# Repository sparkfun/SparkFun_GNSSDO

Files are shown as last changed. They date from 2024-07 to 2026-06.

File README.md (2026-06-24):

SparkPNT SXT / SXT-D
========================================

SparkPNT SXT (https://www.sparkpnt.com/products/sxt-gnssdo)

[*SparkPNT SXT (GNSSDO)*](https://www.sparkpnt.com/products/sxt-gnssdo)

Designed and manufactured in Boulder, Colorado, USA, the SparkPNT SXT GNSS Disciplined Oscillator (GNSSDO) and SXT-D GNSS Disciplined Oscillator Plus (GNSSDO+) are the perfect solution for your high-precision timing needs. Based around the multi-constellation, multi-frequency, L5-ready mosaic-T from Septentrio, these are our most accurate GNSS timing products to date. They feature a disciplined 10MHz oscillator: Digitally-Controlled Temperature-Controlled Crystal Oscillator (DCTCXO) on the SXT; Digitally-Controlled Double-Oven Crystal Oscillator (OCXO) on the SXT-D. The mosaic-T also has built-in on-module support for the Fugro AtomiChron L-band timing service.

Under the hood, the SXT and SXT-D are based on the mosaic-T GNSS module from Septentrio, plus the Espressif ESP32-WROVER processor (16MB flash, 8MB PSRAM). The mosaic-T has USB-C connectivity (with Ethernet-over-USB), multiple UARTs and supports full Ethernet connectivity. You can connect the mosaic-T directly to your Ethernet network - our product supports Power-over-Ethernet too. The ESP32 rides shotgun: disciplining the digitally-controlled oscillator and controlling the OLED display. Remote configuration is possible, the ESP32 console can be accessed via TCP. The SXT and SXT-D have multiple power options including USB-C, PoE and 9V-36V DC, making it easy to connect them to a battery-backed supply.

RTK Not Supported
--------------
The mosaic-T is a superb GNSS module designed for highly accurate timing applications. **But it does not support RTK. It can not be used as a RTK Rover or Base. RTCM output is not supported.**

Documentation
--------------

- **[Product Manual](http://docs.sparkfun.com/SparkFun_GNSSDO/)** - Product manual for the SXT(-D) GNSSDO(+) hosted by GitHub pages.<br>
   

*Need to download or print our hookup guide?*

- [Print *(Print to PDF)* from Single-Page View](http://docs.sparkfun.com/SparkFun_GNSSDO/print_view)

Firmware Update
-------------------

The **[/Firmware/Binaries](https://github.com/sparkfun/SparkFun_GNSSDO/tree/main/Firmware/Binaries)** folder contains the firmware binaries.

You can update or reload the firmware using the [SparkFun RTK Firmware Uploader](https://github.com/sparkfun/SparkFun_RTK_Firmware_Uploader).

Repository Contents
-------------------

- **[/docs](/docs/)** - Online documentation files
    - [assets](/docs/assets/) - Assets files
        - [board_files](/docs/assets/board_files/) - Files for the product design
            - [SXT Schematic](/docs/assets/board_files/schematic.pdf) (.pdf)
            - [SXT-D Schematic](/docs/assets/board_files/SparkPNT_GNSSDO_Plus_schematic) (.pdf)
            - [Dimensions](/docs/assets/board_files/dimensions.png) (.png)
            - [SXT KiCad files](/docs/assets/board_files/kicad_files.zip) (.zip)
            - [SXT-D KiCad files](/docs/assets/board_files/kicad_files_GNSSDO_Plus.zip) (.zip)
        - [img/hookup_guide/](/docs/assets/img/hookup_guide/) - Images for hookup guide documentation
- **[/Hardware](/Hardware/)** - KiCad design files
- **[/Hardware/Production](/Hardware/Production/)** - PCB panel production files
- **[/Front_Sticker](/Front_Sticker/)** - DXF and PDF files for the front sticker
- **[/Rear_Sticker](/Rear_Sticker/)** - DXF and PDF files for the rear sticker
- **[/Firmware](/Firmware/)** - Arduino source code and binaries for the firmware which runs on the ESP32-WROVER
- **[/Test_Sketches](/Test_Sketches/)** - Additional code used to validate and test the SXT
- **[/Documents](/Documents/)** - Component datasheets etc.

Product Variants
----------------

- [SXT](https://www.sparkpnt.com/products/sxt-gnssdo)- SXT (GNSSDO) v1.0, Initial Release
- [SXT-D](https://www.sparkpnt.com/products/sxt-d-gnssdo)- SXT-D (GNSSDO+) v1.0, Initial Release

Version History
---------------

- [v10](https://github.com/sparkfun/SparkFun_GNSSDO/releases/tag/v10) - Initial Release

License Information
-------------------

This product is ***open source***!

Please review the [LICENSE.md](./LICENSE.md) file for license information.

If you have any questions or concerns about licensing, please contact technical support on our [SparkPNT forums](https://community.sparkpnt.com).

Distributed as-is; no warranty is given.

- Your friends at SparkPNT.

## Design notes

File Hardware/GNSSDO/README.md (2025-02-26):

SparkPNT GNSSDO Design Files
=====================================

The files here are the KiCad schematic and PCB design files from SparkFun Electronics.

KiCad can be downloaded [here](https://www.kicad.org/).

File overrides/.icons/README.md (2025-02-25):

.icons directory
====================
This folder should contain branding logos for the product documentation

## General Images
- `sfe.svg` - SparkFun flame logo
- `kicad-primary.svg` - Full KiCad logo

## Directory
- `logo` - Other available logos

## SVG Optimizer
- [Remove meta data from svg](https://jakearchibald.github.io/svgomg/)

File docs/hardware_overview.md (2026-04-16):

---
icon: material/cog
---

!!! warning "Read Before Handling PCB!"
	!!! danger "ESD Sensitivity"
		The mosaic-T module is sensitive to [ESD](https://en.wikipedia.org/wiki/Electrostatic_discharge "Electrostatic Discharge"). Use a proper grounding system to make sure that the working surface and the components are at the same electric potential.

	??? info "ESD Precaution"
		As recommended by the manufacturer, we highly encourage users to take the necessary precautions to avoid damaging their module.

		- The GNSSDO(+) features ESD protection on the USB-C connectors, ethernet jack, I/O terminals and antenna connections.

		<div class="grid cards" markdown>

		<div markdown>

		<article class="video-500px" style="text-align: center; margin: auto;" markdown>
		<iframe src="https://www.youtube.com/embed/hrL5J6Q5gX8?si=jOPBat8rzMnL7Uz4&amp;start=26;&amp;end=35;" title="Septentrio: Getting Started Video (playback starts at ESD warning)" frameborder="0" allow="accelerometer; autoplay; clipboard-write; encrypted-media; gyroscope; picture-in-picture" allowfullscreen></iframe>
		</article>

		</div>

		-   <a href="https://www.sparkfun.com/products/25572">
			<figure markdown>
			Product Thumbnail
			</figure>

			---

			**iFixit Anti-Static Wrist Strap**<br>
			TOL-25572</a>

		</div>

!!! code "ESP32 Firmware"
	We have intentionally kept the ESP32 firmware as simple as possible - it only disciplines the TCXO oscillator and controls the OLED display. The SparkFun RTK Firmware or SparkFun RTK Everywhere firmware will not run on this product. The intention is that you can easily develop your own firmware for the GNSSDO(+) if the SparkFun firmware does not meet your needs.

	The **[/Firmware/Binaries](https://github.com/sparkfun/SparkFun_GNSSDO/tree/main/Firmware/Binaries)** folder contains the firmware binaries.

	You can update or reload the firmware using the [SparkFun RTK Firmware Uploader](https://github.com/sparkfun/SparkFun_RTK_Firmware_Uploader).

	You can of course modify the hardware too, should you want to. The design is completely open-source.

# Hardware Overview
In this section, we walk you through the hardware design, interfaces, I/O connections, power options and more.

## Schematic
Users can download the full schematic for the [GNSSDO](./assets/board_files/schematic.pdf) and [GNSSDO+](./assets/board_files/SparkPNT_GNSSDO_Plus_schematic.pdf) in `*.pdf` format.

## Dimensions

=== ":material-package-variant-closed: Metal Enclosure"
	Details about the aluminum enclosure can be found on the [Metal Enclosure - Custom Aluminum Extrusion (6in. x 4in. PCB)](https://www.sparkfun.com/metal-enclosure-custom-aluminum-extrusion-6in-x-4in-pcb.html) product page.

	<figure markdown>
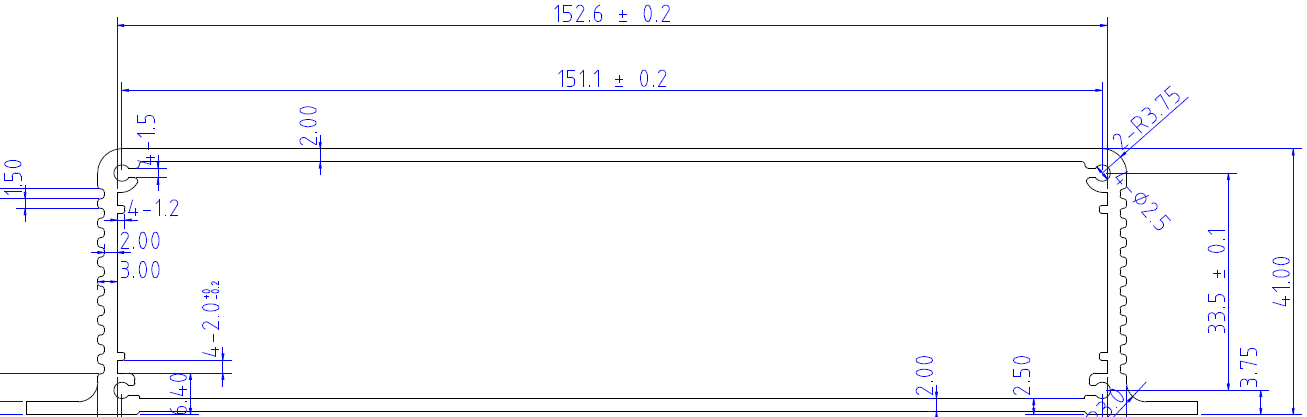
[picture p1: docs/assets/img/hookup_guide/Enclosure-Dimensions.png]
Enclosure Dimensions
	
	<figcaption markdown>
	[Dimensions (PDF)](./assets/board_files/dimensions-enclosure.pdf) of the GNSSDO(+) aluminum enclosure and the front/rear panels, in millimeters.
	</figcaption>
	</figure>

=== ":fontawesome-solid-microchip: Printed Circuit Board"
	The circuit board dimensions are illustrated in the drawing below; the listed measurements are in inches.

	<figure markdown>
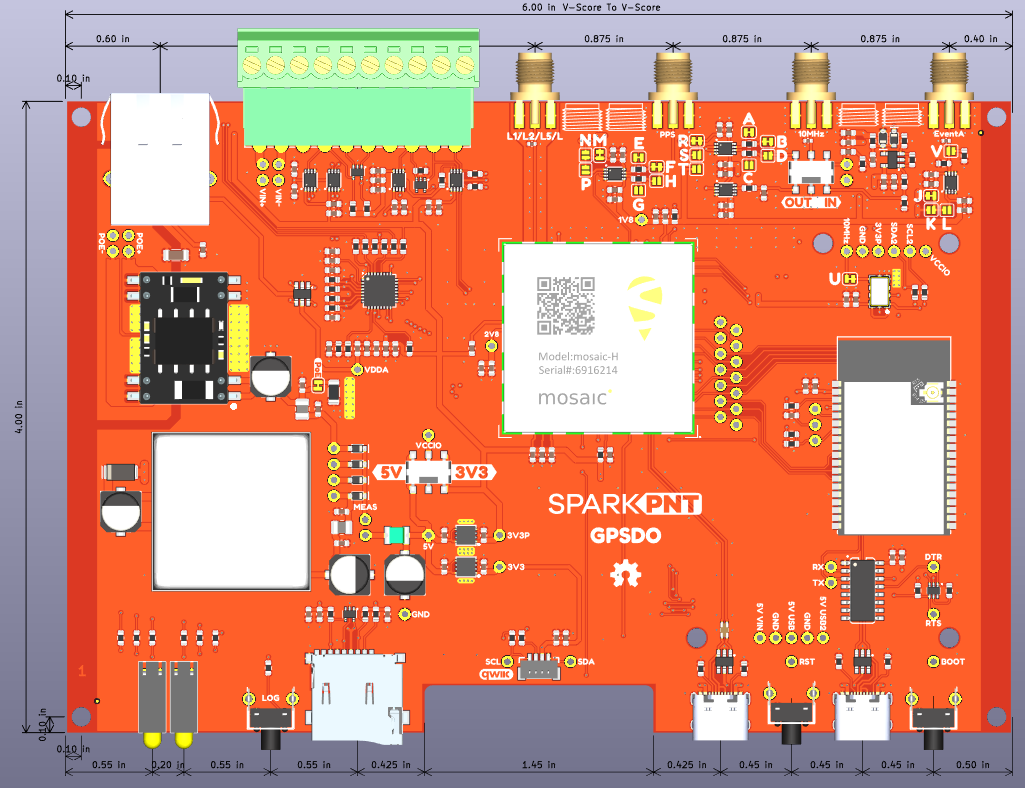
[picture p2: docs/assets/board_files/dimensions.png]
Board Dimensions
	
	<figcaption markdown>
	[Dimensions (PNG)](./assets/board_files/dimensions.png) of the GNSSDO(+) PCB, in inches.
	</figcaption>
	</figure>

	??? tip "Need Dimensions?"
		For the board dimensions, users can download the [KiCad files](./assets/board_files/kicad_files.zip) for this board. These files can be opened in KiCad and measurements can be made with the measuring tool.

		!!! info ":octicons-download-16:{ .heart } KiCad - Free Download!"
			KiCad is free, open-source [CAD]("computer-aided design") program for electronics. Click on the button below to download their software. *(\*Users can find out more information about KiCad from their [website](https://www.kicad.org/).)*

			<article style="text-align: center;" markdown>
			[Download :kicad-primary:{ .enlarge-logo }](https://www.kicad.org/download/ "Go to downloads page"){ .md-button .md-button--primary width="250px" }
			</article>

		??? info ":straight_ruler: Measuring Tool"
			This video demonstrates how to utilize the dimensions tool in KiCad, to include additional measurements:

			<article class="video-500px" style="text-align: center; margin: auto;" markdown>
			<iframe src="https://www.youtube.com/embed/-eXuD8pkCYw" title="KiCad Dimension Tool" frameborder="0" allow="accelerometer; autoplay; clipboard-write; encrypted-media; gyroscope; picture-in-picture" allowfullscreen></iframe>

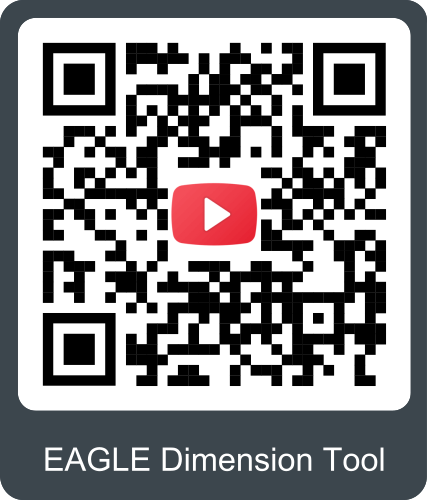
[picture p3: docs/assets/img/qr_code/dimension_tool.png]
QR code to play video
			
			</article>

=== ":material-video-input-antenna: Antenna"
	The dimensions and technical specifications of the GNSS antenna can be found on the [GNSS Multi-Band L1/L2/L5 Surveying Antenna - TNC (SPK6618H)](https://www.sparkfun.com/gnss-multi-band-l1-l2-l5-surveying-antenna-tnc-spk6618h.html) product page.

	<figure markdown>
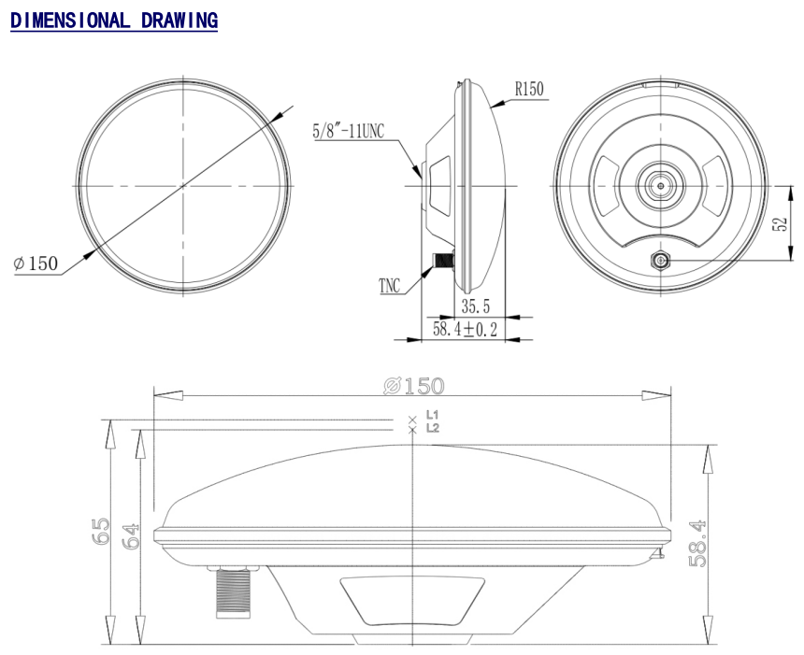
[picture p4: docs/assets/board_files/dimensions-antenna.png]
Antenna Dimensions
	
	<figcaption markdown>
	Dimensions of the included GNSS antenna, in mm.<br>
	Source: [SPK6618H Datasheet (PDF)](https://cdn.sparkfun.com/assets/f/f/5/1/7/SparkFun_SPK6618H_Datasheet.pdf)
	</figcaption>
	</figure>

## Power Options
The mosaic-T and the ESP32 both required 3.3V power. To simplify the power circuitry, the four power sources are combined into a common 5V rail which then feeds individual 3.3V regulators for the mosaic-T and the ESP32.

<figure markdown>
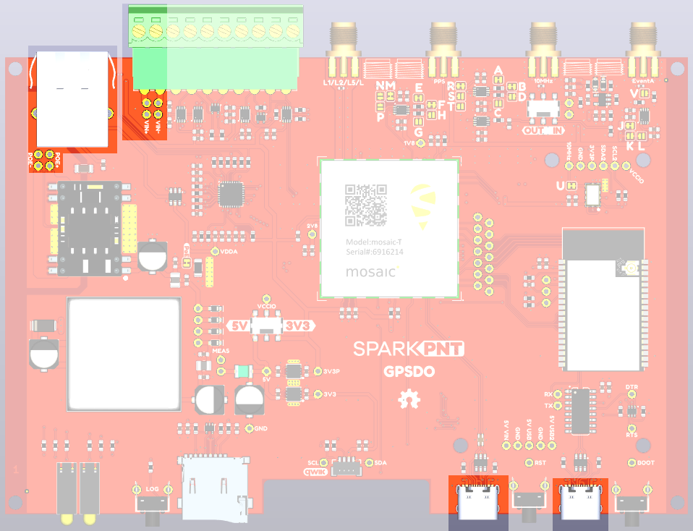
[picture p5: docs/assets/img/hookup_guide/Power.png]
Power connections

<figcaption markdown>Power connections on the GNSSDO(+) PCB.</figcaption>
</figure>

The GNSSDO can be powered individually or in combination, with any of the following:

- **`USB Ports`** - **5V**; delivered via the `MOSAIC CONFIG` and/or `ESP32 CONFIG` USB-C connectors.
- **`Power-over-Ethernet`** - **Range: 36 to 57V**; delivered via the `MOSAIC ETHERNET` RJ45 MagJack connector.
- **`External DC Power`** - **Range: 9 to 36V**; delivered via the `VIN+` and `VIN-` screw cage terminals.

Powering the GNSSDO+ takes a little more thought and care. The double-oven oscillator in the GNSSDO+ draws more current than a standard USB (2.0) port can provide. You need to ensure that you use the provided 65W Power Delvery Wall Adapter if you are going to power the GNSSDO+ from USB. Also, the GNSSDO+ includes a Power Path priority circuit. From highest to lowest, the Power Path priorities are:

- **`Power-over-Ethernet`** - **Range: 36 to 57V**; delivered via the `MOSAIC ETHERNET` RJ45 MagJack connector.
- **`External DC Power`** - **Range: 9 to 36V**; delivered via the `VIN+` and `VIN-` screw cage terminals.
- **`CONFIG ESP32 USB Port`** - **5V from a Power Delivery Wall Adapter**; delivered via the `CONFIG ESP32` USB-C connector.
- **`CONFIG MOSAIC USB Port`** - **5V from a Power Delivery Wall Adapter**; delivered via the `CONFIG MOSAIC` USB-C connector.

If you have the **`CONFIG ESP32 USB Port`** connected to a standard USB (2.0) port, it will not be able to provide enough current. And due to the Power Path priority, it will not preferentially draw power from **`CONFIG MOSAIC USB Port`**. Your options are:

- Provide power via **`Power-over-Ethernet`** or **`External DC Power`** since these have higher priority
- Install a [power switch](https://www.sparkfun.com/usb-c-extension-cable-with-power-switch-1m.html) in the **`CONFIG ESP32 USB Port`** cable to disconnect its power, forcing the GNSSDO+ to draw Power Delivery power from the **`CONFIG MOSAIC USB Port`**.

If you have **`CONFIG MOSAIC USB Port`** connected to a standard USB (2.0) port, ensure the Power Delivery Wall Adapter is connected to **`CONFIG ESP32 USB Port`**. The Power Path priority will ensure power is drawn from the **`CONFIG ESP32 USB Port`**.

Consult page 9 of the [GNSSDO+ schematic](./assets/board_files/SparkPNT_GNSSDO_Plus_schematic.pdf) for more details

??? tip "Measure Current Draw"
	If you want to measure the board's current draw, you can open the `MEAS` jumper and measure the current via a pair of breakout pads *(see the **[Jumpers](#jumpers-gnssdo)** section)*.

??? info "Protection Components"
	Diodes are used to combine and protect the power sources from each other. Also, a 2A resettable fuse (green) provides additional protection.

!!! info
	For more details, users can reference the [GNSSDO schematic](./assets/board_files/schematic.pdf), [GNSSDO+ schematic](./assets/board_files/SparkPNT_GNSSDO_Plus_schematic.pdf) and the datasheets of the individual components on the board.

=== ":material-usb-port: USB-C Connectors"
	The mosaic-T and ESP32 both have USB-C connections. These USB ports can be used to power the GNSSDO during the initial configuration when the mosaic-T or ESP32 are connected to a computer. For GNSSDO+, ensure you are using the provided Power Path Wall Adapter as described above.

	<div class="grid" markdown>

	<div markdown>

	<figure markdown>
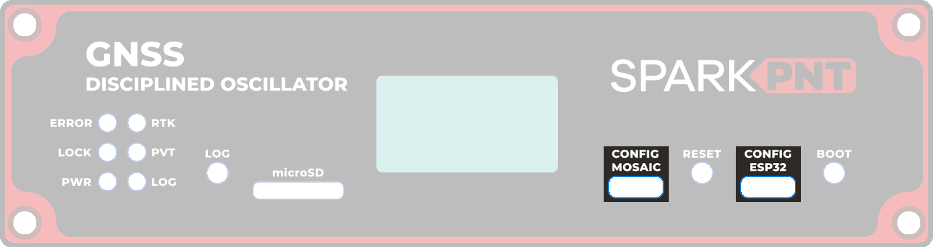
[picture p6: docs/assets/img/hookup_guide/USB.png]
USB-C Connectors
	
	<figcaption markdown>USB-C connectors on the GNSSDO(+).</figcaption>
	</figure>

	</div>

	<div markdown>

	<figure markdown>
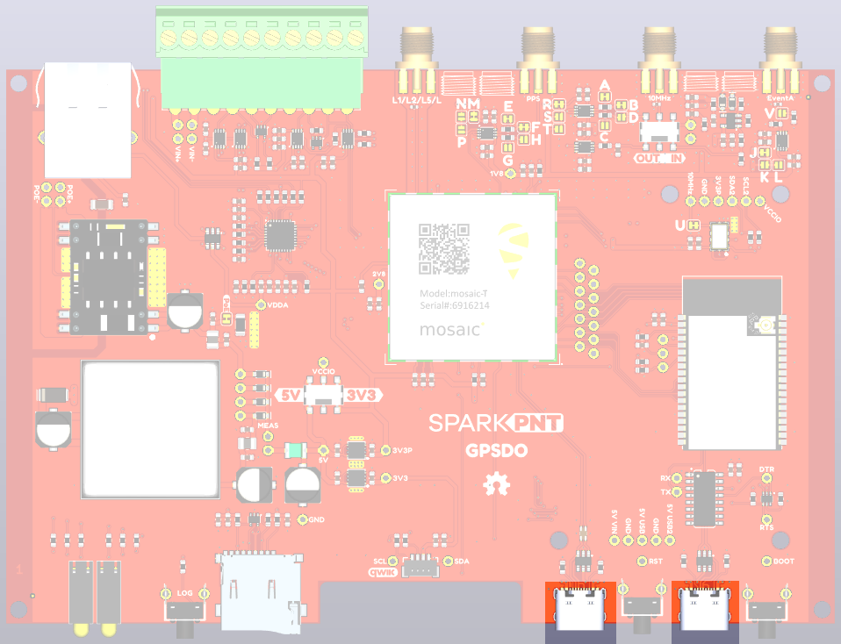
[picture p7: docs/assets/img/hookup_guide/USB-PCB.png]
USB-C Power Connections
	
	<figcaption markdown>The USB-C device connections on the GNSSDO(+) PCB.</figcaption>
	</figure>

	</div>

	</div>

	!!! info "CH340 Driver"
		The CH340 allows the ESP32-WROVER to communicate with a computer/host device through the USB-C connection. This allows the ESP32 to show up as a device on the serial (or COM) port of the computer. Users will need to install the latest drivers for the computer to recognize the CH340 *(see **[USB Driver](./software_overview.md#ch340-usb-driver)** section)*.

=== ":material-ethernet: Power-over-Ethernet (PoE)"
	The mosaic-T Ethernet port supports Power-over-Ethernet ([PoE](https://en.wikipedia.org/wiki/Power_over_Ethernet "Power Over Ethernet")), allowing the GNSSDO(+) to be powered by the network. This is very useful when the GNSSDO(+) is mounted remotely - perhaps in a weatherproof box up on the roof. Data and power can be delivered through a single cable, avoiding the need for a separate power connection.

	<div class="grid" markdown>

	<div markdown>

	<figure markdown>
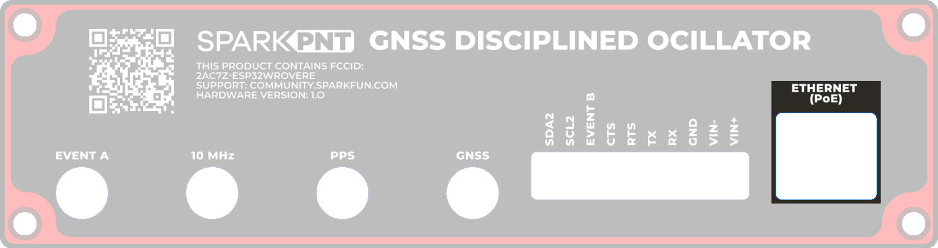
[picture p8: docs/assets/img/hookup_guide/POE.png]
Power over Ethernet Jack
	
	<figcaption markdown>The Power-over-Ethernet (PoE) jack on the GNSSDO(+).</figcaption>
	</figure>

	</div>

	<div markdown>

	<figure markdown>
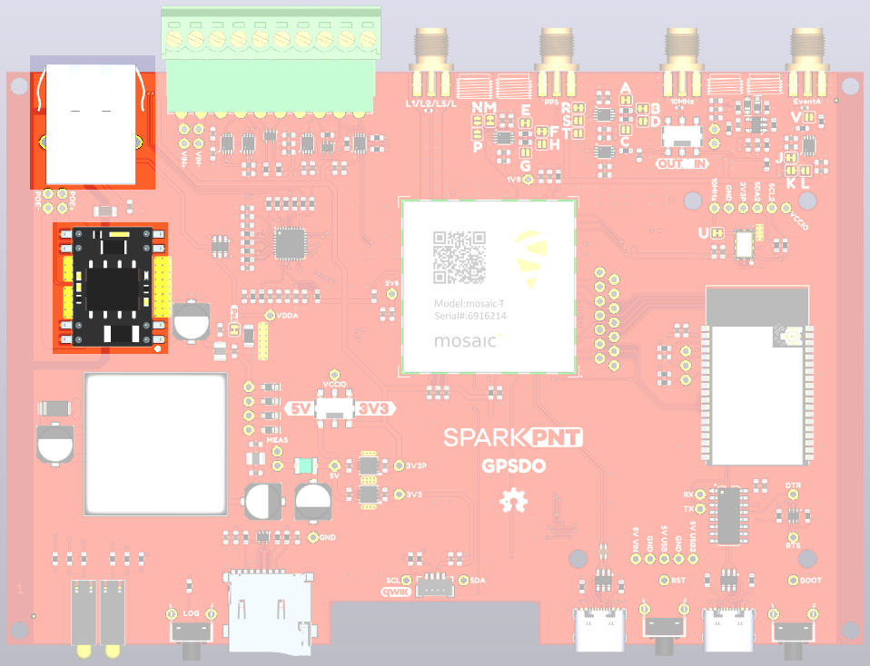
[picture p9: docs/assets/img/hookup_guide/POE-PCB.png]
Power over Ethernet Circuit
	
	<figcaption markdown>The PoE power input circuit on the GNSSDO PCB.</figcaption>
	</figure>

	</div>

	</div>

=== ":material-car-battery: External DC Power (VIN)"
	The GNSSDO(+) includes a fully-isolated DC-DC converter, for applications where you may want to power the unit from a vehicle. The DC-DC converter accepts DC voltages between **9V and 36V**, regulating this down to 5V. The converter is fully isolated to 1.5kV and operates with ~90% efficiency.

	<div class="grid" markdown>

	<div markdown>

	<figure markdown>
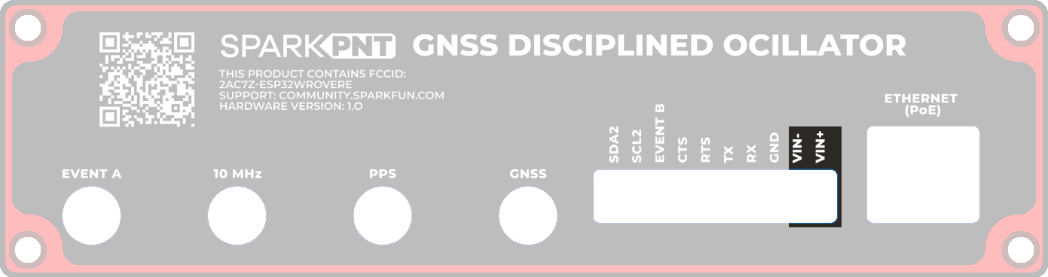
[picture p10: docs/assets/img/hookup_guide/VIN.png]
External Power Screw Terminal
	
	<figcaption markdown>The `VIN+` and `VIN-` screw terminal pins for the external DC power input.</figcaption>
	</figure>

	</div>

	<div markdown>

	<figure markdown>
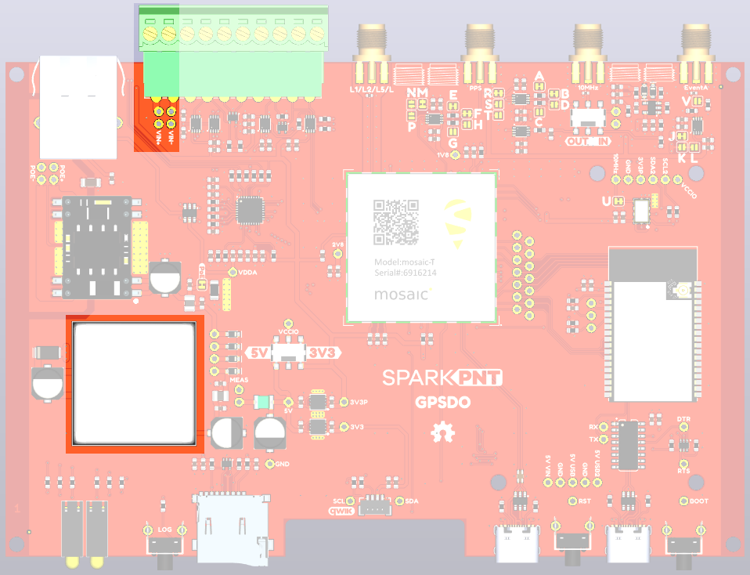
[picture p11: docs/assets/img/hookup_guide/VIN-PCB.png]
External DC Power Input
	
	<figcaption markdown>The DC-DC power converter and external power inputs on the GNSSDO(+) PCB.</figcaption>
	</figure>

	</div>

	</div>

	??? tip "Vehicle Power"
		For **12V** or **24V** vehicle power:

		- Connect 12V or 24V to the `VIN+` screw cage terminal
		- Connect 0V (chassis) to the `VIN-` screw cage terminal

		!!! warning "Power Source"
			Additionally, make sure that the power source from the vehicle is not directly tied to the vehicle's battery, `Always On`, or accessory circuits. Otherwise, users will risk draining the battery while the engine is off.

			We recommend locating the *ignition on* or *switched power* circuit, which is only powered when the key is in the `On` position *and the engine is running*.

			!!! note
				The `On` position, is where a key normally rests after the engine is started. However, users can still move the key from the `Off` position and into the `On` position without starting the engine. In this case, the alternator is not running and keeping the battery charged.

				Modern *eco-efficient* vehicles may automatically shut down the engine if the vehicle is idling too long. Therefore, cutting off the vehicle's alternator that keeps the battery charged. Luckily, most vehicles with this *automatic start/stop* technology will monitor the battery's voltage and restart the engine when required. With this in mind, users may want to initially monitor their battery voltage, in case their vehicle isn't *"so smart"* :sweat_smile:.

	??? warning "Ground Loop"
		If desired, users can link `VIN-` to the adjacent `GND` screw cage terminal. However, this will bypass the voltage isolation and could introduce an unwanted ground loop, particularly if the GNSS antenna ground (shield, 0V) is also connected to the chassis.

## :septentrio: mosaic-T
The heart of our product is of course the mosaic-T GNSS module from Septentrio. It is a _very_ sophisticated chip with multiple interfaces: UARTS, USB and Ethernet. On GNSSDO, the `GPIO1` and `GPIO2` pins are available as 0.1" test points should you need access to them. On GNSSDO+, GP1 and GP2 are available on the 10-way screw cage connector.

<figure markdown>
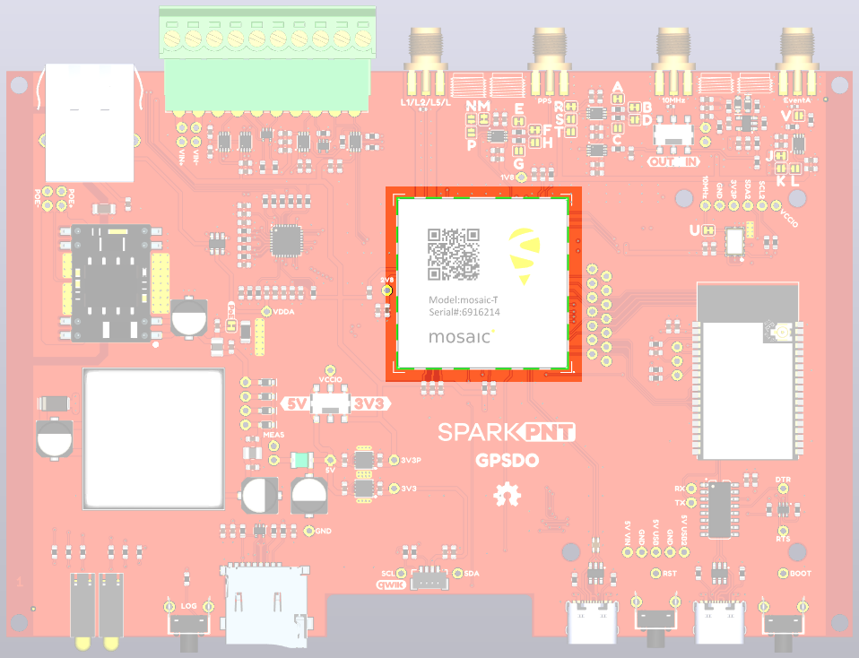
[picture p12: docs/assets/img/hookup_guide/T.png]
mosaic-T

<figcaption markdown>The Septentrio mosaic-T GNSS module.</figcaption>
</figure>

## :espressif: ESP32-WROVER
The ESP32 processor is there to control (discipline) the 10 MHz TCXO oscillator and the OLED display. We have deliberately kept the ESP32 firmware as simple as possible. The intention is that you can write your own firmware using the Espressif IDF or Arduino IDE if you need to.

<figure markdown>
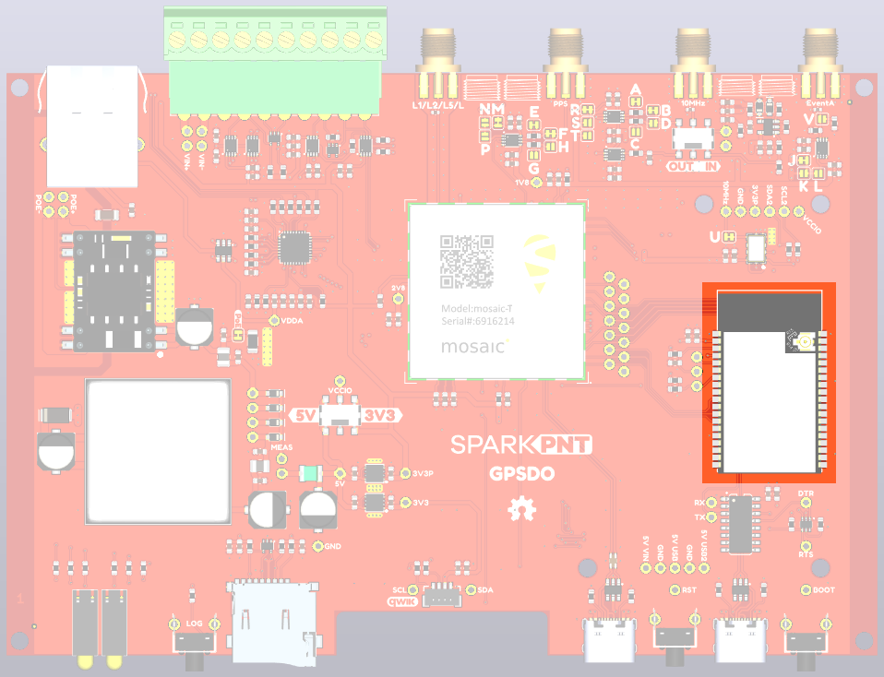
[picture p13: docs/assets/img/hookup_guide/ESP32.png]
Espressif ESP32 on GNSSDO

<figcaption markdown>The Espressif ESP32-WROVER processor on GNSSDO.</figcaption>
</figure>

<figure markdown>
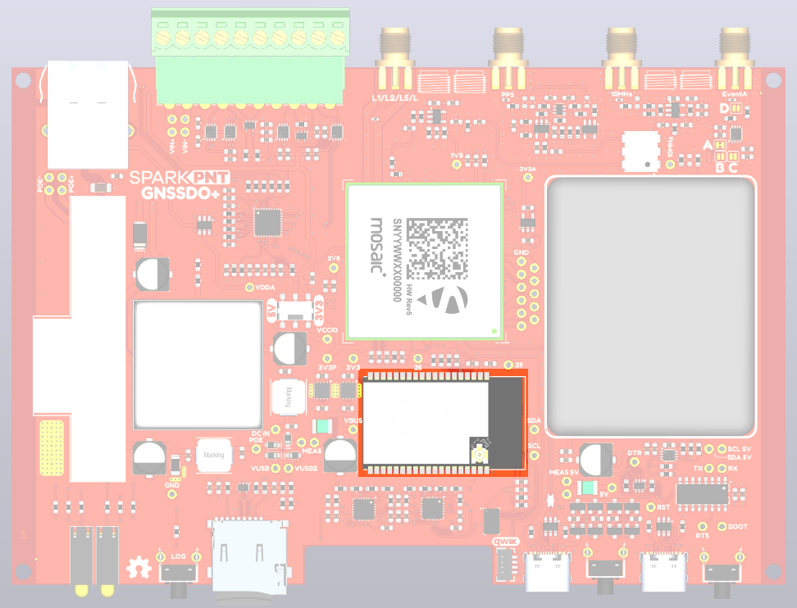
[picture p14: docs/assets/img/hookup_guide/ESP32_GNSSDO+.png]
Espressif ESP32 on GNSSDO+

<figcaption markdown>The Espressif ESP32-WROVER processor on GNSSDO+.</figcaption>
</figure>

Think of the ESP32 as a co-processor, or riding shotgun... The mosaic-T `COM1`, `COM3` and `COM4` UARTs are linked to the ESP32, allowing the two to communicate directly without needing an Ethernet link. In our firmware, the PVTGeodetic and ReceiverTime messages are output on COM1. The ESP32 displays some of their content on the I^2^C OLED display, and then uses the content to discipline the TCXO oscillator. See [Oscillator](./oscillator.md) for more details.

??? code "ESP32 Firmware"
	We have intentionally kept the ESP32 firmware as simple as possible. The intention is that users can easily develop their, own firmware for the GNSSDO(+) using the Espressif ESP IDF or the Arduino IDE if the SparkFun firmware does not meet their needs.

	The **[/Firmware/Binaries](https://github.com/sparkfun/SparkFun_GNSSDO/tree/main/Firmware/Binaries)** folder contains the firmware binaries.

	You can update or reload the firmware using the [SparkFun RTK Firmware Uploader](https://github.com/sparkfun/SparkFun_RTK_Firmware_Uploader).

	The ESP32-WROVER-IE antenna is not connected. If you write your own firmware and want to use BT/WiFi connectivity, you will need to attach your own antenna to the u.FL connector on the ESP32 module.

## Ethernet PHY Interface
The mosaic-T has a KSZ8041NLI Ethernet PHY interface, connected using a Reduced Media-Independent Interface (RMII).

<div class="grid" markdown>

<div markdown>

<figure markdown>
Ethernet Connector
<figcaption markdown>Ethernet (PoE) conection.</figcaption>
</figure>

</div>

<div markdown>

<figure markdown>
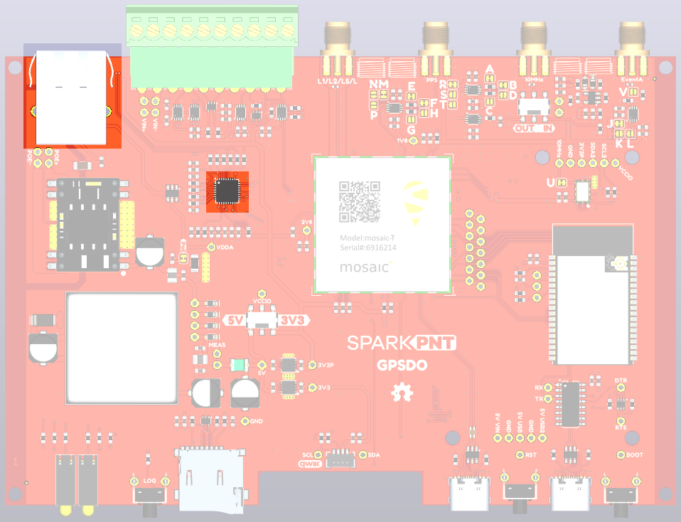
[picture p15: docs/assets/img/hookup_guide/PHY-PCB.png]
Ethernet PHY

<figcaption markdown>The Ethernet PHY on the GNSSDO(+) PCB.</figcaption>
</figure>

</div>

</div>

??? info "No IP address?"
	Check the Ethernet interface is enabled. It may be disabled. Connect via the CONFIG MOSAIC USB-C port and open 192.168.3.1 on a web browser. Check the **Communication \ Ethernet** sub-page.

	<figure markdown>
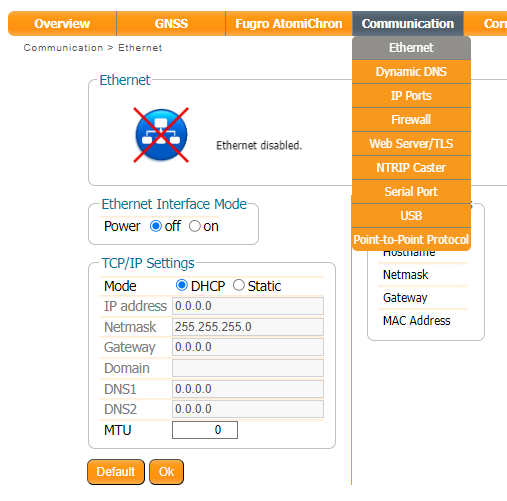
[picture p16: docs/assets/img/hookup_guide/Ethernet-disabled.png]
	
	<figcaption markdown>
	[mosaic-T web page (PNG)](./assets/img/hookup_guide/Ethernet-disabled.png) with Ethernet disabled.
	</figcaption>
	</figure>

	<figure markdown>
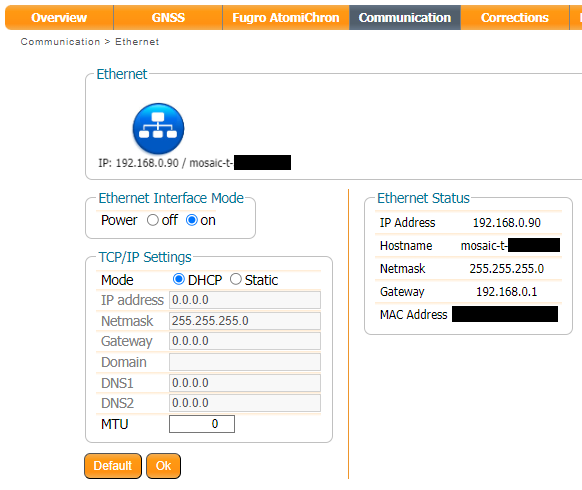
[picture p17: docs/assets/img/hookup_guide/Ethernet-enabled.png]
	
	<figcaption markdown>
	[mosaic-T web page (PNG)](./assets/img/hookup_guide/Ethernet-enabled.png) with Ethernet enabled.
	</figcaption>
	</figure>

	By default, the mosaic-T Ethernet port is configured for Dynamic Host Configuration Protocol (DHCP). It expects the router / Ethernet switch to provide it with an IP address. If the IP address is all zeros (0.0.0.0), check that your router has DHCP enabled. Most do.

	If you need a static IP address, you can configure this through the mosaic-T's **Communication \ Ethernet** sub-page.

	Subnet 3 is reserved for the mosaic-T's USB-C connection (Ethernet-over-USB). If your router / switch is allocating addresses using subnet 3 (192.168.3.***), please change its settings so it uses a different subnet.

## USB-C Connectors
The mosaic-T and ESP32 both have USB-C connections. The MOSAIC USB port is high-speed and connected to the T through a balancing transformer. The ESP32 USB port is connected through a CH340 USB-UART IC.

<div class="grid" markdown>

<div markdown>

<figure markdown>
USB-C Connectors
<figcaption markdown>USB-C connections: mosaic-T (left) and ESP32 (right).</figcaption>
</figure>

</div>

<div markdown>

<figure markdown>
USB-C Power Connections
<figcaption markdown>The USB-C data connections on the GNSSDO(+) PCB.</figcaption>
</figure>

</div>

</div>

!!! info
	The GNSSDO can draw power from either or both USB ports, in addition to Power-over-Ethernet and the DC-DC external input described above. Powering GNSSDO+ via USB takes a little more though and care. Please see the notes [above](#power-options).

!!! info "CH340 Driver"
	The CH340 allows the ESP32-WROVER to communicate with a computer/host device through the USB-C connection. This allows the ESP32 to show up as a device on the serial (or COM) port of the computer. Users will need to install the latest drivers for the computer to recognize the CH340 *(see **[USB Driver](./software_overview.md#ch340-usb-driver)** section)*.

## &micro;SD Socket
The &micro;SD socket is connected directly to the mosaic-T via a one-bit SDIO interface for fast data logging. The mosaic-T supports &micro;SD cards with a **FAT32** file system *(i.e. only cards **up to 32GB** in size)*.

<div class="grid" markdown>

<div markdown>

<figure markdown>
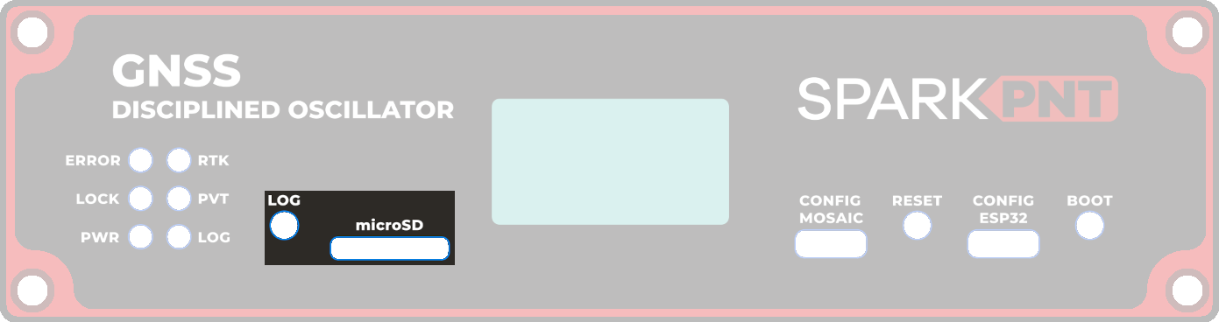
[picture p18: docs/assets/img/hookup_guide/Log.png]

<figcaption markdown>&micro;SD slot and ++"LOG"++ button.</figcaption>
</figure>

</div>

<div markdown>

<figure markdown>
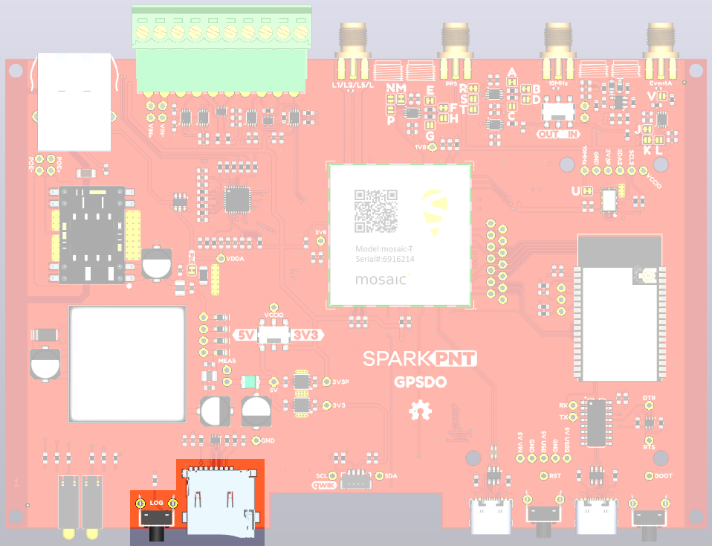
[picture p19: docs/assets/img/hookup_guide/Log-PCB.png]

<figcaption markdown>&micro;SD socket and ++"Log"++ button on the GNSSDO(+) PCB.</figcaption>
</figure>

</div>

</div>

??? info "Operation Instructions"

	!!! success "Initial Configuration"
		Before logging can take place, it is necessary to define a "logging stream" using the **Logging** page or **RxTools**. Streams can contain NMEA or SBF (Septentrio Binary Format) data; SBF can contain RTCM and/or RINEX.

		<figure markdown>
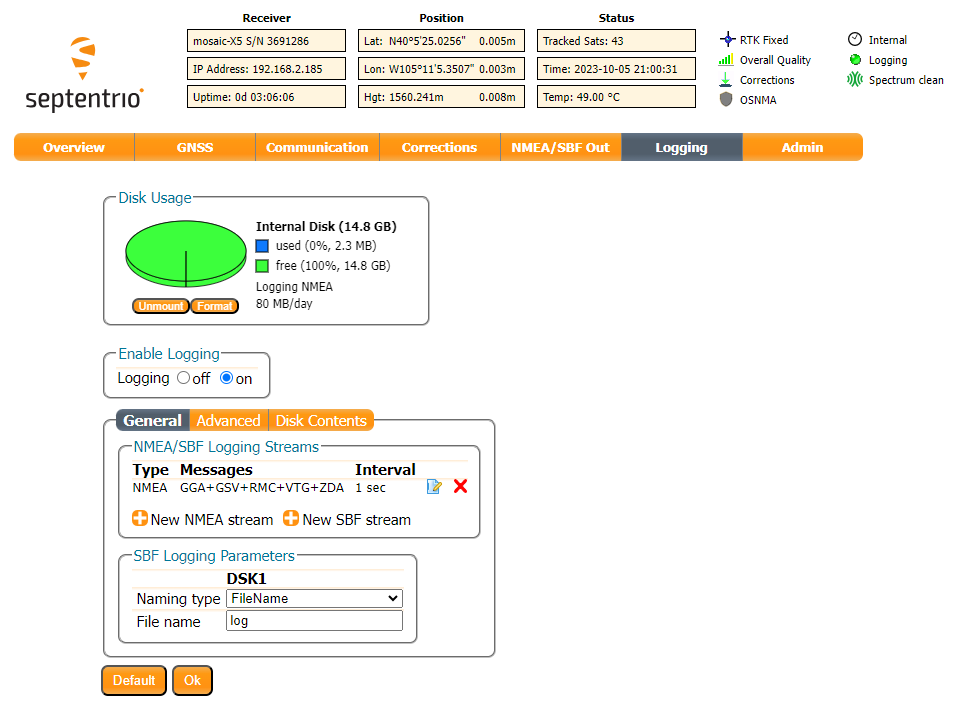
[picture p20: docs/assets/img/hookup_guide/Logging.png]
Logging stream configuration
		
		<figcaption markdown>&micro;SD logging stream configuration.</figcaption>
		</figure>

		!!! tip "Instructional Video"
			:material-youtube: [How to log data to the SD card of the Septentrio mosaic receiver module](https://youtu.be/Y9tvOebnoxk)

	Once the stream is defined, users can control the data logging operation through the ++"LOG"++ button.

	- A short press of the ++"LOG"++ button *(< 5s)* toggles data logging to the SD card on and off.
		- The red `LOG` LED will flash while logging is taking place.
	- A long press, holding the ++"LOG"++ button for more than 5 seconds *(> 5s)* and then releasing it, will force the board to:
		- Unmount the SD card if it was mounted
		- Mount the SD card if it was unmounted

## SMA Connectors
The GNSSDO has robust SMA connectors for the mosaic-T GNSS antenna, Pulse-Per-Second output, 10 MHz clock signal and the Event A input.

<figure markdown>
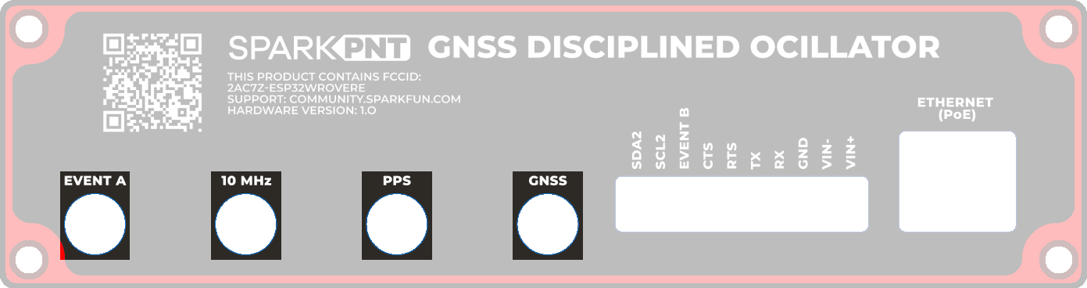
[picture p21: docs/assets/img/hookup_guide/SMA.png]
SMA Connections

<figcaption markdown>The SMA connections on the SparkPNT GNSSDO.</figcaption>
</figure>

!!! tip "Connector Polarity"
	All these SMA connectors have a standard polarity. When selecting antennas and/or cables for the GNSSDO, double-check the polarity for the connections and cables.

=== "`EVENTA`"

	<div class="grid" markdown>

	<div markdown>

	<figure markdown>
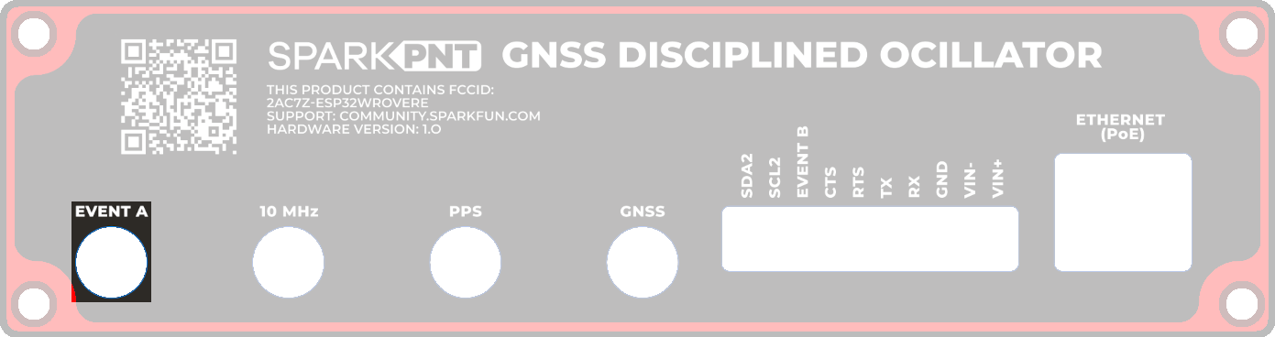
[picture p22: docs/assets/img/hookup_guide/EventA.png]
EventA Connections
	
	<figcaption markdown>The SMA connector for the EventA input.</figcaption>
	</figure>

	The Event A SMA connector is standard polarity. The voltage is adjustable via the VCCIO switch: 3.3V or 5V. 2.8V and 1.8V are also available via the jumper links *(see the **[Jumpers](#jumpers-gnssdo)** section)*. The output can also be configured for 50 Ohm via the jumper links *(see the **[Jumpers](#jumpers-gnssdo)** section)*.

	</div>

	<div markdown>

	<figure markdown>
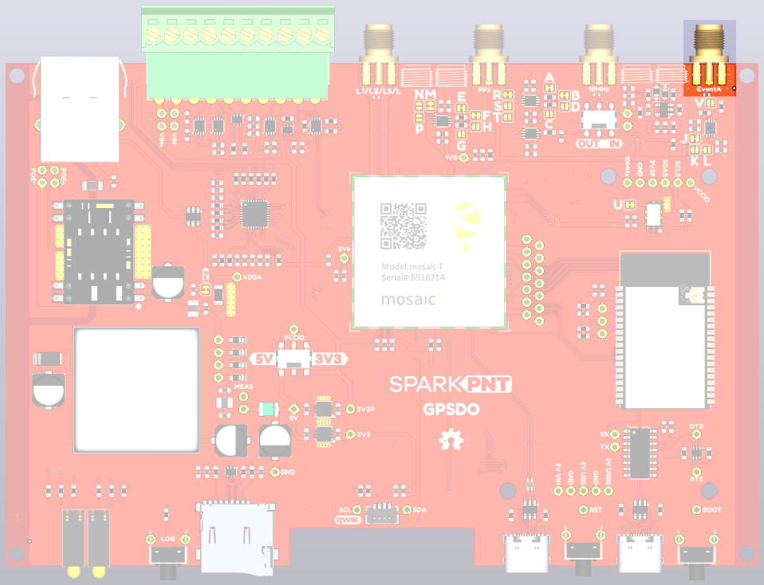
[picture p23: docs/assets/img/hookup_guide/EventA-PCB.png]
EventA Connections
	
	<figcaption markdown>The connection for the EventA input.</figcaption>
	</figure>

	</div>

	</div>

=== "`10MHz`"

	<div class="grid" markdown>

	<div markdown>

	<figure markdown>
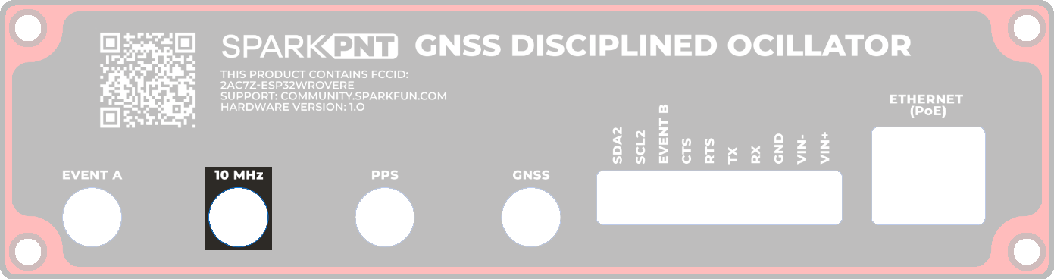
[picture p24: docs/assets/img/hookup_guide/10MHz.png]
	
	<figcaption markdown>The SMA connector for the 10 MHz output / input.</figcaption>
	</figure>

	The 10 MHz SMA connector is standard polarity.
	
	On GNSSDO, the voltage is adjustable via the VCCIO switch: 3.3V or 5V. 2.8V and 1.8V are also available via the jumper links *(see the **[Jumpers](#jumpers-gnssdo)** section)*. The output can also be configured for 50 Ohm via the jumper links *(see the **[Jumpers](#jumpers-gnssdo)** section)*. Output / Input is selected via the small slide switch *(see the **[Switches](#switches)** section)* adjacent to the connector. When configured for input: the input impedance is 50Ω; the detection level is -14dBm; the max supported input level is +12dBm.

	On GNSSDO+, the 10MHz signal is output-only and 3.3V only.

	</div>

	<div markdown>

	<figure markdown>
	SMA 10MHz Connections
	<figcaption markdown>The connection for the 10 MHz clock signal.</figcaption>
	</figure>

	</div>

	</div>

	!!! warning
		Although the mosaic-T module can either use its internal TCXO or accept an external signal as a frequency reference, the module will constantly reboot if the `REF_I` pin isn't provided a 10MHz sinusoidal signal and left floating. Therefore, users should only set the [`10MHz` switch](#switches) to the `IN` position, only if a 10MHz clock signal can be provided; otherwise, the switch should remain in the `OUT` position.

=== "`PPS`"

	<div class="grid" markdown>

	<div markdown>

	<figure markdown>
	SMA PPS Connections
	<figcaption markdown>The SMA connector for the Pulse-Per-Second output.</figcaption>
	</figure>

	The Pulse-Per-Second SMA connector is standard polarity.
	
	On GNSSDO, the voltage is selectable via the VCCIO switch: 3.3V or 5V. 2.8V and 1.8V are also available via the jumper links *(see the **[Jumpers](#jumpers-gnssdo)** section)*. The output is DC-coupled. The output can be configured for 50 Ohm output via the jumper links *(see the **[Jumpers](#jumpers-gnssdo)** section)*.

	On GNSSDO+, PPS is 3.3V only. The PPS output is aligned to the 10MHz clock to ensure its accuracy.

	</div>

	<div markdown>

	<figure markdown>
	SMA PPS Connections
	<figcaption markdown>The connection for the Pulse-Per-Second output.</figcaption>
	</figure>

	</div>

	</div>

=== "`GNSS`"

	<div class="grid" markdown>

	<div markdown>

	<figure markdown>
	SMA RF Connections
	<figcaption markdown>The SMA connector for the GNSS antenna.</figcaption>
	</figure>

	The mosaic-T GNSS SMA connector is standard polarity and provides 3.3V power for an active antenna.

	</div>

	<div markdown>

	<figure markdown>
	SMA RF Connections
	<figcaption markdown>The connection for the GNSS antenna to the mosaic-T.</figcaption>
	</figure>

	</div>

	</div>

## Input/Output Terminals
The GNSSDO is equipped with a [10-way 3.5mm screw cage terminal connector](https://www.sparkfun.com/10-way-terminal-socket.html).

<div class="grid" markdown>

<div markdown>

<figure markdown>
IO Connections
<figcaption markdown>I/O Screw Terminal Connections.</figcaption>
</figure>

</div>

<div markdown>

<figure markdown>
IO Connections
<figcaption markdown>I/O Screw Terminal Connections on the GNSSDO PCB.</figcaption>
</figure>

</div>

</div>

These terminals are described in the tabs below. For more information on the I/O terminals, you can refer to the [GNSSDO schematic](./assets/board_files/schematic.pdf) and the [GNSSDO+ schematic](./assets/board_files/SparkPNT_GNSSDO_Plus_schematic.pdf).

=== "External Power"

	The `VIN+` and `VIN-` terminals allow the GNSSDO to be powered by an external DC power source - typically a 12V / 24V vehicle battery.

	<article style="text-align: center;" markdown>

	| **Terminal** | **Function**                                |
	| :----------: | :------------------------------------------ |
	| **VIN+**     | External voltage: **Min: 9V**; **Max: 36V** |
	| **VIN-**     | Ground / Chassis / 0V                       |

	</article>

	!!! info
		The DC-DC converter in the GNSSDO provides 1.5kV isolation between `VIN+`/`VIN-` and **5V**/**GND**. There is no direct electrical connection between `VIN-` and `GND`.

	!!! warning "Ground Loop"
		If desired, users can link `VIN-` to the adjacent `GND` screw cage terminal. However, this will bypass the voltage isolation and could introduce an unwanted ground loop, particularly if the GNSS antenna ground (shield, 0V) is also connected to the chassis.

=== "GND"
	Ground / 0V or logic-low reference.

	!!! info
		The DC-DC converter in the GNSSDO provides 1.5kV isolation between `VIN+`/`VIN-` and **5V**/**GND**. There is no direct electrical connection between `GND` and `VIN-`.

	!!! warning "Ground Loop"
		If desired, users can link `GND` to the adjacent `VIN-` screw cage terminal. However, this will bypass the voltage isolation and could introduce an unwanted ground loop, particularly if the GNSS antenna ground (shield, 0V) is also connected to the chassis.

=== "mosaic-T `COM2`"
	The mosaic-T UART COM2 connections are connected as follows:

	<article style="text-align: center;" markdown>

	| **Terminal** | **Function**                           | **Notes**                                                     |
	| :----------: | :------------------------------------- | :------------------------------------------------------------ |
	| **RX**       | COM2 UART Receive - **Input**          |                                                               |
	| **TX**       | COM2 UART Transmit - **Output**        |                                                               |
	| **RTS**      | COM2 UART Request To Send - **Output** | The module drives this pin low when ready to receive data     |
	| **CTS**      | COM2 UART Clear To Send - **Input**    | Must be driven low when ready to receive data from the module |

	</article>

	!!! tip
		The COM2 I/O voltage is set by the VCCIO voltage selection switch.

	!!! tip
		The **RX** and **CTS** inputs have weak (100K) pull-ups to VCCIO.

	!!! tip
		The **CTS** terminal can be configured as a **VCCIO** power output by soldering the jumper closed on the PCB.

=== "CTS"
	The CTS terminal can be configured as a **VCCIO** power output by soldering the jumper closed on the PCB.

	<figure markdown>
	VCCIO jumper
	<figcaption markdown>VCCIO jumper.</figcaption>
	</figure>

	!!! tip
		Soldering the jumper closed will place the mosaic-T COM2 CTS into the high (not ready) state. Flow control (hardware handshaking) is not possible when the jumper is closed. Flow control is disabled by default. If needed, flow control can be (re)disabled through the web interface or by sending (e.g) **scs, COM2, baud115200, bits8, No, bit1, none**

	The VCCIO voltage can be set to 3.3V or 5V via the small internal slide switch highlighted below:

	<figure markdown>
	VCCIO selection switch
	<figcaption markdown>VCCIO voltage selection switch.</figcaption>
	</figure>

	The `CTS` terminal can then be used as a power output or logic-high references. Likewise, the `GND` terminal can be used for power return or as logic-low references.

	<article style="text-align: center;" markdown>

	| **Terminal** | **Function**                                    |
	| :----------: | :---------------------------------------------- |
	| **CTS**      | 3.3V or 5V power output or logic-high reference |
	| **GND**      | Ground / 0V or logic-low reference              |

	</article>

	!!! info
		The default position of the `VCCIO` switch is **3.3V**.

	!!! tip
		The `CTS` and `GND` pins could be used to power (e.g.) a LoRa module. When VCCIO is 3.3V, we recommend limiting the current draw from `VCCIO` to **200mA** maximum. The upstream 3.3V regulator is rated at 600mA but it also provides power for the mosaic-T and Ethernet PHY. When VCCIO is set to 5V, the current draw can be higher - the suggested maximum is **500mA**.

=== "EVENT B"
	The mosaic-T **EVENTB** input can be used to mark or timestamp external events:

	<article style="text-align: center;" markdown>

	| **Terminal** | **Function**    |
	| :----------: | :-------------- |
	| **EVENTB**   | Event B : Input |

	</article>

	!!! tip
		The EVENT B voltage level is set by the VCCIO voltage selection switch.

	!!! tip
		The EVENT B input is pulled low internally. Pull up to VCCIO to trigger an event.

	!!! tip
		An easy way to observe the events is with **RxTools** \ **RxControl** \ **Expert Console** (under **Tools**) \ **ExEvent** tab:

		<figure markdown>
		External Events
		<figcaption markdown>Capturing external events from EVENTA and EVENTB.</figcaption>
		</figure>

=== "SCL2 & SDA2"
	!!! tip
		SCL2 & SDA2 are only available on GNSSDO.

	The SCL2 and SDA2 screw terminals provide access to the TCXO I^2^C bus, allowing the user to connect an external configurable TCXO if desired. The I^2^C voltage level is set by the VCCIO switch: 3.3V or 5V. The provided firmware supports the SiTime SiT5358, SiT5811 and the Rakon STP3593LF; the user will need to modify the firmware to support additional osciillators.

	<article style="text-align: center;" markdown>

	| **Terminal** | **Function**              |
	| :----------: | :------------------------ |
	| **SCL2**     | I2C Clock : Bidirectional |
	| **SDA2**     | I2C Data : Bidirectional  |

	</article>

	!!! tip
		The I^2^C voltage is set by the VCCIO voltage selection switch.

=== "GP1 & GP2"
	!!! tip
		GP1 & GP2 are only available on GNSSDO+.

	The GP1 and GP2 screw terminals provide access to the mosaic-T GP output signals, allowing the user to use them to configure external devices or for (e.g.) data / state logging. The output voltage level is set by the VCCIO switch: 3.3V or 5V.

	<article style="text-align: center;" markdown>

	| **Terminal** | **Function**              |
	| :----------: | :------------------------ |
	| **GP1**     | GP1 : Output-only |
	| **GP2**     | GP2 : Output-only  |

	</article>

	!!! tip
		The output voltage is set by the VCCIO voltage selection switch.

## Switches
There are two miniature slide switches on the GNSSDO PCB:

<figure markdown>
Switches
<figcaption markdown>GNSSDO Switches</figcaption>
</figure>

But only one on the GNSSDO+ PCB:

<figure markdown>
Switches
<figcaption markdown>GNSSDO+ Switches</figcaption>
</figure>

!!! warning
	The mosaic-T module can either use its internal TCXO or accept an external signal as a frequency reference. However, the module will constantly reboot if the `REF_I` pin isn't provided a 10MHz sinusoidal signal and left floating. Therefore, users should only set the GNSSDO `10MHz` switch to the `IN` position, only if a 10MHz clock signal can be provided; otherwise, the switch should remain in the `OUT` position.

	Additionally, switching between an external and internal frequency reference must occur when the mosaic-T is powered off, or the module must be reset after switching states.

=== "`VCCIO`"
	This switch sets the voltage of the Input Output Terminals (COM2 UART, Event B, SCL2 & SDA2 (GNSSDO), GP1 & GP2 (GNSSDO+))

	- The I/O voltage can be set to 3.3V (default) or 5V.

=== "`10MHz`"
	!!! tip
		This switch is only available on GNSSDO. The GNSSDO+ 10MHz SMA is output-only.

	This switch changes the function of the 10MHz SMA connector

	- When set to `OUT` (default):
		- The SMA connector will output a 10MHz "CMOS" disciplined clock signal
		- The signal voltage is set by the VCCIO voltage selection switch
	- When set to `IN`:
		- The user **must apply a clock signal from an external 10MHz oscillator**; otherwise, the mosaic-T module will constantly reset
		- The input impedance is 50Ω
		- The detection level is -14dBm
		- The max supported input level is +12dBm

## Status LEDs
There are six status LEDs on the GNSSDO(+):

<div class="grid" markdown>

<div markdown>

- `PWR` - Power *(Red)*
	- Illuminates when power is applied
- `LOG` - &micro;SD Logging *(Red)*
	- Solid Red - &micro;SD card is mounted
	- Blinking Red - Data is being logged
	- Off - &micro;SD is dismounted or not present
- `LOCK` - Oscillator Lock *(Green)*
	- The TCXO is locked to the correct frequency - as reported by **PVTGeodetic RxClkBias**
	- Connected to ESP32 GPIO pin 33
- `PVT` - Position Velocity Time *(Green)*
	- Solid Green - The mosaic-T has valid Position, Velocity and Time
	- Off - Satellite signal not present or acquired
- `ERROR` - GNSS Error *(Yellow)*
	- The GNSS Error status - as reported by **PVTGeodetic Error**
	- Connected to ESP32 GPIO pin 32
- `RTK` - Real-Time Kinematic *(Yellow)*
	- This LED has little or no functionality on the GNSSDO(+) as the mosaic-T uses PPP, not RTK
	- Internally, it is connected to the mosaic-T GPLED2 pin
	- It can be configured for (e.g.) TRACKLED if desired

</div>

<div markdown>

<figure markdown>
LEDs
<figcaption markdown>
The status indicator LEDs on the GNSSDO(+).
</figcaption>
</figure>

<figure markdown>
LEDs
<figcaption markdown>
The status indicator LEDs on the GNSSDO(+) PCB.
</figcaption>
</figure>

</div>

</div>

## OLED Display
The GNSSDO(+) has a 128x64 pixel OLED display, controlled by the ESP32 via I^2^C. After some initial diagnostic messages, the display will show position, time and other data from the mosaic-T **PVTGeodetic**, **ReceiverTime** and **IPStatus** SBF blocks.

<figure markdown>
LEDs
<figcaption markdown>
The OLED display on the GNSSDO(+).
</figcaption>
</figure>

<figure markdown>
OLED display
<figcaption markdown>
[OLED display (PNG)](./assets/img/hookup_guide/Display-Fugro.png) for the GNSSDO(+).
</figcaption>
</figure>

- Date & Time : YYYY/MM/DD HH:MM:SS from ReceiverTime
- **IP**        : nnn.nnn.nnn.nnn from IPStatus IPAddress
	- When [TCP console access](./software_overview.md#tcp-server-ips1) is enabled, the TCP port number is also displayed.
- **Lat**       : Latitude from PVTGeodetic (Degrees)
- **Long**      : Longitude from PVTGeodetic (Degrees)
- **Sys**       : TimeSystem from PVTGeodetic
	- GPS, Galileo, GLONASS, BeiDou, QZSS, Fugro
- **Error**     : Error from PVTGeodetic
	- None, Measurements, Ephemerides, DOP, Residuals, Convergence, Outliers, Export, Differential, Base, Ambiguities
- **Fine**      : FINETIME from ReceiverTime
	- False, True
- **PPS**      : Indicates if the Pulse-Per-Second signal is being generated
	- Off, On
	- PPS is only generated once the RxClkBias has achieved the required accuracy
- **Bias**      : RxClkBias from PVTGeodetic (ms/us/ns)

The display is updated on arrival of the **ReceiverTime** message. You may see a small lag between the display and the actual time system time, but it will be minimal.

## Buttons
There are three buttons on the GNSSDO(+): ++"RESET"++, ++"BOOT"++, and ++"LOG"++.

<div class="grid" markdown>

<div markdown>

<figure markdown>
Buttons
<figcaption markdown>Buttons on the GNSSDO(+).</figcaption>
</figure>

</div>

<div markdown>

<figure markdown>
Buttons
<figcaption markdown>Buttons on the GNSSDO(+) PCB.</figcaption>
</figure>

</div>

</div>

=== ":septentrio: mosaic-T: Data Logging"
	Once a [logging stream](#sd-socket) is defined, users can control the data logging operation through the ++"LOG"++ button.

	- A short press of the ++"LOG"++ button *(< 5s)* toggles data logging to the SD card on and off.
		- The red `LOG` LED will flash while logging is taking place.
	- Holding the ++"LOG"++ button for more than 5 seconds *(> 5s)* and then releasing it, will force the board to:
		- Unmount the SD card if it was mounted
		- Mount the SD card if it was unmounted
	- The SD card must be mounted to allow data logging by the mosaic-T
	- When the SD card is unmounted, it is accessible as a mass storage device via the CONFIG MOSAIC USB-C interface
		- Files can be read and written over USB while the SD card is unmounted
	- You can enter commands using the `Admin \ Expert Console` to:
		- Change what happens when the disk is full
		- Change how the files are named
		- Change the mounting / unmounting of the disk
	- Consult section 3.2.20 of the [Firmware Reference Guide](https://www.septentrio.com/en/products/gnss-receivers/gnss-receiver-modules/mosaic-t#resources) for more details

	!!! tip "Instructional Video"
		:material-youtube: [How to log data to the SD card of the Septentrio mosaic receiver module](https://youtu.be/Y9tvOebnoxk)

=== ":espressif: ESP32: Reset"
	The ++"RESET"++ button allows users to reset the firmware running on the ESP32-WROVER module without disconnecting the power.

=== ":espressif: ESP32: Boot Control"
	The ++"BOOT"++ button can be used to force the ESP32 into the serial bootloader. Holding down the ++"BOOT"++ button, while connecting the GNSSDO(+) to a computer through its USB-C connector or resetting the board will cause it to enter the <a href="https://docs.espressif.com/projects/esptool/en/latest/esp32/advanced-topics/boot-mode-selection.html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">Firmware Download mode</a>. The ESP32 will remain in this mode until it power cycles (happens automatically after uploading new firmware) or the ++"RESET"++ button is pressed.

	1. Hold the ++"BOOT"++ button down.
	2. Reset the MCU.
		- While unpowered, connect the board to a computer through the USB-C connection.
		- While powered, press the ++"RESET"++ button.
	3. Release the ++"BOOT"++ button.
	4. After programming is completed, reboot the MCU.
		- Press the ++"RESET"++ button.
		- Power cycle the board.

## Jumpers (GNSSDO)

??? note "Never modified a jumper before?"
	Check out our <a href="https://learn.sparkfun.com/tutorials/664">Jumper Pads and PCB Traces tutorial</a> for a quick introduction!

	<div class="grid cards col-4" markdown align="center">

	-   <a href="https://learn.sparkfun.com/tutorials/664">
		<figure markdown>
		Tutorial thumbnail
		</figure>

		---

		**How to Work with Jumper Pads and PCB Traces**</a>

	</div>

There are several jumpers on the GNSSDO PCB which can be used to (e.g.) disable the LEDs or allow measurement of the board's current draw.

<div class="grid" markdown>

<div markdown>

<figure markdown>
Jumpers
<figcaption markdown>
The jumpers on the top of the GNSSDO PCB.
</figcaption>
</figure>

</div>

<div markdown>

<figure markdown>
Jumpers
<figcaption markdown>
The jumpers on the bottom of the GNSSDO PCB.
</figcaption>
</figure>

</div>

</div>

=== "Top"
	- **POE** - This jumper can be used to disconnect the Power-over-Ethernet (PoE) module 50&ohm; load.
		- The PoE module has a minimum load of 200mA. We included the 50&ohm; load to ensure this is met. If you can ensure this by other means, open this jumper to disconnect the load.
	- **Voltage Configuration: A-V**
		- The jumper links A-V can be used to configure the voltage levels and impedance of the SMA connections. Please refer to the [schematic](./assets/board_files/schematic.pdf) for additional information.
		- To configure the 10MHz output for 50 Ohms: open jumper **A** and close jumper **D**.
			- Jumper **A** is closed by default. Open it to select 50 Ohms for the 10MHz output.
			- Jumper **B** is closed by default. It could be used to isolate the gate driving the 10MHz output. Advanced use only.
			- Jumper **C** is open by default. It could be used to select the alternate gate for the 10MHz CMOS output. Advanced use only.
			- Jumper **D** is open by default. Close it to select 50 Ohms for the 10MHz output.
		- To configure the PPS output for 50 Ohms: open jumper **E** and close jumper **H**.
			- Jumper **E** is closed by default. Open it to select 50 Ohms for the PPS output.
			- Jumper **F** is closed by default. It could be used to isolate the gate driving the PPS output. Advanced use only.
			- Jumper **G** is open by default. It could be used to select the alternate gate for the PPS CMOS output. Advanced use only.
			- Jumper **H** is open by default. Close it to select 50 Ohms for the PPS output.
		- Jumpers J,K,L configure the voltage of the Event A input.
			- Jumper **J** is closed by default. It selects VCCIO as the Event A input voltage.
			- Jumper **K** is open by default. Open jumper J and close jumper K to configure Event A for 2.8V.
			- Jumper **L** is open by default. Open jumper J and close jumper L to configure Event A for 1.8V.
		- Jumpers M,N,P configure the voltage of the PPS output.
			- Jumper **M** is closed by default. It selects VCCIO as the PPS output voltage.
			- Jumper **N** is open by default. Open jumper M and close jumper N to configure PPS for 2.8V.
			- Jumper **P** is open by default. Open jumper M and close jumper P to configure PPS for 1.8V.
		- Jumpers R,S,T configure the voltage of the 10MHz output.
			- Jumper **R** is closed by default. It selects VCCIO as the 10MHz output voltage.
			- Jumper **S** is open by default. Open jumper R and close jumper S to configure 10MHz for 2.8V output.
			- Jumper **T** is open by default. Open jumper R and close jumper T to configure 10MHz for 1.8V output.
		- Jumper **U** can be used to isolate the on-board 10MHz TCXO.
			- Open jumper U when connecting an alternate TCXO via the breakout pads on the PCB. Advanced use only.
		- To configure the Event A input for 50 Ohms: close jumper **V**.
			- Jumper **V** is open by default. Close it to select 50 Ohms for the Event A input.

=== "Bottom"
	- LED Jumpers
		- **LINK** - open this jumper to disable the Ethernet Link LED.
		- **SPEED** - open this jumper to disable the Ethernet Speed LED.
		- **RTK** - open this jumper to disable the mosaic-T Real-Time Kinetic LED.
		- **PVT** - open this jumper to disable the mosaic-T Position Velocity Time LED.
		- **LOG** - open this jumper to disable the mosaic-T Log LED.
		- **ERROR** - open this jumper to disable the GNSS error LED.
		- **LOCK** - open this jumper to disable the TCXO lock LED.
		- **PWR** - open this jumper to disable the Power LED.
	- Button Jumpers
		- **BOOT** - open this jumper to disconnect the ESP32 BOOT pushbutton.
		- **RESET** - open this jumper to disconnect the ESP32 RESET pushbutton.
	- **SHLD** (x2) - open these jumpers to isolate the USB-C connector shield from GND.
	- **I^2^C** (x2) - open these dual jumpers to disconnect the pull-ups for the I^2^C buses.
		- Note: there are separate jumpers for the two I^2^C buses: OLED (Qwiic); and the SiTime TCXO.
	- **VIN+** and **VIN-**
		- Open these jumpers if you wish to isolate (disconnect) the external DC power terminals. The breakout pads can then be used to feed in power from an alternate source.
	- **POE+** and **POE-**
		- Open these jumpers if you wish to isolate (disconnect) the Power-over-Ethernet pins on the MOSAIC Ethernet magjack. The breakout pads can then be used to feed in power from an alternate source.
	- **VCCIO**
		- The **VCCIO** jumper can be soldered closed to connect the **CTS** screw terminal to VCCIO. **CTS** can then be used as a power output. The voltage is set by the VCCIO slide switch.
	- **MEAS**
		- Open the **MEAS** jumper if you wish to measure the total current drawn by the GNSSDO(+), or (e.g.) wish to add an ON/OFF switch. The breakout pads can then be used to attach a multimeter or a mechanical power switch.
		- **MEAS** is *upstream* of the two 3.3V regulators and *downstream* of the four power source combination and protection diodes.

## Jumpers (GNSSDO+)

??? note "Never modified a jumper before?"
	Check out our <a href="https://learn.sparkfun.com/tutorials/664">Jumper Pads and PCB Traces tutorial</a> for a quick introduction!

	<div class="grid cards col-4" markdown align="center">

	-   <a href="https://learn.sparkfun.com/tutorials/664">
		<figure markdown>
		Tutorial thumbnail
		</figure>

		---

		**How to Work with Jumper Pads and PCB Traces**</a>

	</div>

There are several jumpers on the GNSSDO+ PCB which can be used to (e.g.) disable the LEDs or allow measurement of the board's current draw.

<div class="grid" markdown>

<div markdown>

<figure markdown>
Jumpers
<figcaption markdown>
The jumpers on the top of the GNSSDO+ PCB.
</figcaption>
</figure>

</div>

<div markdown>

<figure markdown>
Jumpers
<figcaption markdown>
The jumpers on the bottom of the GNSSDO+ PCB.
</figcaption>
</figure>

</div>

</div>

=== "Top"
	- **Voltage Configuration: A-D**
		- The jumper links can be used to configure the voltage levels and impedance of the SMA connections. Please refer to the [schematic](./assets/board_files/SparkPNT_GNSSDO_Plus_schematic.pdf) for additional information.
		- Jumpers A,B,C configure the voltage of the Event A input.
			- Jumper **A** is closed by default. It selects VCCIO as the Event A input voltage.
			- Jumper **B** is open by default. Open jumper A and close jumper B to configure Event A for 2.8V.
			- Jumper **C** is open by default. Open jumper A and close jumper C to configure Event A for 1.8V.
		- To configure the Event A input for 50 Ohms: close jumper **D**.
			- Jumper **D** is open by default. Close it to select 50 Ohms for the Event A input.

=== "Bottom"
	- LED Jumpers
		- **LINK** - open this jumper to disable the Ethernet Link LED.
		- **SPEED** - open this jumper to disable the Ethernet Speed LED.
		- **RTK** - open this jumper to disable the mosaic-T Real-Time Kinetic LED.
		- **PVT** - open this jumper to disable the mosaic-T Position Velocity Time LED.
		- **LOG** - open this jumper to disable the mosaic-T Log LED.
		- **ERROR** - open this jumper to disable the GNSS error LED.
		- **LOCK** - open this jumper to disable the TCXO lock LED.
		- **PWR** - open this jumper to disable the Power LED.
	- Button Jumpers
		- **BOOT** - open this jumper to disconnect the ESP32 BOOT pushbutton.
		- **RESET** - open this jumper to disconnect the ESP32 RESET pushbutton.
	- **SHLD** (x2) - open these jumpers to isolate the USB-C connector shield from GND.
	- **I^2^C** (x2) - open these dual jumpers to disconnect the pull-ups for the I^2^C buses.
		- Note: there are separate jumpers for the two I^2^C buses: OLED (Qwiic); and the oscillator. On GNSSDO+, there are more jumpers for the 5V level-shifted oscillator I^2^C signals.
	- **VIN+** and **VIN-**
		- Open these jumpers if you wish to isolate (disconnect) the external DC power terminals. The breakout pads can then be used to feed in power from an alternate source.
	- **POE+** and **POE-**
		- Open these jumpers if you wish to isolate (disconnect) the Power-over-Ethernet pins on the MOSAIC Ethernet magjack. The breakout pads can then be used to feed in power from an alternate source.
	- **VCCIO**
		- The **VCCIO** jumper can be soldered closed to connect the **CTS** screw terminal to VCCIO. **CTS** can then be used as a power output. The voltage is set by the VCCIO slide switch.
	- **MEAS**
		- Open the **MEAS** jumper if you wish to measure the total current drawn by the GNSSDO(+), or (e.g.) wish to add an ON/OFF switch. The breakout pads can then be used to attach a multimeter or a mechanical power switch.
		- **MEAS** is *upstream* of the two 3.3V regulators and *downstream* of the four power source combination and protection diodes.
		- On GNSSDO+: there is a separate, additional **MEAS** jumper for the OCXO Power Path circuit. Open this to switch / measure the current drawn by the OCXO. **Note:** this could be 1.5A on startup from cold.

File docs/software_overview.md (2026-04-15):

---
icon: fontawesome/solid/computer
---

!!! code "ESP32 Firmware"
	We have intentionally kept the ESP32 firmware as simple as possible - its only tasks are to: discipline the TCXO oscillator; control the OLED display. The intention is that you can easily develop your own firmware for the GNSSDO(+) if the SparkFun firmware does not meet your needs.

	The **[/Firmware/Binaries](https://github.com/sparkfun/SparkFun_GNSSDO/tree/main/Firmware/Binaries)** folder contains the firmware binaries.
	
	You can update or reload the firmware using the [SparkFun RTK Firmware Uploader](https://github.com/sparkfun/SparkFun_RTK_Firmware_Uploader).

	You can of course modify the hardware too, should you want to. The design is completely open-source.

!!! note
	The mosaic-T module has numerous capabilities and a multitude of ways to configure and interface with them. Without regurgitating all the information that is documented in Septentrio's user manuals and videos, we have tried to highlight a good majority of the module's aspects.

	With that said, please feel free to [file an issue](../github/file_issue/#discrepancies-in-the-documentation) if you feel we have missed something that may benefit other users. *(Don't forget to provide us with a link to the documentation and what section the information is located.)*

## :septentrio: mosaic-T

### RxTools Software Suite

!!! tip
	Even if you aren't necessarily interested in it, we highly recommend that users install the [RXTools software suite](https://www.septentrio.com/en/products/gps-gnss-receiver-software/rxtools) before plugging in their board. For Windows PCs, it also includes the USB driver for the module that enables the Ethernet-over-USB support and virtual `COM` ports.

Users should install the [RXTools software suite](https://www.septentrio.com/en/products/gps-gnss-receiver-software/rxtools) on their computer to interact with the mosaic-T module through the USB interface. The software package includes the USB-IP driver[^1] necessary to recognize the board as an ethernet device on Windows PCs (1).
{ .annotate }

1. On Linux, the standard Linux CDC-ACM driver is suitable.

[^1]: On Linux, the standard Linux CDC-ACM driver is suitable.

<article style="text-align: center;" markdown>
[:octicons-download-16:{ .heart } Download the RxTools Software from Septentrio](https://www.septentrio.com/en/products/gps-gnss-receiver-software/rxtools){ .md-button .md-button--primary target="blank" }
</article>

??? info "System Requirements[^2]"

	=== "Operating Systems"

		- Windows 7
		- Windows 8
		- Windows 10
		- Fedora 23 *(or later)* using Qt technology.
			- The standalone tools (except `bin2asc`) will run on older distributions.

	=== "Hardware Requirements"
		The minimal hardware requirements *(1Hz update[^3])*:

		- CPU: 1 GHz processor
		- RAM: 1 GB RAM
		- Screen Resolution: 1024×768 or higher resolution

	[^2]: The system requirements and installation instructions are from the RxTools *v22.1.0* user manual. This information may change in later iterations of the software suite. Please refer to the user manual *(of the version you are utilizing)* for the most accurate information.
	[^3]: Higher data rates will require higher CPU speed and more memory capacity.

??? info "Installation Instructions[^2]"

	=== "Windows"
		Users can install RxTools software suite by running the installation executable[^4](1), located in the `RxTools\windows` directory of the downloaded `*.zip` file[^5]. During the installation process, users will be notified if a previous version of RxTools is already installed then the previous version will be uninstalled. Next, users will need to provide an installation directory for the RxTools software suite. Users will then select which of the following applications[^6] are installed:
		{ .annotate }

		1. For RxTools v22.1.0, the installation filename is `RxTools_22_1_0_Installer.exe` for Windows PCs.

		<!-- Create Break from Annotation (list won't render without comment)-->

		<div class="grid" markdown>

		<div markdown>

		- RxControl
		- SBF Converter
		- SBF Analyzer
		- RxLogger

		</div>

		<div markdown>

		- RxUpgrade
		- RxDownload
		- RxPlanner

		</div>

		<div markdown>

		- Data Link
		- RxAssistant
		- RxLauncher

		</div>

		</div>

	=== "Linux[^1]"
		!!! warning
			It is recommended that users **<span style="color:red">NOT</span>** install RxControl as `root`, for security reasons and to avoid installation overwrites of other system settings. To make RxTools available to more than one user, provide a shared installation directory.

		Users can install RxTools software suite by running the installation binary[^4](1), located in the `RxTools/linux-i386/` directory of the downloaded `*.zip` file[^5]. During the installation, users will be prompted for an installation directory. If there are any previous installations of RxControl, please use a different directory to avoid conflicts.
		{ .annotate }

		1. For RxTools v22.1.0, the installation filename is `RxTools_22_1_0_Installer.bin` for Linux.

		??? info "Permission Settings"
			Once installed, users may need to reconfigure their permission settings:

			<div class="annotate" markdown>

			- RxTools will need rights to access the `/dev/ttyS*` serial ports.

				- To access the serial ports, users must be part of the `uucp` and `lock` groups (1). This can be configured by editing the `/etc/group`[^7] file and adding the username to the lines defining the `uucp` group and the `lock` group.

					For example, when adding the user `jsmith` to the `uucp` group, users would modify the `/etc/group` file as shown below:

					```bash
					{--uucp:x:14:uucp--} # (2)!
					{++uucp:x:14:uucp,jsmith++} # (3)!
					```

				- On Linux machine administered centrally on a local network, ask your system administrator to be included in the `uucp` and `lock` groups.
			- RxTools also needs read/write (`rw`) access(4) to the `/dev/ttyS*` serial ports.

				- Users can change the permissions with the `chmod`[^8] command:

					```bash
					chmod 660 /dev/ttyS<add port> # (5)!>
					```

			</div>

			1. On most Linux operating systems, the `/dev/ttyS*` devices are owned by `root` and belong to the `uucp` group with read/write (`rw`) access. Additionally, the devices are normally locked by writing a file in the `/var/lock/` directory, with the same permissions.
			2. Remove
			3. Replace with this line
			4. By default, users will normally have read/write (`rw`) access to the `/dev/ttyS*` serial ports.
			5. where users must specify the port number<br>*e.g. `/dev/ttyS0` might be port `COM1`*

			!!! note
				In order for these changes to take effect, users must update their environment by logging out and back in.

				Be aware that the X-session has to be restarted as well. On most systems, this can be done by pressing the key combination ++ctrl++ + ++alt++ + ++backspace++

		??? info "64-bit OS"
			In order to run the RxTools on a 64-bit Linux operating system, users might have to install the 32-bit version of the `C` standard library.

			- For Fedora installations, this is the `glibc.i686` package.
			- The equivalent for Debian(/Ubuntu) installations is the `ia32-libs` package.

	[^4]: Users will need administrative privileges to install the RxTools software.
	[^5]: Users may need to extract the RxTools installation files from the downloaded, compressed file.
	[^6]: Please see the release notes for the issues and limitations of the RxTools applications.
	[^7]: Requires c privileges.
	[^8]: Changing these permissions also requires `root` privileges.

### Septentrio USB Driver
=== "Windows"
	If users haven't already installed the [RxTools software suite](https://www.septentrio.com/en/products/gps-gnss-receiver-software/rxtools) on their Windows PC, they will need to install the USB driver[^1] necessary to recognize and interact with the mosaic-T module through the USB interface.

	A Windows USB driver for the mosaic-T can be installed through two methods:

	<div class="annotate" markdown>

	- RxTools Software Suite (1)
	- mosaic-T GNSS Receiver Module (2)

	</div>

	1. The driver is installed during the installation process.
	2. The installation file for the Windows USB driver will be available from the mass-storage device when the board is initially connected to the computer.

	Once installed, the driver emulates two virtual serial ports, which can be accessed as standard `COM` ports to the receiver.

	??? tip "Terminal Emulators"
		Most [terminal emulation programs](https://learn.sparkfun.com/tutorials/112) will not make a distinction between virtual or native COM ports. However, for virtual serial ports, the port settings *(i.e. baud rate, etc.)* are not relevant and the default configuration is used in the terminal emulation program. However, the physical/native `COM` ports will have the following default setting:

		- Baudrate: 115200bps
		- Data Bits: 8
		- Parity: No
		- Stop Bits: 1
		- Flow Control: None

	??? tip "Having Trouble?"
		For users who are having trouble installing the USB driver, we have an archived version *(v3.0.2[^9])* of the installation file. Users can download [**version 3.0.2**](https://docs.sparkfun.com/SparkFun_GNSS_mosaic-T/assets/component_documentation/driver/USB_driver_3_0_2_Installer.exe) of the driver, by clicking on the button below.

		[^9]:
			For the latest USB driver from Septentrio, please install their driver through the [RxTools software suite](../rxtools).<br>
			*This driver version was archived at the time that the [mosaic-T hookup guide](https://docs.sparkfun.com/SparkFun_GNSS_mosaic-T/) was written. Please do not request for the file to be updated.*

		<article style="text-align: center;" markdown>
		[:octicons-download-16:{ .heart } Download USB Driver *(v3.0.2)*](https://docs.sparkfun.com/SparkFun_GNSS_mosaic-T/assets/component_documentation/driver/USB_driver_3_0_2_Installer.exe){ .md-button .md-button--primary target="blank" }
		</article>

=== "Linux"
	On Linux, the standard Linux CDC-ACM driver is suitable for the mosaic-T module.

### Web Interface
With the USB driver installed, the mosaic-T module supports Ethernet-over-USB. The default IP address allocated for the Ethernet-over-USB interface is `192.168.3.1`. This IP can be entered in any browser to open a connection to the receiver's Web Interface as shown below.

<div class="grid" markdown>

<div markdown>

<figure markdown>
navigation tabs in the web interface
<figcaption markdown>All the drop-down navigation tabs in the web interface.</figcaption>
</figure>

</div>

<div markdown>

<article class="video-500px" style="text-align: center; margin: auto;" markdown>
<iframe src="https://www.youtube.com/embed/hrL5J6Q5gX8" title="Septentrio: Getting started with the Septentrio mosaic receiver module" frameborder="0" allow="accelerometer; autoplay; clipboard-write; encrypted-media; gyroscope; picture-in-picture" allowfullscreen></iframe>
</article>

</div>

</div>

!!! info
	The default IP address cannot be changed; this feature is only to be used when a single receiver is connected to your computer.

??? failure "Invalid IP Address *(WiFi Only)*"
	[One of the documentation pages on Septentrio's website](https://customersupport.septentrio.com/s/article/What-is-the-default-IP-address-to-connect-via-WiFi), specifies a default IP address of `192.168.20.1` for the web interface. However, that address is for a WiFi enabled product and cannot be used with this product.

## :espressif: ESP32

### CH340 USB Driver
Users will need to install a USB driver for the CH340 serial-to-USB chip, in order to communicate with the ESP32 module.	The latest USB drivers for the CH340 are available from the manufacturer, on the [WCH website](https://www.wch-ic.com/products/CH340.html?):

<article style="text-align: center;" markdown>
[:octicons-download-16:{ .heart } Download the latest CH340 USB driver from WCH](https://www.wch-ic.com/products/CH340.html?){ .md-button .md-button--primary target="blank" }
</article>

??? abstract "Need Directions?"
	For users having trouble installing the CH340 USB driver, check out our video and hookup guide:

	<div class="grid" markdown align="center">

	<div markdown>

	<div class="video-500px">
	<iframe src="https://www.youtube.com/embed/MM9Fj6bwHLk" title="Tutorial: Installing CH340 Drivers" frameborder="0" allow="accelerometer; autoplay; clipboard-write; encrypted-media; gyroscope; picture-in-picture" allowfullscreen></iframe>
	</div>

	</div>

	<div class="grid cards" markdown>

	-   <a href="https://learn.sparkfun.com/tutorials/908">
		<figure markdown>
		Tutorial Thumbnail
		</figure>

		---

		**How to Install CH340 Drivers**</a>

	</div>

	</div>

### Terminal Emulator
In order to configure the firmware settings on the ESP32, users will need to install a [serial terminal emulator](https://learn.sparkfun.com/tutorials/terminal-basics) on their computer.

=== "Windows"
	For Windows computers, we highly recommend [TeraTerm](https://teratermproject.github.io/index-en.html).

=== "Linux"
	Some Linux operating systems will already have the `screen` terminal emulator preinstalled.

!!! abstract "Need Directions?"
	Check out our hookup guide to install your favorite terminal emulator:

	<div class="grid cards" markdown align="center">

	-   <a href="https://learn.sparkfun.com/tutorials/112">
		<figure markdown>
		Tutorial Thumbnail
		</figure>

		---

		**Serial Terminal Basics**</a>

	</div>

## :fontawesome-solid-screwdriver-wrench: Software Settings

When connected to the ESP32 CH340 COM port at 115200 baud, pressing any key in the terminal emulator will open the firmware Main Menu:

<figure markdown>
ESP32 firmware main menu
<figcaption markdown>The ESP32 firmware main menu.</figcaption>
</figure>

### Configure Operation

Select option **c** ("c" followed by "Enter") to configure the firmware:

<figure markdown>
ESP32 firmware configuration menu
<figcaption markdown>The ESP32 firmware configuration menu.</figcaption>
</figure>

- **1)  Minimum TCXO Warm Up (s)**
	- This defines the minimum oscillator warmp-up in state STATE_TCXO_WARMUP
	- Default: 120s
	- **GNSSDO+ only**
- **2)  Required TCXO Temperature Stability (ADU)**
	- This defines the required temperature stability to exit STATE_TCXO_WARMUP
	- Default: 0.01 ADU
	- **GNSSDO+ only**
- **10) PI P term for initial frequency steering**
	- This defines the PI control loop Proportional term used during initial frequency locking
	- The default value depends on the oscillator (GNSSDO vs. GNSSDO+)
- **11) PI I term for initial frequency steering**
	- This defines the PI control loop Integral term used during initial frequency locking
	- The default value depends on the oscillator (GNSSDO vs. GNSSDO+)
- **12) Required bias stability for frequency lock**
	- The firmware will stay in state STATE_GNSS_FINETIME until the _change_ in **Bias** reaches this
	- Default: 1.0e-10
- **13) PI P term for fast ramping**
	- This defines the PI control loop Proportional term used during fast ramping (state STATE_GNSS_FREQUENCY_LOCK) to remove the large initial bias
	- The default value depends on the oscillator (GNSSDO vs. GNSSDO+)
- **14) PI I term for fast ramping**
	- This defines the PI control loop Integral term used during fast ramping (state STATE_GNSS_FREQUENCY_LOCK) to remove the large initial bias
	- The default value depends on the oscillator (GNSSDO vs. GNSSDO+)
- **15) TCXO steering ramp rate limit (s/s)**
	- This setting limits the maximum rate (change) in the setpoint during fast ramping
	- The default value depends on the oscillator (GNSSDO vs. GNSSDO+) but is typically 250ns/s
- **16) TCXO steering ramp step size (s)**
	- This setting sets the rate of change of the setpoint during fast ramping
	- The default value depends on the oscillator (GNSSDO vs. GNSSDO+) but is typically 0.5ns
- **17) TCXO steering ramp asymmetry**
	- If needed, this setting can be used to adjust the step size used during the 'down' ramp compared to the 'up'
	- The default value is 1.0 = no asymmetry
	- A value of 0.5 makes the 'down' ramp steps half the size of the 'up' ramp
	- If 16) is set to 1.0ns, and 17) is set to 0.5, the 'down' ramp steps will be 0.5ns. The 'down' ramp will take twice as long as the 'up'
	- If 16) is set to 1.0ns, and 17) is set to 2.0, the 'down' ramp steps will be 2.0ns. The 'down' ramp will take half the time of the 'up'
- **18) TCXO steering ramp minimum repeats**
	- This sets the minimum number of times state STATE_GNSS_FREQUENCY_LOCK is repeated
	- The default value depends on the oscillator (GNSSDO vs. GNSSDO+)
- **19) Required bias for phase lock (s)**
	- The firmware will stay in state STATE_GNSS_FREQUENCY_LOCK if the **Bias** exceeds this after fast ramping
	- Default: 100ns
- **20) PI P term for final TCXO disciplining**
	- This defines the Proportional term for the TCXO frequency PI control loop
	- The default value depends on the oscillator (GNSSDO vs. GNSSDO+)
- **21) PI I term for final TCXO disciplining**
	- This defines the Integral term for the TCXO frequency PI control loop
	- The default value depends on the oscillator (GNSSDO vs. GNSSDO+)
- **30) Prefer non-composite GPS bias - if available**
	- With a subscription to Fugro AtomiChron, this option allows the individual GPS clock bias to be preferred over the composite Fugro bias.
	- You can enable a preference for either GPS or Galileo. Enabling GPS will disable Galileo.
- **31) Prefer non-composite Galileo bias - if available**
	- With a subscription to Fugro AtomiChron, this option allows the individual Galileo clock bias to be preferred over the composite Fugro bias.
	- You can enable a preference for either GPS or Galileo. Enabling Galileo will disable GPS.
- **40) Pulse-Per-Second Interval**
	- This defines the interval of the PPS signal. The intervals are defined by the mosiac-T firmware. Use "40" and "Enter" to scroll through the intervals:
		- "off"
		- "msec10"
		- "msec20"
		- "msec50"
		- "msec100"
		- "msec200"
		- "msec250"
		- "msec500"
		- "sec1"
		- "sec2"
		- "sec4"
		- "sec5"
		- "sec10"
		- "sec30"
		- "sec60"
- **41) Pulse-Per-Second Polarity**
	- This defines the PPS signal polarity: Low2High or High2Low
- **42) Pulse-Per-Second Delay (ns)**
	- This allows the timing of the PPS signal to be advanced or retarded. The units are nanoseconds
	- On GNSSDO+:
		- Advanced users may want to adjust this to ensure a slight mis-alignment between PPS and the 10MHz clock
		- This would ensure their rising edges are slightly separated and that the 74LVC1G175 flip-flop (U15) produces a clean output
		- Consult page 7 of the [GNSSDO+ schematic](./assets/board_files/SparkPNT_GNSSDO_Plus_schematic.pdf) for more details
- **43) Pulse-Per-Second Time Scale**
	- This defines which time scale is used to generate the PPS signal.
		- "GPS"
		- "Galileo"
		- "BeiDou"
		- "GLONASS"
		- "UTC"
		- "RxClock"
- **44) Pulse-Per-Second Max Sync Age (s)**
	- This defines how long PPS pulses will be produced when the GNSS signal is lost or jammed: 0 to 3600 seconds
- **45) Pulse-Per-Second Pulse Width (ms)**
	- This defines the width of the PPS signal. The units are milliseconds: 0.000001 to 1000.000000
- **50) TCP Server (IPS1)**
	- See [TCP Server (IPS1)](#tcp-server-ips1) below for more details
- **51) TCP Server Port**
	- The port for the TCP connection. Default is 28785
- **60) Save TCXO control word to TCXO memory**
	- This option allows the current TCXO control word to be saved manually to TCXO internal memory
	- **GNSSDO+ only**
	- This may be useful when setting up a new GNSSDO+. E.g. the control word could be saved manually when state STATE_GNSS_FINETIME is _almost_ complete
	- The control word will be saved automatically when the firmware has been in state STATE_GNSS_PHASE_LOCK for one hour

To reset all settings to their default values, select "r", "Enter", "y", "Enter"

The settings are saved to non-volatile memory (NVM, LittleFS) on exiting the menu. Ensure you fully exit the menu ("x", "Enter", "x", "Enter") to save any modified settings.

The TCXO frequency control word is saved to NVM once per hour, to allow a quicker startup at the next power-on.

### TCP Server (IPS1)

When **TCP Server (IPS1)** is enabled, the ESP32 serial console is diverted from the CH340 USB (CONFIG ESP32) interface to the mosaic-T COM3 UART interface and daisy chained to the IPS1 TCP server. The configuration menu and debug messages can then be accessed over TCP / Telnet on the chosen port. The CH340 USB (CONFIG ESP32) interface is then no longer active.

TCP / Telnet is supported over both Ethernet and the Ethernet-over-USB connection. Only one TCP2Way connection is supported.

If you are using Tera Term:

- Select **TCP/IP** and **Telnet**
- Enter the mosaic-T's IP address in **Host**
	- If you are connected via the CONFIG MOSAIC Ethernet-over-USB interface, the IP address is 192.168.3.1
- Enter the TCP Server Port number in **TCP port#**
	- The default port is 28785

<figure markdown>
Tera Term configuration for TCP
<figcaption markdown>Tera Term configuration for TCP.</figcaption>
</figure>

### Debug Software

Select option **d** ("d" followed by "Enter") to configure the software debug options:

<figure markdown>
ESP32 firmware debug menu
<figcaption markdown>The ESP32 firmware debug menu.</figcaption>
</figure>

The debug options are what we use at SparkFun to check that the firmware is running correctly. You should not need change any of the options, except perhaps option 8 **Print conditions**. This option controls the periodic CSV messages seen in the console when the menu is closed. The format can be changed to human-readable text, or the messages can be disabled if desired.

### Print Conditions (periodic messages)

The format of the **Print conditions** CSV data is:

**YYYY/MM/DD,HH:MM:SS,Epoch,Lat,Lon,Alt,TimeSys,Error,Fine,PPS,Bias,Drift,Source,TCXO,PkSteer,IkSteer,PkRamp,IkRamp,Pk,Ik,Press,Temp,Hum,TCXO_Temp,Mode,Temp_Smooth,Bias_Smooth,Rate,Rate_Held,Setpoint,Turn,Error,Repeat**

- **YYYY/MM/DD** is the date from the ReceiverTime SBF message
- **HH:MM:SS** is the time from the ReceiverTime SBF message
- **Epoch** is the date and time in Unix epoch format: seconds.milliseconds from midnight UTC January 1st 1970. This is useful when plotting the data against time.
- **Lat** is the Latitude in degrees from the PVTGeodetic SBF message (7 decimal places)
- **Lon** is the Longitude in degrees from the PVTGeodetic SBF message (7 decimal places)
- **Alt** is the Altitude in metres from the PVTGeodetic SBF message (0.1mm resolution)
- **TimeSys** is the named TimeSystem from the PVTGeodetic SBF message
- **Error** is the Error byte from the PVTGeodetic SBF message. 0 indicates no error
- **Fine** is the FINETIME bit from the SyncLevel byte from the ReceiverTime SBF message
- **PPS** indicates if the Pulse-Per-Second output is enabled
	- PPS is enabled when the RxClkBias reaches the required accuracy, set by **RX Clock Bias Lock Limit**
- **Bias** is the receiver clock bias in seconds
- **Drift** is the receiver clock drift in PPM
- **Source** is the source of the receiver clock bias reported in **Bias**
	- By default, this is **PVT** indicating the source is the composite RxClkBias from the PVTGeodetic SBF message
	- If AtomiChron is enabled and if **Prefer non-composite GPS bias** or **Prefer non-composite Galileo bias** has been selected, this will change to **GPS** or **Galileo** indicating that the individual non-composite bias from the FugroTimeOffset SBF message is available and is being used
- **TCXO** is the frequency control word written to the temperature-controlled oscillator
- **PkSteer** is the PI control loop Proportional term used during initial frequency locking - set in the configuration menu
- **IkSteer** is the PI control loop Integral term used during initial frequency locking - set in the configuration menu
- **PkRamp** is the PI control loop Proportional term during fast ramping to remove the large initial bias - set in the configuration menu
- **IkRamp** is the PI control loop Integral term during fast ramping to remove the large initial bias - set in the configuration menu
- **Pk** is the PI control loop Proportional term for the main Phase-Locked Loop - set in the configuration menu
- **Ik** is the PI control loop Integral term for the main Phase-Locked Loop - set in the configuration menu
- **Press** is the atmospheric pressure in hPa (mbar) : **GNSSDO Plus (GNSSDO+) only**
- **Temp** is the internal temperature in degrees C : **GNSSDO Plus (GNSSDO+) only**
- **Hum** is the relative humidity in %RH : **GNSSDO Plus (GNSSDO+) only**
- **TCXO_Temp** is the temperature-controlled oscillator internal temperature in ADU : **GNSSDO Plus (GNSSDO+) only**
- **Mode** is the firmware mode / state. Possible values are:
	- NOT_CONFIGURED
    - CONFIGURED
    - ERROR_BEFORE_FINETIME
    - WARMUP
    - ERROR_DURING_WARMUP
    - FINETIME
    - ERROR_AFTER_FINETIME
    - FREQUENCY_LOCK
    - ERROR_AFTER_FREQUENCY_LOCK
    - PHASE_LOCK
    - ERROR_AFTER_PHASE_LOCK
- **Temp_Smooth** is the exponentially smoothed **TCXO_Temp** : state STATE_TCXO_WARMUP only : **GNSSDO Plus (GNSSDO+) only**
- **Bias_Smooth** is the exponentially smoothed _change_ in **Bias** : state STATE_GNSS_FINETIME only
- **Rate** is the ramp rate (s/s) during state STATE_GNSS_FREQUENCY_LOCK
- **Rate_Held** is the capped ramp rate (s/s) during state STATE_GNSS_FREQUENCY_LOCK
- **Setpoint** is the Bias target value which during ramping in state STATE_GNSS_FREQUENCY_LOCK
- **Turn** is the turn-around point in state STATE_GNSS_FREQUENCY_LOCK, from the 'up' ramp to the 'down' ramp
- **Error** is the error term (difference between the **Setpoint** and the **Bias**) in state STATE_GNSS_FREQUENCY_LOCK
- **Repeat** is the count of the number of times state STATE_GNSS_FREQUENCY_LOCK has been repeated

!!! note
	The GNSSDO Plus (GNSSDO+) contains a MS8607 pressure, temperature and humidity sensor. The readings are reported in the periodic messages as **Press**, **Temp** and **Hum**.
	
	The temperature reading will be higher than expected due to the sensor's proximity to the OCXO. The OCXO runs at elevated temperature; heat will be coupled to the sensor by convection, radiation and conduction (through the PCB).

## :fontawesome-solid-screwdriver-wrench: Firmware Upgrade

The **[/Firmware/Binaries](https://github.com/sparkfun/SparkFun_GNSSDO/tree/main/Firmware/Binaries)** folder contains the firmware binaries. v3.0 is the latest stable release - as at 4-13-26.

You can update or reload the firmware using the [SparkFun RTK Firmware Uploader](https://github.com/sparkfun/SparkFun_RTK_Firmware_Uploader).

See [below](#fontawesome-solid-screwdriver-wrench-uploading-firmware---using-esptool) for details on how to upload with esptool from the command line.

## :fontawesome-solid-screwdriver-wrench: Compiling Firmware - using Docker

To compile the GNSSDO Firmware, you need to use the correct version of the ESP32 Arduino core and of each required Arduino library. It is tedious and error-prone. Especially on Windows. We've lost count of the number of times code compilation fails on our local machines, because we had the wrong ESP32 core installed... It is much easier to sandbox the firmware compilation using an environment like [Docker](https://www.docker.com/).

Docker is open-source. It is our new favourite thing!

Here is a step-by-step guide for how to install Docker and compile the firmware from scratch:

### Clone, fork or download the GNSSDO repo

To build the GNSSDO Firmware, you obviously need a copy of the source code.

Click on the icon below to download a copy of the main (released) branch:

Download ZIP (https://github.com/sparkfun/SparkFun_GNSSDO/archive/refs/heads/main.zip "Download ZIP (main branch)")

For the real Wild West experience, you can also download a copy of the `release_candidate` code branch. This is where the team is actively changing and testing the code, before it becomes a full release. The code there will _usually_ compile and will _usually_ work, but we don't guarantee it! We may be part way through implementing some breaking changes at the time of your download...

Download ZIP - release candidate (https://github.com/sparkfun/SparkFun_GNSSDO/archive/refs/heads/release_candidate.zip "Download ZIP (release_candidate branch)")

### Install Docker Desktop

* **(Optional)** Head to [Docker](https://www.docker.com/) and create an account. A free "Personal" account will cover occasional compilations of the firmware
* Download and install [Docker Desktop](https://docs.docker.com/get-started/get-docker/) - there are versions for Mac, Windows and Linux. You may need to restart to complete the installation.
* Run the Desktop
    * You don't _need_ to have an account and you don't _need_ to be signed in
    * You only need to be signed in if you want to store or share your Container on Docker Hub
    * If you don't sign in, Docker Desktop will run in Personal mode - which will cover local compilations of the firmware
* On Windows, you may see an error saying "**WSL needs updating** Your version of Windows Subsystem for Linux (WSL) is too old". If you do:
    * Open a command prompt
	* Type `wsl --update` to update WSL. At the time of writing, this installs Windows Subsystem for Linux 2.6.1
	* Restart the Docker Desktop
* If you are using Docker for the first time, the "What is a container?" and "How do I run a container?" demos are useful - _but not essential_
    * On Windows, you may want to give Docker Desktop permission to access to your Network, so it can access (e.g.) HTML ports
	* You can Stop the container and Delete it when you are done
* You may want to prevent Docker from running when your machine starts up
    * Uncheck "Start Docker Desktop when you sign in to your computer" in the Desktop settings

### Using Docker to create the firmware binary

* **Make sure you have Docker Desktop running.** You don't need to be signed in, but it needs to be running.
* Open a Command Prompt and `cd` into the SparkFun_GNSSDO folder
* Check you are in the right place. Type `dir` and hit enter. You should see the following files and folders:

```
    .gitattributes
    .github
    .gitignore
	CONTRIBUTING.md
    docs
    Firmware
```

* `cd Firmware` and then `dir` again. You should see:

```
    app3M_fat9M_16MB.csv
	Binaries
    compile_with_docker.bat
    Dockerfile
    GNSSDO_Firmware
	Utils
```

* The file that does most of the work is the `Dockerfile`

* Run `compile_with_docker.bat` to compile the firmware. It does everything for you

* Type `dir` again. Hey presto! You have your newly compiled firmware binary!

You can then use (e.g.) the [SparkFun RTK Firmware Uploader](https://github.com/sparkfun/SparkFun_RTK_Firmware_Uploader) to upload the binary onto the ESP32.

You may find the `.elf` file useful if you are trying to debug the code with [me-no-dev's Exception Decoder](https://github.com/me-no-dev/EspExceptionDecoder).

## :fontawesome-solid-screwdriver-wrench: Uploading Firmware - using esptool

The [SparkFun RTK Firmware Uploader](https://github.com/sparkfun/SparkFun_RTK_Firmware_Uploader) contains a copy of Espressif's esptool. It is esptool that actually performs the code upload.

If you want to upload new firmware manually from the command line, here are the commands:

```
esptool.py --chip esp32 --port /dev/ttyUSB0 --baud 460800 --before default_reset --after no_reset write_flash -z --flash_mode dio --flash_freq 80m --flash_size detect 0x1000 RTK_Surveyor.ino.bootloader.bin 0x8000 RTK_Surveyor_Partitions_16MB.bin 0xe000 boot_app0.bin 0x10000 GNSSDO_Firmware.ino.bin
```

followed by:

```
esptool.py --chip esp32 --port /dev/ttyUSB0 --before default_reset run
```

On Windows, you can replace `esptool.py` with `esptool.exe`. You can find a copy of `esptool.exe` in the [Utils](https://github.com/sparkfun/SparkFun_GNSSDO/tree/release_candidate/Firmware/Utils) folder.

On Windows, replace `/dev/ttyUSB0` with the name of your CH340 COM port: `COM1` or similar.

You can find copies of `RTK_Surveyor.ino.bootloader.bin`, `RTK_Surveyor_Partitions_16MB.bin` and `boot_app0.bin` in the [Firmware Uploader resource folder](https://github.com/sparkfun/SparkFun_RTK_Firmware_Uploader/tree/main/RTK_Firmware_Uploader/resource).

Enjoy!

* Your friends at SparkFun

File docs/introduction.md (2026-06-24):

---
icon: material/book-open-page-variant
---

!!! failure "Deprecated Documentation"
	As of Apr 24, 2026 this guide has been retired. Users can find our latest documentation at: [docs.sparkpnt.com/SXT](https://docs.sparkpnt.com/SXT)

# Introduction

<div class="grid cards" markdown>

-   <a href="https://www.sparkpnt.com/products/sxt-gnssdo">
	**GNSSDO**<br>
	**SKU:** SXT

	---

	<figure markdown>
	Product Thumbnail
	</figure></a>

	<article style="text-align: center;" markdown>
	[Purchase from SparkPNT :fontawesome-solid-cart-plus:{ .heart } QR code to product page](https://www.sparkpnt.com/products/sxt-gnssdo){ .md-button .md-button--primary }
	</article>

-   <a href="https://www.sparkpnt.com/products/sxt-d-gnssdo">
	**GNSSDO+**<br>
	**SKU:** SXT-D

	---

	<figure markdown>
	Product Thumbnail
	</figure></a>

	<article style="text-align: center;" markdown>
	[Purchase from SparkPNT :fontawesome-solid-cart-plus:{ .heart } QR code to product page](https://www.sparkpnt.com/products/sxt-d-gnssdo){ .md-button .md-button--primary }
	</article>

</div>

Designed and manufactured in Boulder, Colorado, USA, the SparkPNT GNSSDO / GNSSDO+ are the perfect solution for your high-precision timing needs. Based around the multi-constellation, multi-frequency, L5-ready mosaic-T from Septentrio, these are our most accurate GNSS timing product to date. The GNSSDO features a SiTime SiT5358 disciplined 10MHz Digitally-Controlled Temperature-Controlled Crystal Oscillator (DCTCXO) providing excellent clock accuracy and stability. The GNSSDO+ gets an upgrade from the Rakon STP3593LF disciplined 10MHz Digitally-Controlled Double-Oven Crystal Oscillator (OCXO) providing superb clock accuracy, stability and holdover. The mosaic-T also has built-in on-module support for the Fugro AtomiChron L-band timing service.

<article class="video-500px" style="text-align: center; margin: auto;" markdown>
<iframe src="https://www.youtube.com/embed/WI0NbXBxeUo" title="Product Showcase Video" frameborder="0" allow="accelerometer; autoplay; clipboard-write; encrypted-media; gyroscope; picture-in-picture" allowfullscreen></iframe>
</article>

Under the hood, the GNSSDO and GNSSDO+ are based on the mosaic-T GNSS module from Septentrio, plus the Espressif ESP32-WROVER processor (16MB flash, 8MB PSRAM). The mosaic-T has USB-C connectivity (with Ethernet-over-USB), multiple UARTs and supports full Ethernet connectivity. You can connect the mosaic-T directly to your Ethernet network - our product supports Power-over-Ethernet too. The ESP32 rides shotgun, disciplining the oscillator and controlling the OLED display. The GNSSDO and GNSSDO+ have multiple power options including USB-C, PoE and 9V-36V DC, making it easy to connect them to a battery-backed supply. Robust SMA connections and screw cage terminals provide access to the Pulse-Per-Second and 10MHz clock signals.

??? info "Features"
	- Septentrio mosaic-T multi-constellation, multi-frequency GNSS timing receiver
		- Accurate and resilient with dedicated timing features
		- Highly secure against jamming and spoofing with AIM+ unique interference mitigation technology combined with Fugro AtomiChron services
		- Update rate of 10 Hz
		- 448 hardware channels for simultaneous tracking of all visible supported satellite signals:
			- GPS: L1C/A, L1PY, L2C, L2P, L5
			- GLONASS: L1CA, L2CA, L2P, L3 CDMA
			- Beidou: B1I, B1C, B2a, B2b, B2I, B3
			- Galileo: E1, E5a, E5b, E5 AltBoc, E6
			- QZSS: L1C/A, L1 C/B, L2C, L5
			- NavIC: L5
			- SBAS: Egnos, WAAS, GAGAN, MSAS, SDCM (L1, L5)
			- On-module L-band
		- Time pulse precision: 5ns
		- Time pulse precision with AtomiChron (L-Band or IP): < 1ns
		- Event accuracy: < 20ns
		- Operating temperature: -40 to 85 °C
		- USB-C interface (UART and Ethernet-over-USB)
		- **RTK is not supported**
	- ESP32-WROVER processor (16MB flash, 8MB PSRAM)
		- USB-C interface (UART via CH340)
	- GNSSDO: SiT5358 disciplined 10MHz oscillator
		- ±50ppb stability
		- ±1ppb/°C frequency slope
		- ±58ppb typical 20-year aging
		- Digital frequency pulling via I²C
		- [Allan Deviation](./assets/img/hookup_guide/Allan_Deviation.jpg) approaches 1E-14 at 10000 seconds with AtomiChron enabled
		- Operating temperature: -40 to 85 °C (Industrial)
	- GNSSDO+: STP3593LF disciplined 10MHz oscillator
		- Better than 50ppb frequency calibration at 25°C
		- ±0.2ppb per day frequency stability (aging)
		- ±0.03ppb frequency stability with temperature (-32°C to +70°C)
		- Digital frequency pulling via I²C
		- [Allan Deviation](./assets/img/hookup_guide/GNSSDO+_Allan_Deviation.png) below 1E-14 at 10000 seconds with AtomiChron<sup>®</sup> enabled
		- Operating temperature: -32 to 70 °C
	- microSD socket
		- Connected directly to the mosaic-T for fast data logging
	- OLED display
		- 128x64 pixels
	- Status LEDs

??? info "Connectivity Options"
	- SMA Connections:
		- GNSS Antenna (L1/L2/L5/L-Band) - provides 3.3V for an active antenna
		- GNSSDO:
			- 10MHz Output - disciplined, configurable for 5V / 3.3V / 2.8V / 1.8V and 50 Ohm
			- 10MHz Input - switchable, input impedance 50Ω, detection level -14dBm, max supported level +12dBm
			- Pulse-Per-Second Square Wave - configurable for 5V / 3.3V / 2.8V / 1.8V and 50 Ohm
		- GNSSDO+:
			- 10MHz Output - disciplined, 3.3V
			- Pulse-Per-Second Square Wave - 3.3V, aligned to the 10MHz clock signal
		- EventA Input - configurable for 5V / 3.3V / 2.8V / 1.8V and 50 Ohm
	-	3.5mm Screw Cage Connections:
		- 9V-36V DC input (isolated)
		- GND
		- mosaic-T COM2 (TX/RX/CTS/RTS) - 3.3V / 5V switchable
		- CTS can be configured as a 3.3V / 5V power output via a solder jumper
		- EventB input - 3.3V / 5V switchable
		- GNSSDO:
			- I^2^C (SCL2 / SDA2) for an external TCXO / OCXO - 3.3V / 5V switchable
		- GNSSDO+:
			- mosaic-T GP1 and GP2 outputs - 3.3V / 5V switchable
	-	Ethernet:
		- KSZ8041NLI Ethernet PHY interface
		- 10Base-T / 100Base-TX with auto-negotiate and Auto MDI/MDI-X
	-	Power Options:
		- USB-C
			- GNSSDO+ requires a Power Delivery Wall Adapter
		- Power-over-Ethernet (PoE)
		- 9V-36V DC input (fully isolated)

!!! warning "RTK Not Supported"
	The mosaic-T is a superb GNSS module designed for highly accurate timing applications. **However, RTK is not supported.**

??? question "Product Comparison"
	Below is a simple comparison table between our breakout board and Septentrio's development and evaluation kits:

	<div class="annotate" markdown align="center">
	<table markdown>
	<tr markdown>
	<td></td>
	<th markdown style="text-align:center">
		mosaic-T Development Kit<br>
		<hr>
		<figure markdown>
		Product Thumbnail
		</figure>
	</th>
	<th markdown style="text-align:center">
		mosaic-go Evaluation Kit<br>
		<hr>
		<figure markdown>
		Product Thumbnail
		</figure>
	</th>
	<th markdown style="text-align:center">
		mosaic-X5 GNSS Breakout<br>
		<hr>
		<figure markdown>
		Product Thumbnail
		</figure>
	</th>
	<th markdown style="text-align:center">
		RTK mosaic-X5<br>
		<hr>
		<figure markdown>
		Product Thumbnail
		</figure>
	</th>
	<th markdown style="text-align:center">
		GNSSDO<br>
		<hr>
		<figure markdown>
		Product Thumbnail
		</figure>
	</th>
	<th markdown style="text-align:center">
		GNSSDO+<br>
		<hr>
		<figure markdown>
		Product Thumbnail
		</figure>
	</th>
	</tr>
	<tr>
		<td>RTK Rover</td>
		<td style="text-align:center">Yes</td>
		<td style="text-align:center">Yes</td>
		<td style="text-align:center">Yes</td>
		<td style="text-align:center">Yes</td>
		<td style="text-align:center">**No**</td>
		<td style="text-align:center">**No**</td>
	</tr>
	<tr>
		<td>RTK Base</td>
		<td style="text-align:center">Yes</td>
		<td style="text-align:center">Yes</td>
		<td style="text-align:center">Yes</td>
		<td style="text-align:center">Yes</td>
		<td style="text-align:center">**No**</td>
		<td style="text-align:center">**No**</td>
	</tr>
	<tr>
		<td style="vertical-align:middle;">GNSS Antenna</td>
		<td style="text-align:center; vertical-align:middle;">Dual</td>
		<td style="text-align:center">
			Single (mosaic-X5)<br>
			Dual (mosaic-H)
		</td>
		<td style="text-align:center; vertical-align:middle;">Single</td>
		<td style="text-align:center; vertical-align:middle;">Single</td>
		<td style="text-align:center; vertical-align:middle;">Single</td>
		<td style="text-align:center; vertical-align:middle;">Single</td>
	</tr>
	<tr>
		<td>USB Connector</td>
		<td style="text-align:center">micro-B</td>
		<td style="text-align:center">micro-B</td>
		<td style="text-align:center">Type-C</td>
		<td style="text-align:center">Type-C</td>
		<td style="text-align:center">Type-C</td>
		<td style="text-align:center">Type-C</td>
	</tr>
	<tr>
		<td style="vertical-align:middle;">Ethernet</td>
		<td style="text-align:center; vertical-align:middle;">
			Yes<br>
			<i>10/100 Base-T</i>
		</td>
		<td style="text-align:center; vertical-align:middle;">No</td>
		<td style="text-align:center; vertical-align:middle;">No</td>
		<td style="text-align:center">
			Yes<br>
			<i>10/100 Base-T</i>
		</td>
		<td style="text-align:center">
			Yes<br>
			<i>10/100 Base-T</i>
		</td>
		<td style="text-align:center">
			Yes<br>
			<i>10/100 Base-T</i>
		</td>
	</tr>
	<tr>
		<td style="vertical-align:middle;">WiFi</td>
		<td style="text-align:center; vertical-align:middle;">No</td>
		<td style="text-align:center; vertical-align:middle;">No</td>
		<td style="text-align:center; vertical-align:middle;">No</td>
		<td style="text-align:center">
			Yes - Network Bridge<br>
			<i>10 Base-T</i>
		</td>
		<td style="text-align:center; vertical-align:middle;">No</td>
		<td style="text-align:center; vertical-align:middle;">No</td>
	</tr>
	<tr>
		<td style="vertical-align:middle;">COM Ports</td>
		<td style="text-align:center">4</td>
		<td style="text-align:center">2</td>
		<td style="text-align:center">4</td>
		<td style="text-align:center">
			1 - mosaic-X5<br>
			1 - ESP32
		</td>
		<td style="text-align:center">
			1 - mosaic-T<br>
			1 - ESP32
		</td>
		<td style="text-align:center">
			1 - mosaic-T<br>
			1 - ESP32
		</td>
	</tr>
	<tr>
		<td>&micro;SD Card Slot</td>
		<td style="text-align:center">Yes</td>
		<td style="text-align:center">Yes</td>
		<td style="text-align:center">Yes</td>
		<td style="text-align:center">Yes</td>
		<td style="text-align:center">Yes</td>
		<td style="text-align:center">Yes</td>
	</tr>
	<tr>
		<td style="vertical-align:middle;">Reset/Log Buttons</td>
		<td style="text-align:center; vertical-align:middle;">Yes</td>
		<td style="text-align:center; vertical-align:middle;">No*</td>
		<td style="text-align:center; vertical-align:middle;">Yes</td>
		<td style="text-align:center; vertical-align:middle;">Yes</td>
		<td style="text-align:center; vertical-align:middle;">Yes</td>
		<td style="text-align:center">Yes</td>
	</tr>
	<tr>
		<td style="vertical-align:middle;">Logic-Level</td>
		<td style="text-align:center">
			1.8V<br>
			3.3V
		</td>
		<td style="text-align:center; vertical-align:middle;">3.3V</td>
		<td style="text-align:center; vertical-align:middle;">3.3V</td>
		<td style="text-align:center">
			3.3V<br>
			5V
		</td>
		<td style="text-align:center">
			3.3V<br>
			5V
		</td>
		<td style="text-align:center">
			3.3V<br>
			5V
		</td>
	</tr>
	<tr>
		<td>PPS Signal</td>
		<td style="text-align:center">Header Pin</td>
		<td style="text-align:center">6-Pin JST Connector</td>
		<td style="text-align:center">SMA Connector</td>
		<td style="text-align:center">Screw Terminal</td>
		<td style="text-align:center">SMA Connector</td>
		<td style="text-align:center">SMA Connector</td>
	</tr>
	<tr>
		<td style="vertical-align:middle;">10MHz Signal</td>
		<td style="text-align:center">
			SMA Connector<br>
			<i>In Only</i>
		</td>
		<td style="text-align:center; vertical-align:middle;">No</td>
		<td style="text-align:center; vertical-align:middle;">No</td>
		<td style="text-align:center; vertical-align:middle;">No</td>
		<td style="text-align:center">
			SMA Connector<br>
			<i>In/Out</i>
		</td>
		<td style="text-align:center">
			SMA Connector<br>
			<i>Out only</i>
		</td>
	</tr>
	<tr>
		<td>Enclosure Material</td>
		<td style="text-align:center; vertical-align:middle;">N/A</td>
		<td style="text-align:center; vertical-align:middle;">Metal</td>
		<td style="text-align:center; vertical-align:middle;">N/A</td>
		<td style="text-align:center; vertical-align:middle;">Aluminum</td>
		<td style="text-align:center; vertical-align:middle;">Aluminum</td>
		<td style="text-align:center; vertical-align:middle;">Aluminum</td>
	</tr>
	<tr>
		<td style="vertical-align:middle;">Dimensions</td>
		<td style="text-align:center; vertical-align:middle;">N/A</td>
		<td style="text-align:center; vertical-align:middle;">71 x 59 x 12mm ± 1mm</td>
		<td style="text-align:center; vertical-align:middle;">70.9 x 50.8 x 8mm</td>
		<td style="text-align:center">
			180.6 x 101.8 x 41mm<br>
			<i>Enclosure Only</i>
		</td>
		<td style="text-align:center">
			180.6 x 101.8 x 41mm<br>
			<i>Enclosure Only</i>
		</td>
		<td style="text-align:center">
			180.6 x 101.8 x 41mm<br>
			<i>Enclosure Only</i>
		</td>
	</tr>
	<tr>
		<td style="vertical-align:middle;">Weight</td>
		<td style="text-align:center; vertical-align:middle;">N/A</td>
		<td style="text-align:center; vertical-align:middle;">58g  ± 1g</td>
		<td style="text-align:center; vertical-align:middle;">22.6g</td>
		<td style="text-align:center">
			415.15g<br>
			<i>Enclosure Only</i>
		</td>
		<td style="text-align:center">
			415.15g<br>
			<i>Enclosure Only</i>
		</td>
		<td style="text-align:center">
			415.15g<br>
			<i>Enclosure Only</i>
		</td>
	</tr>
	
	</table>
	
	</div>

	!!! note "mosaic-go Evaluation Kit"
		The reset pin is exposed on 4-pin JST connector and the log pin is connected to the latch pin of the SD card slot.

## :fontawesome-solid-list-check: Required Materials
The GNSSDO / GNSSDO+ comes with everything you need to get up and running.

**Kit Contents**

---

<div class="grid" markdown>

<div markdown>

<figure markdown>

Kit contents (https://cdn.sparkfun.com/assets/parts/2/7/2/0/7/26289-GNSS-Disciplined-Oscillator-Kit-Feature.jpg "Click to enlarge")
<figcaption markdown>
Everything that is included in the GNSSDO kit.
</figcaption>
</figure>

</div>

<div markdown>

<div class="annotate" markdown>

- [Quick Start Guide](./assets/quick_start_guide-v10.pdf)
- Cased GNSS Receiver
	- [Aluminum Enclosure](https://www.sparkfun.com/metal-enclosure-custom-aluminum-extrusion-6in-x-4in-pcb.html) (1)
	- [10-Way Terminal Blocks](https://www.sparkfun.com/10-way-terminal-socket.html)
	- [Qwiic 1.3" OLED Display](https://www.sparkfun.com/sparkfun-qwiic-oled-1-3in-128x64.html)
- [L1/L2/L5 GNSS Surveying Antenna](https://www.sparkfun.com/gnss-multi-band-l1-l2-l5-surveying-antenna-tnc-spk6618h.html)
- [Reinforced RG58 TNC-SMA Cable (10m)](https://www.sparkfun.com/reinforced-interface-cable-sma-male-to-tnc-male-10m.html)
- [32GB microSD Card (Class 10)](https://www.sparkfun.com/microsd-card-32gb-class-10.html)
- [USB A and C Power Delivery (PD) Wall Adapter - 65W](https://www.sparkfun.com/usb-a-and-c-power-delivery-pd-wall-adapter-65w.html)
- [USB-C to USB-C Cable (Flexible Silicone, 3m)](https://www.sparkfun.com/usb-c-to-usb-c-silicone-power-charging-cable-3m.html)
- [Ethernet Cable (CAT-6, 1m)](https://www.sparkfun.com/cat-6-cable-3ft.html)
- [SMA to BNC Cable (RG316, 1m)](https://www.sparkfun.com/sma-to-bnc-male-cable-rg316-1m.html)
- [Silicone Bumpers - 5x11mm (4 Pack)](https://www.sparkfun.com/silicone-bumpers-5x11mm-4-pack.html)

</div>
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

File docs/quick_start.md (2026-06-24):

---
icon: material/run-fast
hide: toc
---

!!! failure "Deprecated Documentation"
	As of Apr 24, 2026 this guide has been retired. Users can find our latest documentation at: [docs.sparkpnt.com/SXT](https://docs.sparkpnt.com/SXT)

# Quick Start Guide

!!! abstract "Directions"

	This *quick start* guide is intended to help users get started with the SparkPNT GNSSDO / GNSSDO+, without having to review the technical details of this product. It includes the minimum instructions to initially set up the GNSSDO(+), depending on the primary interface that users would like to utilize:

	<div class="grid" markdown>

	<div markdown>

	[**Ethernet**](./quick_start.md/#ethernet)

	: Instructions to connect the GNSSDO(+) to a local network with an ethernet cable. This will provide the mosaic-T module with network connectivity for its internal web server; where, users can access its web pages with any computer or mobile device to configure the mosaic-T GNSS module.

	[**mosaic-T USB-C**](./quick_start.md/#mosaic-t-usb-c)

	: For users that just want to interface and configure the mosaic-T GNSS module, inside the GNSSDO(+), directly through a computer.

	[**ESP32 USB-C**](./quick_start.md/#esp32-usb-c)

	: For users that want to interface with the firmware running on the GNSSDO(+), using a terminal emulator on a computer.

	</div>

	<div markdown>

	<figure markdown>
	Clicking on tabs Gif
	<figcaption markdown>
	Click on the tab of your preferred interface (below), to get started with the GNSSDO(+).
	</figcaption>
	</figure>

	</div>

	</div>

	??? info ":material-printer: Quick Start Pamphlet"
		For users who have lost the pamphlet in their kit, please check out the links below to download the `*.pdf` file:

		<figure markdown>
		Scan QR Code to Download PDF File
		<figcaption markdown>
		[:octicons-download-16:{ .heart } Download the Quick Start Guide :fontawesome-solid-file-pdf:](./assets/quick_start_guide-v10.pdf "Click to Download"){ .md-button .md-button--primary }
		</figcaption>
		</figure>

		<article style="text-align: center;" markdown>
		*Click on the button (above) or scan the QR code with a mobile device, to download the `*.pdf` file of the quick start pamphlet.*
		</article>

=== "<H2>:material-ethernet: Ethernet</H2>"

	The simplest way to get your GNSSDO(+) up and running is to connect it to your Ethernet network or an Ethernet port on your broadband router:

	<figure markdown>
	Ethernet Connections
	<figcaption markdown>
	[Ethernet Connections (PNG)](./assets/img/hookup_guide/quickstart_setup-ethernet.jpg) for the GNSSDO(+).
	</figcaption>
	</figure>
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

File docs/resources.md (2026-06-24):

---
icon: material/book-open-page-variant
---

!!! failure "Deprecated Documentation"
	As of Apr 24, 2026 this guide has been retired. Users can find our latest documentation at: [docs.sparkpnt.com/SXT](https://docs.sparkpnt.com/SXT)

## Product Resources

- :sfe: [Product Page](https://https://www.sparkpnt.com/products/sxt-gnssdo)
- [Quick Start Guide](./assets/quick_start_guide-v10.pdf)
- :material-folder-cog: Design Files:
	- :fontawesome-solid-file-pdf: [GNSSDO Schematic](./assets/board_files/schematic.pdf)
	- :fontawesome-solid-file-pdf: [GNSSDO+ Schematic](./assets/board_files/SparkPNT_GNSSDO_Plus_schematic.pdf)
	- :fontawesome-solid-file-image: [Board Dimensions](./assets/board_files/dimensions.png)
	- :fontawesome-solid-file-pdf: [Enclosure Dimensions](./assets/board_files/dimensions-enclosure.pdf)
	- :fontawesome-solid-file-code: [ESP32 Firmware](https://github.com/sparkfun/SparkFun_GNSSDO/tree/main/Firmware/GNSSDO_Firmware)
- Datasheets:
	- :fontawesome-solid-file-pdf: [mosaic-T Datasheet](./assets/component_documentation/mosaic_hardware_manual_v1.11.0.pdf)
	- :fontawesome-solid-file-pdf: [SiT5358 Datasheet](./assets/component_documentation/SiT5358-datasheet.pdf)
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

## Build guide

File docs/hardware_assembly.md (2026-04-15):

---
icon: material/tools
---

!!! warning
	When assembling the GNSSDO(+), users should attach any power connections last. While there shouldn't be any issues with hot-swapping peripherals, it is common practice to power electronics as the last step of the assembly process *(and the power should be disconnected before removing components)*.

??? info "What is in the Box?"
	The SparkPNT GNSSDO(+) comes packaged as a complete kit, with all the accessories you'd need to set it up.

	<figure markdown>
	Kit contents (https://cdn.sparkfun.com/assets/parts/2/7/2/0/7/26289-GNSS-Disciplined-Oscillator-Kit-Feature.jpg "Click to enlarge")
	<figcaption markdown>
	Everything that is included in the SparkPNT GNSSDO(+) kit.
	</figcaption>
	</figure>

	Inside the kit, users will find the SparkPNT GNSSDO(+), [GNSS antenna](https://www.sparkfun.com/gnss-multi-band-l1-l2-l5-surveying-antenna-tnc-spk6618h.html), [USB-C cable](https://www.sparkfun.com/usb-c-to-usb-c-silicone-power-charging-cable-3m.html), [CAT-6 Ethernet cable](https://www.sparkfun.com/cat-6-cable-3ft.html), and another box containing additional accessories. Inside the accessory box, users will find the [SMA to TNC cable](https://www.sparkfun.com/reinforced-interface-cable-sma-male-to-tnc-male-10m.html), [SMA to BNC cable](https://www.sparkfun.com/sma-to-bnc-male-cable-rg316-1m.html), [USB PD wall adapter](https://www.sparkfun.com/usb-a-and-c-power-delivery-pd-wall-adapter-65w.html), a pack of [silicone bumpers](https://www.sparkfun.com/silicone-bumpers-5x11mm-4-pack.html), and a [32GB SD card](https://www.sparkfun.com/microsd-card-32gb-class-10.html).

## USB-C Ports
The USB ports are utilized to configure the mosaic-T module and ESP32 firmware settings. Additionally, the USB ports can also be used as a power source for the GNSSDO(+).

<div class="grid" markdown>

<div markdown>

<figure markdown>
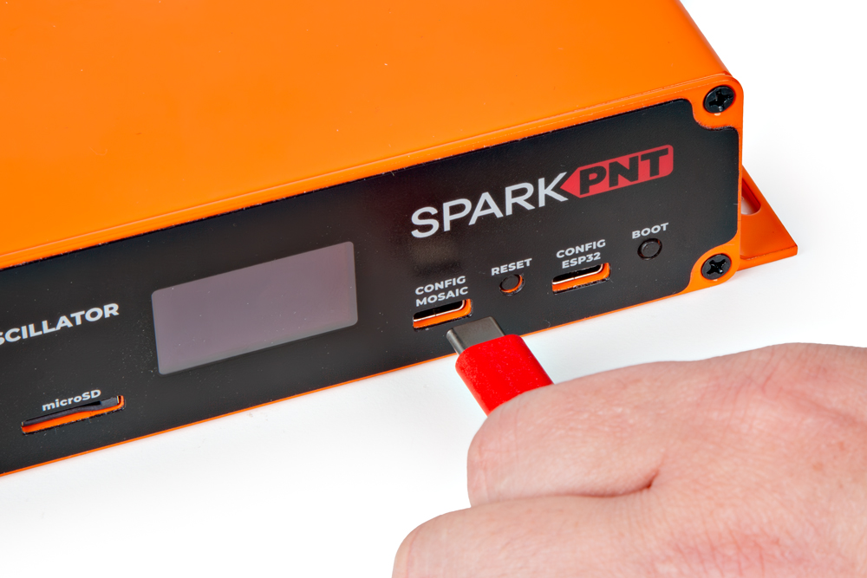
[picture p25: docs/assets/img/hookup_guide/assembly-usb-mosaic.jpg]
mosaic-T USB connection

<figcaption markdown>The GNSSDO(+) with USB-C cable being attached.</figcaption>
</figure>

The USB port to the mosaic-T can be used to configure the module through an IP port, for serial communication to stream the GNSS data, and access the SD card as a mass storage device. To connect to the mosaic-T, users only need to plug a USB-C cable into the `CONFIG MOSAIC` USB port and their computer.

</div>

<div markdown>

<figure markdown>
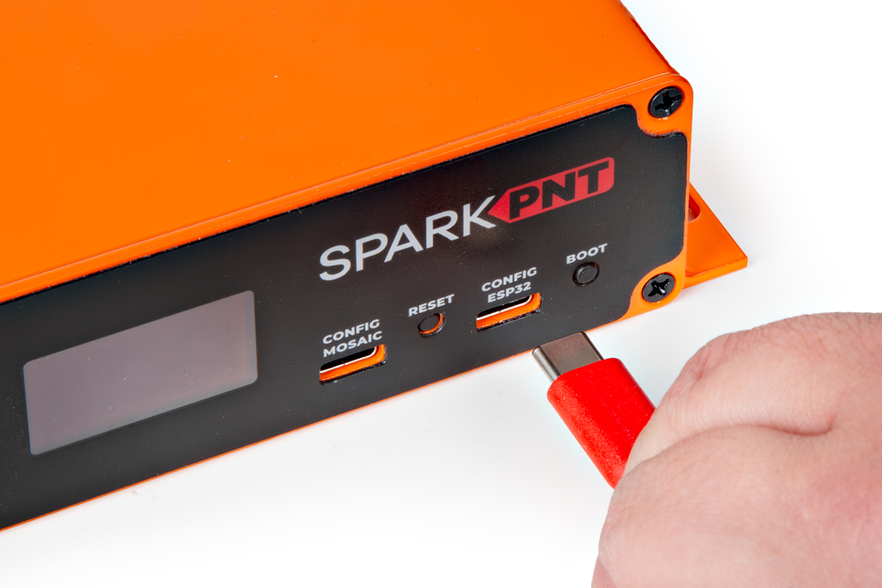
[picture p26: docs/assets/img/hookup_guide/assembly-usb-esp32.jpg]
ESP32 USB connection

<figcaption markdown>The GNSSDO(+) with USB-C cable being attached.</figcaption>
</figure>

With the default firmware, the USB port for the ESP32 is used for serial communication to tune the parameters for the TCXO oscillator and the Pulse-Per-Second output. To configure the settings, users only need to plug a USB-C cable into the `CONFIG ESP32` USB port and their computer, and then open a terminal emulator at 115200 baud.

</div>

</div>

!!! tip "Software Requirements"
	Depending on their computer's operating system, users may need to install USB drivers to interface with the mosaic-T and/or the ESP32. Users may also need to install a terminal emulator for serial communication with the mosaic-T and the ESP32.

## GNSS Antenna
In order to receive [GNSS](https://en.wikipedia.org/wiki/Satellite_navigation "Global Navigation Satellite System") signals, users will need a compatible antenna. With the parts included in this kit, connect the L1/L2/L5 (tri-band) GNSS antenna to the GNSSDO(+) using the TNC-to-SMA cable.

<div class="grid" markdown>

<div markdown>

<figure markdown>
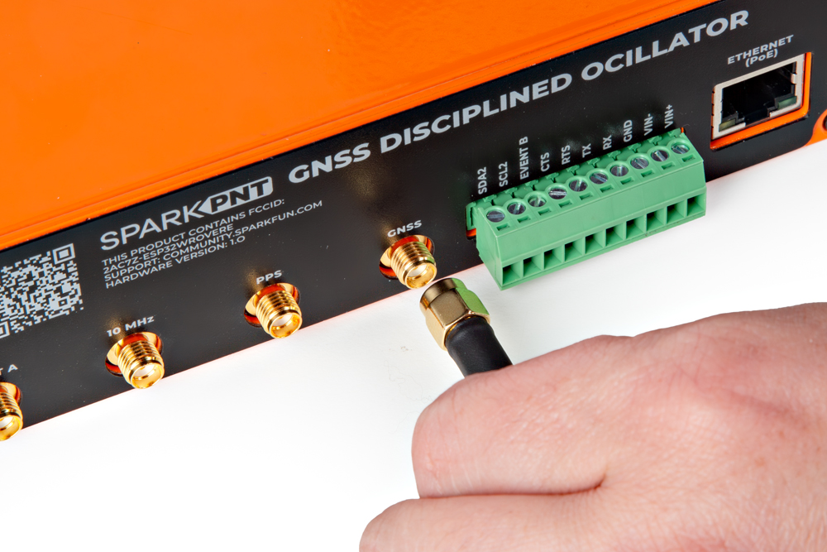
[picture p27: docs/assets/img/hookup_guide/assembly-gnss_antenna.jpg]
GNSS antenna connected to the GNSSDO(+)

<figcaption markdown>Attaching a TNC-SMA cable to the `GNSS` SMA connector on the GNSSDO(+).</figcaption>
</figure>

</div>

<div markdown>

<figure markdown>
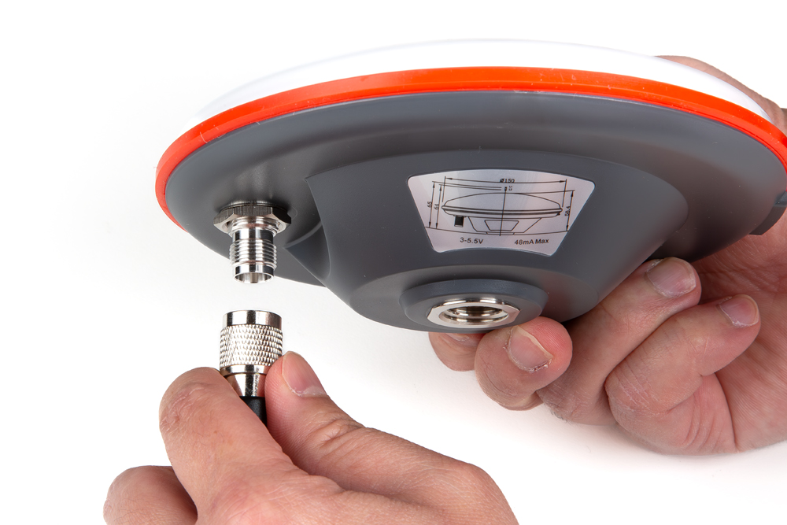
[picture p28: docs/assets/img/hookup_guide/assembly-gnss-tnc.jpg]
GNSS antenna connected to the cable

<figcaption markdown>Attaching a tri-band GNSS antenna to the TNC-SMA cable.</figcaption>
</figure>

</div>

</div>

??? tip "Mounting Location"
	Users should mount their GNSS antenna outside, where it will have a clear, unobstructed view of the sky. Avoid areas with nearby buildings, EMF structures (i.e. radio towers or power lines), and vegetation (i.e. trees). These objects can increase errors due to signal muti-path, interference, and elevated noise plane.

	<figure markdown>
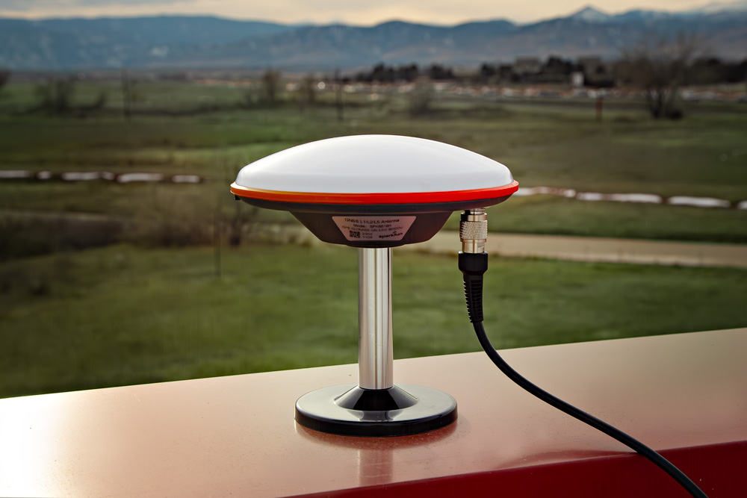
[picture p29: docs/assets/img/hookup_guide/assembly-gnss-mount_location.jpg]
GNSS antenna connected to the GNSSDO(+)
	
	<figcaption markdown>The tri-band GPS antenna, mounted outside with an unobstructed view of the sky.</figcaption>
	</figure>

??? tip "Connector Polarity"
	When selecting antennas and/or cables for the GNSSDO(+), double-check the polarity of the connection.

## Ethernet Jack
There is a single ethernet jack on the GNSSDO(+), which can be used to provide network access to the mosaic-T module. It supports [power over ethernet (PoE)](https://en.wikipedia.org/wiki/Power_over_Ethernet "PoE") to power the device. To provide network access, users should connect the GNSSDO(+) from the `ETHERNET (PoE)` jack to their local network with the (CAT-6) ethernet cable provided in the kit.

- To power the device, a PoE network switch or PoE injector should be installed in between the network connection to the GNSSDO(+).

<figure markdown>
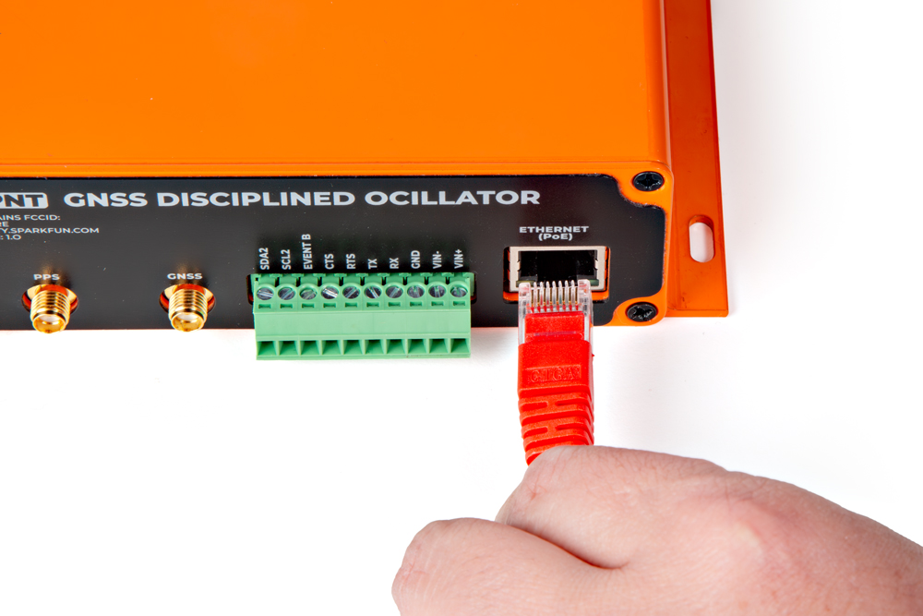
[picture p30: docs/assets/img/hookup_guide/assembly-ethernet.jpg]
mosaic-T PoE connection

<figcaption markdown>The GNSSDO(+) with ethernet cable being attached to the `ETHERNET (PoE)` jack.</figcaption>
</figure>

??? tip "Configuration: mosaic-T Settings"
	Users can configure the mosaic-T module through the network connection.

	??? info "No IP address?"
		Check the Ethernet interface is enabled. It may be disabled. Connect via the CONFIG MOSAIC USB-C port and open 192.168.3.1 on a web browser. Check the **Communication \ Ethernet** sub-page.

		<figure markdown>
		mosaic-T web page
		<figcaption markdown>
		[mosaic-T web page (PNG)](./assets/img/hookup_guide/Ethernet-disabled.png) with Ethernet disabled.
		</figcaption>
		</figure>

		<figure markdown>
		mosaic-T web page
		<figcaption markdown>
		[mosaic-T web page (PNG)](./assets/img/hookup_guide/Ethernet-enabled.png) with Ethernet enabled.
		</figcaption>
		</figure>

		By default, the mosaic-T Ethernet port is configured for Dynamic Host Configuration Protocol (DHCP). It expects the router / Ethernet switch to provide it with an IP address. If the IP address is all zeros (0.0.0.0), check that your router has DHCP enabled. Most do.

		If you need a static IP address, you can configure this through the mosaic-T's **Communication \ Ethernet** sub-page.

		Subnet 3 is reserved for the mosaic-T's USB-C connection (Ethernet-over-USB). If your router / switch is allocating addresses using subnet 3 (192.168.3.***), please change its settings so it uses a different subnet.

## 10MHz Signal
For timing applications, we have broken out the TCXO 10MHz signal to an SMA connector. In our kit, users will find an [SMA to BNC adapter cable](https://www.sparkfun.com/sma-to-bnc-male-cable-rg316-1m.html) that they can use to hookup this signal to their equipment. If necessary, users can add an [SMA extension cable](https://www.sparkfun.com/interface-cable-sma-male-to-sma-female-cable-1m-rg174.html) to reach their equipment.

<figure markdown>
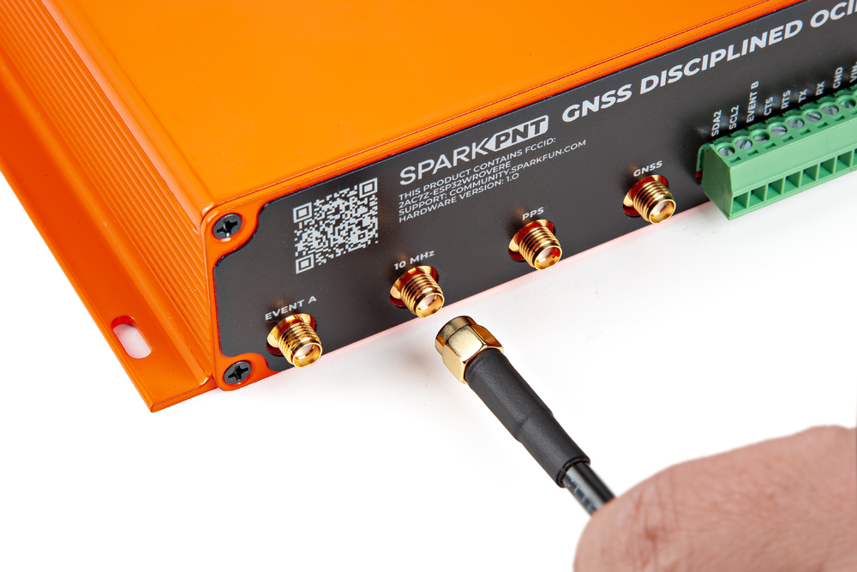
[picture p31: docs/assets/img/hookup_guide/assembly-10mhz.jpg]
Connecting cable to 10MHz signal of the GNSSDO(+)

<figcaption markdown>Attaching a cable to the `10MHz` SMA connector on the GNSSDO(+).</figcaption>
</figure>

## SD Card Slot
A &micro;SD card slot is available for users to log and store data, locally on the board. Users will need to insert a compatible SD card and configure the mosaic-T module for data logging.

<figure markdown>
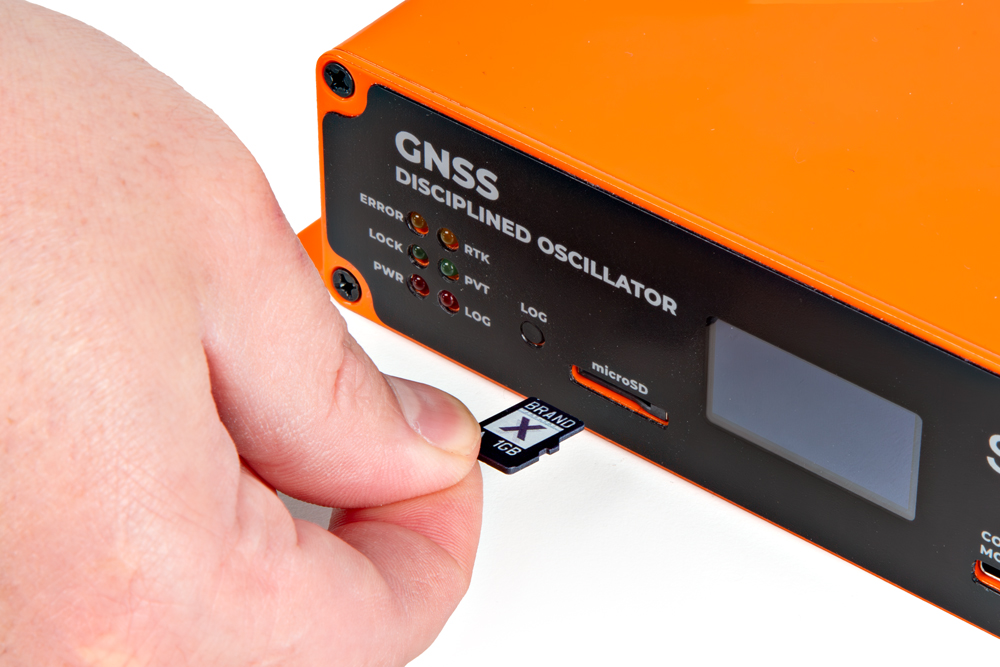
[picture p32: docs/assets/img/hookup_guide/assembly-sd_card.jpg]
GNSSDO(+) SD card slot

<figcaption markdown>Inserting an SD card into the GNSSDO(+).</figcaption>
</figure>

!!! info "SD Card Compatibility"
	The mosaic-T supports &micro;SD cards with a **FAT32** file system *(i.e. only cards **up to 32GB** in size)*.

??? warning "Initial Configuration"
	Before logging can take place, it is necessary to define a "logging stream" using the **Logging** page or **RxTools**. Streams can contain NMEA or SBF (Septentrio Binary Format) data; SBF can contain RTCM and/or RINEX.

	<figure markdown>
	Logging stream configuration
	<figcaption markdown>microSD logging stream configuration.</figcaption>
	</figure>

	!!! tip "Instructional Video"
		:material-youtube: [How to log data to the SD card of the Septentrio mosaic receiver module](https://youtu.be/Y9tvOebnoxk)

??? tip "Button Operation"
	There are multiple ways to configure and enable data logging to an SD card. However, the simplest method is with the ++"LOG"++ button. Once the stream is defined,

	- Pressing the ++"LOG"++ button *(< 5s)* toggles data logging to the SD card on and off.
	- Holding the ++"LOG"++ button for more than 5 seconds *(> 5s)* and then releasing it, will force the board to:
		- Unmount the SD card if it was mounted
		- Mount the SD card if it was unmounted

	For more information, please reference the [SD Card Slot](../hardware_overview/#sd-card-slot) section.

## IO Terminals
Users can easily attach accessories to the GNSSDO(+) by wiring them into the terminal blocks on the back of the enclosure.

<figure markdown>
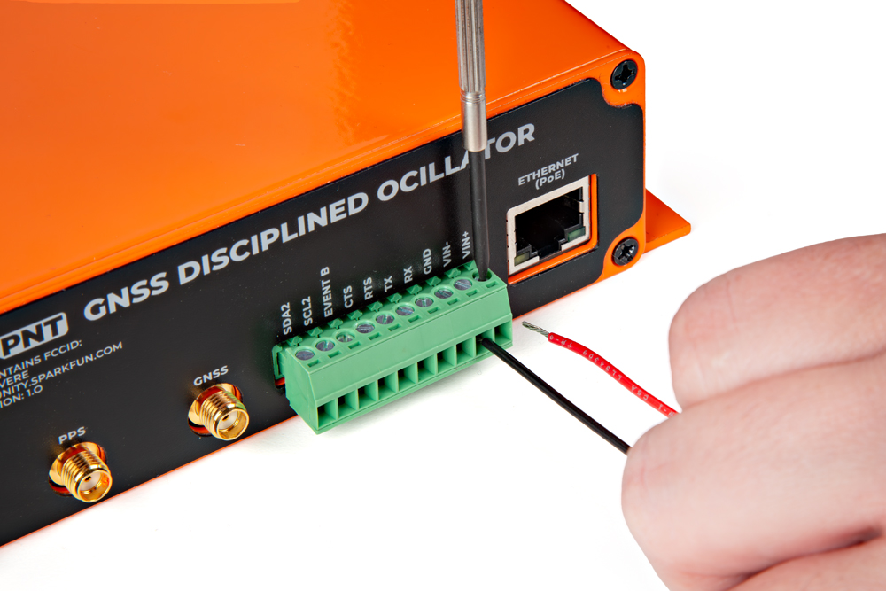
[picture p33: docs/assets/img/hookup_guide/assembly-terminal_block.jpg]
Terminal Block

<figcaption markdown>Connecting a wire to the terminal block.</figcaption>
</figure>

??? tip "Multiple Connections"
	For multiple connections or wiring harnesses, users can disconnect the terminal block from its socket on the GNSSDO(+).

	<figure markdown>
	Disassembled Terminal Block (https://cdn.sparkfun.com/assets/parts/2/2/5/2/5/22461-_PRT_10-Way_Terminal___Socket-_01.jpg "Click to enlarge")
	<figcaption markdown>Components of the terminal block.</figcaption>
	</figure>

	Users can wiggle or use a soft/rigid object to carefully pry the terminal block off from its connector. In the picture below, a plastic name tag (~1.5mm thick) is used to carefully pry the terminal block up. We have also found the edge of a [PCB ruler](https://www.sparkfun.com/products/15295) works great too.

	<figure markdown>
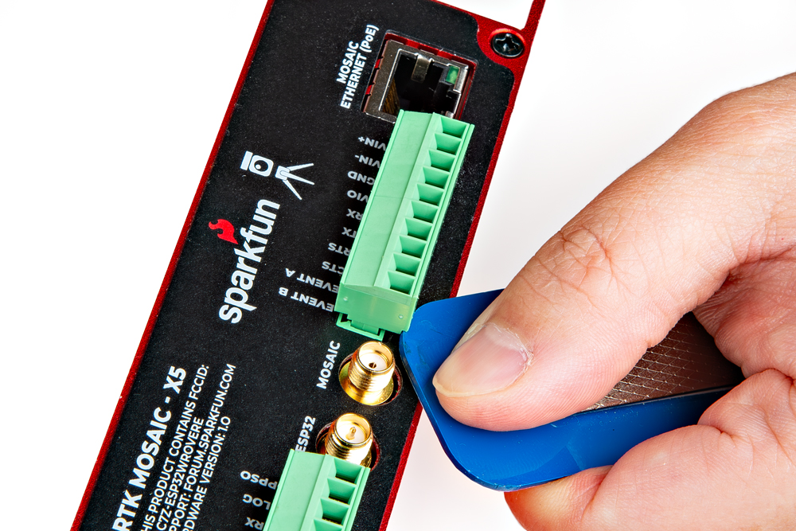
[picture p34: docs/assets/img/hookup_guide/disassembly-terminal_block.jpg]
Prying the Terminal Block
	
	<figcaption markdown>Using a soft/rigid object to carefully pry the terminal block free from its socket.</figcaption>
	</figure>

	Once wired up, users can simply push the terminal block back into its socket.

	<div class="grid" markdown>

	<div markdown>

	<figure markdown>
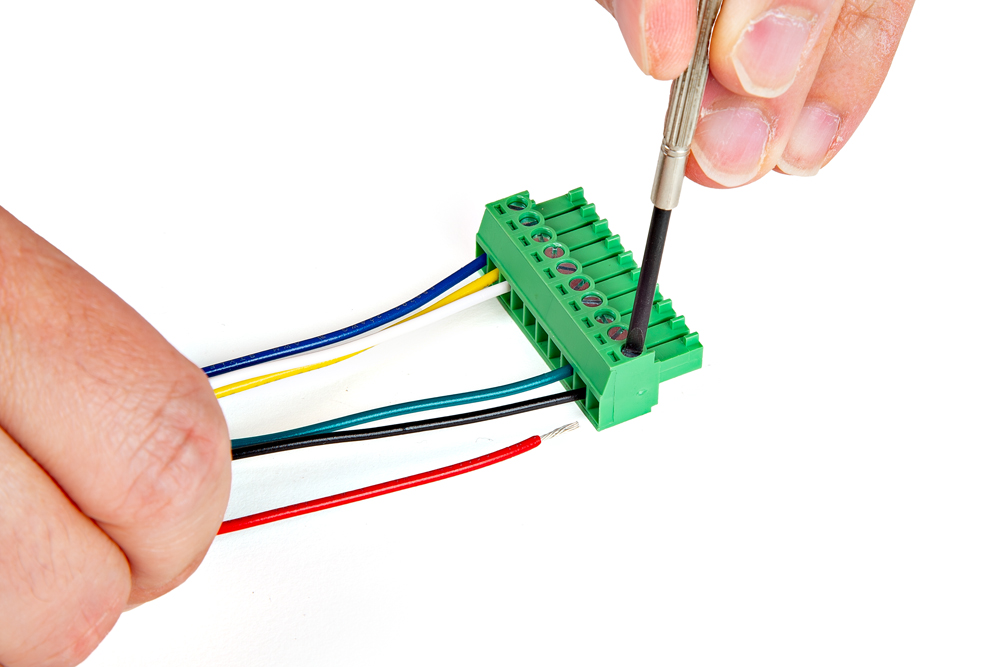
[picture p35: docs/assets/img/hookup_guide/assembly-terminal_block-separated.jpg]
Terminal Block
	
	<figcaption markdown>Connecting a wire to the terminal block.</figcaption>
	</figure>

	</div>

	<div markdown>

	<figure markdown>
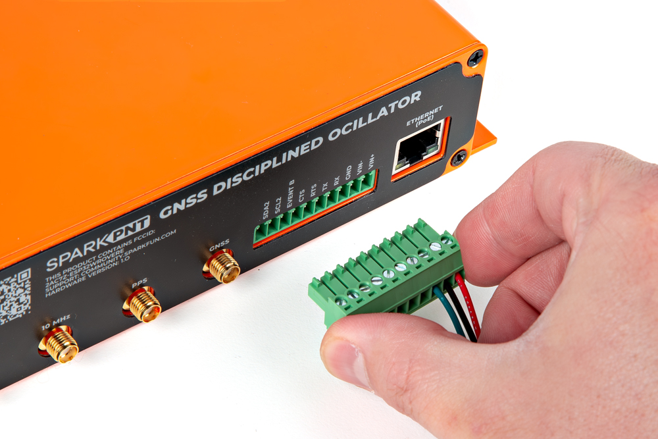
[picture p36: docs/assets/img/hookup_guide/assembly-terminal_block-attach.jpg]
Terminal Block
	
	<figcaption markdown>Attaching the terminal block to its socket on the GNSSDO(+).</figcaption>
	</figure>

	</div>

	</div>

	!!! warning
		To avoid shorts or damaging the GNSSDO(+), verify the wiring with the labels on the back of the enclosure.

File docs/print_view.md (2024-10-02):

---
hide:
  - navigation
  - toc
icon: material/printer
---

--8<-- "./docs/introduction.md:5"

# Quick Start Guide
--8<-- "./docs/quick_start.md:6"

# Hardware Overview
--8<-- "./docs/hardware_overview.md:5"

# Hardware Assembly
--8<-- "./docs/hardware_assembly.md:5"

# Software Overview
--8<-- "./docs/software_overview.md:5"

# TCXO Oscillator
--8<-- "./docs/oscillator.md:5"

# Enable the L5 Band
--8<-- "./docs/L5.md:5"

# Resources
--8<-- "./docs/resources.md:5"

# Troubleshooting Tips
--8<-- "./docs/troubleshooting_tips.md:5"

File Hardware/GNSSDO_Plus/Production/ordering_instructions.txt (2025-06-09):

Ordering Instructions:
Panel dimensions: 165.60 x 125.46 mm.
Controlled Impedance: JLC7628
Material: TG135
Solder Mask: Red
Silkscreen: White
Layers: 4
Finish: ENIG
Thickness: 1.6mm
Copper Weight: 1oz
Minimum track width: 0.18mm (7.00mil)
Minimum via drill: 0.30mm (11.81mil)
No Clean Process

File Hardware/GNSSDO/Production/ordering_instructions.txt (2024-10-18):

Ordering Instructions:
Panel dimensions: 165.60 x 125.46 mm.
Controlled Impedance: JLC7628
Material: TG155
Solder Mask: Red
Silkscreen: White (Default)
Layers: 4
Finish: ENIG
Thickness: 1.6mm
Copper Weight: 1oz
Minimum track width: 0.18mm (7.00mil)
Minimum via drill: 0.30mm (11.81mil)
No Clean Process

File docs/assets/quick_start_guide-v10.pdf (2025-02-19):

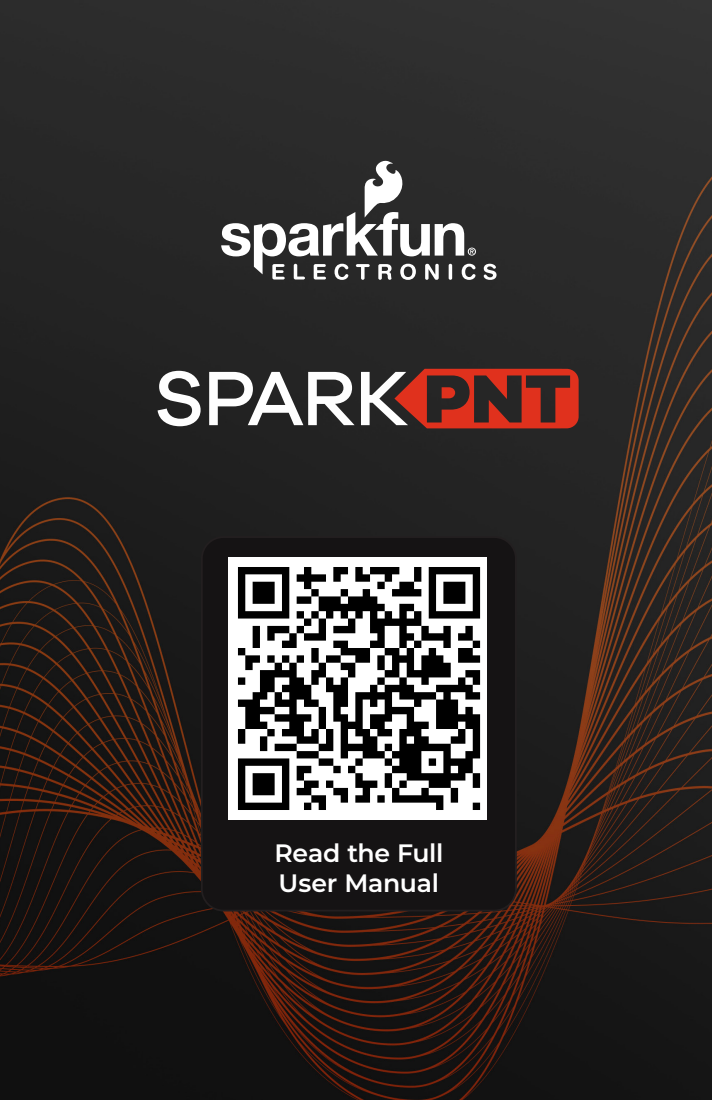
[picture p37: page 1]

Read the Full
User Manual

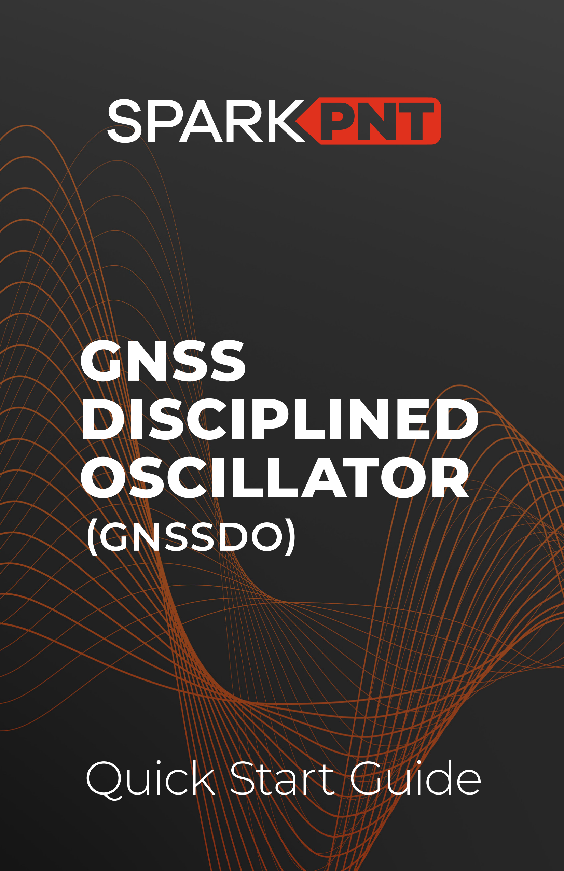
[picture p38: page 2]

# GNSS DISCIPLINED OSCILLATOR

# Quick Start Guide

# (GNSSDO)

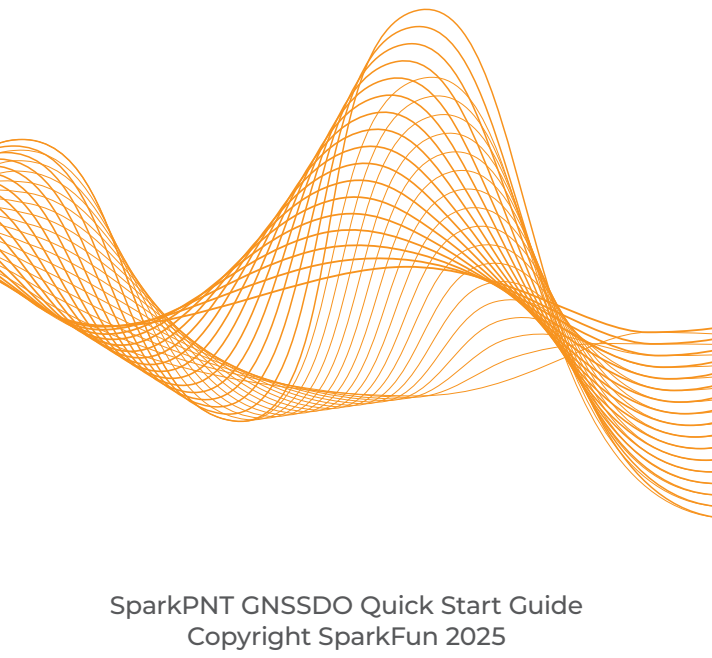
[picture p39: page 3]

SparkPNT GNSSDO Quick Start Guide
Copyright SparkFun 2025

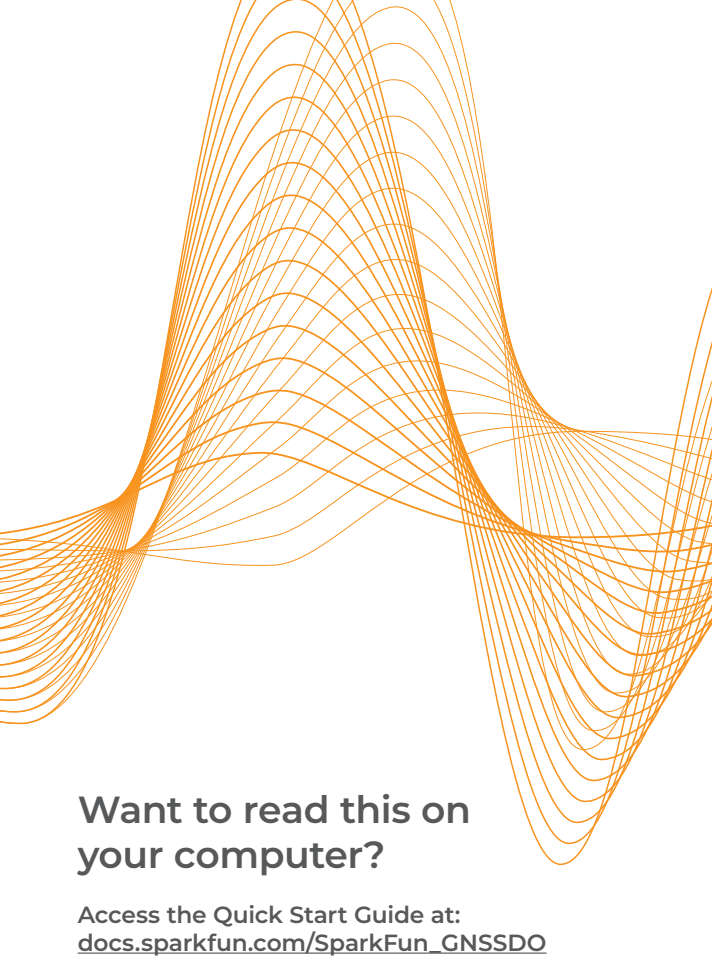
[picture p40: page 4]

Want to read this on
your computer?

Access the Quick Start Guide at:
docs.sparkfun.com/SparkFun_GNSSDO

## Connecting Using Ethernet |

## Connecting Using USB-C |

## Configuring the Firmware |

## Help & Troubleshooting |

1
3
5
9

Ethernet Cable
CAT-6, 1m 1m
(CAB-08915)

SparkPNT GNSSDO
(GPS-26289)

USB-C Power
Charging Cable 3m
(CAB-24060)

L1/L2/L5 GNSS
Surveying Antenna
(GPS-21801)

TNC-SMA Cable 10m
(CAB-21740)

Power Deliver Wall
Adapter, 65W
(TOL-24059)

SMA-BNC Cable,
RG316, 1m
(CAB-27480)

32GB microSD Card
Class 10
(COM-19041)

## WHERE SHOULD I BEGIN?

## WHAT’S INCLUDED?

Ethernet network
or Router

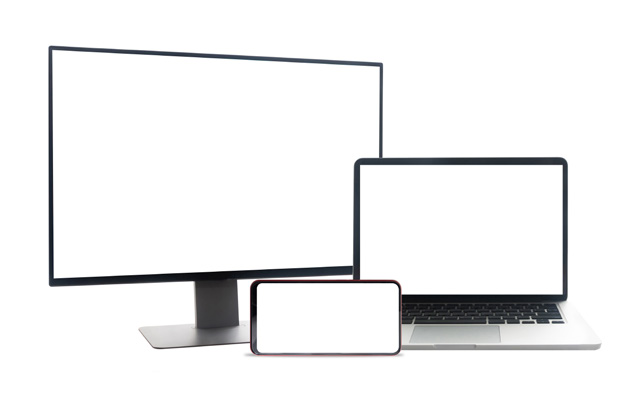
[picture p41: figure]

Computer, Phone
or Tablet

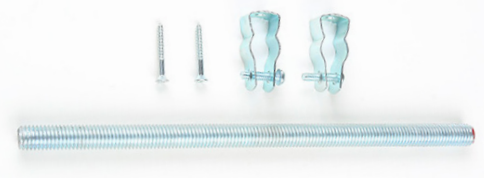
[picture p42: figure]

Antenna
Mounting Hardware
(KIT-22197)

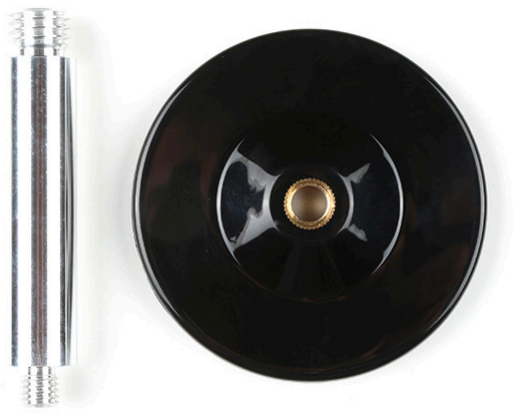
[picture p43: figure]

Antenna
Magnetic Mount
(PRT-21257)

## YOU WILL NEED

## YOU MAY ALSO NEED

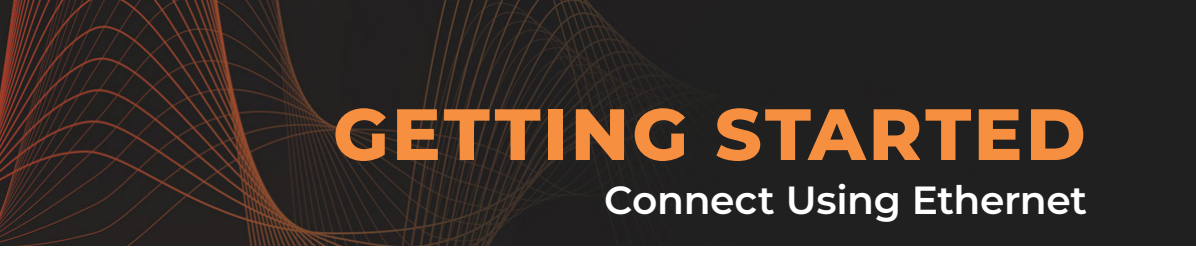
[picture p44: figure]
GETTING STARTED; Connect Using Ethernet
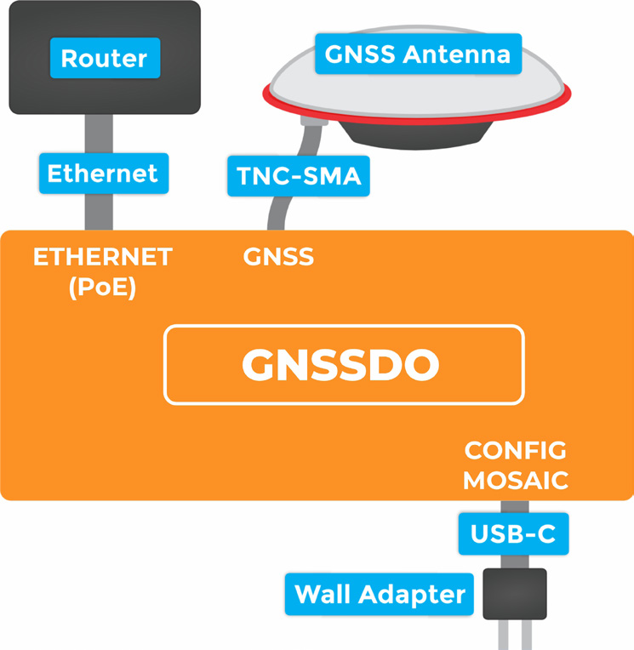
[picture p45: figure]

### 1 Want to read this on your computer?

The simplest way to get your GNSSDO up and running is to connect it to your
Ethernet network
or an Ethernet port
on your broadband
router:

### 1. Connect the GNSS

antenna. Inside
your GNSSDO kit,
you will find the L1/
L2/L5 GNSS “UFO”
antenna. It has a
TNC connection. Use
the supplied TNC-SMA cable to connect
the antenna to the GNSSDO
GNSS SMA connection. Make sure the antenna is securely mounted to a structure so that it cannot be moved and has a clear view of the sky

### 2. Connect the GNSSDO to your Ethernet network or

router. Use the supplied CAT-6 Ethernet cable to connect the ETHERNET (PoE) port to your network or an Ethernet port on your router. If your router provides Power-over-Ethernet (PoE), you’re all set! You should see the red power (PWR) LED light up and text start to appear on the OLED display. If your router does not provide PoE, move on to
step 3.

### 3. Provide power. You can power the GNSSDO using

the supplied USB power supply (5V power delivery wall charger). Plug the power supply into the wall. Use the supplied USB-C cable to connect the power supply to

## CONNECT USING ETHERNET

# GETTING STARTED

### Connect Using Ethernet

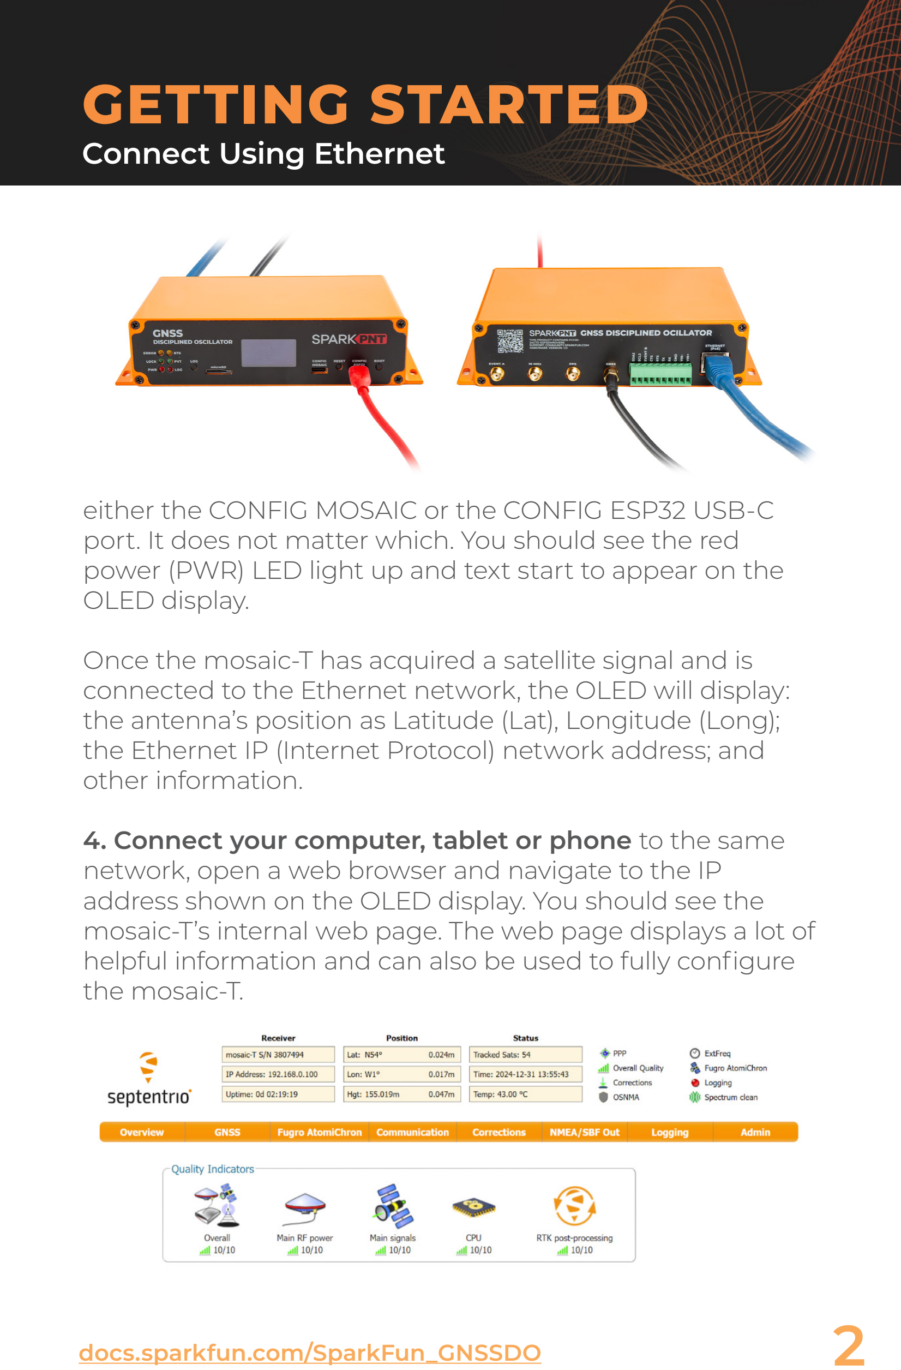
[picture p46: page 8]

docs.sparkfun.com/SparkFun_GNSSDO | 2

either the CONFIG MOSAIC or the CONFIG ESP32 USB-C port. It does not matter which. You should see the red power (PWR) LED light up and text start to appear on the OLED display.

Once the mosaic-T has acquired a satellite signal and is connected to the Ethernet network, the OLED will display: the antenna’s position as Latitude (Lat), Longitude (Long); the Ethernet IP (Internet Protocol) network address; and other information.

### 4. Connect your computer, tablet or phone to the same

network, open a web browser and navigate to the IP address shown on the OLED display. You should see the mosaic-T’s internal web page. The web page displays a lot of helpful information and can also be used to fully configure the mosaic-T.

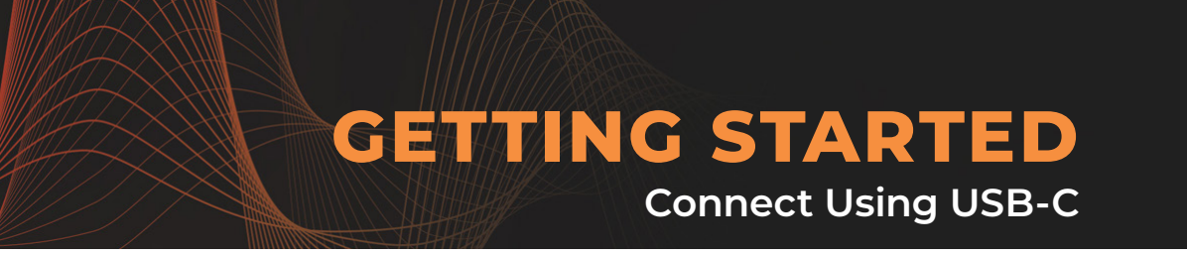
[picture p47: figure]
GETTING STARTED; Connect Using USB-C
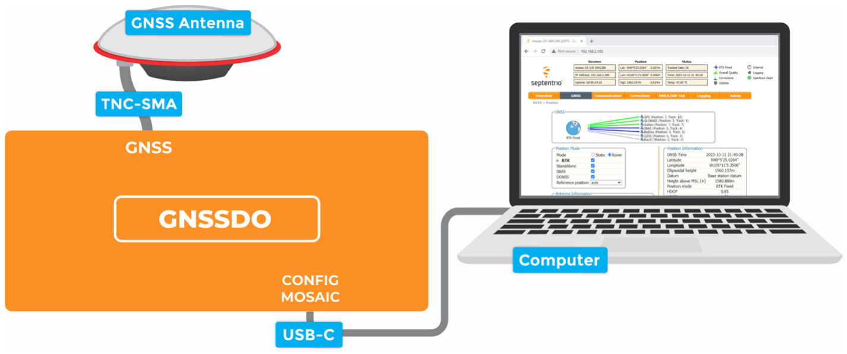
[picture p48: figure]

### 3 Want to read this on your computer?

The mosaic-T has a built-in high-speed USB port which supports Ethernet-over-USB. To take advantage of this interface, you first need to install the Septentrio drivers.

1. Connect the GNSS antenna. Inside your GNSSDO kit, you will find the L1/L2/L5 GNSS “UFO” antenna. It has a TNC connection. Use the supplied TNC-SMA cable to connect the antenna to the GNSSDO GNSS SMA connection. Make sure the antenna is securely mounted to a structure so that it cannot be moved and has a clear view of the sky.

### 2. Download and install Septentrio RxTools. RxTools

includes the driver for the USB-C port plus several tools which you can use to control and configure the mosaic-T, forward data, log data, analyze the log files, convert the log files to other formats, and configure the module for use with other GIS software.

## CONNECT USING USB-C

# GETTING STARTED

### Connect Using USB-C

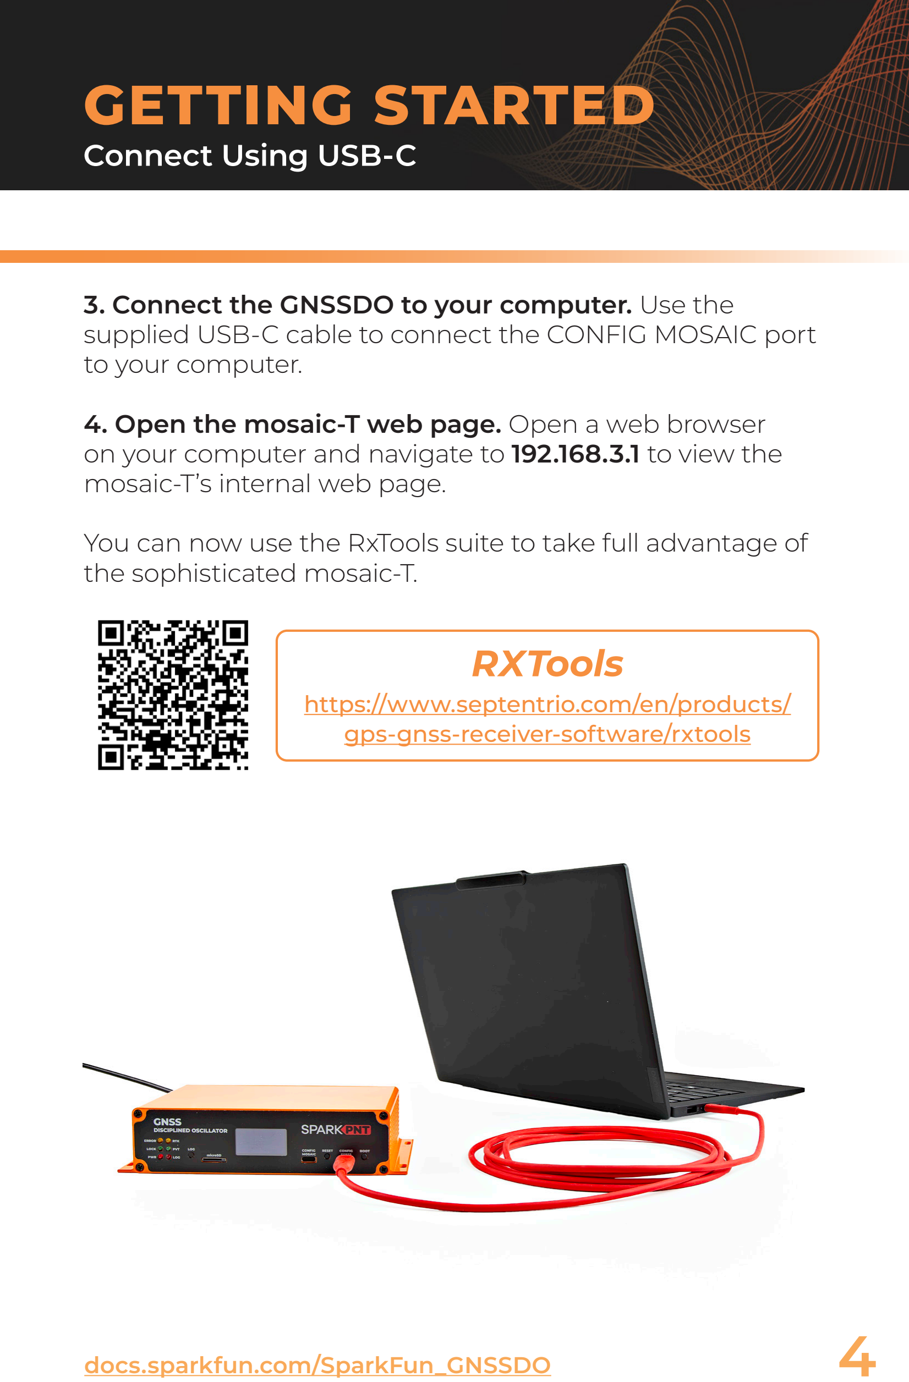
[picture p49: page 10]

docs.sparkfun.com/SparkFun_GNSSDO | 4

### 3. Connect the GNSSDO to your computer. Use the

supplied USB-C cable to connect the CONFIG MOSAIC port to your computer.

### 4. Open the mosaic-T web page. Open a web browser

on your computer and navigate to 192.168.3.1 to view the mosaic-T’s internal web page.

You can now use the RxTools suite to take full advantage of the sophisticated mosaic-T.

https://www.septentrio.com/en/products/gps-gnss-receiver-software/rxtools

## RXTools

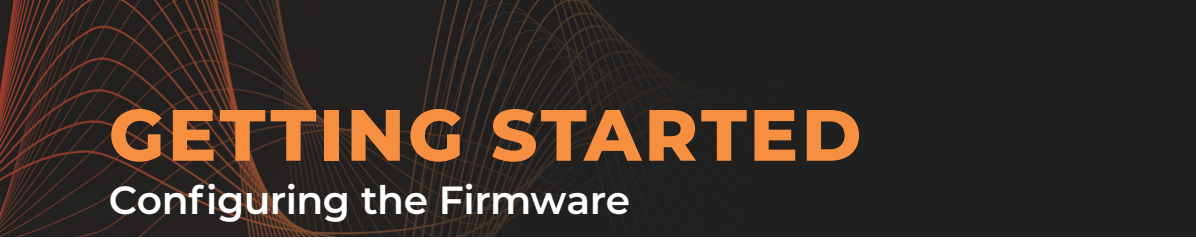
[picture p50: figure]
GETTING STARTED; Configuring the Firmware
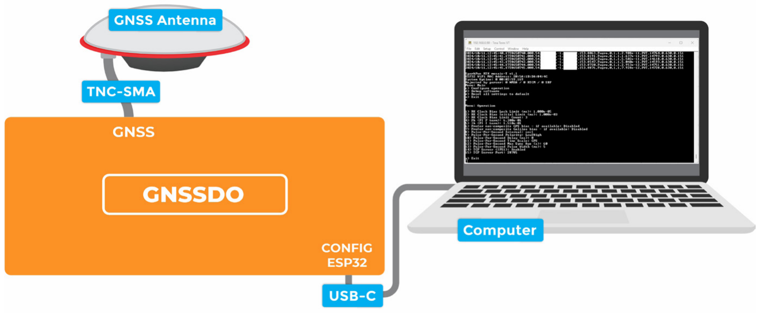
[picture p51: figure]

### 5 Want to read this on your computer?

The GNSSDO contains an ESP32-WROVER processor which is able to discipline the frequency of the internal SiT5358 temperature-controlled crystal oscillator. By linking the CONFIG ESP32 USB-C port to your computer, you can view and modify the settings of the ESP32 firmware using a terminal emulator.

1. Connect the GNSS antenna. Inside your GNSSDO kit, you will find the L1/L2/L5 GNSS “UFO” antenna. It has a TNC connection. Use the supplied TNC-SMA cable to connect the antenna to the GNSSDO GNSS SMA connection. Make sure the antenna is securely mounted to a structure so that it cannot be moved and has a clear view of the sky.

### 2. Connect to the CONFIG ESP32 USB port. To modify the

ESP32 firmware settings, you need to connect a computer to the CONFIG ESP32 USB-C port and use a Serial Terminal to change the settings. You may need to install a driver first, so that the CH340 serial interface chip is recognized.

## CONFIGURING THE FIRMWARE

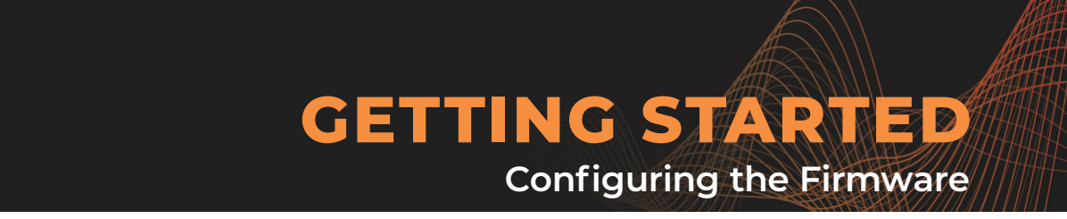
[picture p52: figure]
GETTING STARTED; Configuring the Firmware

docs.sparkfun.com/SparkFun_GNSSDO | 6

Please follow the QR codes below for more details:

https://learn.sparkfun.com/tutorials/how-to-install-ch340-drivers

## CH340 Drivers

https://learn.sparkfun.com/tutorials/terminal-basics/tera-term-windows

## Tera Term

https://learn.sparkfun.com/tutorials/terminal-basics

## Serial Terminal Basics

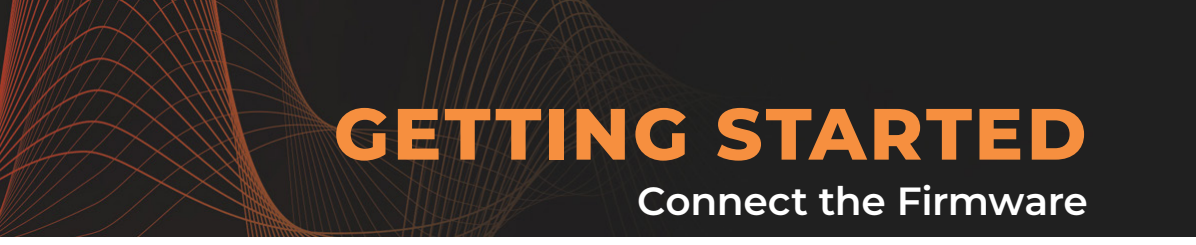
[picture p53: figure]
GETTING STARTED; Connect the Firmware
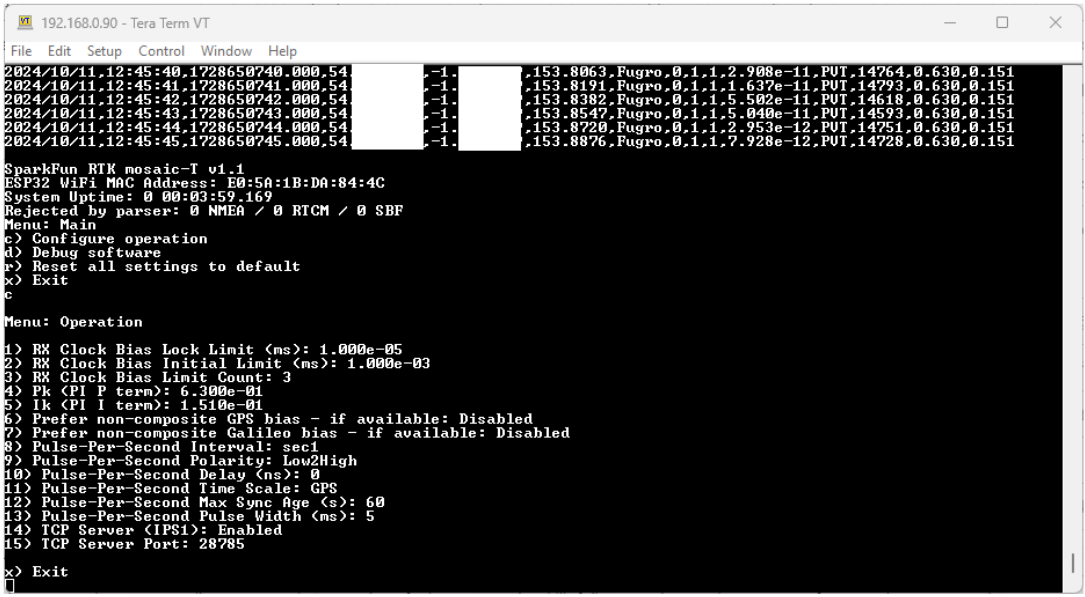
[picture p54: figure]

### 7 Want to read this on your computer?

The firmware settings are stored in flash (non-volatile) memory when you exit the menus. After changing them, exit the menus completely, then you can disconnect the computer and power the GNSS using the supplied wall charger.

### 3. Open a Serial Terminal. If you are using Windows, we still

recommend Tera Term serial terminal but there are plenty of alternatives. Please see our Serial Terminal Basics tutorial for more details. Open the connection to the CH340 using 115200 baud.

### 4. Use the Menus to modify the Settings. When you

have the Serial Terminal open, you should see diagnostic messages from the firmware scrolling up the screen. Hit any key on your computer keyboard to open the menu.

# GETTING STARTED

### Configuring the Firmware

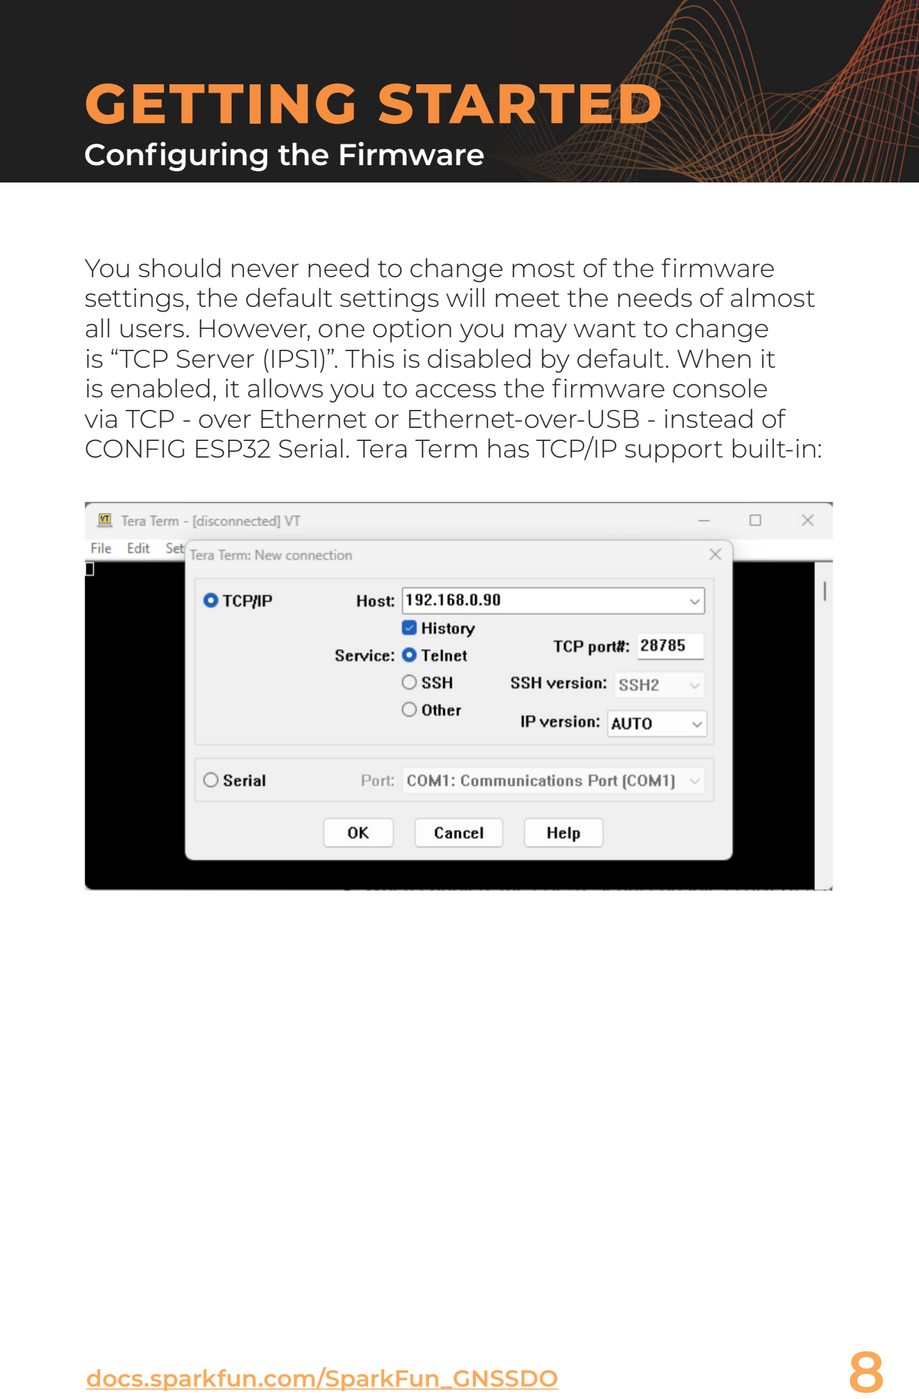
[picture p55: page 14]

docs.sparkfun.com/SparkFun_GNSSDO | 8

You should never need to change most of the firmware settings, the default settings will meet the needs of almost all users. However, one option you may want to change is “TCP Server (IPS1)”. This is disabled by default. When it is enabled, it allows you to access the firmware console via TCP - over Ethernet or Ethernet-over-USB - instead of CONFIG ESP32 Serial. Tera Term has TCP/IP support built-in:

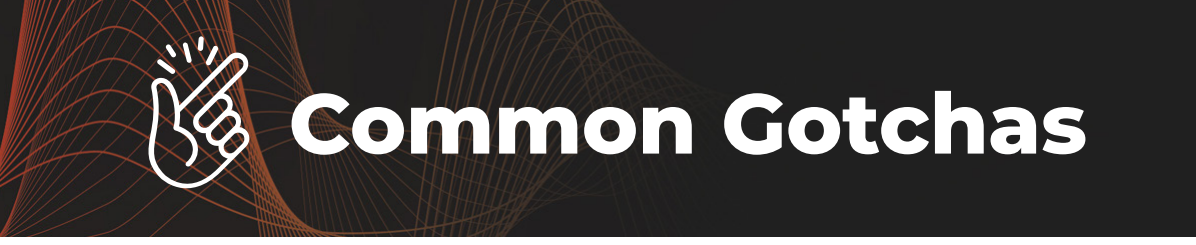
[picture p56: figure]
Common Gotchas

9

- High-precision GNSS only works with multiple-frequency antennas. This means that GPS antenna you got in the early 2000s with your TomTom is not going to work. Please use the SparkFun L1/L2/L5 antenna provided in the GNSSDO kit.
- High-precision GNSS works best with a clear view of the sky; it does not work indoors or near a window. GNSS performance is generally not affected by clouds or storms. Trees and buildings can degrade performance but usually only in very thick canopies or very near tall building walls. GNSS reception is very possible in dense urban centers with skyscrapers but high-precision RTK may be impossible.
- The location reported by the GNSS device is the location of the antenna element itself. Latitude and Longitude are fairly easy to obtain but if you’re capturing Altitude be sure to do additional reading on ARPs (Antenna Reference Points) and how to account for the antenna height above ground in your data collection software.

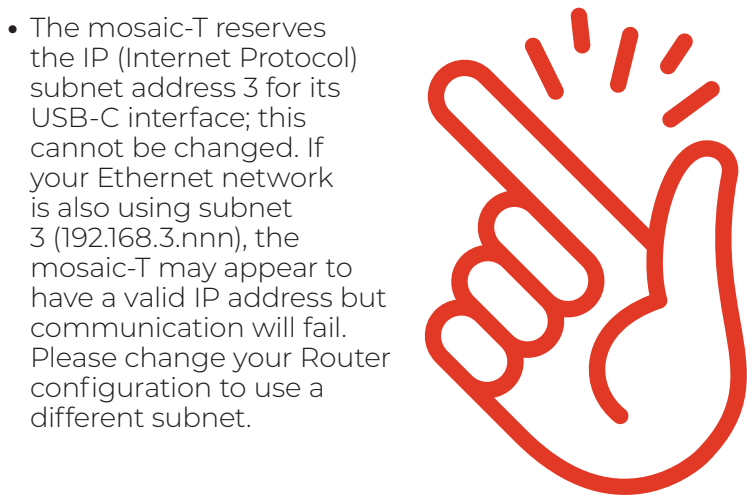
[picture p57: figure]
• The mosaic-T reserves the IP (Internet Protocol) subnet address 3 for its USB-C interface; this cannot be changed. If your Ethernet network is also using subnet 3 (192.168.3.nnn), the mosaic-T may appear to have a valid IP address but communication will fail. Please change your Router configuration to use a different subnet.

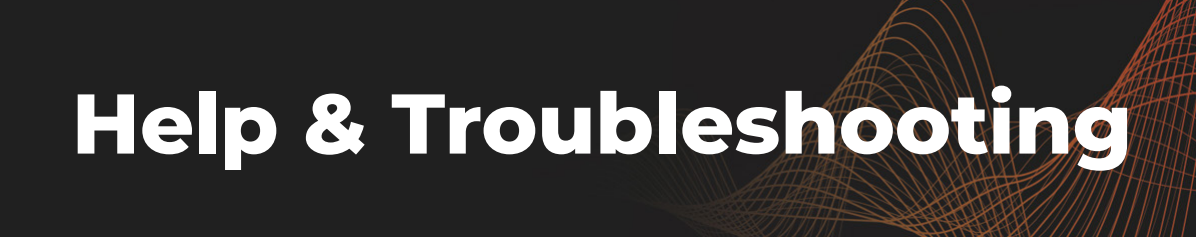
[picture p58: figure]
Help & Troubleshooting

10

If you need technical assistance or more information on a product that is not working as you expected, we recommend heading on over to the SparkFun Technical Assistance page for some initial troubleshooting.

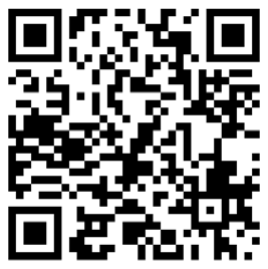
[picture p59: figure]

If you can’t find what you need there, the SparkFun GPS Forum is a great place to ask questions.

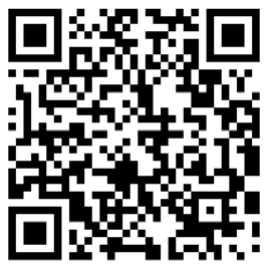
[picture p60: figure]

If this is your first visit to our forum, you’ll need to create a Forum Account to post questions.

https://www.sparkfun.com/technical_assistance

## Technical Assistance

https://community.sparkfun.com/c/globalpositioning-system-gps/96

## SparkFun GPS Forum

https://forum.sparkfun.com/ucp.php?mode=register

## Forum Account

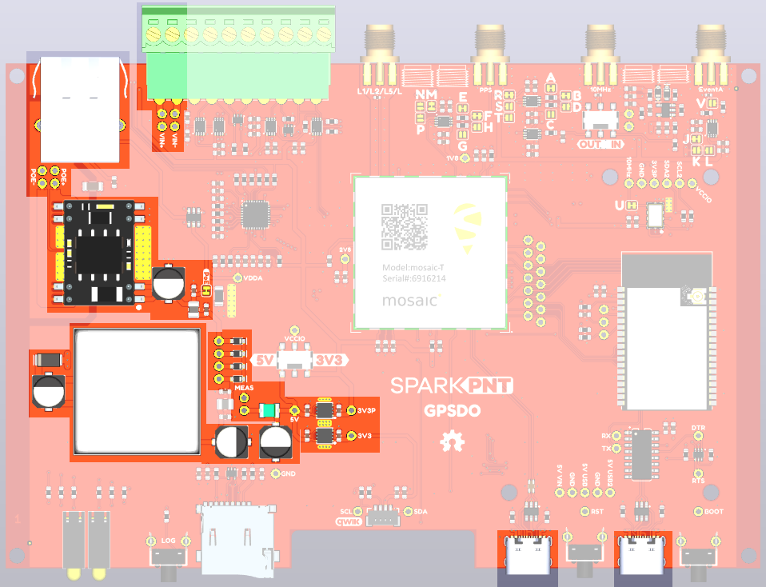
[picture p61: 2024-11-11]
docs/assets/img/hookup_guide/Power4.png

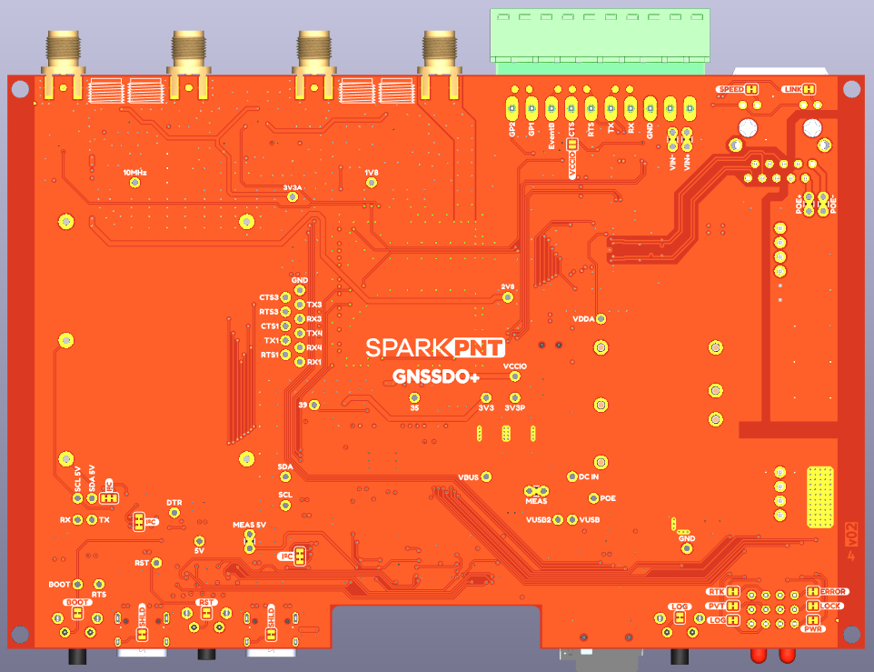
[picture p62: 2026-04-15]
docs/assets/img/hookup_guide/PCB_Bottom_GNSSDO+.png

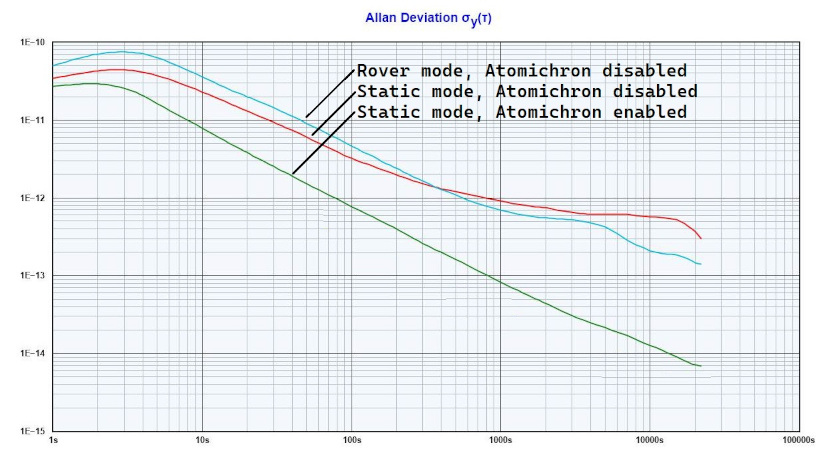
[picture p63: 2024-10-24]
docs/assets/img/hookup_guide/Allan_Deviation_small.jpg

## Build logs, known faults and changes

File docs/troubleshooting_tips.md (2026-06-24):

---
icon: sparkpnt
---

!!! failure "Deprecated Documentation"
	As of Apr 24, 2026 this guide has been retired. Users can find our latest documentation at: [docs.sparkpnt.com/SXT](https://docs.sparkpnt.com/SXT)

# Troubleshootin Tips

!!! warning "Need Help?"
	If you need technical assistance or more information on a product that is not working as you expected, we recommend heading on over to the [SparkPNT Forums](https://community.sparkpnt.com).

	!!! info "Account Registration Required"
		If this is your first visit to our forum, you'll need to create a [Forum Account](https://community.sparkpnt.com/signup) to post questions.

## What is in the Box?

<div class="grid cards desc" markdown>

<div markdown>

<figure markdown>
Kit contents (https://cdn.sparkfun.com/assets/parts/2/7/2/0/7/26289-GNSS-Disciplined-Oscillator-Kit-Feature.jpg "Click to enlarge")
<figcaption markdown>
Everything that is included in the GNSSDO kit.
</figcaption>
</figure>

</div>

<div markdown>
The GNSSDO and GNSSDO+ come packaged as a complete kit, with all the accessories you'd need to set them up. Inside the box, users will find the [GNSS antenna](https://www.sparkfun.com/gnss-multi-band-l1-l2-l5-surveying-antenna-tnc-spk6618h.html), GNSSDO(+) in its aluminum enclosure, [CAT-6 Ethernet cable](https://www.sparkfun.com/cat-6-cable-3ft.html), [USB-C cable](https://www.sparkfun.com/usb-c-to-usb-c-silicone-power-charging-cable-3m.html), and another box containing additional accessories. Inside the accessory box, users will find the [SMA to TNC cable](https://www.sparkfun.com/reinforced-interface-cable-sma-male-to-tnc-male-10m.html), [SMA to BNC cable](https://www.sparkfun.com/sma-to-bnc-male-cable-rg316-1m.html), [USB PD wall adapter](https://www.sparkfun.com/usb-a-and-c-power-delivery-pd-wall-adapter-65w.html), [WiFi antenna](https://www.sparkfun.com/products/145), [silicone bumpers](https://www.sparkfun.com/silicone-bumpers-5x11mm-4-pack.html), and [32GB SD card](https://www.sparkfun.com/microsd-card-32gb-class-10.html).

If you are missing any of these items, please reach out to us in our forum.

<article style="text-align: center;" markdown>
[SparkPNT Forum](https://community.sparkpnt.com/){ .md-button .md-button--primary }
</article>

</div>

</div>

## OLED Dead Pixels
Got a few dead pixels on your OLED display? Please reach out to us in our forum.

<article style="text-align: center;" markdown>
[SparkPNT Forum](https://community.sparkpnt.com/){ .md-button .md-button--primary }
</article>

## Data Logging
For data logging issues, here are some simple troubleshooting tips:

- Make sure that your SD card is formatted to a `FAT32` file system.
	- The `FAT32` file system also limits the maximum capacity of the card to less than **32GB** *(i.e. a 256GB SD card will not work)*.
- Make sure that the mosaic-T module has a configured data stream output.
- Use the mosaic-T web page to verify that the SD card is mounted as a storage drive.

## L5 Band
By default, the L5 band is enabled on the mosaic-T. To disable or re-enable reception of the L5 band on the mosaic-T, we have provided instructions on the [Enable the L5 Band](./L5.md) page.

## Reprogramming the ESP32
In case users accidentally reprogram or corrupt the flash memory on the ESP32, the **[/Firmware/Binaries](https://github.com/sparkfun/SparkFun_GNSSDO/tree/main/Firmware/Binaries)** folder contains the firmware binaries.

You can update or reload the firmware using the [SparkFun RTK Firmware Uploader](https://github.com/sparkfun/SparkFun_RTK_Firmware_Uploader).

The full firmware source code is available in our [GitHub repository](https://github.com/sparkfun/SparkFun_GNSSDO/tree/main/Firmware/GNSSDO_Firmware)

## Enclosure Disassembly
Due to the ESD sensitivity of the mosaic-T module, we don't recommend disassembling the GNSSDO. However, if users must access the PCB to troubleshoot an issue, make a modification, or repair a component, we highly recommend that they take the necessary ESD precautions to avoid damaging the mosaic-T module.

!!! warning "Read Before Disassembly!"
	!!! danger "ESD Sensitivity"
		The mosaic-T module is sensitive to [ESD](https://en.wikipedia.org/wiki/Electrostatic_discharge "Electrostatic Discharge"). Use a proper grounding system to make sure that the working surface and the components are at the same electric potential.

	??? info "ESD Precaution"
		As recommended by the manufacturer, we highly encourage users to take the necessary precautions to avoid damaging their module.

		- The GNSSDO features ESD protection on the USB-C connectors, ethernet jack, I/O terminals and SMA antenna connections.

		<div class="grid cards" markdown>

		<div markdown>

		<article class="video-500px" style="text-align: center; margin: auto;" markdown>
		<iframe src="https://www.youtube.com/embed/hrL5J6Q5gX8?si=jOPBat8rzMnL7Uz4&amp;start=26;&amp;end=35;" title="Septentrio: Getting Started Video (playback starts at ESD warning)" frameborder="0" allow="accelerometer; autoplay; clipboard-write; encrypted-media; gyroscope; picture-in-picture" allowfullscreen></iframe>
		</article>

		</div>

		-   <a href="https://www.sparkfun.com/products/25572">
			<figure markdown>
			Product Thumbnail
			</figure>		

			---

			**iFixit Anti-Static Wrist Strap**<br>
			TOL-25572</a>

		</div>

Before disassembling the enclosure, users should disconnect the power and all cables from the GNSSDO. This will prevent users from creating any shorts and will facilitate the teardown process further on.

The GNSSDO PCB is held in place by the front and rear panels of the enclosure. While users can remove the panels first, we recommend that users disconnect the screw terminal blocks first. Users may find it more difficult to separate the terminal block from the connector later in the disassembly process.

???+ tip "Remove the Screw Terminal Block First"
	Users may find it easiest to remove the screw terminal blocks first; as opposed to later in the teardown process.

	<figure markdown>
	Prying the Terminal Block
	<figcaption markdown>Using a soft/rigid object to carefully pry the terminal block off.</figcaption>
	</figure>

	Users can wiggle or use a soft/rigid object to carefully pry the terminal block off. In the picture above, a plastic name tag (~1.5mm thick) is used to carefully pry the terminal block up. We have also found the edge of a [PCB ruler](https://www.sparkfun.com/products/15295) works great too.

Once the terminal blocks have been removed, users can remove the front and rear panels of the enclosure. They are held in place with four, M3, Phillips head screws on the corners of each panel.

!!! tip "Remove Front Panel First"
	We recommend removing the front panel first to prevent the Qwiic cable from being yanked off the OLED display or main PCB. Once the front panel is free, carefully lift the panel and disconnect the Qwiic cable from the top connector on the OLED display.

At this point, if users have previously disconnected all the cables and the terminal blocks from the back, the GNSSDO PCB should slide out of the enclosure. Users can then, remove the rear panel from the enclosure to complete the teardown process.

## GNSSDO Clock Frequency Reference
The mosaic-T module can either use its internal TCXO or accept an external signal as a frequency reference. However, the module will constantly reboot if the `REF_I` pin isn't provided a 10MHz sinusoidal signal and left floating. Therefore, GNSSDO users should only set the `10MHz` switch to the `IN` position, only if a 10MHz clock signal can be provided; otherwise, the switch should remain in the `OUT` position.

!!! note
	Switching between an external and internal frequency reference must occur when the mosaic-T is powered off, or the module must be reset after switching.

<!-- QR Code for Hookup Guide (Displayed when printed) -->
<article style="text-align: center;" markdown>
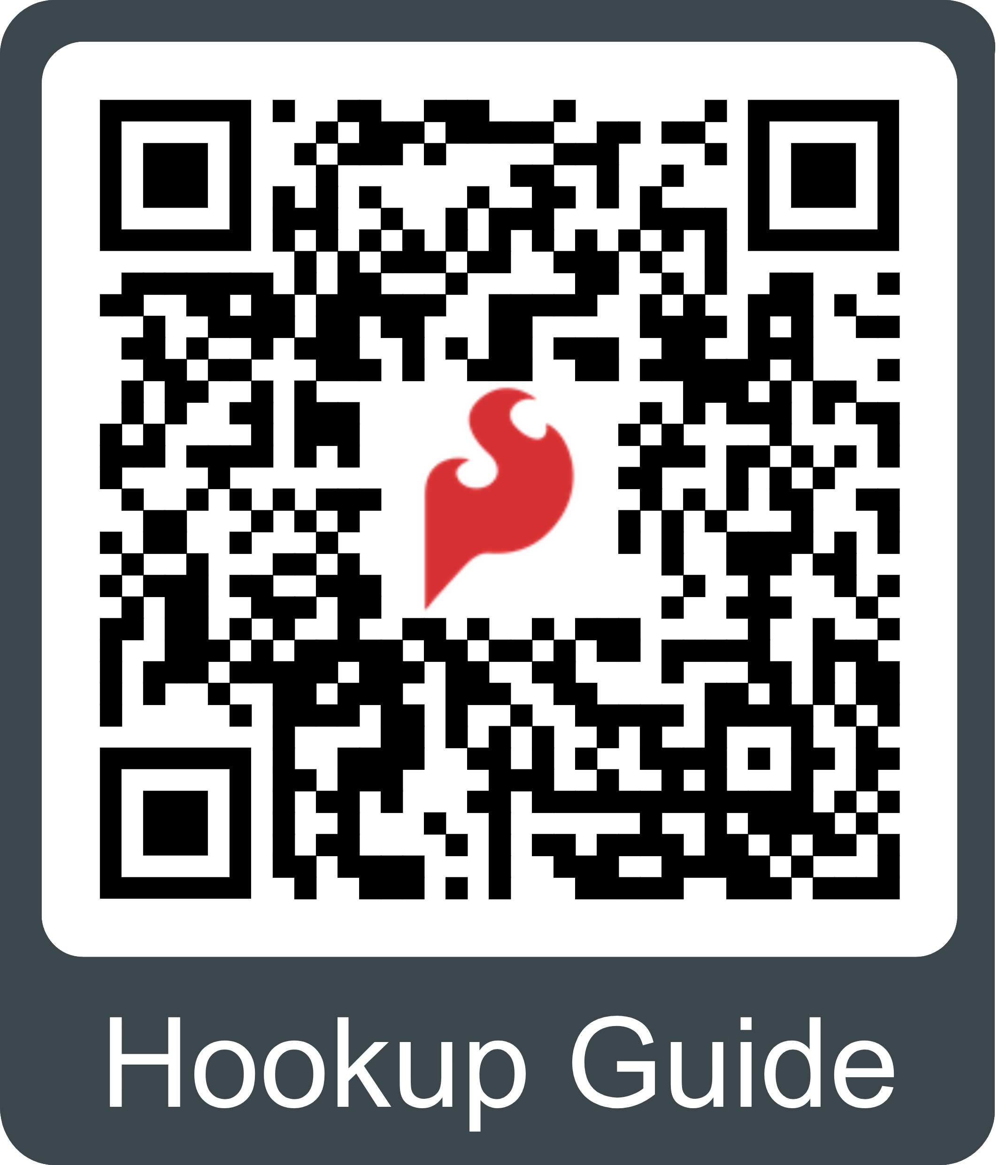
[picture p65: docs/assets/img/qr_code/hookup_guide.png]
QR code to the hookup guide

</article>

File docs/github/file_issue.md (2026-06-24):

# Did we make a mistake?

Spot something wrong? Please let us know. 

<!-- Technical Assistance Box -->
!!! warning "Need Help?"
	If you need technical assistance or more information on a product that is not working as you expected, we recommend heading on over to the [SparkFun Technical Assistance](https://www.sparkfun.com/technical_assistanc) page for some initial troubleshooting. This **Submit Issues** page is not where users should seek assistance.

	<article style="text-align: center;" markdown>
	[SparkFun Technical Assistance Page](https://www.sparkfun.com/technical_assistance){ .md-button .md-button--primary }
	</article>

	If you can't find what you need there, the [SparkPNT Forums](https://community.sparkpnt.com) is a great place to search the product forums and ask questions.

	!!! info "Account Registration Required"
		For your first visit to our forum, you'll need to create a [Forum Account](https://community.sparkpnt.com) to post questions.

## Discrepancies in the Documentation

All of our documentation can be modified by you! Please help us make it better.

- The documentation files for these pages are contained in the [`docs` folder](https://github.com/sparkfun/SparkFun_GNSSDO/tree/main/docs) of the [SparkFun GNSSDO repository](https://github.com/sparkfun/SparkFun_GNSSDO).

### 🔍 Spot something wrong?

If a section of the documentation is incorrect, please [open an issue](https://github.com/sparkfun/SparkFun_GNSSDO/issues) and let us know.

### Do you have a suggested correction?

1. With a GitHub account, [fork this repository](https://github.com/sparkfun/SparkFun_GNSSDO/fork).
2. Add your correction(s) or improvement(s) to the markdown file(s)
3. File a pull request with your changes, and enjoy making the ~~words~~ ~~worlds~~ world a better place.
	- Once received, the documentation specialist will automatically be notified.
	- We will review your suggested improvement(s) to make sure they are correct and fit within our documentation standards.

## Problems in the Hardware Design

All of our designs are open-source! Please help us make it better.

- Our board design files are contained in the [`Hardware` folder](https://github.com/sparkfun/SparkFun_GNSSDO/tree/main/Hardware) of the [SparkFun GNSSDO repository](https://github.com/sparkfun/SparkFun_GNSSDO).

### Does something not make sense? 🤔

If part of the design is confusing, please [open an issue](https://github.com/sparkfun/SparkFun_GNSSDO/issues) and let us know.

### Did we forget to include an important function of the board? 🤦

If part of the board's functionality is missing, please [open an issue](https://github.com/sparkfun/SparkFun_GNSSDO/issues) and file a feature request.

!!! tip "Design Considerations"
	Please keep in mind that we may intentionally exclude certain functions of the board to meet our product design requirements.

	- *For example, our Qwiic Micro boards are intended to fit on a small board layout and only use I^2^C communication; therefore, we may not have the SPI and interrupt pins available for users.*

### Do you wish to contribute directly to improving the board design?

1. With a GitHub account, [fork this repository](https://github.com/sparkfun/SparkFun_GNSSDO/fork).
2. Add your design augmentation(s)
3. File a pull request with your changes, and enjoy making the ~~words~~ ~~worlds~~ world a better place.
	1. Once received, the engineer in charge of the original design will automatically be notified.
	2. We will review your suggested improvement(s) to verify that they are within our board design standards and meet our product design requirements.
	3. If approved, we will flag these changes for our next board revision. Congrats! 🍻

		!!! info
			Even if your suggestion is accepted, these changes may not be immediately available for purchase. We may have to cycle through our current product inventory first.

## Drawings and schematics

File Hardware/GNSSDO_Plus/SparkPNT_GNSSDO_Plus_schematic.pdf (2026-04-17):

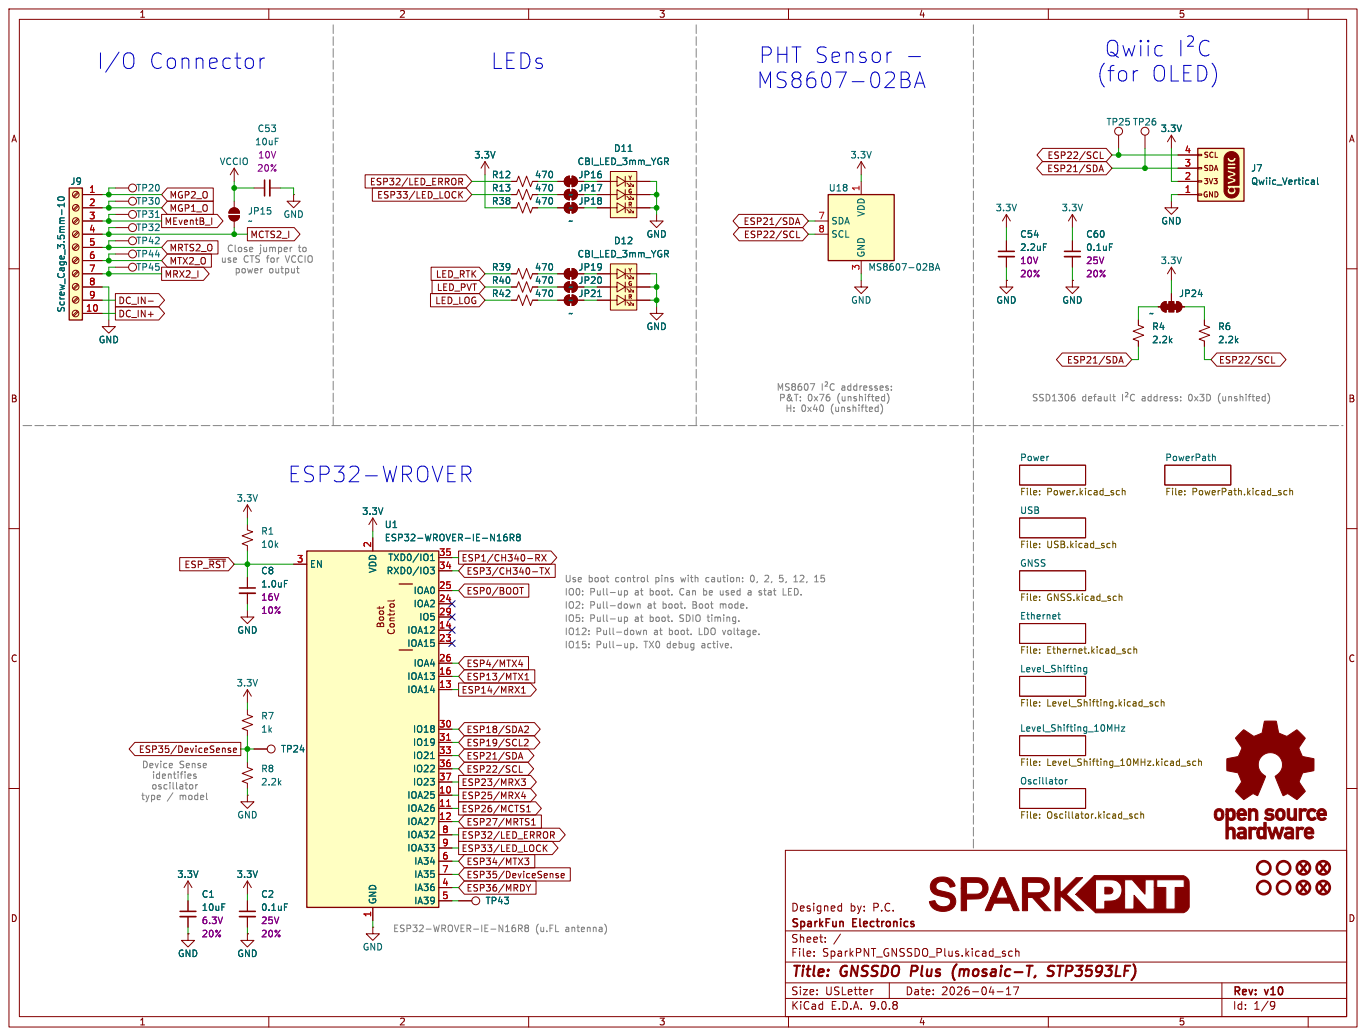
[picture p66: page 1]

Close jumper to
use CTS for VCCIO
power output

MS8607 þÿI²Caddresses: P&T: 0x76 (unshifted) H: 0x40 (unshifted)

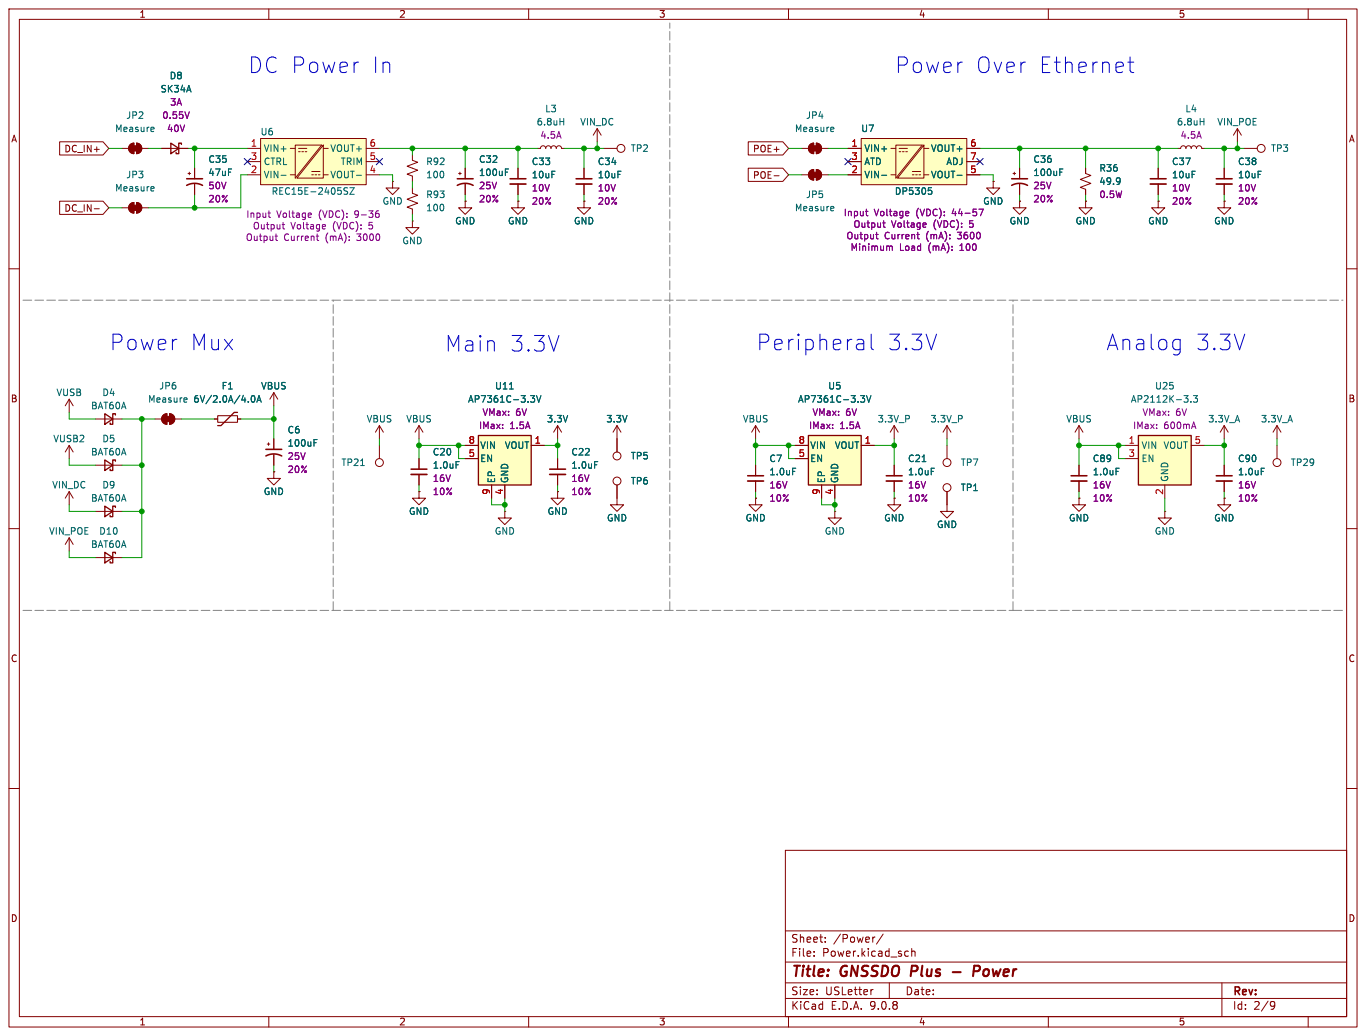
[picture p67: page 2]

Input Voltage (VDC): 44-57 Output Voltage (VDC): 5 Output Current (mA): 3600 Minimum Load (mA): 100

Id: 2/9 Title: GNSSDO Plus - Power File: Power.kicad_sch Sheet: /Power/

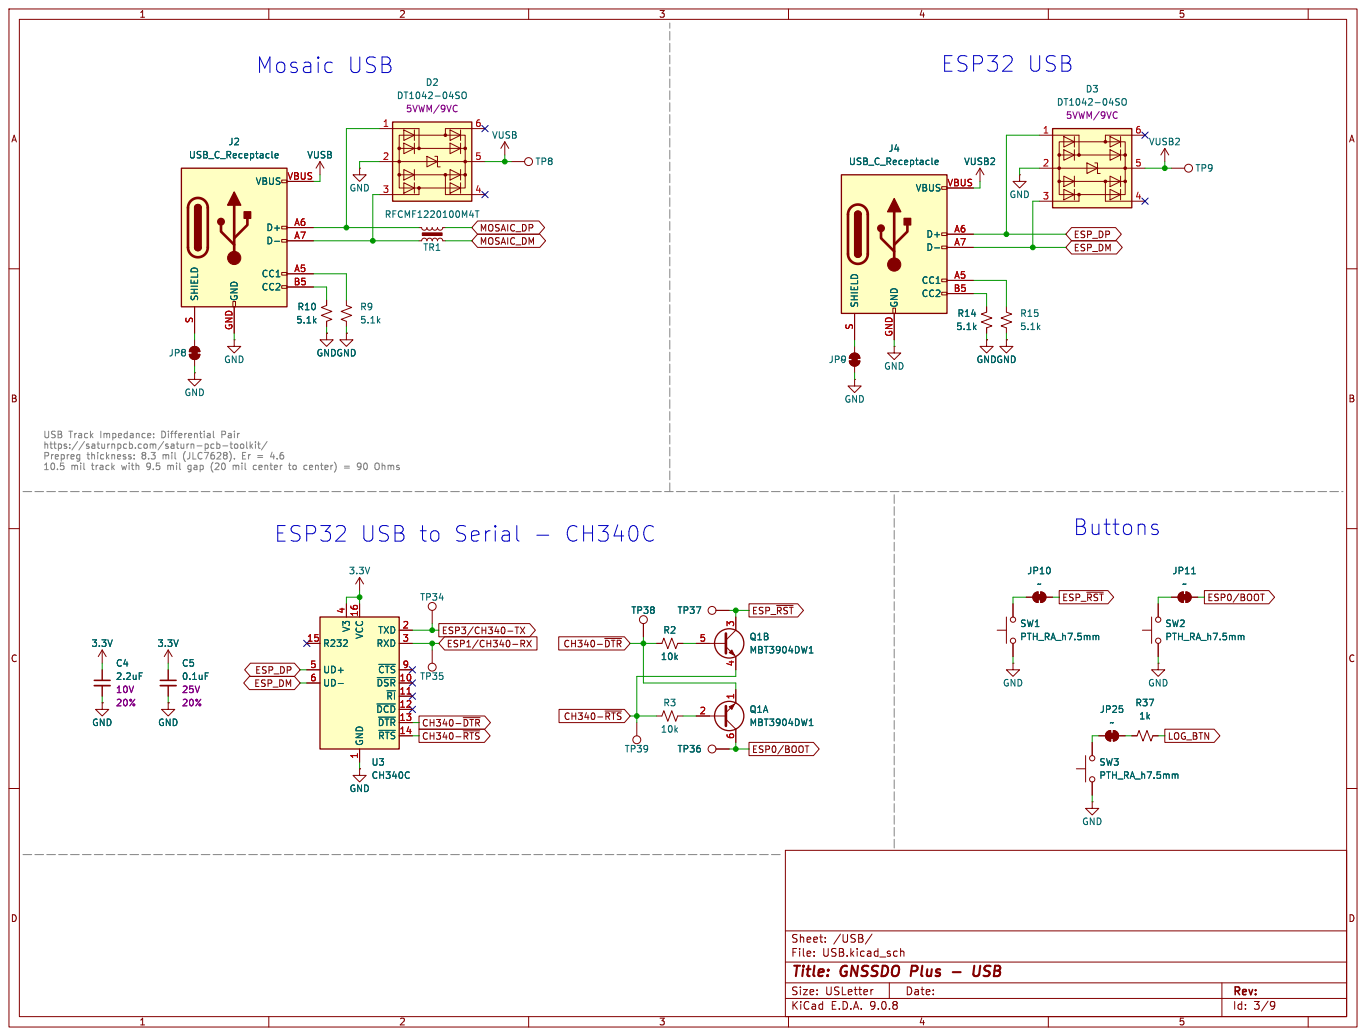
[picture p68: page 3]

10.5 mil track with 9.5 mil gap (20 mil center to center) = 90 Ohms ESP32 USB to Serial - CH340C

1 TXD 2 RXD 3 ~{CTS}9 ~{DSR} 10 ~{RI} 11 ~{DCD} 12 ~{DTR} 13 ~{RTS} 14 TP38

1 TXD 2 RXD 3 ~{CTS}9 ~{DSR} 10 ~{RI} 11 ~{DCD} 12 ~{DTR} 13 ~{RTS} 14 U3 CH340C

File: USB.kicad_sch Sheet: /USB/
Id: 3/9 Title: GNSSDO Plus - USB

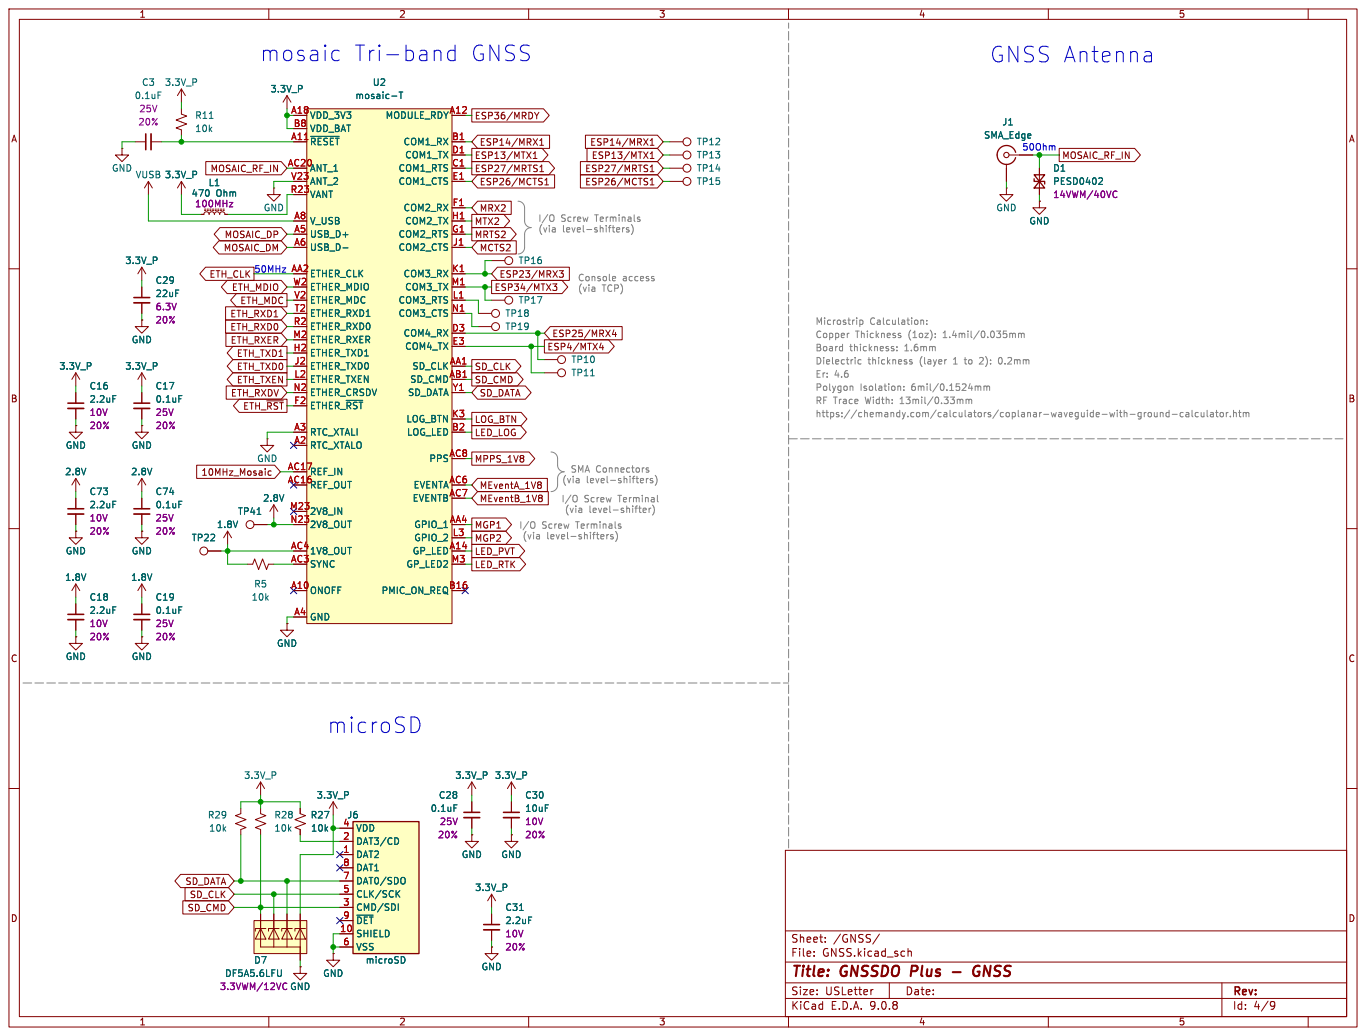
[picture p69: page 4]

RF Trace Width: 13mil/0.33mm
https://chemandy.com/calculators/coplanar-waveguide-with-ground-calculator.htm

SMA Connectors
(via level-shifters)
I/O Screw Terminal (via level-shifter)

File: GNSS.kicad_sch Sheet: /GNSS/
Id: 4/9 Title: GNSSDO Plus - GNSS

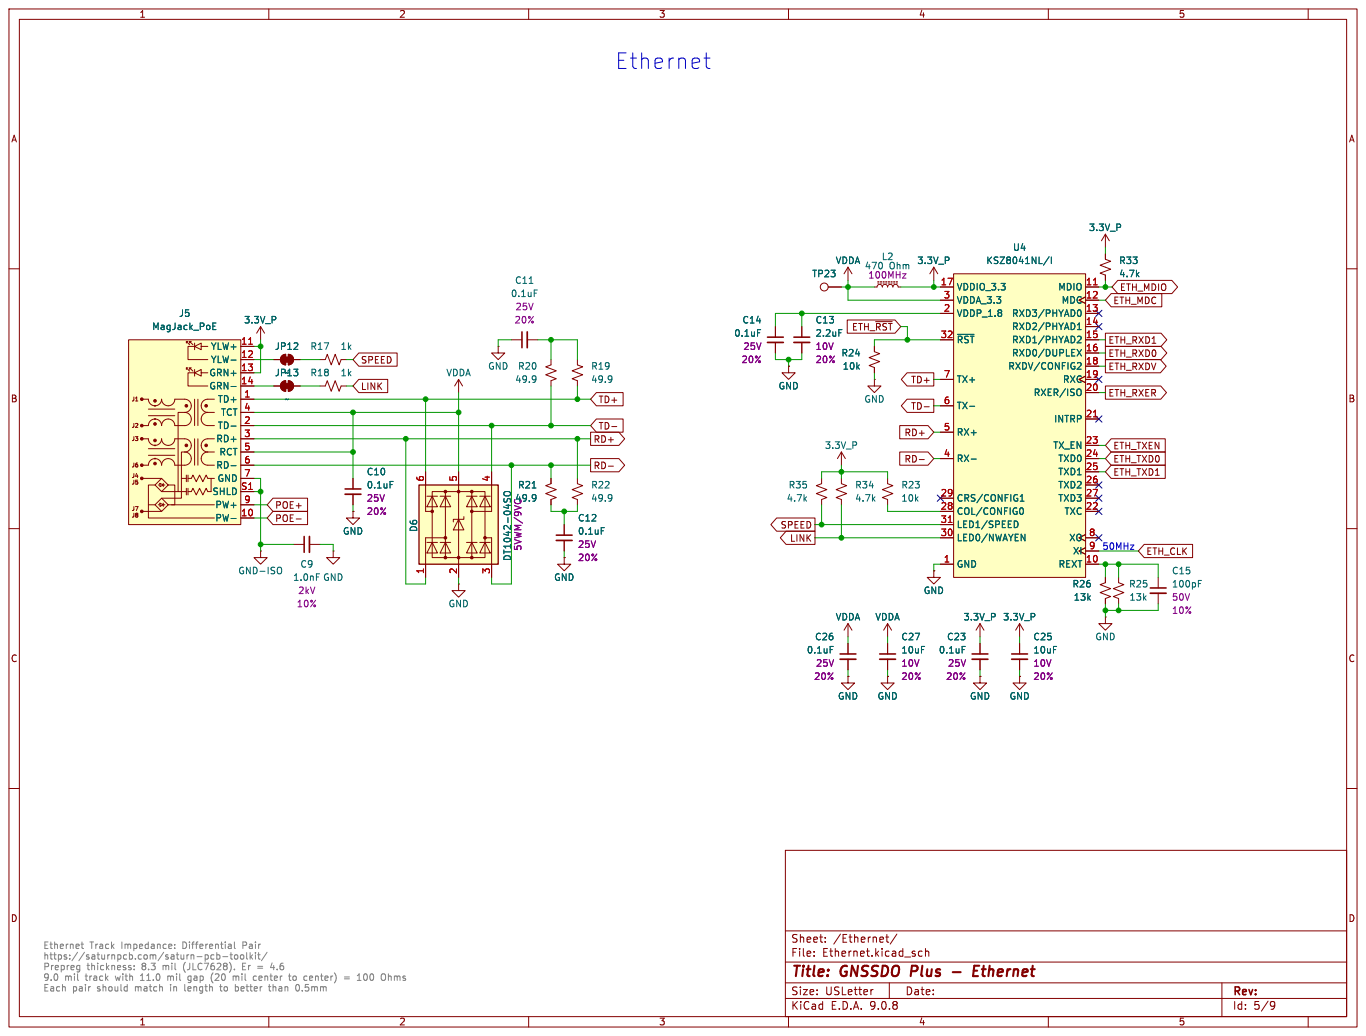
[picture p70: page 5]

J5 MagJack_PoE
YLW- 12 GRN+ 13 GRN- 14 TD+ 1 TCT 4 TD- 2 RD+ 3 RCT 5 RD- 6 GND 7 SHLD S1 PW+ 9 PW- 10 YLW+ 11

Id: 5/9 Title: GNSSDO Plus - Ethernet File: Ethernet.kicad_sch Sheet: /Ethernet/ VDDA R35

9.0 mil track with 11.0 mil gap (20 mil center to center) = 100 Ohms Each pair should match in length to better than 0.5mm

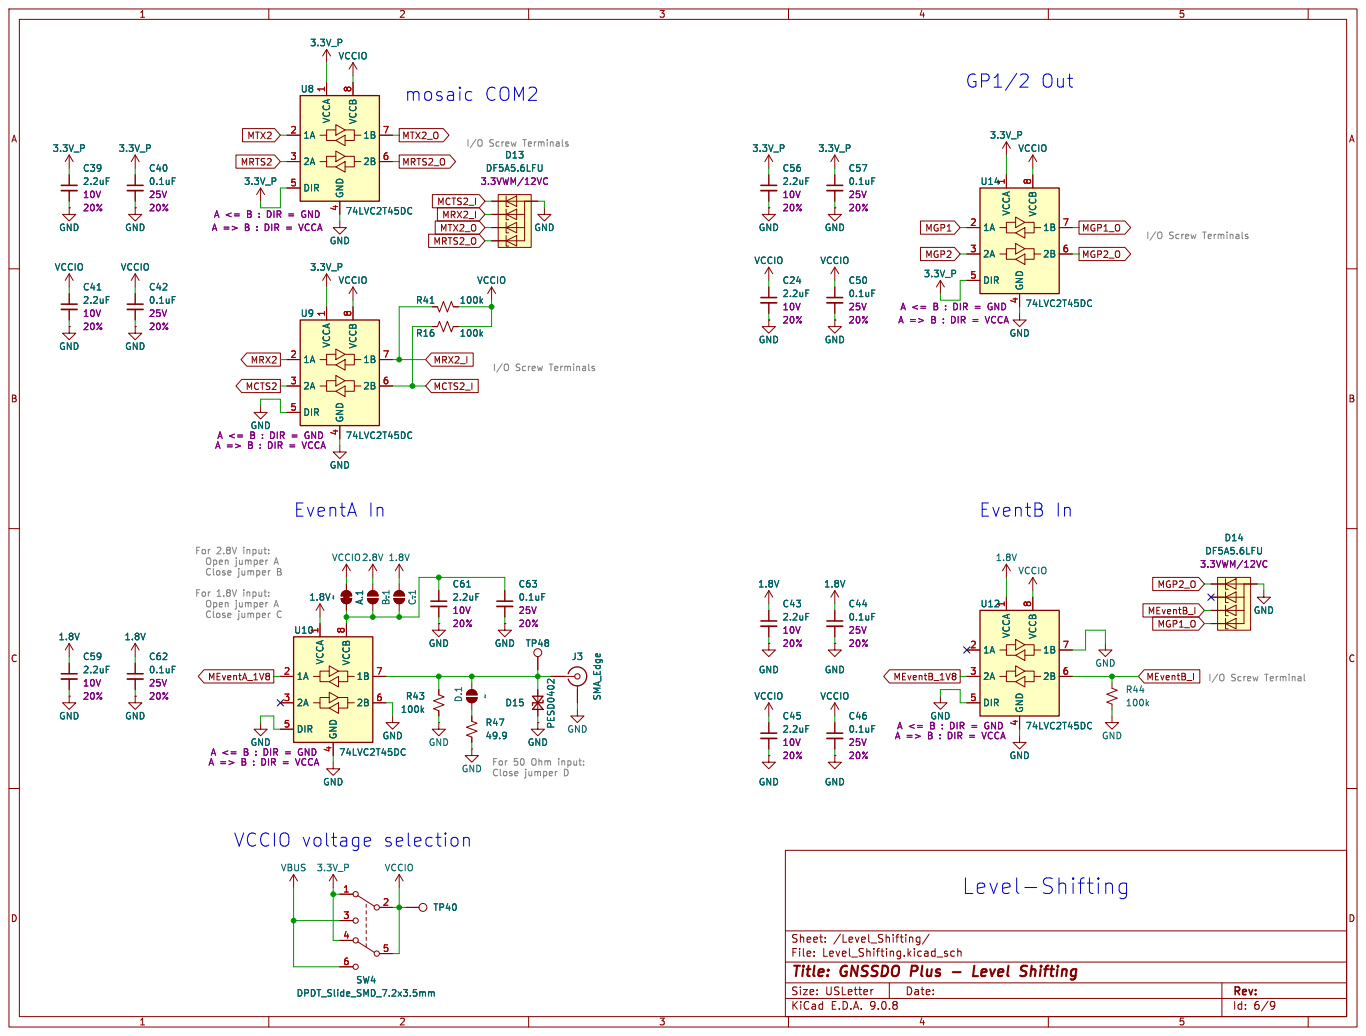
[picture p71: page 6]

I/O Screw Terminals EventA In

I/O Screw Terminals EventB In

For 2.8V input:
Open jumper A Close jumper B

For 1.8V input:
Open jumper A Close jumper C

For 50 Ohm input: Close jumper D

Id: 6/9 Title: GNSSDO Plus - Level Shifting

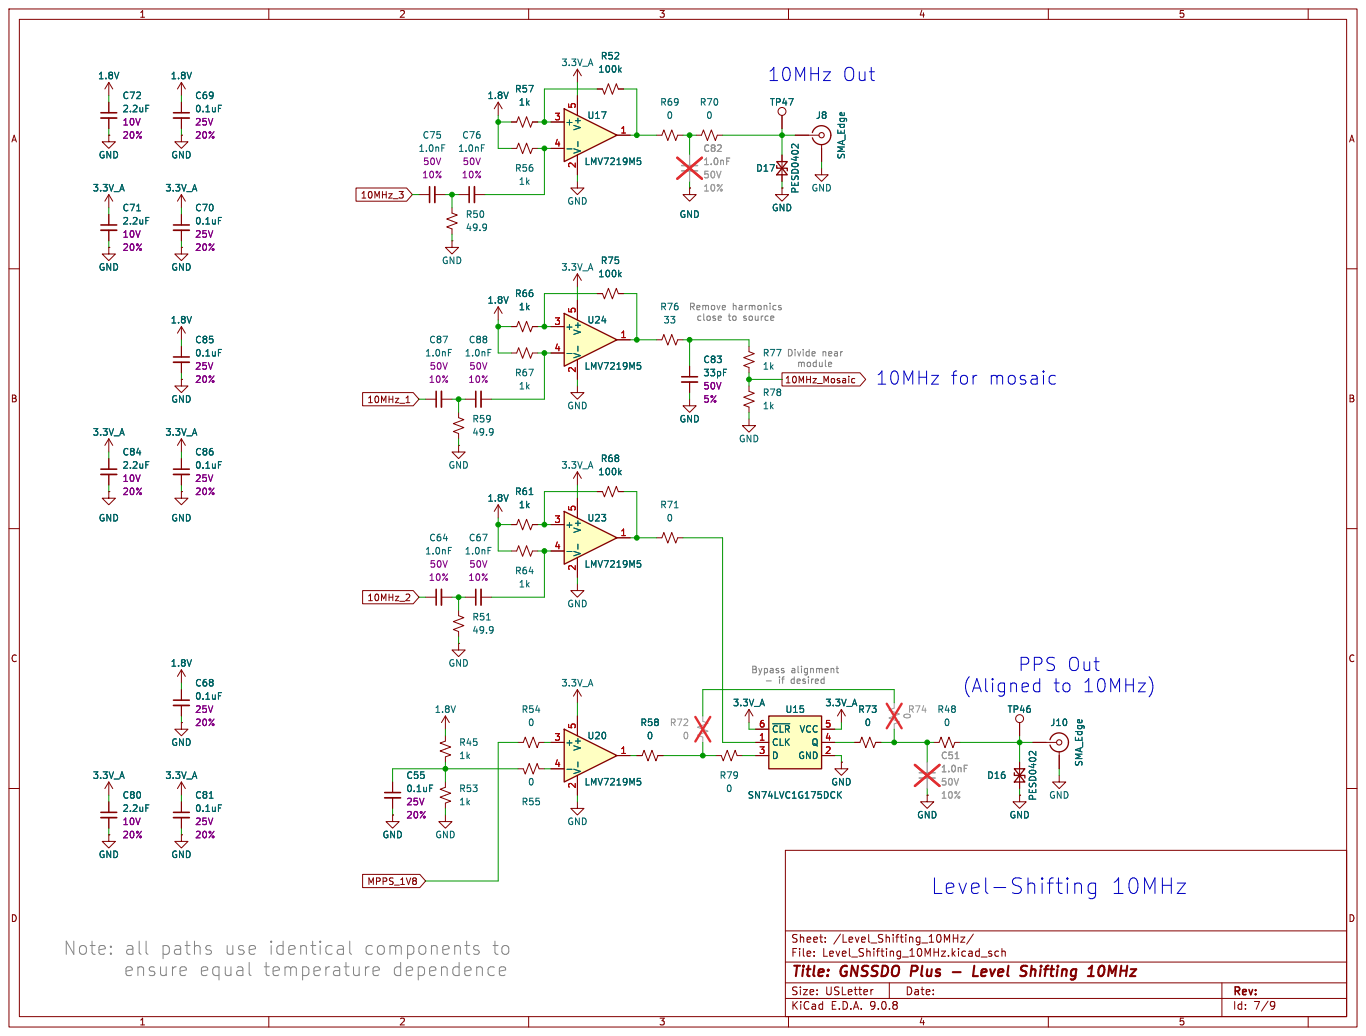
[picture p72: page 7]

(Aligned to 10MHz) Remove harmonics
1k GND

File: Level_Shifting_10MHz.kicad_sch Sheet: /Level_Shifting_10MHz/
Id: 7/9 Title: GNSSDO Plus - Level Shifting 10MHz

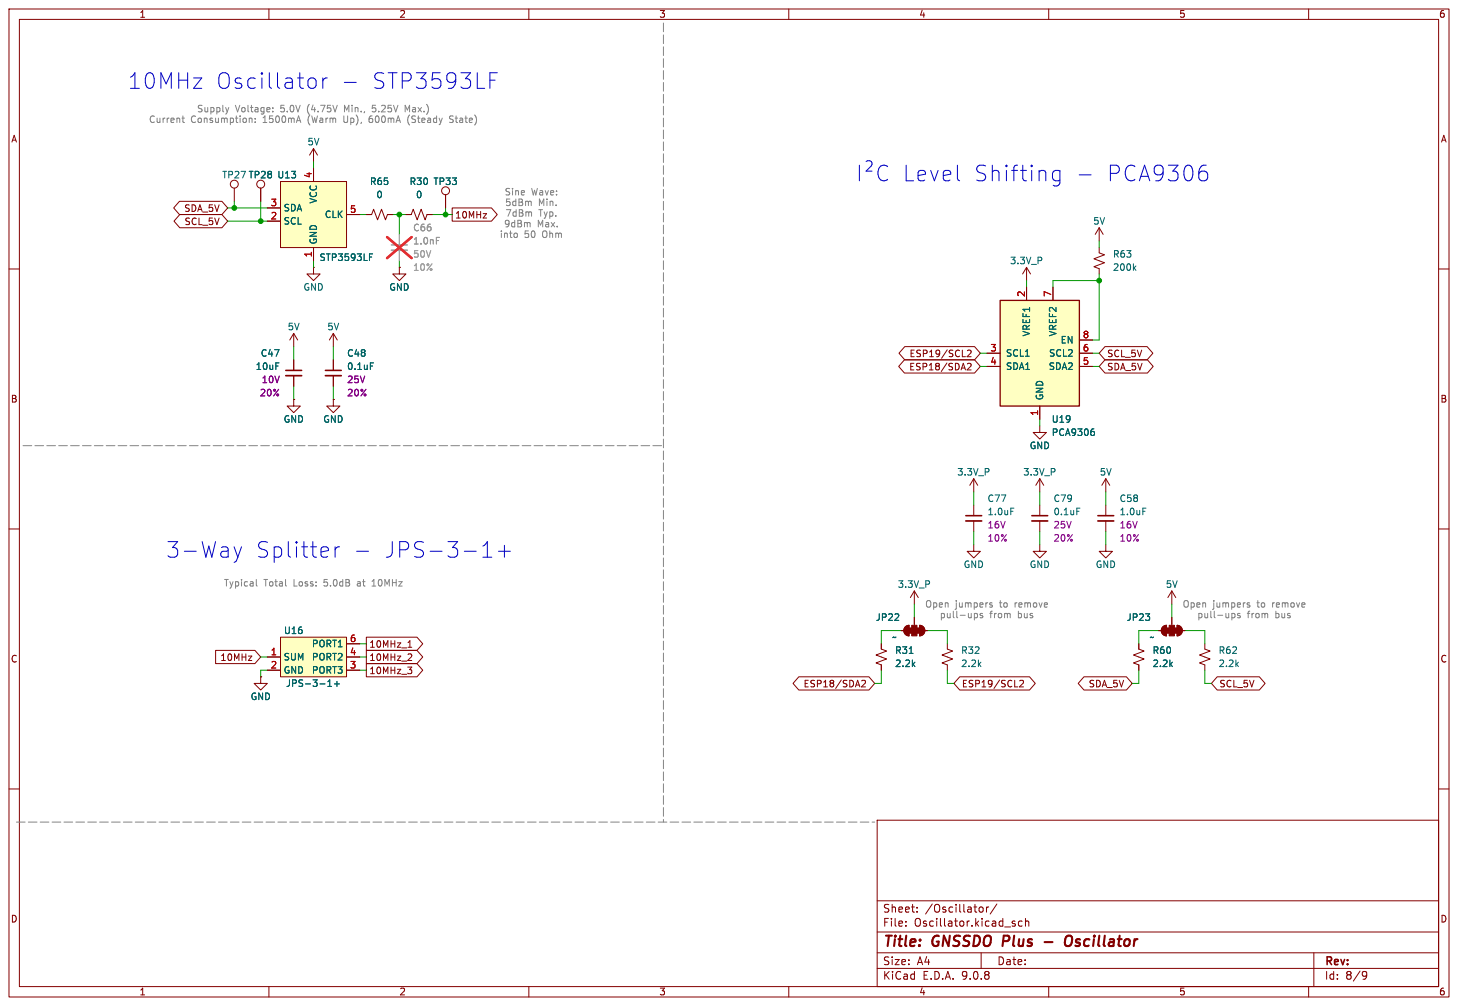
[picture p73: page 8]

Sine Wave: 5dBm Min. 7dBm Typ. 9dBm Max.

Open jumpers to remove

Id: 8/9 Title: GNSSDO Plus - Oscillator File: Oscillator.kicad_sch Sheet: /Oscillator/

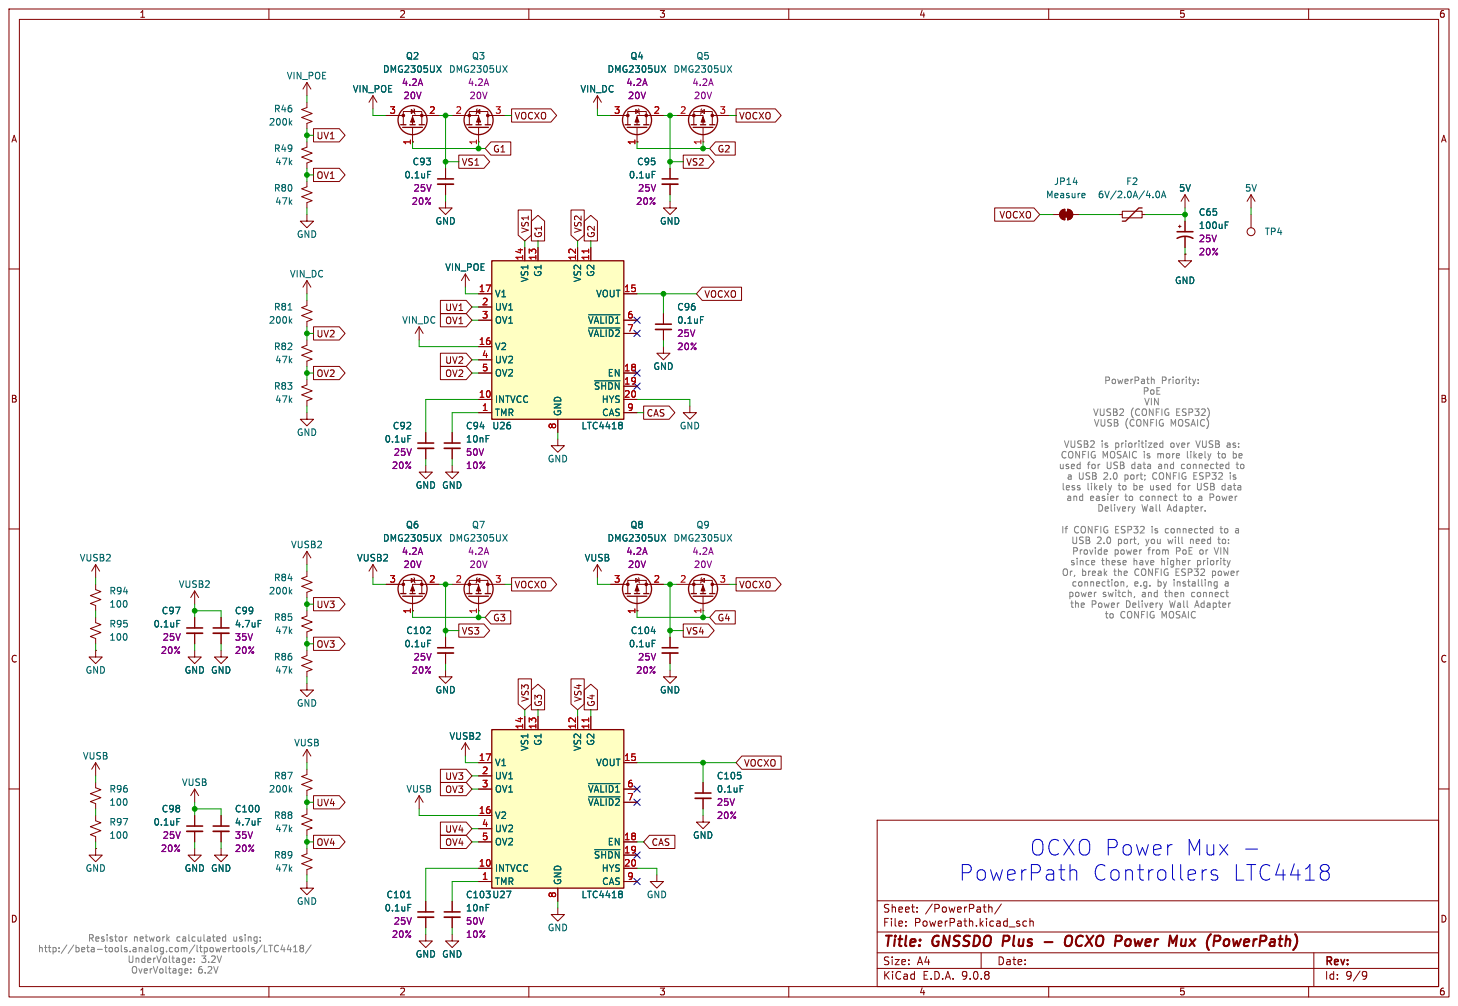
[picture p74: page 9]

8 VS2 12 G2 11 VOUT 15 ~{VALID1}6 ~{VALID2}7 EN 18 ~{SHDN}19 HYS 20 CAS 9 Q2 DMG2305UX

8 VS2 12 G2 11 VOUT 15 ~{VALID1}6 ~{VALID2}7 EN 18 ~{SHDN}19 HYS 20 CAS 9 U26 LTC4418 GND

power switch (https://www.sparkfun.com/usb-c-extension-cable-with-power-switch-1m.html) PowerPath Priority: PoE

a USB 2.0 port; CONFIG ESP32 is
less likely to be used for USB data

and easier to connect to a Power Delivery Wall Adapter. C100

the Power Delivery Wall Adapter

8 VS2 12 G2 11 VOUT 15 ~{VALID1}6 ~{VALID2}7 EN 18 ~{SHDN}19 HYS 20 CAS 9C104

8 VS2 12 G2 11 VOUT 15 ~{VALID1}6 ~{VALID2}7 EN 18 ~{SHDN}19 HYS 20 CAS 9 U27 LTC4418

http://beta-tools.analog.com/ltpowertools/LTC4418/

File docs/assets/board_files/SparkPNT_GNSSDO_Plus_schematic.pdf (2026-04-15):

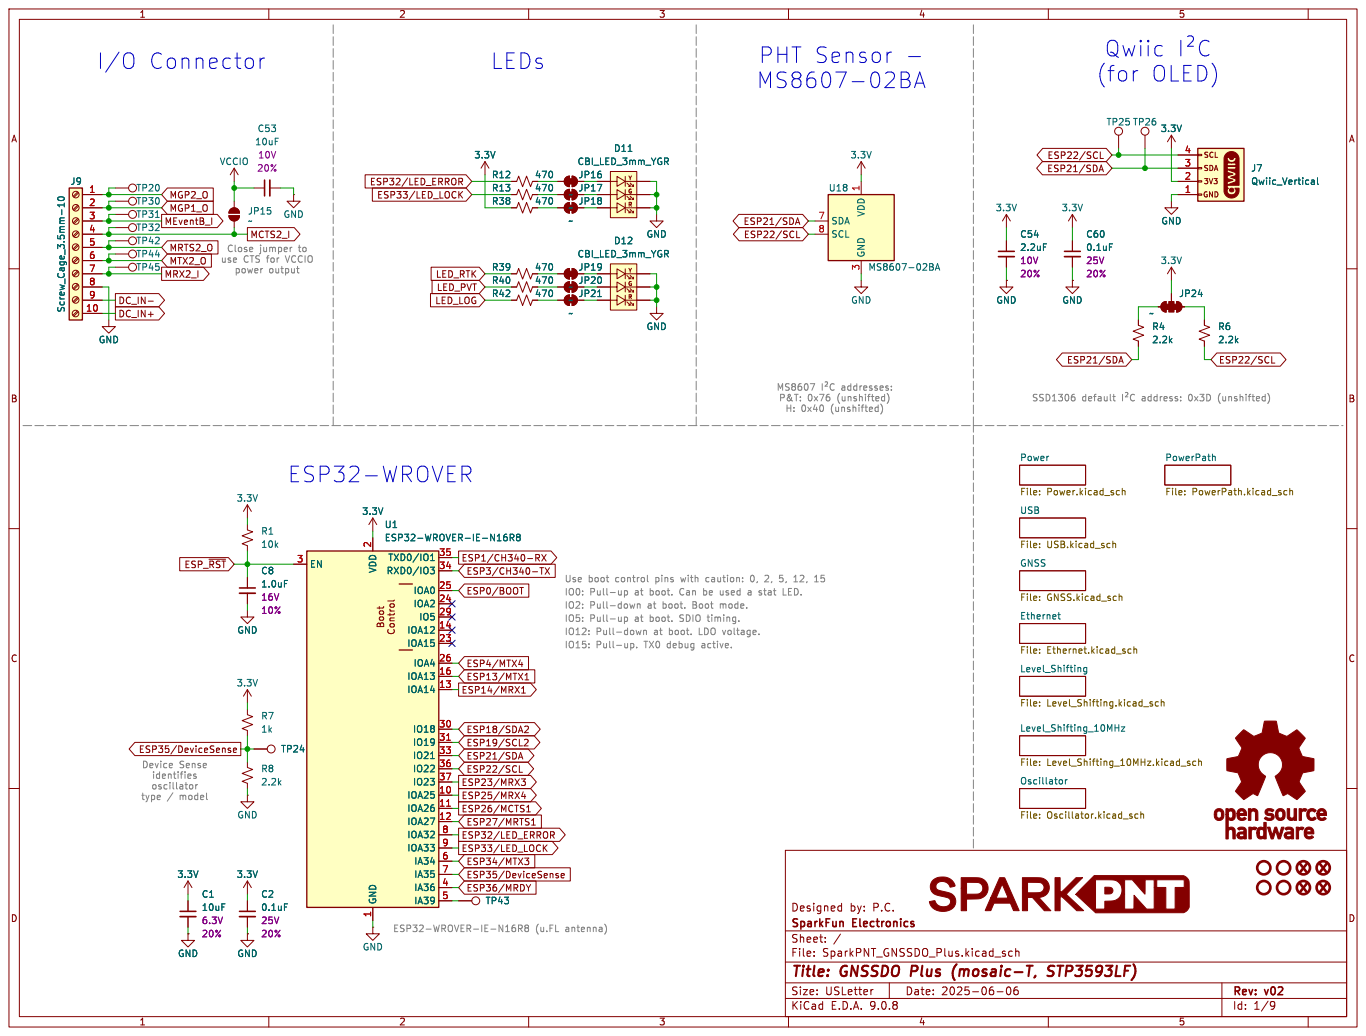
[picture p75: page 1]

use CTS for VCCIO

MS8607 þÿI²Caddresses: P&T: 0x76 (unshifted) H: 0x40 (unshifted) GND

File: GNSS.kicad_sch Oscillator File: Oscillator.kicad_sch


VIN_DC
Input Voltage (VDC): 44-57 Output Voltage (VDC): 5 Output Current (mA): 3600 Minimum Load (mA): 100 C22

Id: 2/9 Title: GNSSDO Plus - Power File: Power.kicad_sch Sheet: /Power/ GND

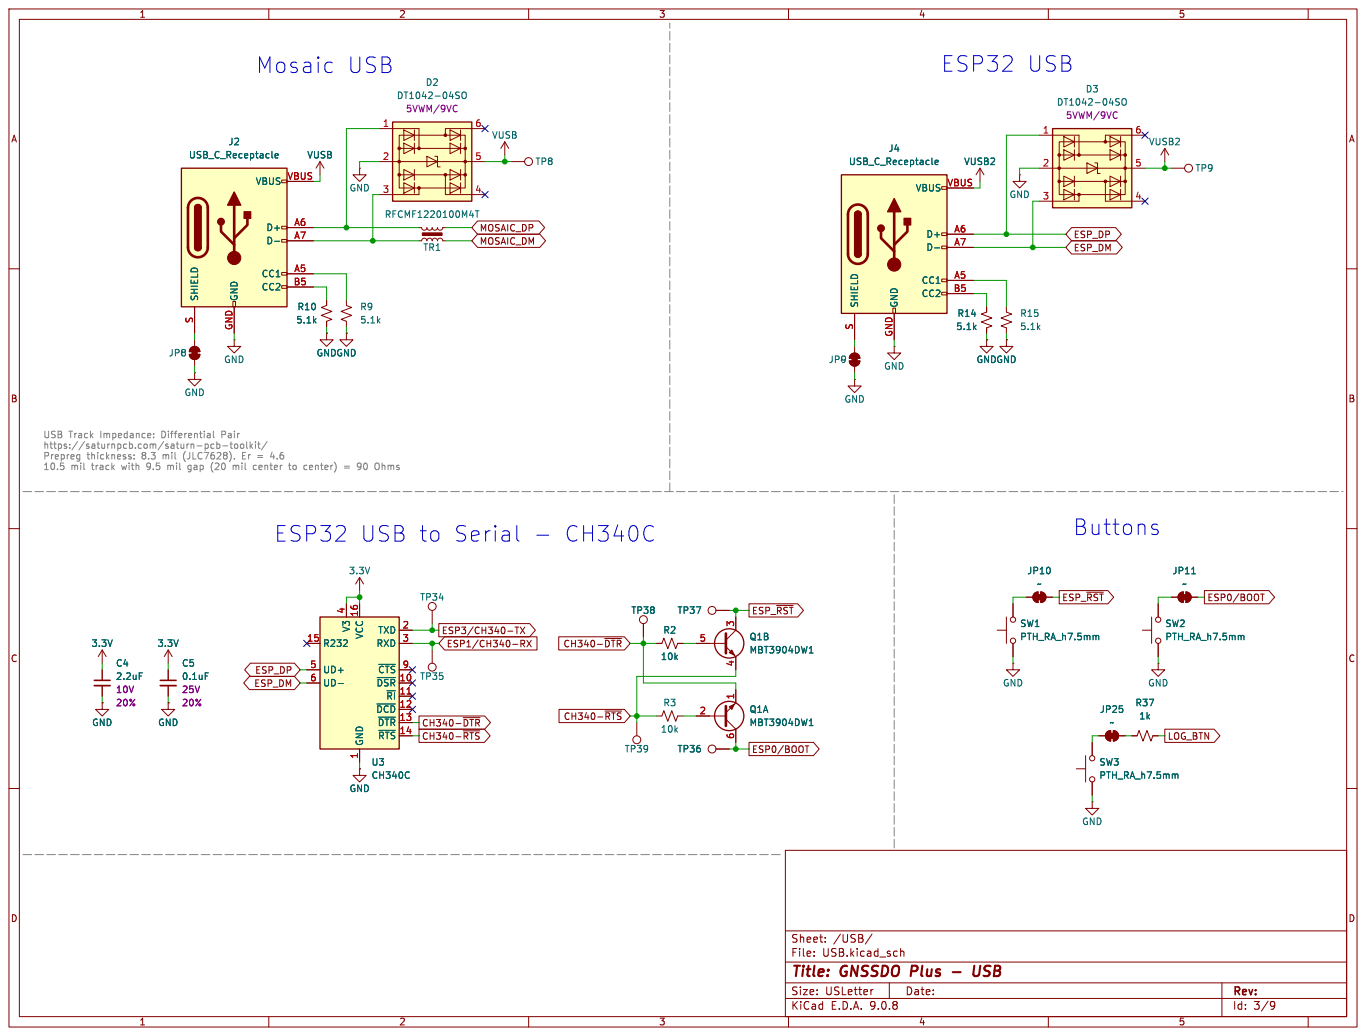
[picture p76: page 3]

ESP_~{RST} ESP0/BOOT ESP32 USB to Serial - CH340C

1 TXD 2 RXD 3 ~{CTS}9 ~{DSR} 10 ~{RI} 11 ~{DCD} 12 ~{DTR} 13 ~{RTS} 14 GND

1 TXD 2 RXD 3 ~{CTS}9 ~{DSR} 10 ~{RI} 11 ~{DCD} 12 ~{DTR} 13 ~{RTS} 14 U3 CH340C

File: USB.kicad_sch Sheet: /USB/
Id: 3/9 Title: GNSSDO Plus - USB

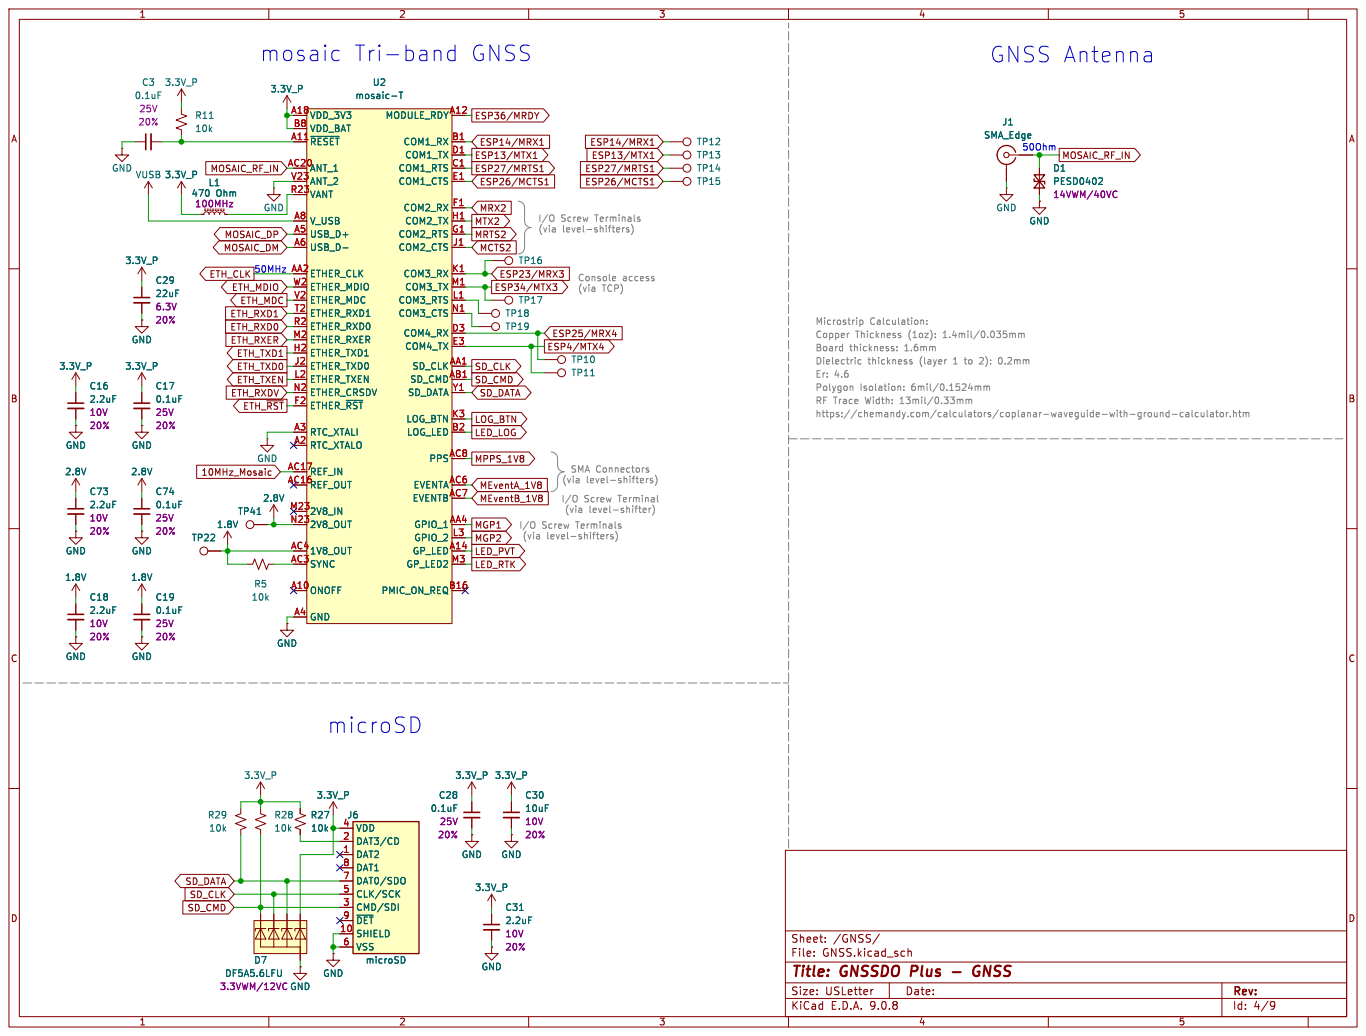
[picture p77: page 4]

I/O Screw Terminals
(via level-shifters) Console access

RF Trace Width: 13mil/0.33mm
https://chemandy.com/calculators/coplanar-waveguide-with-ground-calculator.htm

Id: 4/9 Title: GNSSDO Plus - GNSS


YLW- 12 GRN+ 13 GRN- 14 TD+ 1 TCT 4 TD- 2 RD+ 3 RCT 5 RD- 6 GND 7 SHLD S1 PW+ 9 PW- 10 YLW+ 11


I/O Screw Terminals EventB In

A => B : DIR = VCCA GND GND

I/O Screw Terminal For 2.8V input:
Open jumper A Close jumper B

For 1.8V input:
Open jumper A Close jumper C

For 50 Ohm input: Close jumper D VCCIO voltage selection
A => B : DIR = VCCA

File: Level_Shifting.kicad_sch Sheet: /Level_Shifting/
Id: 6/9 Title: GNSSDO Plus - Level Shifting


Id: 7/9 Title: GNSSDO Plus - Level Shifting 10MHz


Open jumpers to remove


8 VS2 12 G2 11 VOUT 15 ~{VALID1}6 ~{VALID2}7 EN 18 ~{SHDN}19 HYS 20 CAS 9 U26 LTC4418 VIN_POE GND GND GND

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

a USB 2.0 port; CONFIG ESP32 is
less likely to be used for USB data
and easier to connect to a Power Delivery Wall Adapter.

the Power Delivery Wall Adapter

8 VS2 12 G2 11 VOUT 15 ~{VALID1}6 ~{VALID2}7 EN 18 ~{SHDN}19 HYS 20 CAS 9 C103 U27 LTC4418

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

Id: 9/9 Title: GNSSDO Plus - OCXO Power Mux (PowerPath) File: PowerPath.kicad_sch Sheet: /PowerPath/

http://beta-tools.analog.com/ltpowertools/LTC4418/








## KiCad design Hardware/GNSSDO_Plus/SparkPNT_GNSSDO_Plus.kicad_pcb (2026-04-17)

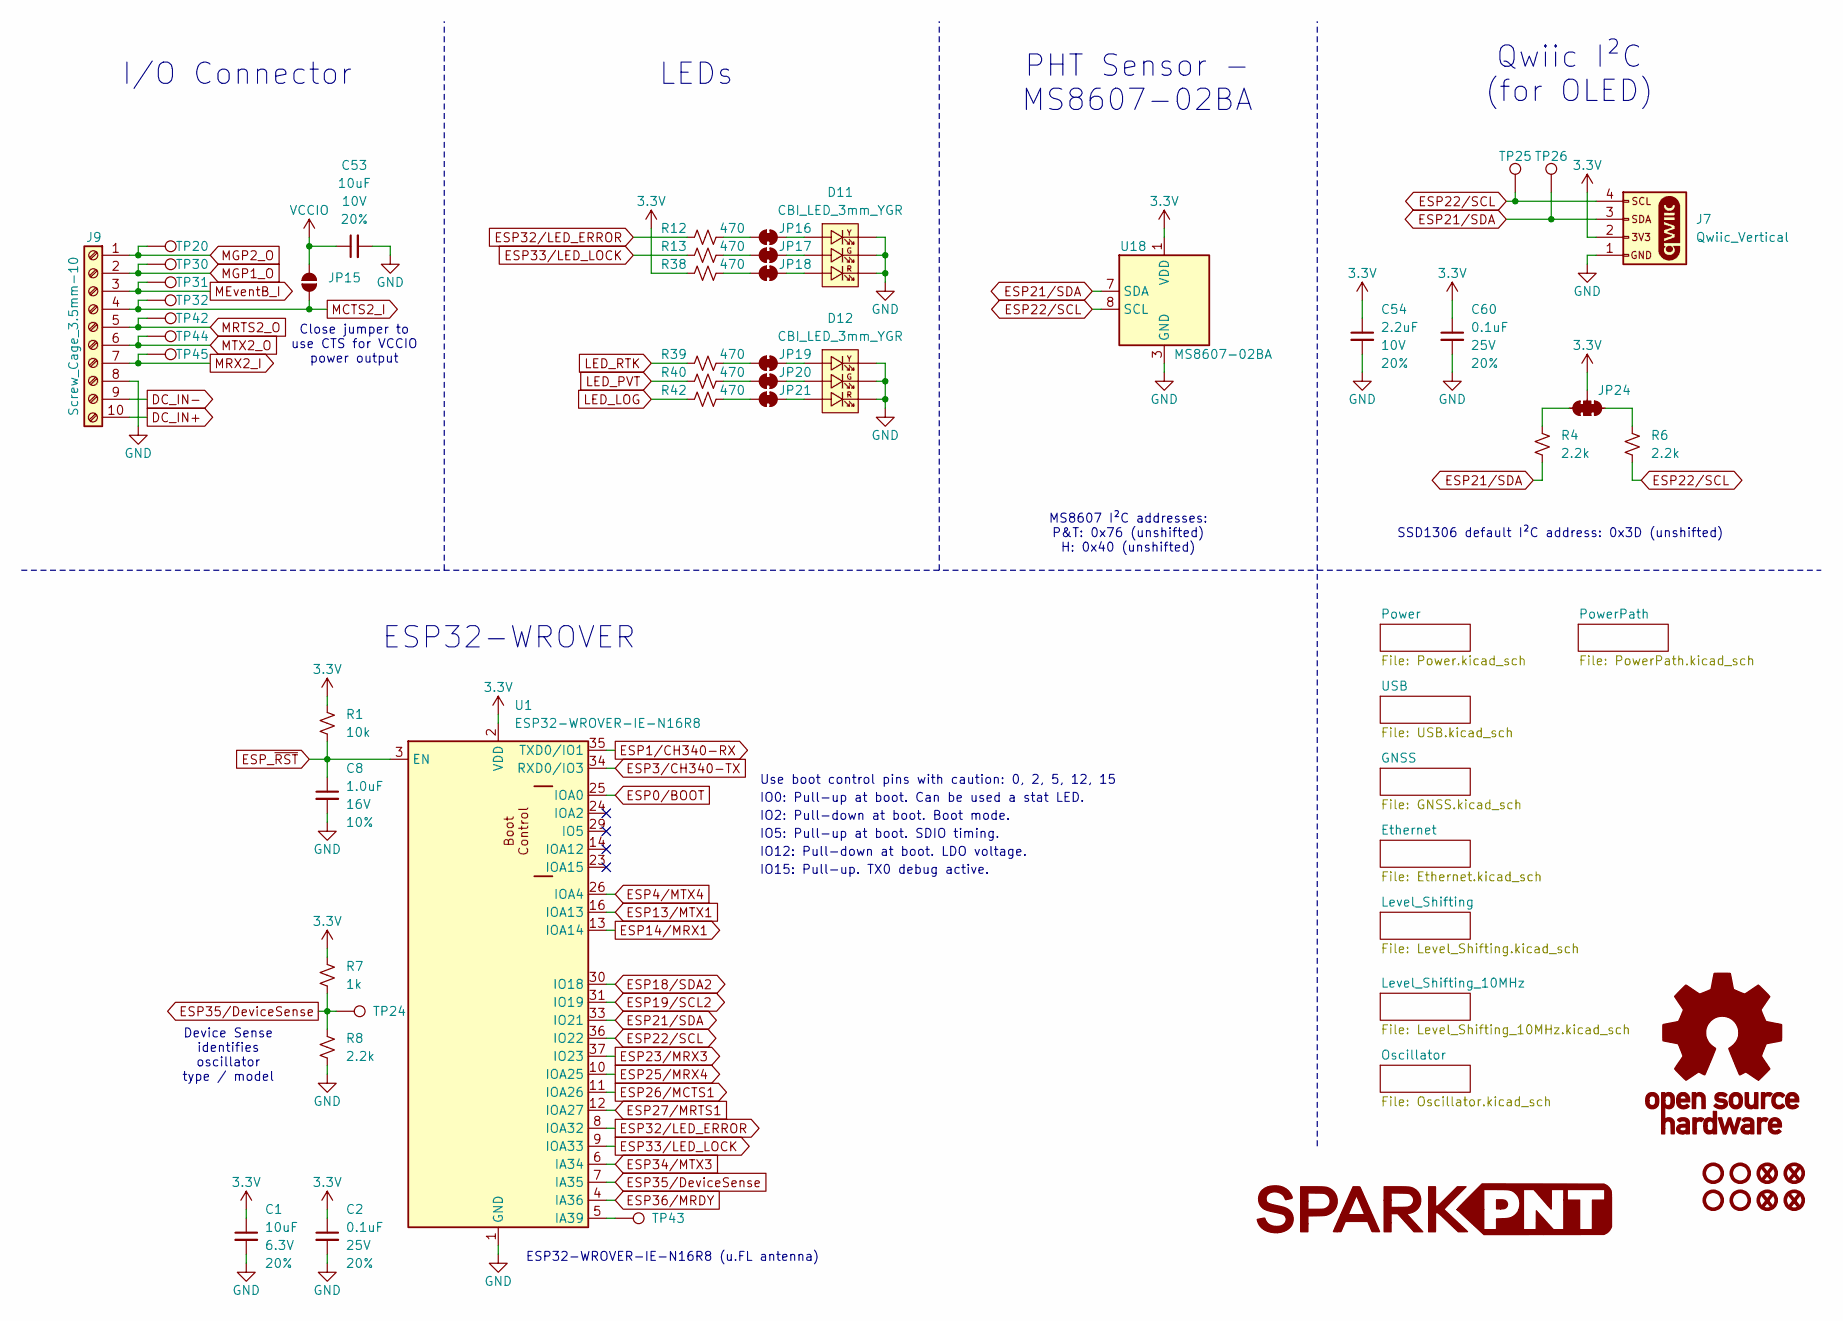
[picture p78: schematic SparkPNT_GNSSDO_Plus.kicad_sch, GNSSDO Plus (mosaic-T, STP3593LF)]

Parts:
C1: 10uF; C_0603_1608Metric; Voltage 6.3V; Tolerance 20%
C2, C60: 0.1uF; C_0603_1608Metric; Voltage 25V; Tolerance 20%
C8: 1.0uF; C_0603_1608Metric; Voltage 16V; Tolerance 10%
C53: 10uF; C_0603_1608Metric; Voltage 10V; Tolerance 20%
C54: 2.2uF; C_0603_1608Metric; Voltage 10V; Tolerance 20%
D11, D12: CBI_LED_3mm_YGR; CBI_LED_Triple_3mm_PTH
FID1, FID2, FID3, FID4: Fiducial_0.5mm; Fiducial_0.5mm_Mask1mm
G1: OSHW_Logo; Creative_Commons_License
G2: LOGO
J7: Qwiic_Vertical; JST_1x04_P1.0mm_Vertical_SMD
J9: Screw_Cage_3.5mm-10; ScrewCage_1x10_P3.5mm_Horizontal
JP15: Jumper_2_NO
JP16, JP17, JP18, JP19, JP20, JP21: Jumper_2_NC_Trace
JP24: Jumper_3_NC-2_Trace
R1: 10k; R_0603_1608Metric
R4, R6, R8: 2.2k; R_0603_1608Metric
R7: 1k; R_0603_1608Metric
R12, R13, R38, R39, R40, R42: 470; R_0603_1608Metric
ST1, ST2, ST3, ST4: Standoff
TP20, TP30, TP31, TP32, TP42, TP44, TP45: 1.25mm; TestPoint-1.25mm
TP24, TP25, TP26, TP43: PTH; 1x01_P2.54mm
U1: ESP32-WROVER-IE-N16R8; ESP32-WROVER-E-IE
U18: MS8607-02BA; LGA-8_3x5mm_P1.25mm

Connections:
3.3V: C1.1, C2.1, C54.1, C60.1, J7.2, JP24.2 (B), R1.2, R7.2, R38.1, U1.2 (VDD), U18.1 (VDD); also elsewhere on the board
DC_IN+: J9.10 (Pin_1); also elsewhere on the board
DC_IN-: J9.9 (Pin_1); also elsewhere on the board
ESP0/BOOT: U1.25 (IOA0); also elsewhere on the board
ESP1/CH340-RX: U1.35 (TXD0/IO1); also elsewhere on the board
ESP3/CH340-TX: U1.34 (RXD0/IO3); also elsewhere on the board
ESP4/MTX4: U1.26 (IOA4); also elsewhere on the board
ESP13/MTX1: U1.16 (IOA13); also elsewhere on the board
ESP14/MRX1: U1.13 (IOA14); also elsewhere on the board
ESP18/SDA2: U1.30 (IO18); also elsewhere on the board
ESP19/SCL2: U1.31 (IO19); also elsewhere on the board
ESP21/SDA: J7.3, R4.2, TP26.1, U1.33 (IO21), U18.7 (SDA)
ESP22/SCL: J7.4, R6.2, TP25.1, U1.36 (IO22), U18.8 (SCL)
ESP23/MRX3: U1.37 (IO23); also elsewhere on the board
ESP25/MRX4: U1.10 (IOA25); also elsewhere on the board
ESP26/MCTS1: U1.11 (IOA26); also elsewhere on the board
ESP27/MRTS1: U1.12 (IOA27); also elsewhere on the board
ESP32/LED_ERROR: R12.1, U1.8 (IOA32)
ESP33/LED_LOCK: R13.1, U1.9 (IOA33)
ESP34/MTX3: U1.6 (IA34); also elsewhere on the board
ESP35/DeviceSense: R7.1, R8.1, TP24.1, U1.7 (IA35)
ESP36/MRDY: U1.4 (IA36); also elsewhere on the board
ESP_~RST: C8.1, R1.1, U1.3 (EN); also elsewhere on the board
GND: C1.2, C2.2, C8.2, C53.2, C54.2, C60.2, D11.CATHODE_1, D11.CATHODE_2, D11.CATHODE_3, D12.CATHODE_1, D12.CATHODE_2, D12.CATHODE_3, J7.1, J9.8 (Pin_1), R8.2, U1.1 (GND), U1.15 (GND), U1.38 (GND), U1.39.1 (GND), U1.39.2 (GND), U1.39.3 (GND), U1.39.4 (GND), U1.39.5 (GND), U1.39.6 (GND), U1.39.7 (GND), U1.39.8 (GND), U1.39.9 (GND), U18.3 (GND); also elsewhere on the board
LED_LOG: R42.1; also elsewhere on the board
LED_PVT: R40.1; also elsewhere on the board
LED_RTK: R39.1; also elsewhere on the board
MCTS2_I: J9.4, JP15.1 (A), TP32.1; also elsewhere on the board
MEventB_I: J9.3, TP31.1; also elsewhere on the board
MGP1_O: J9.2, TP30.1; also elsewhere on the board
MGP2_O: J9.1, TP20.1; also elsewhere on the board
MRTS2_O: J9.5 (Pin_3), TP42.1; also elsewhere on the board
MRX2_I: J9.7 (Pin_2), TP45.1; also elsewhere on the board
MTX2_O: J9.6 (Pin_4), TP44.1; also elsewhere on the board
unnamed: JP16.1 (A), R12.2
unnamed: D11.ANODE_1, JP16.2 (B)
unnamed: JP17.1 (A), R13.2
unnamed: D11.ANODE_2, JP17.2 (B)
unnamed: JP18.1 (A), R38.2
unnamed: D11.ANODE_3, JP18.2 (B)
unnamed: JP19.1 (A), R39.2
unnamed: D12.ANODE_1, JP19.2 (B)
unnamed: JP20.1 (A), R40.2
unnamed: D12.ANODE_2, JP20.2 (B)
unnamed: JP21.1 (A), R42.2
unnamed: D12.ANODE_3, JP21.2 (B)
unnamed: JP24.1 (A), R6.1
unnamed: JP24.3 (C), R4.1
unnamed: TP43.1, U1.5 (IA39)
VCCIO: C53.1, JP15.2 (B); also elsewhere on the board

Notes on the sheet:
IO15: Pull-up. TX0 debug active.
IO2: Pull-down at boot. Boot mode.
ESP32-WROVER
IO0: Pull-up at boot. Can be used a stat LED.
SSD1306 default I²C address: 0x3D (unshifted)
LEDs
Qwiic I²C (for OLED)
Device Sense identifies oscillator type / model
Close jumper to use CTS for VCCIO power output
PHT Sensor - MS8607-02BA
IO5: Pull-up at boot. SDIO timing.
MS8607 I²C addresses: P&T: 0x76 (unshifted) H: 0x40 (unshifted)
I/O Connector
Use boot control pins with caution: 0, 2, 5, 12, 15
ESP32-WROVER-IE-N16R8 (u.FL antenna)
IO12: Pull-down at boot. LDO voltage.

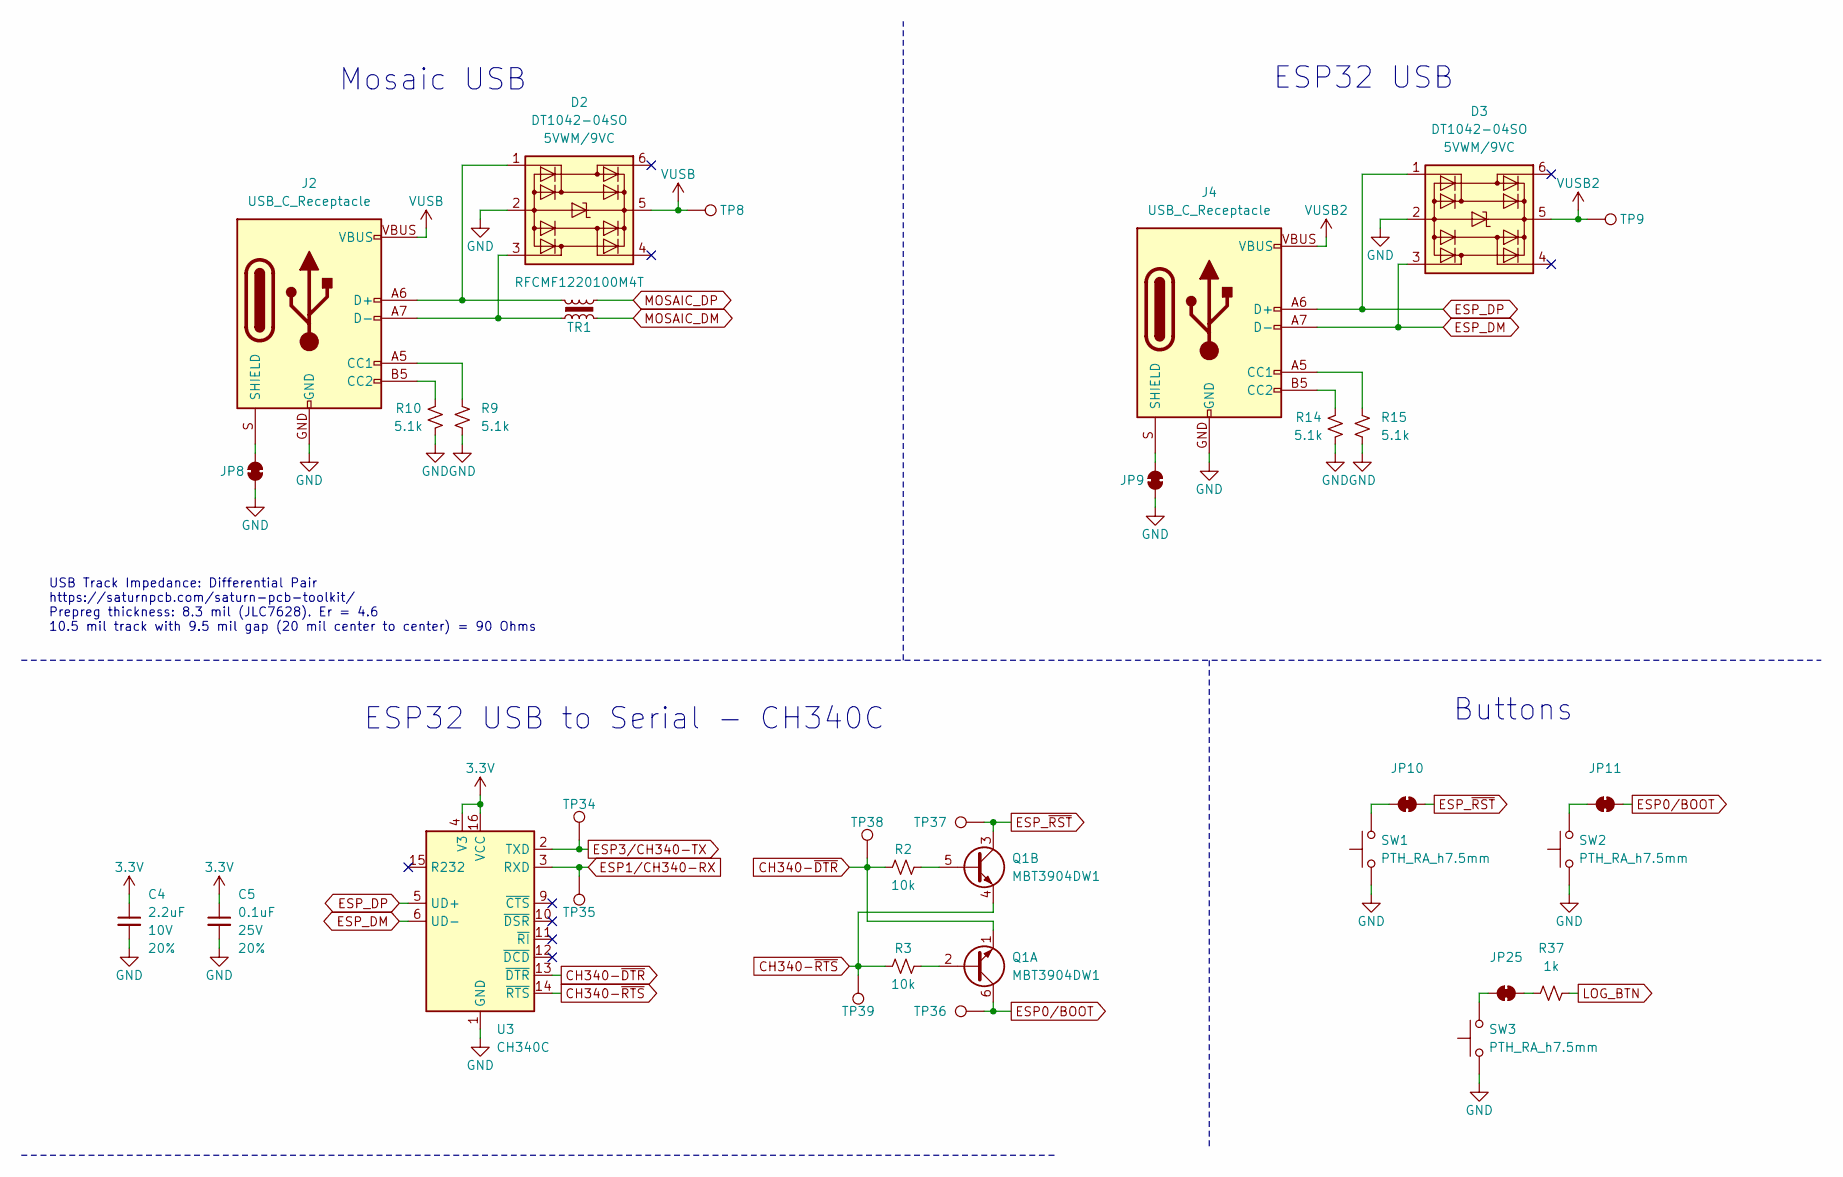
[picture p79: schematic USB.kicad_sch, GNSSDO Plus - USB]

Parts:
C4: 2.2uF; C_0603_1608Metric; Voltage 10V; Tolerance 20%
C5: 0.1uF; C_0603_1608Metric; Voltage 25V; Tolerance 20%
D2, D3: DT1042-04SO; SOT23-6; Rating 5VWM/9VC
J2, J4: USB_C_Receptacle; USB-C_16
JP8, JP9, JP10, JP11, JP25: Jumper_2_NC_Trace
Q1: MBT3904DW1; SOT-363_SC-70-6
R2, R3: 10k; R_0603_1608Metric
R9, R10, R14, R15: 5.1k; R_0603_1608Metric
R37: 1k; R_0603_1608Metric
SW1, SW2, SW3: PTH_RA_h7.5mm; Push_PTH_RA_8-020_h7.5mm; Mfg Part# 8-020 TS H = 7.5mm
TP8, TP9, TP34, TP35, TP36, TP37, TP38, TP39: PTH; 1x01_P2.54mm
TR1: RFCMF1220100M4T; Choke_100MHz_USB
U3: CH340C; SO-16

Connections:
3.3V: C4.1, C5.1, U3.4 (V3), U3.16 (VCC); also elsewhere on the board
CH340-~DTR: Q1.1 (E1), R2.1, TP38.1, U3.13 (~DTR)
CH340-~RTS: Q1.4 (E2), R3.1, TP39.1, U3.14 (~RTS)
ESP0/BOOT: JP11.2 (B), Q1.6 (C1), TP36.1; also elsewhere on the board
ESP1/CH340-RX: TP35.1, U3.3 (RXD); also elsewhere on the board
ESP3/CH340-TX: TP34.1, U3.2 (TXD); also elsewhere on the board
ESP_DM: D3.3 (I/O2), J4.A7 (D-), J4.B7 (D-), U3.6 (UD-)
ESP_DP: D3.1 (I/O1), J4.A6 (D+), J4.B6 (D+), U3.5 (UD+)
ESP_~RST: JP10.2 (B), Q1.3 (C2), TP37.1; also elsewhere on the board
GND: C4.2, C5.2, D2.2 (GND), D3.2 (GND), J2.GND, J4.GND, JP8.1 (A), JP9.1 (A), R9.2, R10.2, R14.2, R15.2, SW1.1, SW2.1, SW3.1, U3.1 (GND); also elsewhere on the board
LOG_BTN: R37.2; also elsewhere on the board
MOSAIC_DM: TR1.2; also elsewhere on the board
MOSAIC_DP: TR1.4; also elsewhere on the board
unnamed: D2.1 (I/O1), J2.A6 (D+), J2.B6 (D+), TR1.3
unnamed: D2.3 (I/O2), J2.A7 (D-), J2.B7 (D-), TR1.1
unnamed: J2.A5 (CC1), R9.1
unnamed: J2.B5 (CC2), R10.1
unnamed: J2.S (SHIELD), JP8.2 (B)
unnamed: J4.A5 (CC1), R15.1
unnamed: J4.B5 (CC2), R14.1
unnamed: J4.S (SHIELD), JP9.2 (B)
unnamed: JP10.1 (A), SW1.2
unnamed: JP11.1 (A), SW2.2
unnamed: JP25.1 (A), SW3.2
unnamed: JP25.2 (B), R37.1
unnamed: Q1.2 (B1), R3.2
unnamed: Q1.5 (B2), R2.2
VUSB: D2.5 (VCC), J2.VBUS, TP8.1; also elsewhere on the board
VUSB2: D3.5 (VCC), J4.VBUS, TP9.1; also elsewhere on the board

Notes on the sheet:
ESP32 USB to Serial - CH340C
Mosaic USB
Buttons
ESP32 USB
USB Track Impedance: Differential Pair https://saturnpcb.com/saturn-pcb-toolkit/ Prepreg thickness: 8.3 mil (JLC7628). Er = 4.6 10.5 mil track with 9.5 mil gap (20 mil center to center) = 90 Ohms

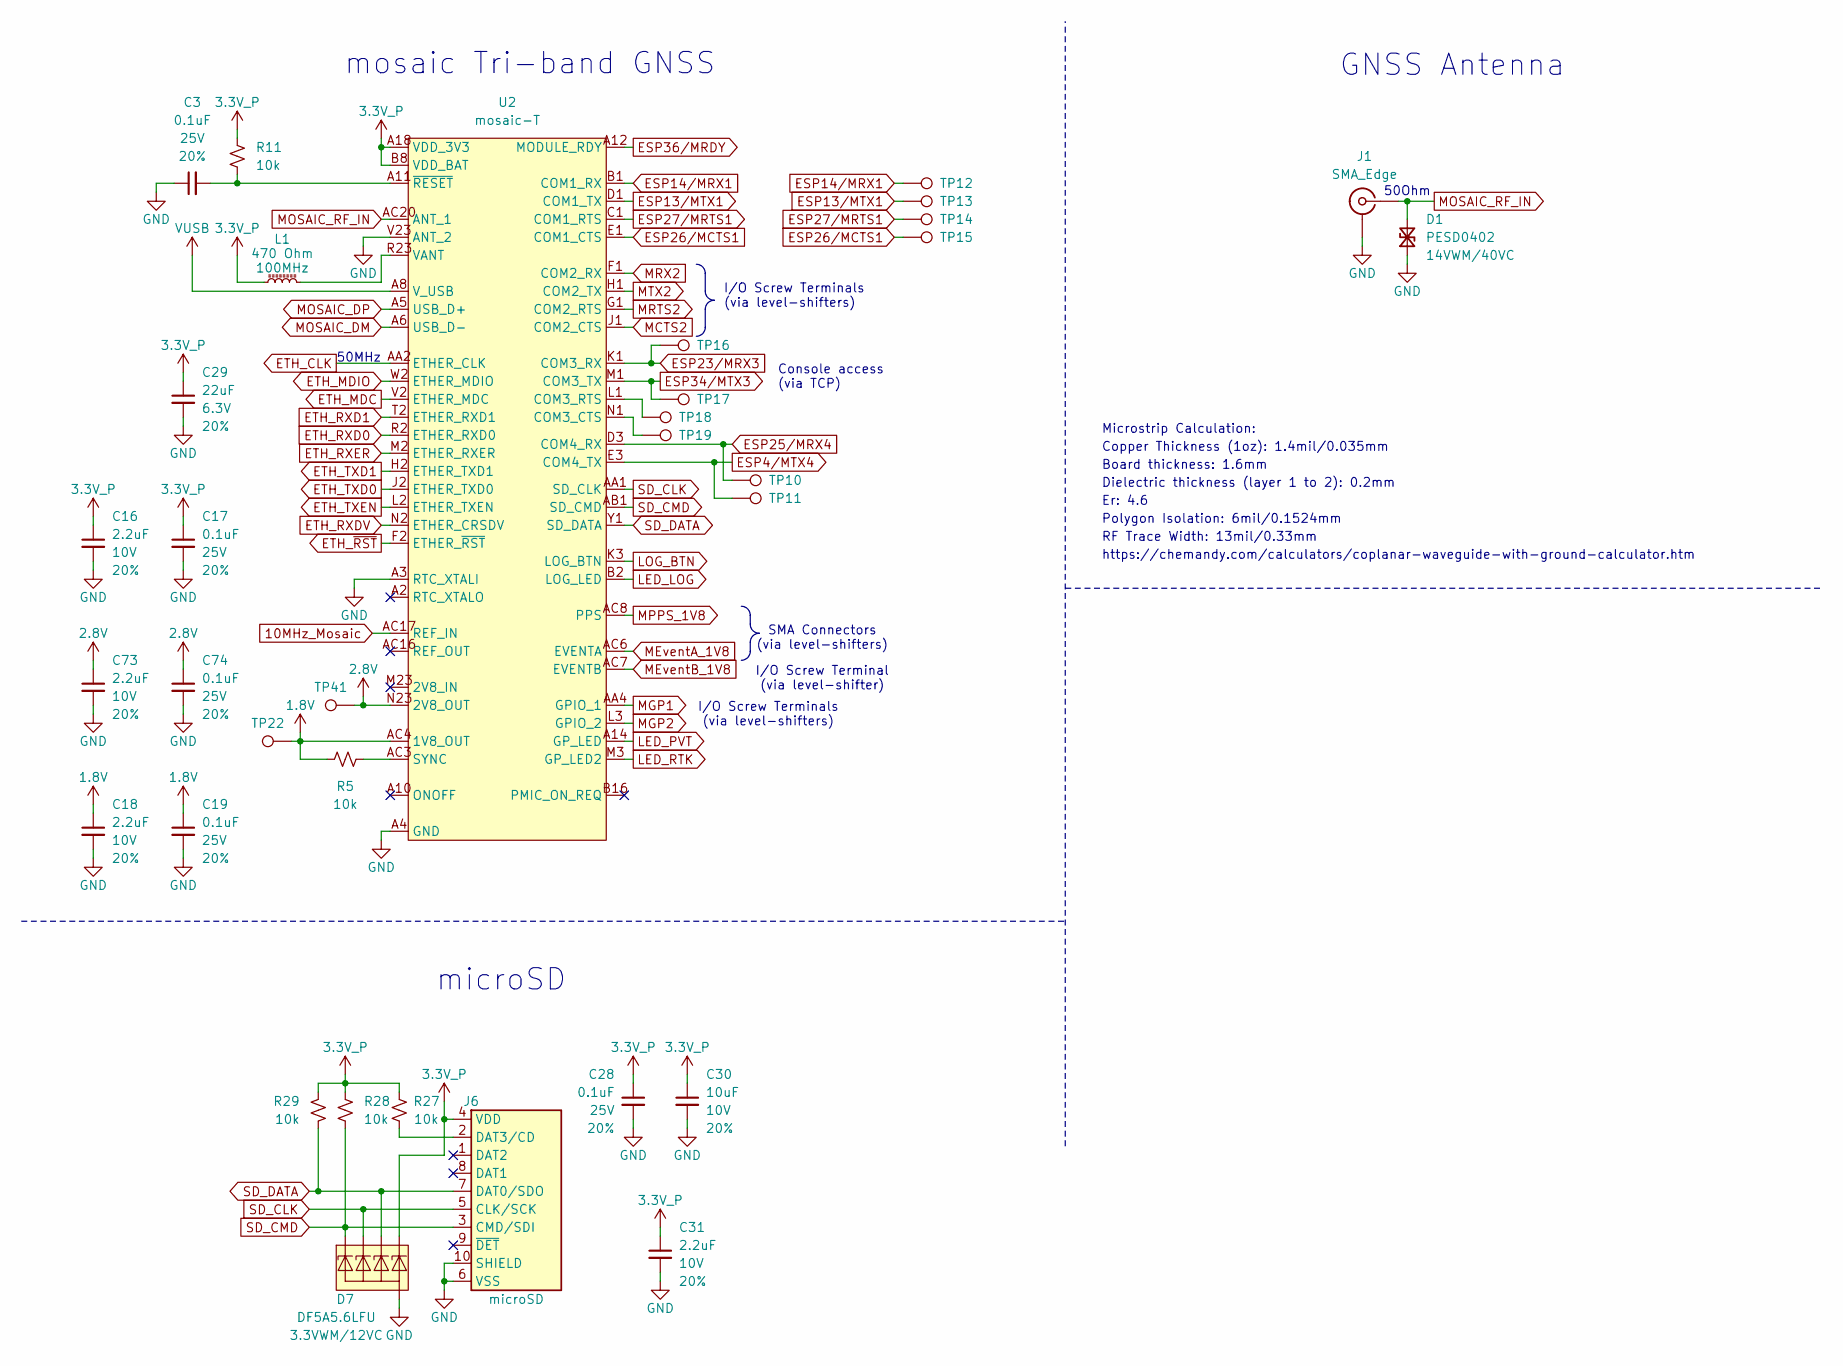
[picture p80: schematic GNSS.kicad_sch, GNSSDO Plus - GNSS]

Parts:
C3, C17, C19, C28, C74: 0.1uF; C_0603_1608Metric; Voltage 25V; Tolerance 20%
C16, C18, C31, C73: 2.2uF; C_0603_1608Metric; Voltage 10V; Tolerance 20%
C29: 22uF; C_0603_1608Metric; Voltage 6.3V; Tolerance 20%
C30: 10uF; C_0603_1608Metric; Voltage 10V; Tolerance 20%
D1: PESD0402; C_0402_1005Metric; Rating 14VWM/40VC
D7: DF5A5.6LFU; SOT-353; Rating 3.3VWM/12VC
J1: SMA_Edge; SMA_Edge_6.3mm
J6: microSD; microSD_External_Pin
L1: 470 Ohm; C_0603_1608Metric
R5, R11, R27, R28, R29: 10k; R_0603_1608Metric
TP10, TP11, TP12, TP13, TP14, TP15, TP16, TP17, TP18, TP19, TP22, TP41: PTH; 1x01_P2.54mm
U2: mosaic-T; Septentrio_mosaic_LGA

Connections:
1.8V: C18.1, C19.1, R5.1, TP22.1, U2.AC4 (1V8_OUT); also elsewhere on the board
2.8V: C73.1, C74.1, TP41.1, U2.N23 (2V8_OUT); also elsewhere on the board
3.3V_P: C16.1, C17.1, C28.1, C29.1, C30.1, C31.1, D7.5 (K4), J6.4 (VDD), L1.1, R11.1, R27.1, R28.1, R29.1, U2.A18 (VDD_3V3), U2.A19 (VDD_3V3), U2.A20 (VDD_3V3), U2.B8 (VDD_BAT), U2.B18 (VDD_3V3), U2.B19 (VDD_3V3), U2.B20 (VDD_3V3), U2.C18 (VDD_3V3), U2.C19 (VDD_3V3), U2.C20 (VDD_3V3); also elsewhere on the board
10MHz_Mosaic: U2.AC17 (REF_IN); also elsewhere on the board
ESP4/MTX4: TP11.1, U2.E3 (COM4_TX); also elsewhere on the board
ESP13/MTX1: TP13.1, U2.D1 (COM1_TX); also elsewhere on the board
ESP14/MRX1: TP12.1, U2.B1 (COM1_RX); also elsewhere on the board
ESP23/MRX3: TP16.1, U2.K1 (COM3_RX); also elsewhere on the board
ESP25/MRX4: TP10.1, U2.D3 (COM4_RX); also elsewhere on the board
ESP26/MCTS1: TP15.1, U2.E1 (COM1_CTS); also elsewhere on the board
ESP27/MRTS1: TP14.1, U2.C1 (COM1_RTS); also elsewhere on the board
ESP34/MTX3: TP17.1, U2.M1 (COM3_TX); also elsewhere on the board
ESP36/MRDY: U2.A12 (MODULE_RDY); also elsewhere on the board
ETH_CLK: U2.AA2 (ETHER_CLK); also elsewhere on the board
ETH_MDC: U2.V2 (ETHER_MDC); also elsewhere on the board
ETH_MDIO: U2.W2 (ETHER_MDIO); also elsewhere on the board
ETH_RXD0: U2.R2 (ETHER_RXD0); also elsewhere on the board
ETH_RXD1: U2.T2 (ETHER_RXD1); also elsewhere on the board
ETH_RXDV: U2.N2 (ETHER_CRSDV); also elsewhere on the board
ETH_RXER: U2.M2 (ETHER_RXER); also elsewhere on the board
ETH_TXD0: U2.J2 (ETHER_TXD0); also elsewhere on the board
ETH_TXD1: U2.H2 (ETHER_TXD1); also elsewhere on the board
ETH_TXEN: U2.L2 (ETHER_TXEN); also elsewhere on the board
ETH_~RST: U2.F2 (ETHER_~RST); also elsewhere on the board
GND: C3.1, C16.2, C17.2, C18.2, C19.2, C28.2, C29.2, C30.2, C31.2, C73.2, C74.2, D1.1 (A1), D7.2 (A), J1.2 (Ext), J6.6 (VSS), J6.10 (SHIELD), U2.A3 (RTC_XTALI), U2.A4 (GND), U2.A7 (GND), U2.A15 (GND), U2.A16 (GND), U2.A17 (GND), U2.A21 (GND), U2.A22 (GND), U2.A23 (GND), U2.AA13 (GND), U2.AA14 (GND), U2.AA15 (GND), U2.AA16 (GND), U2.AA17 (GND), U2.AA18 (GND), U2.AA19 (GND), U2.AA20 (GND), U2.AA21 (GND), U2.AA22 (GND), U2.AA23 (GND), U2.AB2 (GND), U2.AB3 (GND), U2.AB4 (GND), U2.AB5 (GND), U2.AB6 (GND), U2.AB7 (GND), U2.AB8 (GND), U2.AB13 (GND), U2.AB14 (GND), U2.AB15 (GND), U2.AB16 (GND), U2.AB17 (GND), U2.AB18 (GND), U2.AB19 (GND), U2.AB20 (GND), U2.AB21 (GND), U2.AB22 (GND), U2.AB23 (GND), U2.AC13 (GND), U2.AC15 (GND), U2.AC18 (GND), U2.AC19 (GND), U2.AC21 (GND), U2.AC22 (GND), U2.AC23 (GND), U2.B4 (GND), U2.B5 (GND), U2.B6 (GND), U2.B7 (GND), U2.B13 (GND), U2.B17 (GND), U2.B21 (GND), U2.C4 (GND), U2.C7 (GND), U2.C15 (GND), U2.C16 (GND), U2.C17 (GND), U2.C23 (GND), U2.D2 (GND), U2.D21 (GND), U2.D22 (GND), U2.D23 (GND), U2.E2 (GND), U2.E21 (GND), U2.E22 (GND), U2.E23 (GND), U2.F21 (GND), U2.F22 (GND), U2.F23 (GND), U2.G2 (GND), U2.G21 (GND), U2.G23 (GND), U2.H21 (GND), U2.H22 (GND), U2.H23 (GND), U2.J21 (GND), U2.J22 (GND), U2.J23 (GND), U2.K2 (GND), U2.K21 (GND), U2.K22 (GND), U2.K23 (GND), U2.L21 (GND), U2.L22 (GND), U2.L23 (GND), U2.M21 (GND), U2.M22 (GND), U2.N21 (GND), U2.N22 (GND), U2.P1 (GND), U2.P2 (GND), U2.P3 (GND), U2.P21 (GND), U2.P22 (GND), U2.R3 (GND), U2.R21 (GND), U2.R22 (GND), U2.T21 (GND), U2.T22 (GND), U2.T23 (GND), U2.U2 (GND), U2.U21 (GND), U2.U22 (GND), U2.U23 (GND), U2.V21 (GND), U2.V22 (GND), U2.V23 (ANT_2), U2.W21 (GND), U2.W22 (GND), U2.W23 (GND), U2.Y2 (GND), U2.Y21 (GND), U2.Y22 (GND), U2.Y23 (GND); also elsewhere on the board
LED_LOG: U2.B2 (LOG_LED); also elsewhere on the board
LED_PVT: U2.A14 (GP_LED); also elsewhere on the board
LED_RTK: U2.M3 (GP_LED2); also elsewhere on the board
LOG_BTN: U2.K3 (LOG_BTN); also elsewhere on the board
MCTS2: U2.J1 (COM2_CTS); also elsewhere on the board
MEventA_1V8: U2.AC6 (EVENTA); also elsewhere on the board
MEventB_1V8: U2.AC7 (EVENTB); also elsewhere on the board
MGP1: U2.AA4 (GPIO_1); also elsewhere on the board
MGP2: U2.L3 (GPIO_2); also elsewhere on the board
MOSAIC_DM: U2.A6 (USB_D-); also elsewhere on the board
MOSAIC_DP: U2.A5 (USB_D+); also elsewhere on the board
MOSAIC_RF_IN: D1.2 (A2), J1.1 (In), U2.AC20 (ANT_1)
MPPS_1V8: U2.AC8 (PPS); also elsewhere on the board
MRTS2: U2.G1 (COM2_RTS); also elsewhere on the board
MRX2: U2.F1 (COM2_RX); also elsewhere on the board
MTX2: U2.H1 (COM2_TX); also elsewhere on the board
unnamed: J6.2 (DAT3/CD), R27.2
unnamed: TP19.1, U2.N1 (COM3_CTS)
unnamed: TP18.1, U2.L1 (COM3_RTS)
unnamed: R5.2, U2.AC3 (SYNC)
unnamed: C3.2, R11.2, U2.A11 (~RESET)
SD_CLK: D7.3 (K2), J6.5 (CLK/SCK), U2.AA1 (SD_CLK)
SD_CMD: D7.1 (K1), J6.3 (CMD/SDI), R28.2, U2.AB1 (SD_CMD)
SD_DATA: D7.4 (K3), J6.7 (DAT0/SDO), R29.2, U2.Y1 (SD_DATA)
VANT: L1.2, U2.P23 (VANT), U2.R23 (VANT)
VUSB: U2.A8 (V_USB); also elsewhere on the board

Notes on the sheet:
Er: 4.6
Polygon Isolation: 6mil/0.1524mm
Console access (via TCP)
SMA Connectors (via level-shifters)
Dielectric thickness (layer 1 to 2): 0.2mm
Board thickness: 1.6mm
mosaic Tri-band GNSS
Microstrip Calculation:
50Ohm
I/O Screw Terminals (via level-shifters)
https://chemandy.com/calculators/coplanar-waveguide-with-ground-calculator.htm
Copper Thickness (1oz): 1.4mil/0.035mm
I/O Screw Terminal (via level-shifter)
50MHz
GNSS Antenna
microSD
RF Trace Width: 13mil/0.33mm

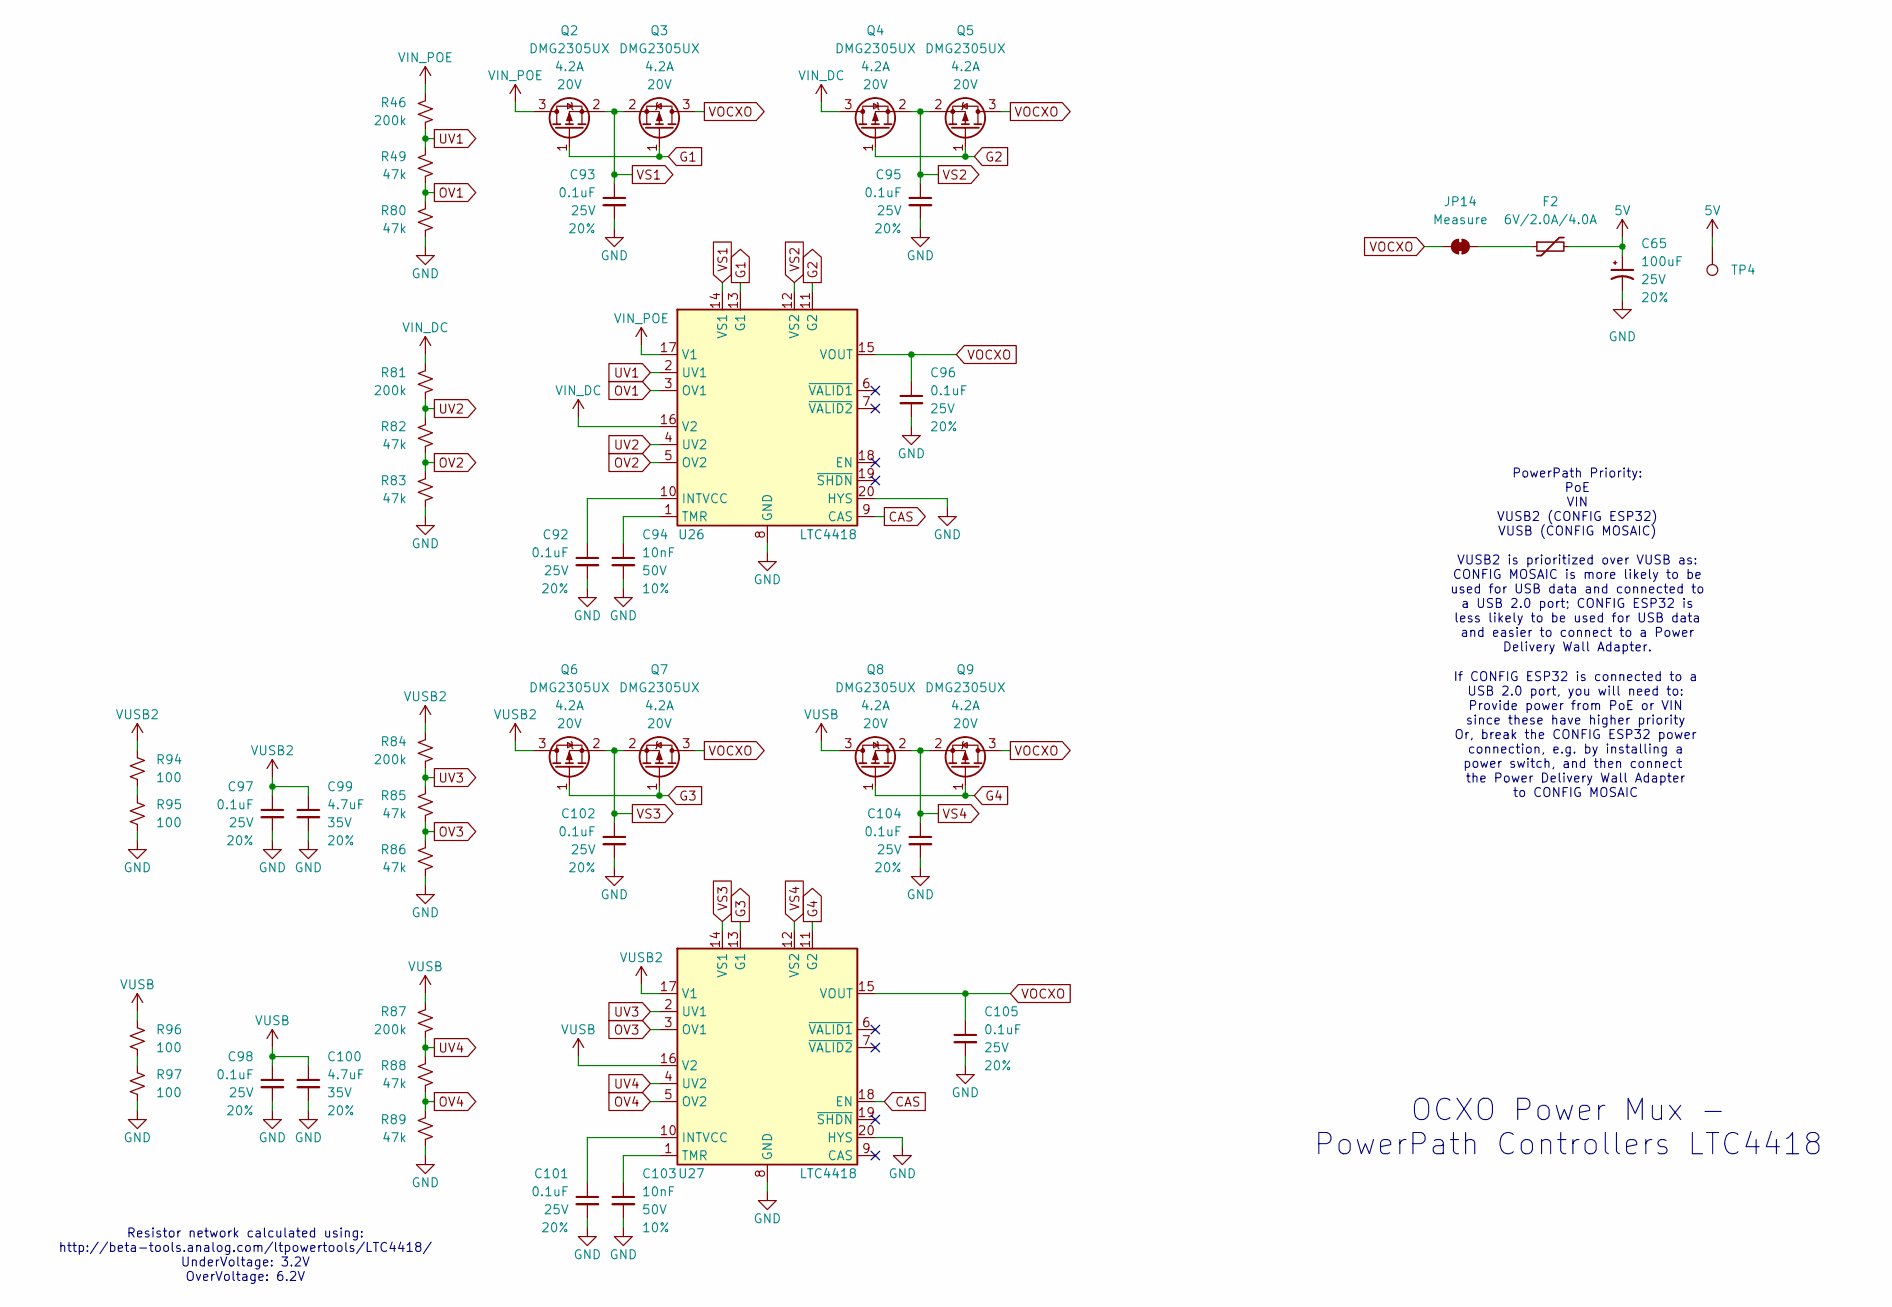
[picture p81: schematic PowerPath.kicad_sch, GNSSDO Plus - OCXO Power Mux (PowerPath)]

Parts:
C65: 100uF; Panasonic_D; Voltage 25V; Tolerance 20%
C92, C93, C95, C96, C97, C98, C101, C102, C104, C105: 0.1uF; C_0603_1608Metric; Voltage 25V; Tolerance 20%
C94, C103: 10nF; C_0603_1608Metric; Voltage 50V; Tolerance 10%
C99, C100: 4.7uF; C_0603_1608Metric; Voltage 35V; Tolerance 20%
F2: 6V/2.0A/4.0A; 1210
JP14: Measure; Jumper_2_PTH_SMD_Combo-NC
Q2, Q3, Q4, Q5, Q6, Q7, Q8, Q9: DMG2305UX; SOT23-3
R46, R81, R84, R87: 200k; R_0603_1608Metric
R49, R80, R82, R83, R85, R86, R88, R89: 47k; R_0603_1608Metric
R94, R95, R96, R97: 100; R_0603_1608Metric
TP4: PTH; 1x01_P2.54mm
U26, U27: LTC4418; QFN-20-1EP_4x4mm_P0.5mm_EP2.45x2.45mm

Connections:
5V: C65.1, F2.2, TP4.1; also elsewhere on the board
CAS: U26.9 (CAS), U27.18 (EN)
G1: Q2.1 (G), Q3.1 (G), U26.13 (G1)
G2: Q4.1 (G), Q5.1 (G), U26.11 (G2)
G3: Q6.1 (G), Q7.1 (G), U27.13 (G1)
G4: Q8.1 (G), Q9.1 (G), U27.11 (G2)
GND: C65.2, C92.2, C93.2, C94.2, C95.2, C96.2, C97.2, C98.2, C99.2, C100.2, C101.2, C102.2, C103.2, C104.2, C105.2, R80.1, R83.1, R86.1, R89.1, R95.1, R97.1, U26.8 (GND), U26.20 (HYS), U26.21 (GND), U27.8 (GND), U27.20 (HYS), U27.21 (GND); also elsewhere on the board
unnamed: F2.1, JP14.2 (B)
unnamed: R94.1, R95.2
unnamed: R96.1, R97.2
unnamed: C92.1, U26.10 (INTVCC)
unnamed: C94.1, U26.1 (TMR)
unnamed: C101.1, U27.10 (INTVCC)
unnamed: C103.1, U27.1 (TMR)
OV1: R49.1, R80.2, U26.3 (OV1)
OV2: R82.1, R83.2, U26.5 (OV2)
OV3: R85.1, R86.2, U27.3 (OV1)
OV4: R88.1, R89.2, U27.5 (OV2)
UV1: R46.1, R49.2, U26.2 (UV1)
UV2: R81.1, R82.2, U26.4 (UV2)
UV3: R84.1, R85.2, U27.2 (UV1)
UV4: R87.1, R88.2, U27.4 (UV2)
VIN_DC: Q4.3 (D), R81.2, U26.16 (V2); also elsewhere on the board
VIN_POE: Q2.3 (D), R46.2, U26.17 (V1); also elsewhere on the board
VOCXO: C96.1, C105.1, JP14.1 (A), Q3.3 (D), Q5.3 (D), Q7.3 (D), Q9.3 (D), U26.15 (VOUT), U27.15 (VOUT)
VS1: C93.1, Q2.2 (S), Q3.2 (S), U26.14 (VS1)
VS2: C95.1, Q4.2 (S), Q5.2 (S), U26.12 (VS2)
VS3: C102.1, Q6.2 (S), Q7.2 (S), U27.14 (VS1)
VS4: C104.1, Q8.2 (S), Q9.2 (S), U27.12 (VS2)
VUSB: C98.1, C100.1, Q8.3 (D), R87.2, R96.2, U27.16 (V2); also elsewhere on the board
VUSB2: C97.1, C99.1, Q6.3 (D), R84.2, R94.2, U27.17 (V1); also elsewhere on the board

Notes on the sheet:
OCXO Power Mux - PowerPath Controllers LTC4418
Resistor network calculated using: http://beta-tools.analog.com/ltpowertools/LTC4418/ UnderVoltage: 3.2V OverVoltage: 6.2V
If CONFIG ESP32 is connected to a USB 2.0 port, you will need to: Provide power from PoE or VIN since these have higher priority Or, break the CONFIG ESP32 power connection, e.g. by installing a , and then connect the Power Delivery Wall Adapter to CONFIG MOSAIC
power switch
PowerPath Priority: PoE VIN VUSB2 (CONFIG ESP32) VUSB (CONFIG MOSAIC) VUSB2 is prioritized over VUSB as: CONFIG MOSAIC is more likely to be used for USB data and connected to a USB 2.0 port; CONFIG ESP32 is less likely to be used for USB data and easier to connect to a Power Delivery Wall Adapter.

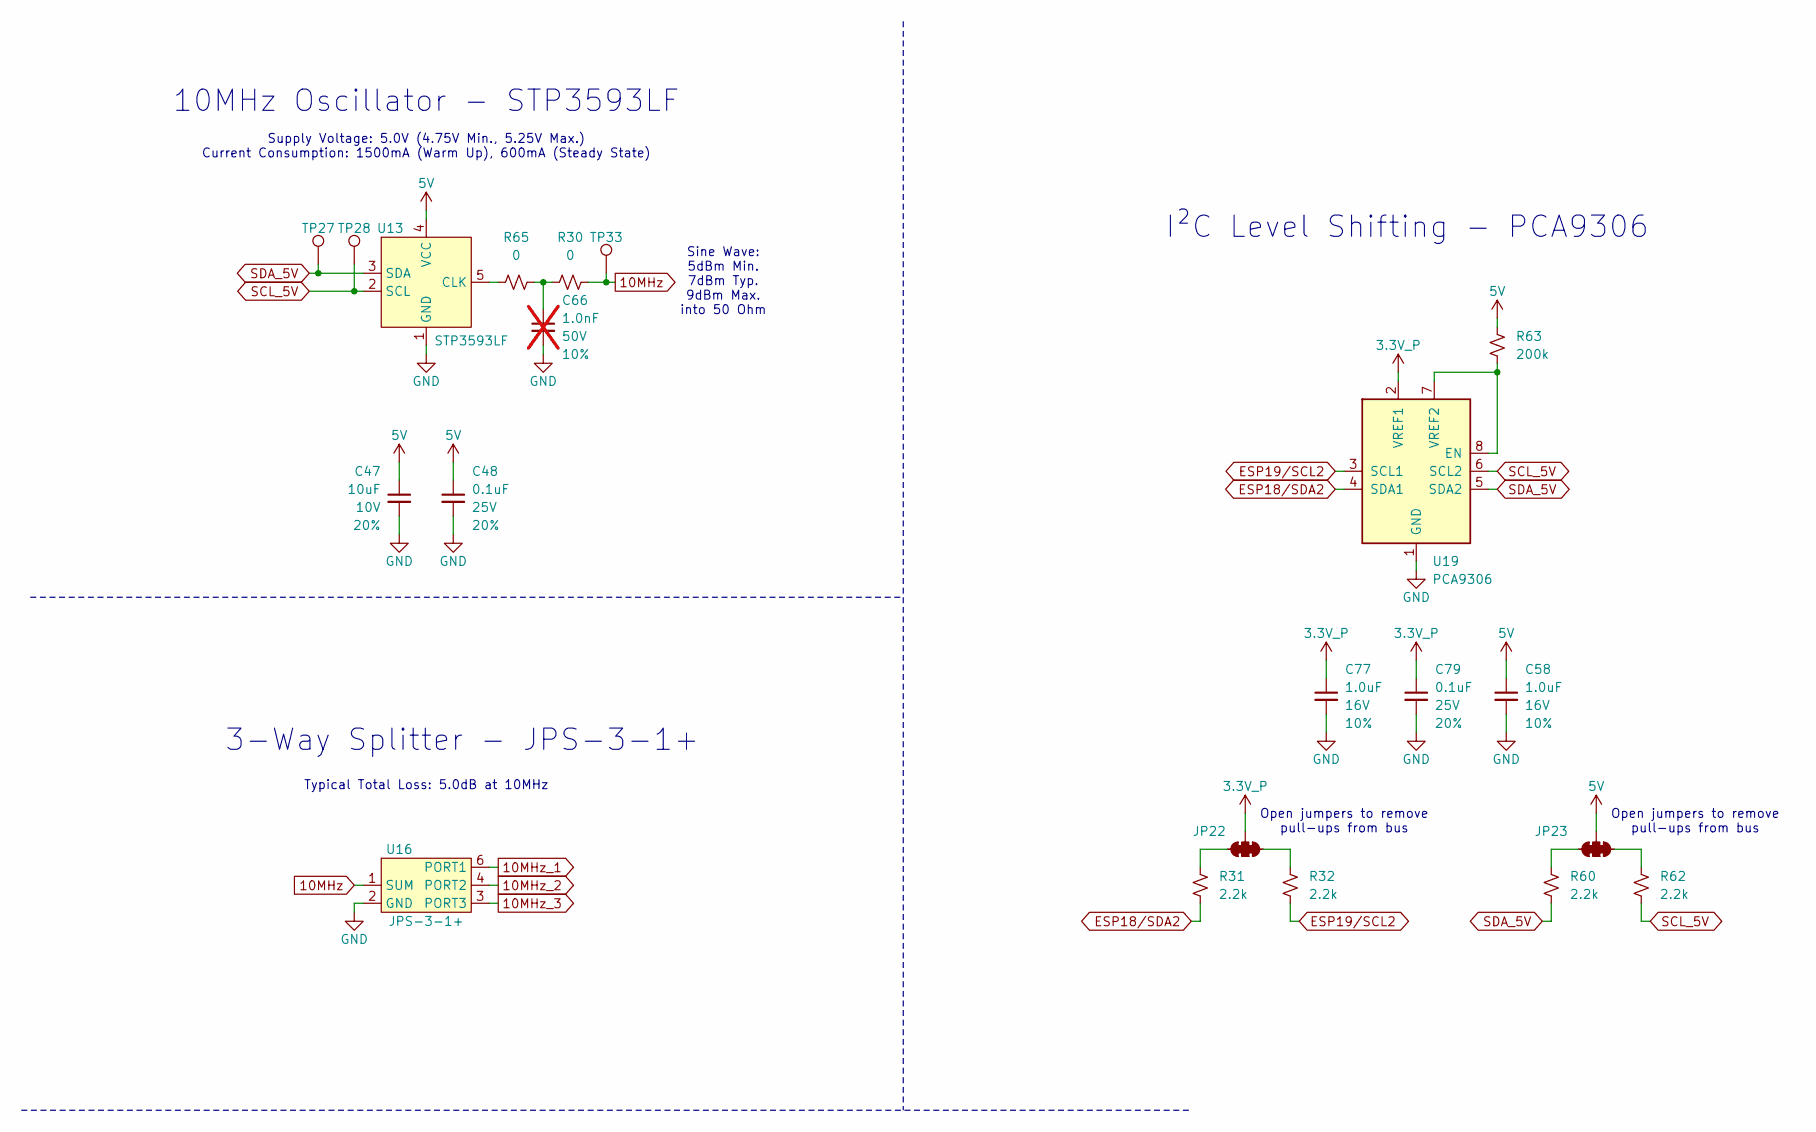
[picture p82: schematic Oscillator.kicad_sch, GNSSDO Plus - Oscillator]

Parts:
C47: 10uF; C_0603_1608Metric; Voltage 10V; Tolerance 20%
C48, C79: 0.1uF; C_0603_1608Metric; Voltage 25V; Tolerance 20%
C58, C77: 1.0uF; C_0603_1608Metric; Voltage 16V; Tolerance 10%
C66: 1.0nF; C_0603_1608Metric; Voltage 50V; Tolerance 10%; not fitted
JP22, JP23: Jumper_3_NC-2_Trace
R30, R65: 0; R_0603_1608Metric
R31, R32, R60, R62: 2.2k; R_0603_1608Metric
R63: 200k; R_0603_1608Metric
TP27, TP28, TP33: PTH; 1x01_P2.54mm
U13: STP3593LF; OCXO_PTH_51.3x41.3x14.2mm
U16: JPS-3-1+; Mini-Circuits_BH292
U19: PCA9306; VSSOP8_SOT765-1

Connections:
3.3V_P: C77.1, C79.1, JP22.2 (B), U19.2 (VREF1); also elsewhere on the board
5V: C47.1, C48.1, C58.1, JP23.2 (B), R63.1, U13.4 (VCC); also elsewhere on the board
10MHz: R30.2, TP33.1, U16.1 (SUM)
10MHz_1: U16.6 (PORT1); also elsewhere on the board
10MHz_2: U16.4 (PORT2); also elsewhere on the board
10MHz_3: U16.3 (PORT3); also elsewhere on the board
ESP18/SDA2: R31.1, U19.4 (SDA1); also elsewhere on the board
ESP19/SCL2: R32.1, U19.3 (SCL1); also elsewhere on the board
GND: C47.2, C48.2, C58.2, C66.2, C77.2, C79.2, U13.1 (GND), U16.2 (GND), U16.5 (GND), U19.1 (GND); also elsewhere on the board
unnamed: C66.1, R30.1, R65.2
unnamed: JP22.1 (A), R32.2
unnamed: JP22.3 (C), R31.2
unnamed: JP23.1 (A), R62.1
unnamed: JP23.3 (C), R60.1
unnamed: R65.1, U13.5 (CLK)
unnamed: R63.2, U19.7 (VREF2), U19.8 (EN)
SCL_5V: R62.2, TP28.1, U13.2 (SCL), U19.6 (SCL2)
SDA_5V: R60.2, TP27.1, U13.3 (SDA), U19.5 (SDA2)

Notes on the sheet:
Open jumpers to remove pull-ups from bus
Typical Total Loss: 5.0dB at 10MHz
Supply Voltage: 5.0V (4.75V Min., 5.25V Max.) Current Consumption: 1500mA (Warm Up), 600mA (Steady State)
10MHz Oscillator - STP3593LF
3-Way Splitter - JPS-3-1+
Sine Wave: 5dBm Min. 7dBm Typ. 9dBm Max. into 50 Ohm
I²C Level Shifting - PCA9306

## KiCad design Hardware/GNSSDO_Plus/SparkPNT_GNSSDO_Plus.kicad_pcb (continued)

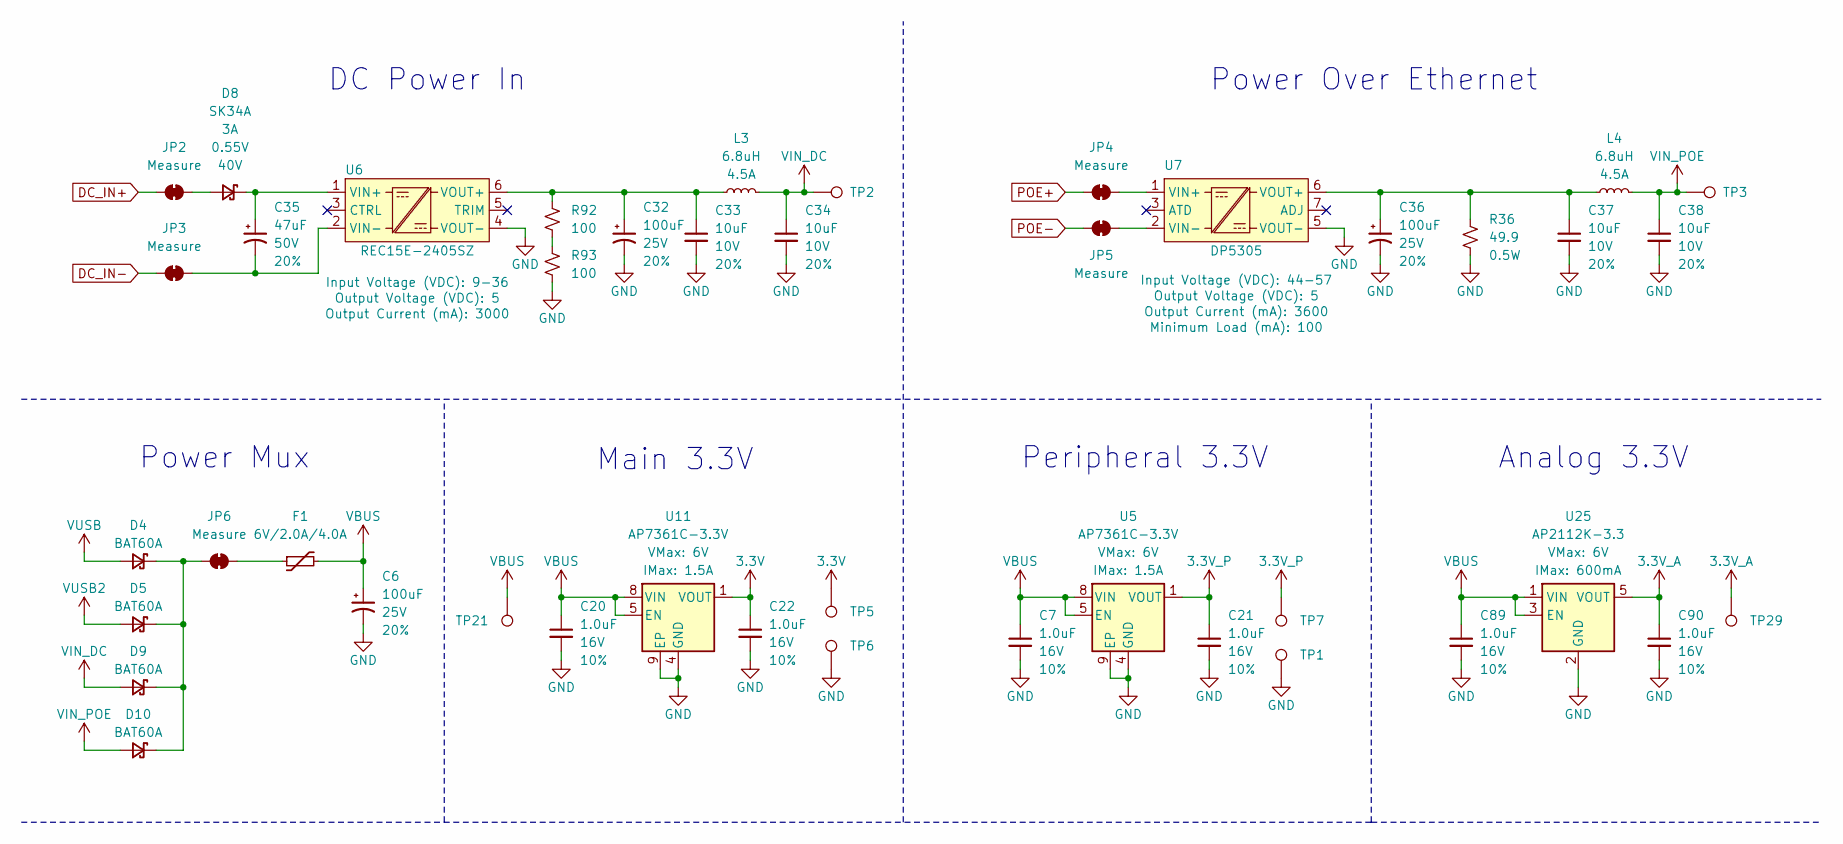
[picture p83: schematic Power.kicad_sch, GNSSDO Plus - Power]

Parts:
C6, C32, C36: 100uF; Panasonic_D; Voltage 25V; Tolerance 20%
C7, C20, C21, C22, C89, C90: 1.0uF; C_0603_1608Metric; Voltage 16V; Tolerance 10%
C33, C34, C37, C38: 10uF; C_0603_1608Metric; Voltage 10V; Tolerance 20%
C35: 47uF; Panasonic_D; Voltage 50V; Tolerance 20%
D4, D5, D9, D10: BAT60A; SOD-323
D8: SK34A; SMA
F1: 6V/2.0A/4.0A; 1210
JP2, JP3, JP4, JP5, JP6: Measure; Jumper_2_PTH_SMD_Combo-NC
L3, L4: 6.8uH; Inductor_7.3x6.6mm
R36: 49.9; R_1206_3216Metric; Tolerance 1%
R92, R93: 100; R_0603_1608Metric
TP1, TP2, TP3, TP5, TP6, TP7, TP21, TP29: PTH; 1x01_P2.54mm
U5, U11: AP7361C-3.3V; DFN-8_3x3mm_P0.65mm_EP2.25x1.5mm
U6: REC15E-2405SZ; REC15E; Input Voltage (VDC) 9-36; Output Voltage (VDC) 5
U7: DP5305; DP5300; Input Voltage (VDC) 44-57; Output Voltage (VDC) 5
U25: AP2112K-3.3; SOT23-5

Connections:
3.3V: C22.1, TP5.1, U11.1 (VOUT); also elsewhere on the board
3.3V_A: C90.1, TP29.1, U25.5 (VOUT); also elsewhere on the board
3.3V_P: C21.1, TP7.1, U5.1 (VOUT); also elsewhere on the board
DC_IN+: JP2.1 (A); also elsewhere on the board
DC_IN-: JP3.1 (A); also elsewhere on the board
GND: C6.2, C7.2, C20.2, C21.2, C22.2, C32.2, C33.2, C34.2, C36.2, C37.2, C38.2, C89.2, C90.2, R36.2, R93.1, TP1.1, TP6.1, U5.4 (GND), U5.9 (EP), U6.4 (VOUT-), U7.5 (VOUT-), U7.8 (VOUT-), U11.4 (GND), U11.9 (EP), U25.2 (GND); also elsewhere on the board
unnamed: D8.2 (A), JP2.2 (B)
unnamed: C35.1, D8.1 (K), U6.1 (VIN+)
unnamed: D4.1 (K), D5.1 (K), D9.1 (K), D10.1 (K), JP6.1 (A)
unnamed: C35.2, JP3.2 (B), U6.2 (VIN-)
unnamed: JP4.2 (B), U7.1 (VIN+)
unnamed: JP5.2 (B), U7.2 (VIN-)
unnamed: F1.1, JP6.2 (B)
unnamed: R92.1, R93.2
unnamed: C32.1, C33.1, L3.1, R92.2, U6.6 (VOUT+)
unnamed: C36.1, C37.1, L4.1, R36.1, U7.6 (VOUT+)
POE+: JP4.1 (A); also elsewhere on the board
POE-: JP5.1 (A); also elsewhere on the board
VBUS: C6.1, C7.1, C20.1, C89.1, F1.2, TP21.1, U5.5 (EN), U5.8 (VIN), U11.5 (EN), U11.8 (VIN), U25.1 (VIN), U25.3 (EN); also elsewhere on the board
VIN_DC: C34.1, D9.2 (A), L3.2, TP2.1; also elsewhere on the board
VIN_POE: C38.1, D10.2 (A), L4.2, TP3.1; also elsewhere on the board
VUSB: D4.2 (A); also elsewhere on the board
VUSB2: D5.2 (A); also elsewhere on the board

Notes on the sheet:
Power Over Ethernet
Analog 3.3V
DC Power In
Peripheral 3.3V
Power Mux
Main 3.3V

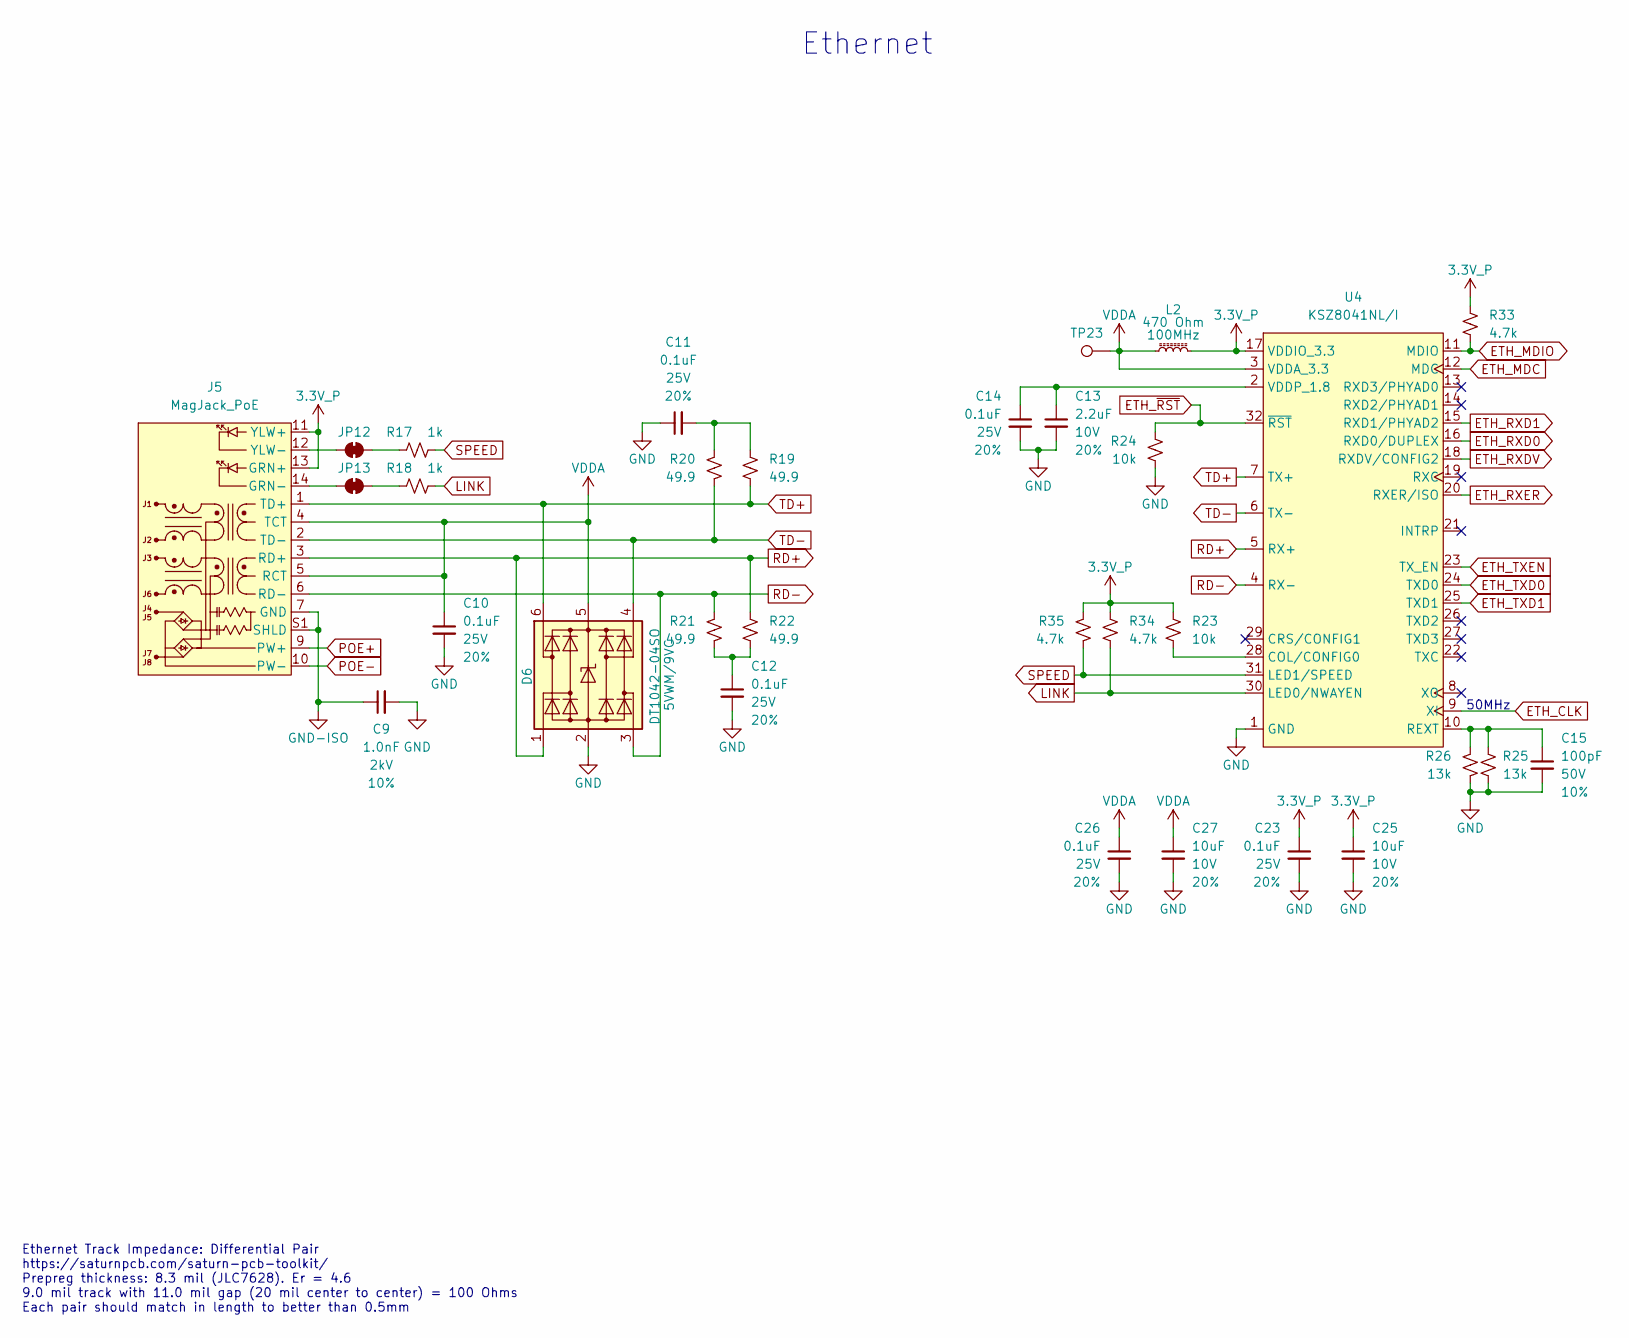
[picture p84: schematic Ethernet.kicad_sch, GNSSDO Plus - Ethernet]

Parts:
C9: 1.0nF; C_1206_3216Metric; Voltage 2kV; Tolerance 10%
C10, C11, C12, C14, C23, C26: 0.1uF; C_0603_1608Metric; Voltage 25V; Tolerance 20%
C13: 2.2uF; C_0603_1608Metric; Voltage 10V; Tolerance 20%
C15: 100pF; C_0603_1608Metric; Voltage 50V; Tolerance 10%
C25, C27: 10uF; C_0603_1608Metric; Voltage 10V; Tolerance 20%
D6: DT1042-04SO; SOT23-6; Rating 5VWM/9VC
J5: MagJack_PoE; MagJack_PoE_RJ45
JP12, JP13: Jumper_2_NC_Trace
L2: 470 Ohm; C_0603_1608Metric
R17, R18: 1k; R_0603_1608Metric
R19, R20, R21, R22: 49.9; R_0603_1608Metric; Tolerance 1%
R23, R24: 10k; R_0603_1608Metric
R25, R26: 13k; R_0603_1608Metric
R33, R34, R35: 4.7k; R_0603_1608Metric
TP23: PTH; 1x01_P2.54mm
U4: KSZ8041NL/I; QFN-32

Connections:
3.3V_P: C23.1, C25.1, J5.11 (YLW+), J5.13 (GRN+), L2.2, R23.1, R33.2, R34.2, R35.2, U4.17 (VDDIO_3.3); also elsewhere on the board
ETH_CLK: U4.9 (XI); also elsewhere on the board
ETH_MDC: U4.12 (MDC); also elsewhere on the board
ETH_MDIO: R33.1, U4.11 (MDIO); also elsewhere on the board
ETH_RXD0: U4.16 (RXD0/DUPLEX); also elsewhere on the board
ETH_RXD1: U4.15 (RXD1/PHYAD2); also elsewhere on the board
ETH_RXDV: U4.18 (RXDV/CONFIG2); also elsewhere on the board
ETH_RXER: U4.20 (RXER/ISO); also elsewhere on the board
ETH_TXD0: U4.24 (TXD0); also elsewhere on the board
ETH_TXD1: U4.25 (TXD1); also elsewhere on the board
ETH_TXEN: U4.23 (TX_EN); also elsewhere on the board
ETH_~RST: R24.2, U4.32 (~RST); also elsewhere on the board
GND: C9.2, C10.2, C11.1, C12.2, C13.2, C14.2, C15.2, C23.2, C25.2, C26.2, C27.2, D6.2 (GND), R24.1, R25.1, R26.1, U4.1 (GND), U4.EP (GND); also elsewhere on the board
GND-ISO: C9.1, J5.7 (GND), J5.S1 (SHLD), J5.S2 (SHLD)
LINK: R18.2, R34.1, U4.30 (LED0/NWAYEN)
unnamed: C11.2, R19.2, R20.2
unnamed: C12.1, R21.1, R22.1
unnamed: J5.14 (GRN-), JP13.1 (A)
unnamed: J5.12 (YLW-), JP12.1 (A)
unnamed: JP12.2 (B), R17.1
unnamed: JP13.2 (B), R18.1
unnamed: R23.2, U4.28 (COL/CONFIG0)
unnamed: C15.1, R25.2, R26.2, U4.10 (REXT)
unnamed: C13.1, C14.1, U4.2 (VDDP_1.8)
POE+: J5.9 (PW+); also elsewhere on the board
POE-: J5.10 (PW-); also elsewhere on the board
RD+: D6.1 (I/O1), J5.3 (RD+), R22.2, U4.5 (RX+)
RD-: D6.3 (I/O2), J5.6 (RD-), R21.2, U4.4 (RX-)
SPEED: R17.2, R35.1, U4.31 (LED1/SPEED)
TD+: D6.6 (I/O4), J5.1 (TD+), R19.1, U4.7 (TX+)
TD-: D6.4 (I/O3), J5.2 (TD-), R20.1, U4.6 (TX-)
VDDA: C10.1, C26.1, C27.1, D6.5 (VCC), J5.4 (TCT), J5.5 (RCT), L2.1, TP23.1, U4.3 (VDDA_3.3)

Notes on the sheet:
50MHz
Ethernet
Ethernet Track Impedance: Differential Pair https://saturnpcb.com/saturn-pcb-toolkit/ Prepreg thickness: 8.3 mil (JLC7628). Er = 4.6 9.0 mil track with 11.0 mil gap (20 mil center to center) = 100 Ohms Each pair should match in length to better than 0.5mm

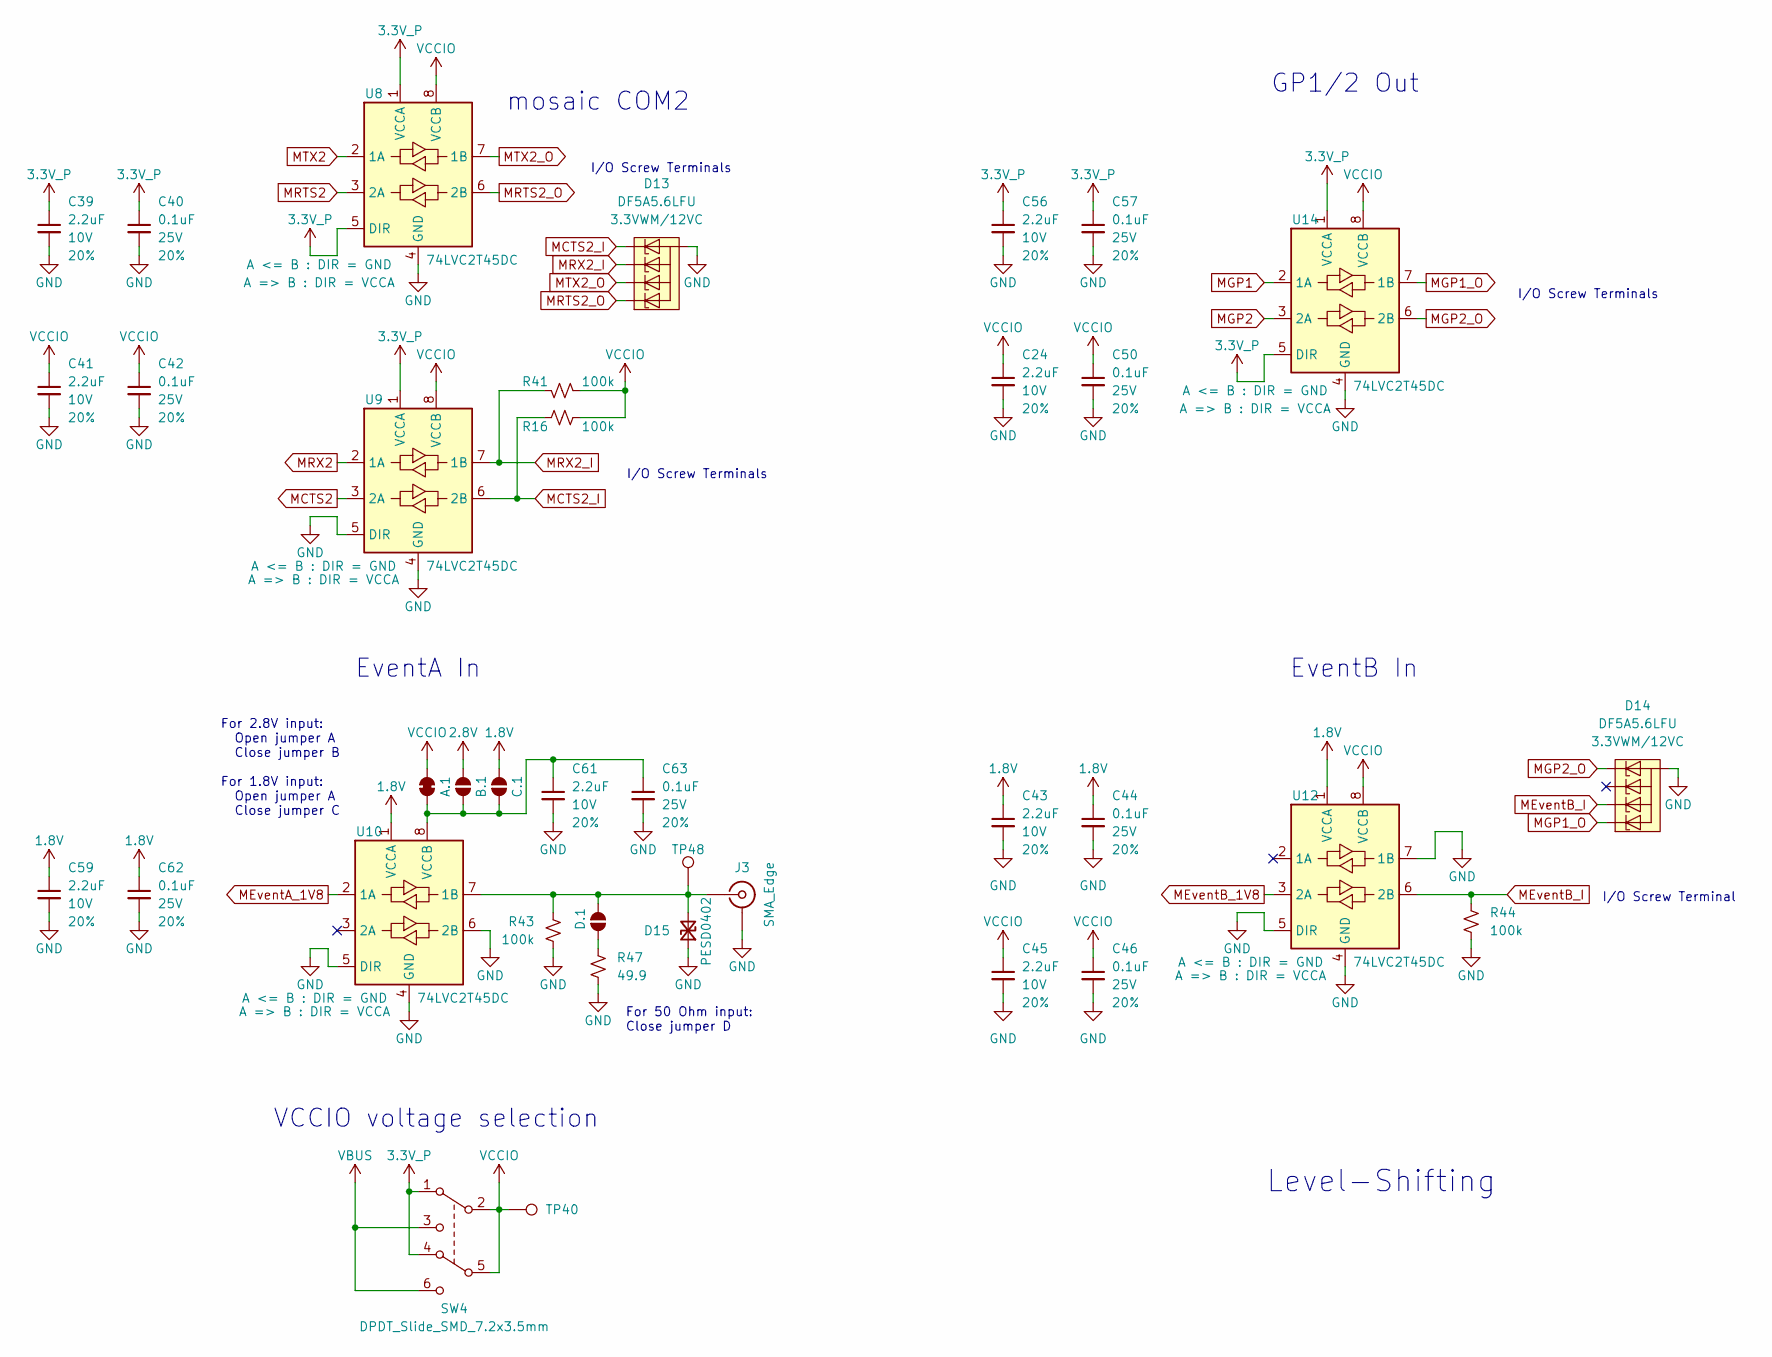
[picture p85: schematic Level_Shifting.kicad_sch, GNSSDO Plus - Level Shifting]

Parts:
A.1: Jumper_2_NC_Trace
B.1: Jumper_2_NO
C24, C39, C41, C43, C45, C56, C59, C61: 2.2uF; C_0603_1608Metric; Voltage 10V; Tolerance 20%
C40, C42, C44, C46, C50, C57, C62, C63: 0.1uF; C_0603_1608Metric; Voltage 25V; Tolerance 20%
C.1: Jumper_2_NO
D13, D14: DF5A5.6LFU; SOT-353; Rating 3.3VWM/12VC
D15: PESD0402; C_0402_1005Metric; Rating 14VWM/40VC
D.1: Jumper_2_NO
J3: SMA_Edge; SMA_Edge_6.3mm
R16, R41, R43, R44: 100k; R_0603_1608Metric
R47: 49.9; R_0603_1608Metric; Tolerance 1%
SW4: DPDT_Slide_SMD_7.2x3.5mm; Slide_DPDT_SMD_7.2x3.5mm; Mfg Part# ABC
TP40: PTH; 1x01_P2.54mm
TP48: 1.25mm; TestPoint-1.25mm
U8, U9, U10, U12, U14: 74LVC2T45DC; VSSOP8_SOT765-1

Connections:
1.8V: C43.1, C44.1, C59.1, C62.1, C.1.2 (B), U10.1 (VCCA), U12.1 (VCCA); also elsewhere on the board
2.8V: B.1.2 (B); also elsewhere on the board
3.3V_P: C39.1, C40.1, C56.1, C57.1, SW4.1 (A), SW4.4 (A), U8.1 (VCCA), U8.5 (DIR), U9.1 (VCCA), U14.1 (VCCA), U14.5 (DIR); also elsewhere on the board
GND: C24.2, C39.2, C40.2, C41.2, C42.2, C43.2, C44.2, C45.2, C46.2, C50.2, C56.2, C57.2, C59.2, C61.2, C62.2, C63.2, D13.2 (A), D14.2 (A), D15.1 (A1), J3.2 (Ext), R43.1, R44.1, R47.2, U8.4 (GND), U9.4 (GND), U9.5 (DIR), U10.4 (GND), U10.5 (DIR), U10.6 (2B), U12.4 (GND), U12.5 (DIR), U12.7 (1B), U14.4 (GND); also elsewhere on the board
MCTS2: U9.3 (2A); also elsewhere on the board
MCTS2_I: D13.5 (K4), R16.1, U9.6 (2B); also elsewhere on the board
MEventA_1V8: U10.2 (1A); also elsewhere on the board
MEventB_1V8: U12.3 (2A); also elsewhere on the board
MEventB_I: D14.3 (K2), R44.2, U12.6 (2B); also elsewhere on the board
MGP1: U14.2 (1A); also elsewhere on the board
MGP1_O: D14.1 (K1), U14.7 (1B); also elsewhere on the board
MGP2: U14.3 (2A); also elsewhere on the board
MGP2_O: D14.5 (K4), U14.6 (2B); also elsewhere on the board
MRTS2: U8.3 (2A); also elsewhere on the board
MRTS2_O: D13.1 (K1), U8.6 (2B); also elsewhere on the board
MRX2: U9.2 (1A); also elsewhere on the board
MRX2_I: D13.4 (K3), R41.1, U9.7 (1B); also elsewhere on the board
MTX2: U8.2 (1A); also elsewhere on the board
MTX2_O: D13.3 (K2), U8.7 (1B); also elsewhere on the board
unnamed: A.1.1 (A), B.1.1 (A), C61.1, C63.1, C.1.1 (A), U10.8 (VCCB)
unnamed: D.1.1 (A), R47.1
unnamed: D15.2 (A2), D.1.2 (B), J3.1 (In), R43.2, TP48.1, U10.7 (1B)
VBUS: SW4.3 (C), SW4.6 (C); also elsewhere on the board
VCCIO: A.1.2 (B), C24.1, C41.1, C42.1, C45.1, C46.1, C50.1, R16.2, R41.2, SW4.2 (B), SW4.5 (B), TP40.1, U8.8 (VCCB), U9.8 (VCCB), U12.8 (VCCB), U14.8 (VCCB); also elsewhere on the board

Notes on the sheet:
I/O Screw Terminals
GP1/2 Out
For 50 Ohm input: Close jumper D
mosaic COM2
I/O Screw Terminal
Level-Shifting
For 2.8V input: Open jumper A Close jumper B For 1.8V input: Open jumper A Close jumper C
EventB In
EventA In
VCCIO voltage selection

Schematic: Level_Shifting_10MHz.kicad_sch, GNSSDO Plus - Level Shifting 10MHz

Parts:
C51, C82: 1.0nF; C_0603_1608Metric; Voltage 50V; Tolerance 10%; not fitted
C55, C68, C69, C70, C81, C85, C86: 0.1uF; C_0603_1608Metric; Voltage 25V; Tolerance 20%
C64, C67, C75, C76, C87, C88: 1.0nF; C_0603_1608Metric; Voltage 50V; Tolerance 10%
C71, C72, C80, C84: 2.2uF; C_0603_1608Metric; Voltage 10V; Tolerance 20%
C83: 33pF; C_0603_1608Metric; Voltage 50V; Tolerance 5%
D16, D17: PESD0402; C_0402_1005Metric; Rating 14VWM/40VC
J8, J10: SMA_Edge; SMA_Edge_6.3mm
R45, R53, R56, R57, R61, R64, R66, R67, R77, R78: 1k; R_0603_1608Metric
R48, R54, R55, R58, R69, R70, R71, R73, R79: 0; R_0603_1608Metric
R50, R51, R59: 49.9; R_0603_1608Metric; Tolerance 1%
R52, R68, R75: 100k; R_0603_1608Metric
R72, R74: 0; R_0603_1608Metric; not fitted
R76: 33; R_0603_1608Metric
TP46, TP47: 1.25mm; TestPoint-1.25mm
U15: SN74LVC1G175DCK; SOT-363_SC-70-6
U17, U20, U23, U24: LMV7219M5; SOT23-5

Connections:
1.8V: C68.1, C69.1, C72.1, C85.1, R45.1, R56.2, R57.2, R61.2, R64.2, R66.2, R67.2; also elsewhere on the board
3.3V_A: C70.1, C71.1, C80.1, C81.1, C84.1, C86.1, U15.5 (VCC), U15.6 (~CLR), U17.5 (V+), U20.5 (V+), U23.5 (V+), U24.5 (V+); also elsewhere on the board
10MHz_1: C87.1; also elsewhere on the board
10MHz_2: C64.1; also elsewhere on the board
10MHz_3: C75.1; also elsewhere on the board
10MHz_Mosaic: R77.2, R78.1; also elsewhere on the board
GND: C51.2, C55.2, C68.2, C69.2, C70.2, C71.2, C72.2, C80.2, C81.2, C82.2, C83.2, C84.2, C85.2, C86.2, D16.1 (A1), D17.1 (A1), J8.2 (Ext), J10.2 (Ext), R50.2, R51.2, R53.2, R59.2, R78.2, U15.2 (GND), U17.2 (V-), U20.2 (V-), U23.2 (V-), U24.2 (V-); also elsewhere on the board
MPPS_1V8: R54.1; also elsewhere on the board
unnamed: C51.1, R48.1, R73.2, R74.1
unnamed: C55.1, R45.2, R53.1, R55.1
unnamed: C64.2, C67.1, R51.1
unnamed: C75.2, C76.1, R50.1
unnamed: C82.1, R69.2, R70.1
unnamed: C83.1, R76.2, R77.1
unnamed: C87.2, C88.1, R59.1
unnamed: D16.2 (A2), J10.1 (In), R48.2, TP46.1
unnamed: D17.2 (A2), J8.1 (In), R70.2, TP47.1
unnamed: R52.2, R69.1, U17.1
unnamed: R58.1, U20.1
unnamed: R58.2, R72.1, R79.1
unnamed: R68.2, R71.1, U23.1
unnamed: R72.2, R74.2
unnamed: R75.2, R76.1, U24.1
unnamed: R71.2, U15.1 (CLK)
unnamed: R79.2, U15.3 (D)
unnamed: R73.1, U15.4 (Q)
unnamed: R52.1, R57.1, U17.3 (+)
unnamed: C76.2, R56.1, U17.4 (-)
unnamed: R54.2, U20.3 (+)
unnamed: R55.2, U20.4 (-)
unnamed: R61.1, R68.1, U23.3 (+)
unnamed: C67.2, R64.1, U23.4 (-)
unnamed: R66.1, R75.1, U24.3 (+)
unnamed: C88.2, R67.1, U24.4 (-)

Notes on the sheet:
10MHz for mosaic
Note: all paths use identical components to ensure equal temperature dependence
Divide near module
PPS Out (Aligned to 10MHz)
Remove harmonics close to source
Level-Shifting 10MHz
Bypass alignment - if desired
10MHz Out

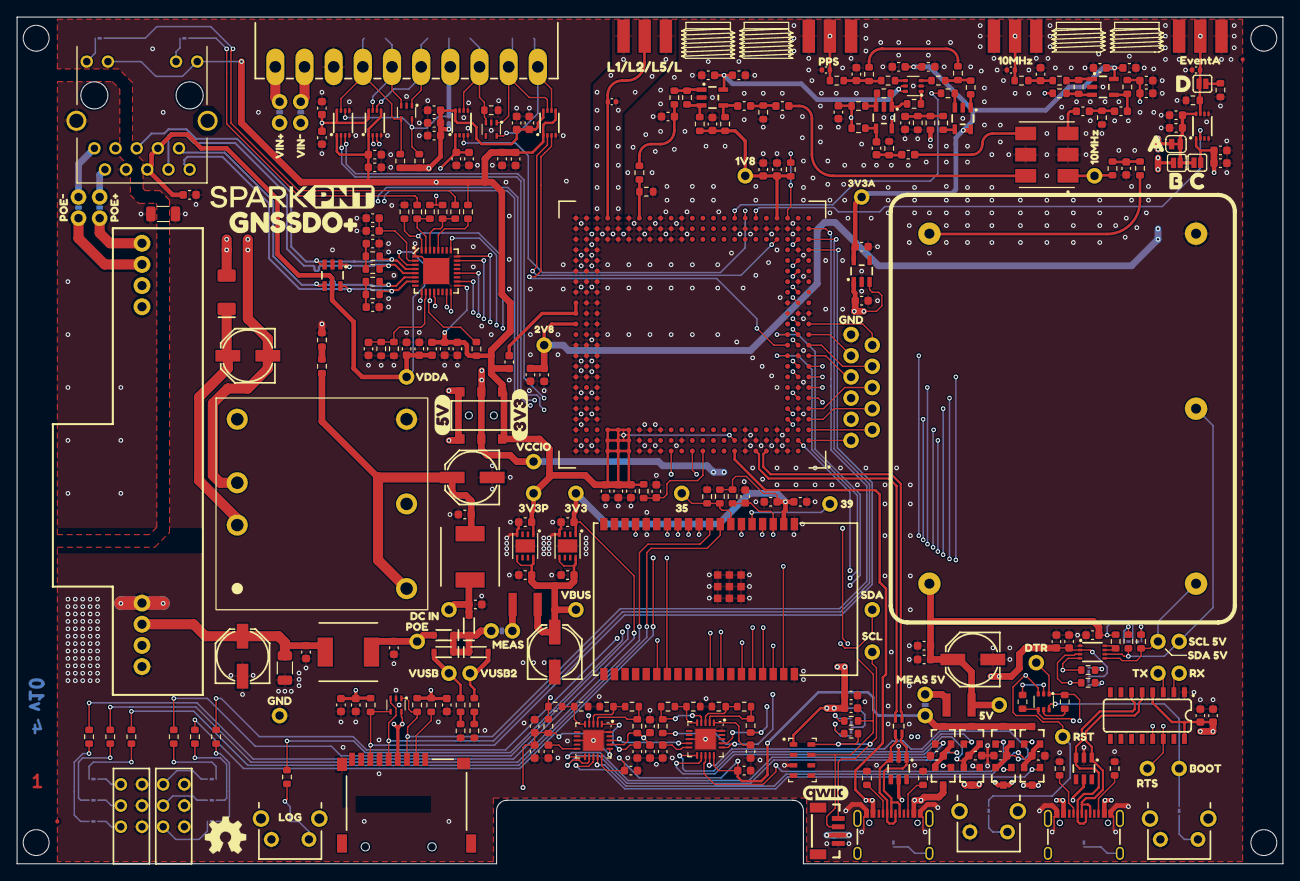
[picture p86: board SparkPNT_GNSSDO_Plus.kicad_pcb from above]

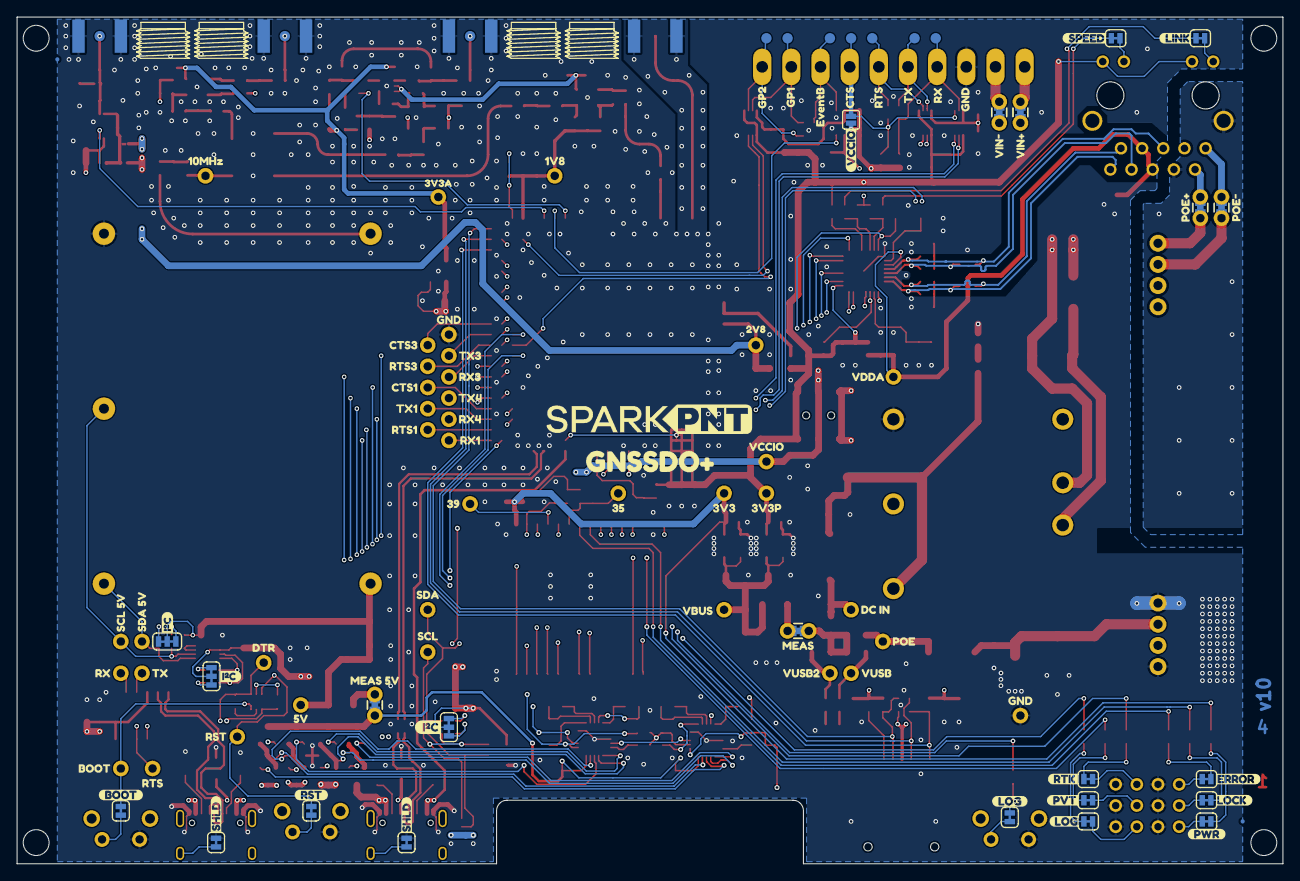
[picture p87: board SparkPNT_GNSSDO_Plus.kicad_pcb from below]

Board: 4 copper layers, 151.9 x 101.6 mm, 469 parts (105 on the bottom side), 208 nets.

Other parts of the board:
Ref**: Val**; OSHW_Logo_5mm
kibuzzard-65A7F5A7: G***; kibuzzard-65A7F5A7
kibuzzard-65A7F5BC: G***; kibuzzard-65A7F5BC
kibuzzard-65A7F5CF: G***; kibuzzard-65A7F5CF
kibuzzard-65A7F5E3: G***; kibuzzard-65A7F5E3
kibuzzard-65A7F440, kibuzzard-65A7F440#2, kibuzzard-65A7F440#3, kibuzzard-65A7F440#4: G***; kibuzzard-65A7F440
kibuzzard-65A7F511, kibuzzard-65A7F511#2: G***; kibuzzard-65A7F511
kibuzzard-65A7F548, kibuzzard-65A7F548#2: G***; kibuzzard-65A7F548
kibuzzard-65A7F771, kibuzzard-65A7F771#2: G***; kibuzzard-65A7F771
kibuzzard-65A7F891: G***; kibuzzard-65A7F891
kibuzzard-66A11DB0: G***; kibuzzard-66A11DB0
kibuzzard-66A11DCF: G***; kibuzzard-66A11DCF
kibuzzard-66A11DE1: G***; kibuzzard-66A11DE1
kibuzzard-66A11E07: G***; kibuzzard-66A11E07
kibuzzard-66A11E7B, kibuzzard-66A11E7B#2: G***; kibuzzard-66A11E7B
kibuzzard-66A11E14: G***; kibuzzard-66A11E14
kibuzzard-66A11E22: G***; kibuzzard-66A11E22
kibuzzard-66A11E61, kibuzzard-66A11E61#2: G***; kibuzzard-66A11E61
kibuzzard-66A11EB6, kibuzzard-66A11EB6#2: G***; kibuzzard-66A11EB6
kibuzzard-66A11F21, kibuzzard-66A11F21#2: G***; kibuzzard-66A11F21
kibuzzard-66A11F39, kibuzzard-66A11F39#2: G***; kibuzzard-66A11F39
kibuzzard-66A11FEE, kibuzzard-66A11FEE#2: G***; kibuzzard-66A11FEE
kibuzzard-66A36B1F: G***; kibuzzard-66A36B1F
kibuzzard-66A36BEE: G***; kibuzzard-66A36BEE
kibuzzard-66A120AA: G***; kibuzzard-66A120AA
kibuzzard-66A120EB: G***; kibuzzard-66A120EB
kibuzzard-66A121BE, kibuzzard-66A121BE#2: G***; kibuzzard-66A121BE
kibuzzard-66A121D2, kibuzzard-66A121D2#2: G***; kibuzzard-66A121D2
kibuzzard-66A122A4, kibuzzard-66A122A4#2: G***; kibuzzard-66A122A4
kibuzzard-66A122D2, kibuzzard-66A122D2#2: G***; kibuzzard-66A122D2
kibuzzard-66A211A5: G***; kibuzzard-66A211A5
kibuzzard-66A212DB: G***; kibuzzard-66A212DB
kibuzzard-66A212E8: G***; kibuzzard-66A212E8
kibuzzard-66A212F8: G***; kibuzzard-66A212F8
kibuzzard-66A1201E, kibuzzard-66A1201E#2: G***; kibuzzard-66A1201E
kibuzzard-66A1223B, kibuzzard-66A1223B#2: G***; kibuzzard-66A1223B
kibuzzard-66A2129F: G***; kibuzzard-66A2129F
kibuzzard-66A12010, kibuzzard-66A12010#2: G***; kibuzzard-66A12010
kibuzzard-66A12027, kibuzzard-66A12027#2: G***; kibuzzard-66A12027
kibuzzard-66A12034, kibuzzard-66A12034#2: G***; kibuzzard-66A12034
kibuzzard-66A12099: G***; kibuzzard-66A12099
kibuzzard-66A12140: G***; kibuzzard-66A12140
kibuzzard-66A12152: G***; kibuzzard-66A12152
kibuzzard-66A12161: G***; kibuzzard-66A12161
kibuzzard-66A12184, kibuzzard-66A12184#2: G***; kibuzzard-66A12184
kibuzzard-66A12197, kibuzzard-66A12197#2: G***; kibuzzard-66A12197
kibuzzard-66A12248, kibuzzard-66A12248#2: G***; kibuzzard-66A12248
kibuzzard-66A12259, kibuzzard-66A12259#2: G***; kibuzzard-66A12259
kibuzzard-66A12273, kibuzzard-66A12273#2: G***; kibuzzard-66A12273
kibuzzard-66A12315, kibuzzard-66A12315#2: G***; kibuzzard-66A12315
kibuzzard-66A12334, kibuzzard-66A12334#2: G***; kibuzzard-66A12334
kibuzzard-66A12372, kibuzzard-66A12372#2: G***; kibuzzard-66A12372
kibuzzard-66A21191: G***; kibuzzard-66A21191
kibuzzard-66A21310: G***; kibuzzard-66A21310
kibuzzard-66A21341: G***; kibuzzard-66A21341
kibuzzard-66A21351: G***; kibuzzard-66A21351
kibuzzard-677FF212: G***; kibuzzard-677FF212
kibuzzard-6710F8E6: G***; kibuzzard-6710F8E6
kibuzzard-6780FC4D: G***; kibuzzard-6780FC4D
kibuzzard-6780FC91: G***; kibuzzard-6780FC91
kibuzzard-65776CDC: G***; kibuzzard-65776CDC
kibuzzard-67126CA7: G***; kibuzzard-67126CA7
kibuzzard-67852A56: G***; kibuzzard-67852A56
kibuzzard-67852A83: G***; kibuzzard-67852A83
kibuzzard-68419E21: G***; kibuzzard-68419E21
kibuzzard-68419E42: G***; kibuzzard-68419E42
kibuzzard-68419E53: G***; kibuzzard-68419E53
kibuzzard-68419EB2: G***; kibuzzard-68419EB2
kibuzzard-671267CF: G***; kibuzzard-671267CF
kibuzzard-671267DB: G***; kibuzzard-671267DB
kibuzzard-678150B0: G***; kibuzzard-678150B0
kibuzzard-6781509E: G***; kibuzzard-6781509E
kibuzzard-6781552F: G***; kibuzzard-6781552F
kibuzzard-6781567E: G***; kibuzzard-6781567E
kibuzzard-6785285C: G***; kibuzzard-6785285C
kibuzzard-6786535A: G***; kibuzzard-6786535A
kibuzzard-67810443, kibuzzard-67810443#2: G***; kibuzzard-67810443
kibuzzard-67810522, kibuzzard-67810522#2: G***; kibuzzard-67810522
kibuzzard-67815483, kibuzzard-67815483#2: G***; kibuzzard-67815483
kibuzzard-67815572: G***; kibuzzard-67815572
kibuzzard-67815588: G***; kibuzzard-67815588
kibuzzard-67815716: G***; kibuzzard-67815716
kibuzzard-67815771: G***; kibuzzard-67815771
kibuzzard-67815778: G***; kibuzzard-67815778
kibuzzard-67852841: G***; kibuzzard-67852841

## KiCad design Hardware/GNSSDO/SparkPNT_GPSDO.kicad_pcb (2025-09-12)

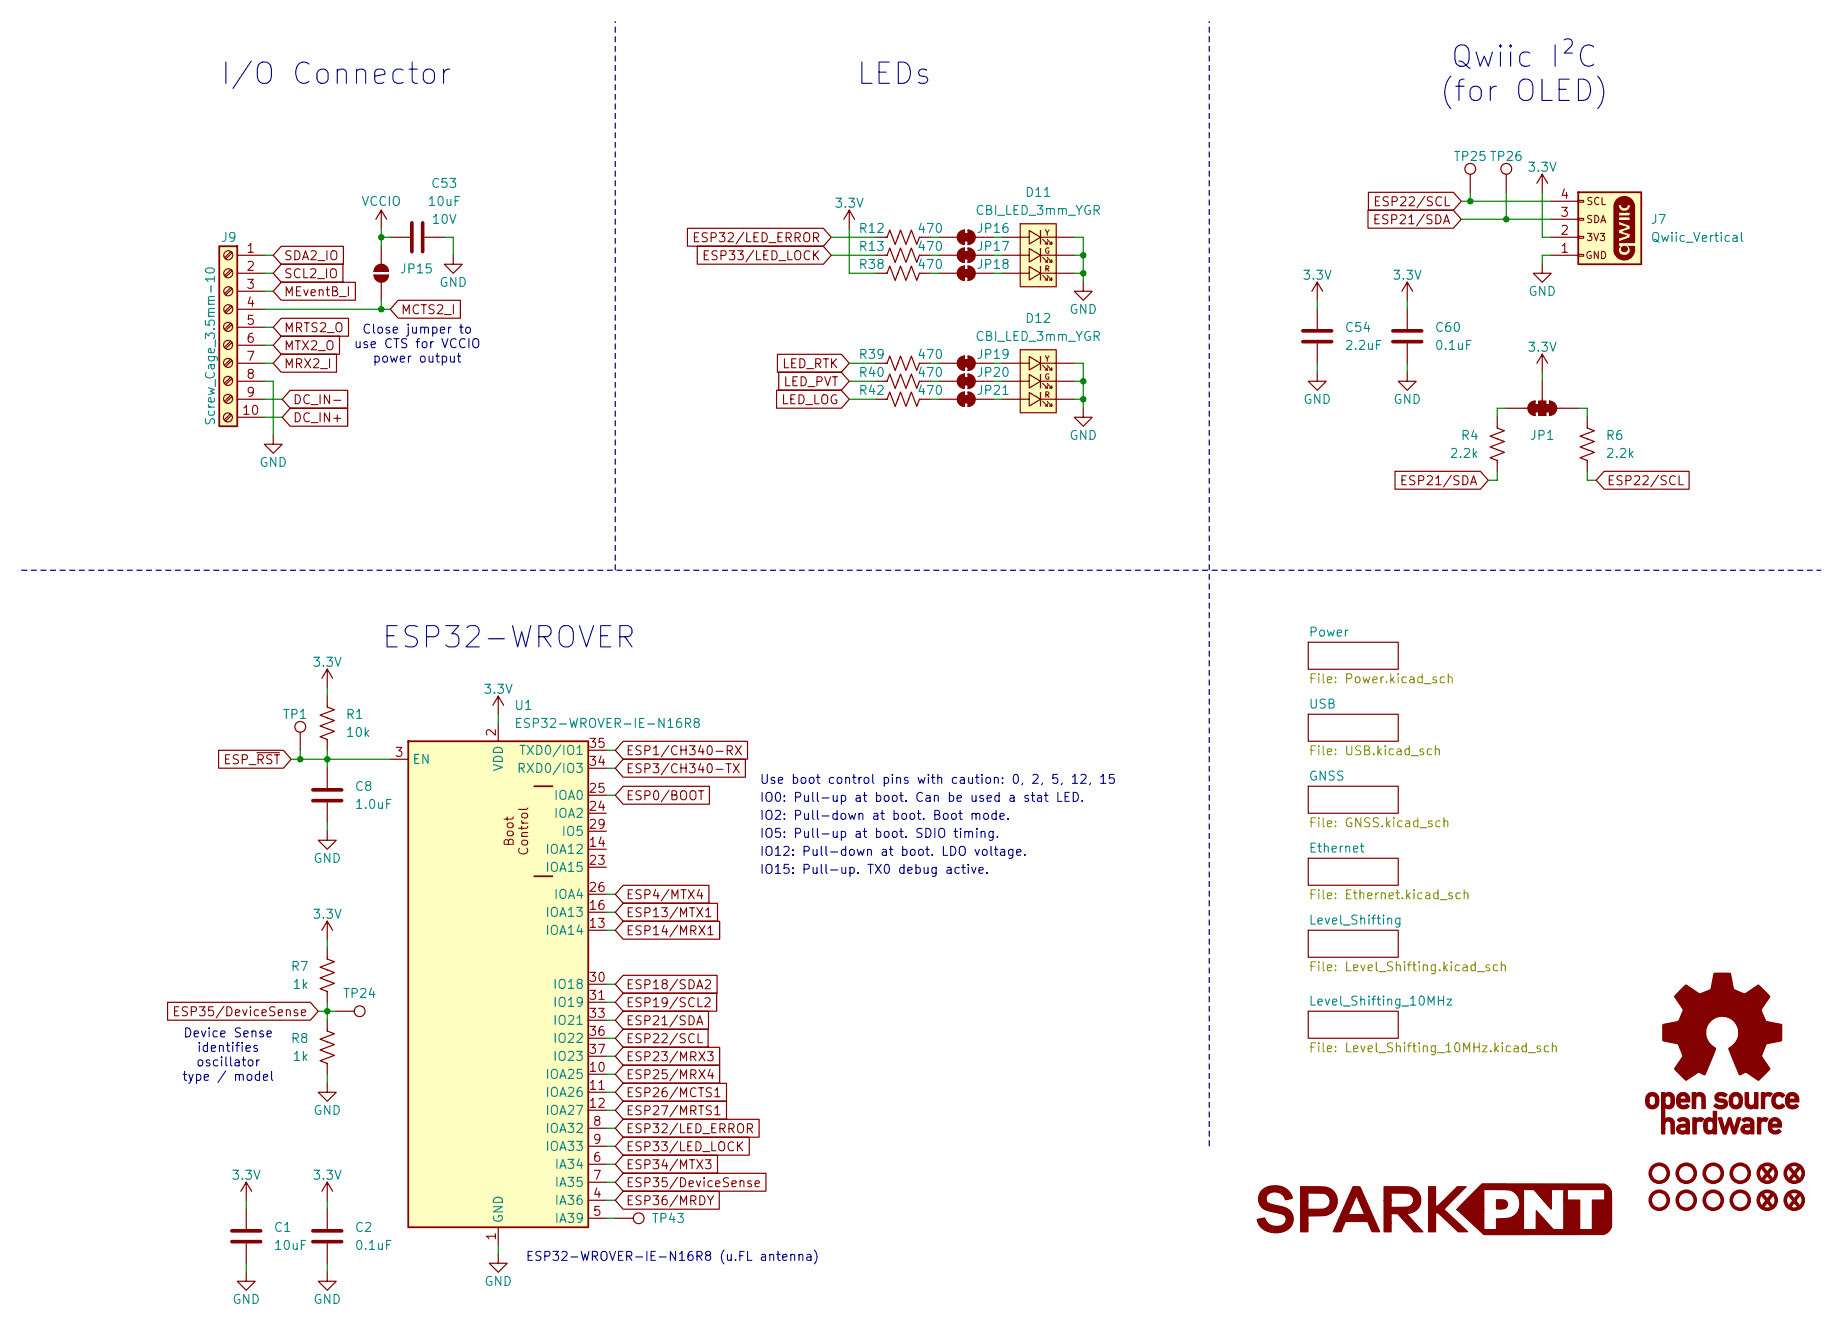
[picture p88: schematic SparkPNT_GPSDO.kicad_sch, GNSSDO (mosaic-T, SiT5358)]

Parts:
C1: 10uF; C_0603_1608Metric; Voltage 6.3V; Tolerance 20%
C2, C60: 0.1uF; C_0603_1608Metric; Voltage 25V; Tolerance 20%
C8: 1.0uF; C_0603_1608Metric; Voltage 16V; Tolerance 10%
C53: 10uF; C_0603_1608Metric; Voltage 10V; Tolerance 20%
C54: 2.2uF; C_0603_1608Metric; Voltage 10V; Tolerance 20%
D11, D12: CBI_LED_3mm_YGR; CBI_LED_Triple_3mm_PTH
FID1, FID2, FID3, FID4: Fiducial_0.5mm; Fiducial_0.5mm_Mask1mm
G1: OSHW_Logo; Creative_Commons_License
G2: LOGO
J7: Qwiic_Vertical; JST_SMD_1.0mm-4_Vertical
J9: Screw_Cage_3.5mm-10
JP1: Jumper_3_NC-2_Trace
JP15: Jumper_2_NO
JP16, JP17, JP18, JP19, JP20, JP21: Jumper_2_NC_Trace
R1: 10k; R_0603_1608Metric
R4, R6: 2.2k; R_0603_1608Metric
R7, R8: 1k; R_0603_1608Metric
R12, R13, R38, R39, R40, R42: 470; R_0603_1608Metric
ST1, ST2, ST3, ST4, ST5, ST6, ST7, ST8: Standoff
TP1, TP24, TP25, TP26, TP43: PTH; 1x01
U1: ESP32-WROVER-IE-N16R8; ESP32-WROVER-E-IE

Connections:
3.3V: C1.1, C2.1, C54.1, C60.1, J7.2, JP1.2 (C), R1.1, R7.1, R38.2, U1.2 (VDD); also elsewhere on the board
DC_IN+: J9.10 (Pin_1); also elsewhere on the board
DC_IN-: J9.9 (Pin_1); also elsewhere on the board
ESP0/BOOT: U1.25 (IOA0); also elsewhere on the board
ESP1/CH340-RX: U1.35 (TXD0/IO1); also elsewhere on the board
ESP3/CH340-TX: U1.34 (RXD0/IO3); also elsewhere on the board
ESP4/MTX4: U1.26 (IOA4); also elsewhere on the board
ESP13/MTX1: U1.16 (IOA13); also elsewhere on the board
ESP14/MRX1: U1.13 (IOA14); also elsewhere on the board
ESP18/SDA2: U1.30 (IO18); also elsewhere on the board
ESP19/SCL2: U1.31 (IO19); also elsewhere on the board
ESP21/SDA: J7.3, R4.1, TP26.1, U1.33 (IO21)
ESP22/SCL: J7.4, R6.1, TP25.1, U1.36 (IO22)
ESP23/MRX3: U1.37 (IO23); also elsewhere on the board
ESP25/MRX4: U1.10 (IOA25); also elsewhere on the board
ESP26/MCTS1: U1.11 (IOA26); also elsewhere on the board
ESP27/MRTS1: U1.12 (IOA27); also elsewhere on the board
ESP32/LED_ERROR: R12.2, U1.8 (IOA32)
ESP33/LED_LOCK: R13.2, U1.9 (IOA33)
ESP34/MTX3: U1.6 (IA34); also elsewhere on the board
ESP35/DeviceSense: R7.2, R8.1, TP24.1, U1.7 (IA35)
ESP36/MRDY: U1.4 (IA36); also elsewhere on the board
ESP_~RST: C8.1, R1.2, TP1.1, U1.3 (EN); also elsewhere on the board
GND: C1.2, C2.2, C8.2, C53.2, C54.2, C60.2, D11.CATHODE_1, D11.CATHODE_2, D11.CATHODE_3, D12.CATHODE_1, D12.CATHODE_2, D12.CATHODE_3, J7.1, J9.8 (Pin_1), R8.2, U1.1 (GND), U1.15 (GND), U1.38 (GND), U1.39.1 (GND), U1.39.2 (GND), U1.39.3 (GND), U1.39.4 (GND), U1.39.5 (GND), U1.39.6 (GND), U1.39.7 (GND), U1.39.8 (GND), U1.39.9 (GND); also elsewhere on the board
LED_LOG: R42.2; also elsewhere on the board
LED_PVT: R40.2; also elsewhere on the board
LED_RTK: R39.2; also elsewhere on the board
MCTS2_I: J9.4, JP15.1 (A); also elsewhere on the board
MEventB_I: J9.3; also elsewhere on the board
MRTS2_O: J9.5 (Pin_3); also elsewhere on the board
MRX2_I: J9.7 (Pin_2); also elsewhere on the board
MTX2_O: J9.6 (Pin_4); also elsewhere on the board
unnamed: JP1.1 (A), R6.2
unnamed: JP1.3 (B), R4.2
unnamed: JP16.1 (A), R12.1
unnamed: D11.ANODE_1, JP16.2 (B)
unnamed: JP17.1 (A), R13.1
unnamed: D11.ANODE_2, JP17.2 (B)
unnamed: JP18.1 (A), R38.1
unnamed: D11.ANODE_3, JP18.2 (B)
unnamed: JP19.1 (A), R39.1
unnamed: D12.ANODE_1, JP19.2 (B)
unnamed: JP20.1 (A), R40.1
unnamed: D12.ANODE_2, JP20.2 (B)
unnamed: JP21.1 (A), R42.1
unnamed: D12.ANODE_3, JP21.2 (B)
unnamed: TP43.1, U1.5 (IA39)
SCL2_IO: J9.2; also elsewhere on the board
SDA2_IO: J9.1; also elsewhere on the board
VCCIO: C53.1, JP15.2 (B); also elsewhere on the board

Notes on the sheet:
IO15: Pull-up. TX0 debug active.
IO2: Pull-down at boot. Boot mode.
ESP32-WROVER
IO0: Pull-up at boot. Can be used a stat LED.
LEDs
Qwiic I²C (for OLED)
Device Sense identifies oscillator type / model
Close jumper to use CTS for VCCIO power output
IO5: Pull-up at boot. SDIO timing.
I/O Connector
Use boot control pins with caution: 0, 2, 5, 12, 15
ESP32-WROVER-IE-N16R8 (u.FL antenna)
IO12: Pull-down at boot. LDO voltage.

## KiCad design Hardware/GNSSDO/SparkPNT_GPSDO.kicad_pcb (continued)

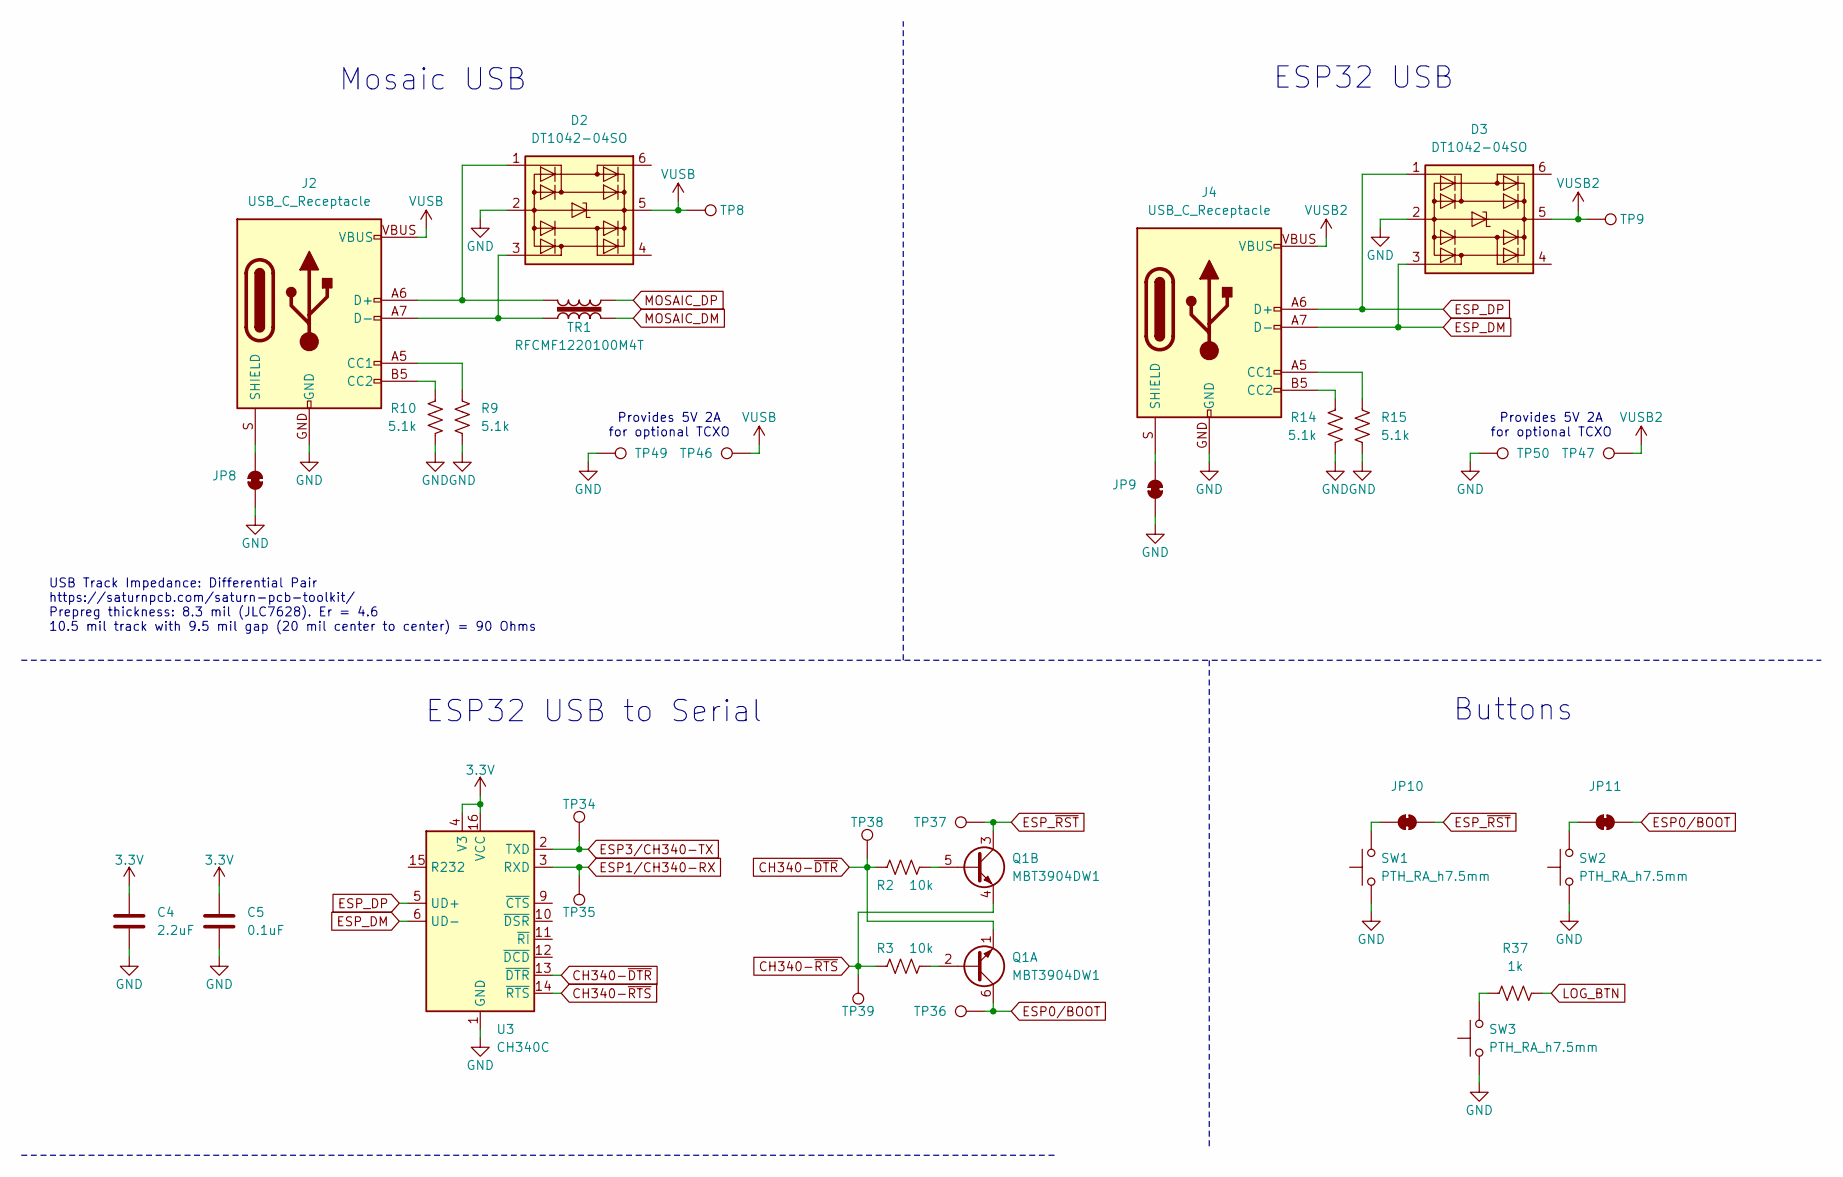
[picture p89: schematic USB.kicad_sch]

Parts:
C4: 2.2uF; C_0603_1608Metric; Voltage 10V; Tolerance 20%
C5: 0.1uF; C_0603_1608Metric; Voltage 25V; Tolerance 20%
D2, D3: DT1042-04SO; SOT23-6
J2, J4: USB_C_Receptacle; USB-C_16
JP8, JP9, JP10, JP11: Jumper_2_NC_Trace
Q1: MBT3904DW1; SOT-323
R2, R3: 10k; R_0603_1608Metric
R9, R10, R14, R15: 5.1k; R_0603_1608Metric
R37: 1k; R_0603_1608Metric
SW1, SW2, SW3: PTH_RA_h7.5mm; Push_PTH_RA_8-020_h7.5mm; Mfg Part# 8-020 TS H = 7.5mm
TP8, TP9, TP34, TP35, TP36, TP37, TP38, TP39, TP46, TP47, TP49, TP50: PTH; 1x01
TR1: RFCMF1220100M4T
U3: CH340C; SO-16

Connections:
3.3V: C4.1, C5.1, U3.4 (V3), U3.16 (VCC); also elsewhere on the board
CH340-~DTR: Q1.1 (E1), R2.2, TP38.1, U3.13 (~DTR)
CH340-~RTS: Q1.4 (E2), R3.2, TP39.1, U3.14 (~RTS)
ESP0/BOOT: JP11.2 (B), Q1.6 (C1), TP36.1; also elsewhere on the board
ESP1/CH340-RX: TP35.1, U3.3 (RXD); also elsewhere on the board
ESP3/CH340-TX: TP34.1, U3.2 (TXD); also elsewhere on the board
ESP_DM: D3.3 (I/O2), J4.A7 (D-), J4.B7 (D-), U3.6 (UD-)
ESP_DP: D3.1 (I/O1), J4.A6 (D+), J4.B6 (D+), U3.5 (UD+)
ESP_~RST: JP10.2 (B), Q1.3 (C2), TP37.1; also elsewhere on the board
GND: C4.2, C5.2, D2.2 (GND), D3.2 (GND), J2.GND, J4.GND, JP8.1 (A), JP9.1 (A), R9.1, R10.1, R14.1, R15.1, SW1.1, SW2.1, SW3.1, TP49.1, TP50.1, U3.1 (GND); also elsewhere on the board
LOG_BTN: R37.1; also elsewhere on the board
MOSAIC_DM: TR1.2; also elsewhere on the board
MOSAIC_DP: TR1.4; also elsewhere on the board
unnamed: D2.1 (I/O1), J2.A6 (D+), J2.B6 (D+), TR1.3
unnamed: D2.3 (I/O2), J2.A7 (D-), J2.B7 (D-), TR1.1
unnamed: J2.A5 (CC1), R9.2
unnamed: J2.B5 (CC2), R10.2
unnamed: J2.S (SHIELD), JP8.2 (B)
unnamed: J4.A5 (CC1), R15.2
unnamed: J4.B5 (CC2), R14.2
unnamed: J4.S (SHIELD), JP9.2 (B)
unnamed: JP10.1 (A), SW1.2
unnamed: JP11.1 (A), SW2.2
unnamed: Q1.2 (B1), R3.1
unnamed: Q1.5 (B2), R2.1
unnamed: R37.2, SW3.2
VUSB: D2.5 (VCC), J2.VBUS, TP8.1, TP46.1; also elsewhere on the board
VUSB2: D3.5 (VCC), J4.VBUS, TP9.1, TP47.1; also elsewhere on the board

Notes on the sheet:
ESP32 USB to Serial
Mosaic USB
Provides 5V 2A for optional TCXO
Buttons
ESP32 USB
USB Track Impedance: Differential Pair https://saturnpcb.com/saturn-pcb-toolkit/ Prepreg thickness: 8.3 mil (JLC7628). Er = 4.6 10.5 mil track with 9.5 mil gap (20 mil center to center) = 90 Ohms


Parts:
C3, C17, C19, C28, C48, C74: 0.1uF; C_0603_1608Metric; Voltage 25V; Tolerance 20%
C16, C18, C31, C73: 2.2uF; C_0603_1608Metric; Voltage 10V; Tolerance 20%
C29: 22uF; C_0603_1608Metric; Voltage 6.3V; Tolerance 20%
C30, C47: 10uF; C_0603_1608Metric; Voltage 10V; Tolerance 20%
D1: PESD0402; C_0402_1005Metric
D7: DF5A5.6LFU; SOT-353
J1: SMA_Edge
J6: microSD; microSD_External_Pin
JP14: Jumper_3_NC-2_Trace
L1: 470Ohm; C_0603_1608Metric
R5, R11, R27, R28, R29: 10k; R_0603_1608Metric
R31, R32: 2.2k; R_0603_1608Metric
TP10, TP11, TP12, TP13, TP14, TP15, TP16, TP17, TP18, TP19, TP20, TP21, TP22, TP27, TP28, TP29, TP30, TP31, TP32, TP33, TP41: PTH; 1x01
U2: mosaic-T; MOSAIC_LGA
U13: SiT5358AI-FS033IT-10.000000; Ceramic_QFN_5.0x3.2mm-10
U.1: Jumper_2_NC_Trace

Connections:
1.8V: C18.1, C19.1, R5.2, TP22.1, U2.AC4 (1V8_OUT); also elsewhere on the board
2.8V: C73.1, C74.1, TP41.1, U2.N23 (2V8_OUT); also elsewhere on the board
3.3V_P: C16.1, C17.1, C28.1, C29.1, C30.1, C31.1, C47.1, C48.1, D7.5 (K4), J6.4 (VDD), JP14.2 (C), L1.1, R11.2, R27.2, R28.2, R29.2, TP29.1, TP31.1, U2.A18 (VDD_3V3), U2.A19 (VDD_3V3), U2.A20 (VDD_3V3), U2.B8 (VDD_BAT), U2.B18 (VDD_3V3), U2.B19 (VDD_3V3), U2.B20 (VDD_3V3), U2.C18 (VDD_3V3), U2.C19 (VDD_3V3), U2.C20 (VDD_3V3), U13.1 (OE), U13.9 (VDD); also elsewhere on the board
10MHz: TP33.1, U.1.2 (B); also elsewhere on the board
ESP4/MTX4: TP11.1, U2.E3 (COM4_TX); also elsewhere on the board
ESP13/MTX1: TP13.1, U2.D1 (COM1_TX); also elsewhere on the board
ESP14/MRX1: TP12.1, U2.B1 (COM1_RX); also elsewhere on the board
ESP18/SDA2: R31.2, TP28.1, U13.10 (SDA); also elsewhere on the board
ESP19/SCL2: R32.2, TP27.1, U13.2 (SCL); also elsewhere on the board
ESP23/MRX3: TP16.1, U2.K1 (COM3_RX); also elsewhere on the board
ESP25/MRX4: TP10.1, U2.D3 (COM4_RX); also elsewhere on the board
ESP26/MCTS1: TP15.1, U2.E1 (COM1_CTS); also elsewhere on the board
ESP27/MRTS1: TP14.1, U2.C1 (COM1_RTS); also elsewhere on the board
ESP34/MTX3: TP17.1, U2.M1 (COM3_TX); also elsewhere on the board
ESP36/MRDY: U2.A12 (MODULE_RDY); also elsewhere on the board
ETH_CLK: U2.AA2 (ETHER_CLK); also elsewhere on the board
ETH_MDC: U2.V2 (ETHER_MDC); also elsewhere on the board
ETH_MDIO: U2.W2 (ETHER_MDIO); also elsewhere on the board
ETH_RXD0: U2.R2 (ETHER_RXD0); also elsewhere on the board
ETH_RXD1: U2.T2 (ETHER_RXD1); also elsewhere on the board
ETH_RXDV: U2.N2 (ETHER_CRSDV); also elsewhere on the board
ETH_RXER: U2.M2 (ETHER_RXER); also elsewhere on the board
ETH_TXD0: U2.J2 (ETHER_TXD0); also elsewhere on the board
ETH_TXD1: U2.H2 (ETHER_TXD1); also elsewhere on the board
ETH_TXEN: U2.L2 (ETHER_TXEN); also elsewhere on the board
ETH_~RST: U2.F2 (ETHER_~RST); also elsewhere on the board
GND: C3.1, C16.2, C17.2, C18.2, C19.2, C28.2, C29.2, C30.2, C31.2, C47.2, C48.2, C73.2, C74.2, D1.1 (A1), D7.2 (A), J1.2 (Ext), J6.6 (VSS), J6.10 (SHIELD), TP30.1, TP32.1, U2.A3 (RTC_XTALI), U2.A4 (GND), U2.A7 (GND), U2.A15 (GND), U2.A16 (GND), U2.A17 (GND), U2.A21 (GND), U2.A22 (GND), U2.A23 (GND), U2.AA13 (GND), U2.AA14 (GND), U2.AA15 (GND), U2.AA16 (GND), U2.AA17 (GND), U2.AA18 (GND), U2.AA19 (GND), U2.AA20 (GND), U2.AA21 (GND), U2.AA22 (GND), U2.AA23 (GND), U2.AB2 (GND), U2.AB3 (GND), U2.AB4 (GND), U2.AB5 (GND), U2.AB6 (GND), U2.AB7 (GND), U2.AB8 (GND), U2.AB13 (GND), U2.AB14 (GND), U2.AB15 (GND), U2.AB16 (GND), U2.AB17 (GND), U2.AB18 (GND), U2.AB19 (GND), U2.AB20 (GND), U2.AB21 (GND), U2.AB22 (GND), U2.AB23 (GND), U2.AC13 (GND), U2.AC15 (GND), U2.AC18 (GND), U2.AC19 (GND), U2.AC21 (GND), U2.AC22 (GND), U2.AC23 (GND), U2.B4 (GND), U2.B5 (GND), U2.B6 (GND), U2.B7 (GND), U2.B13 (GND), U2.B17 (GND), U2.B21 (GND), U2.C4 (GND), U2.C7 (GND), U2.C15 (GND), U2.C16 (GND), U2.C17 (GND), U2.C23 (GND), U2.D2 (GND), U2.D21 (GND), U2.D22 (GND), U2.D23 (GND), U2.E2 (GND), U2.E21 (GND), U2.E22 (GND), U2.E23 (GND), U2.F21 (GND), U2.F22 (GND), U2.F23 (GND), U2.G2 (GND), U2.G21 (GND), U2.G23 (GND), U2.H21 (GND), U2.H22 (GND), U2.H23 (GND), U2.J21 (GND), U2.J22 (GND), U2.J23 (GND), U2.K2 (GND), U2.K21 (GND), U2.K22 (GND), U2.K23 (GND), U2.L21 (GND), U2.L22 (GND), U2.L23 (GND), U2.M21 (GND), U2.M22 (GND), U2.N21 (GND), U2.N22 (GND), U2.P1 (GND), U2.P2 (GND), U2.P3 (GND), U2.P21 (GND), U2.P22 (GND), U2.R3 (GND), U2.R21 (GND), U2.R22 (GND), U2.T21 (GND), U2.T22 (GND), U2.T23 (GND), U2.U2 (GND), U2.U21 (GND), U2.U22 (GND), U2.U23 (GND), U2.V21 (GND), U2.V22 (GND), U2.V23 (ANT_2), U2.W21 (GND), U2.W22 (GND), U2.W23 (GND), U2.Y2 (GND), U2.Y21 (GND), U2.Y22 (GND), U2.Y23 (GND), U13.4 (GND), U13.5 (A0); also elsewhere on the board
LED_LOG: U2.B2 (LOG_LED); also elsewhere on the board
LED_PVT: U2.A14 (GP_LED); also elsewhere on the board
LED_RTK: U2.M3 (GP_LED2); also elsewhere on the board
LOG_BTN: U2.K3 (LOG_BTN); also elsewhere on the board
MCTS2: U2.J1 (COM2_CTS); also elsewhere on the board
MEventA_1V8: U2.AC6 (EVENTA); also elsewhere on the board
MEventB_1V8: U2.AC7 (EVENTB); also elsewhere on the board
MOSAIC_DM: U2.A6 (USB_D-); also elsewhere on the board
MOSAIC_DP: U2.A5 (USB_D+); also elsewhere on the board
MOSAIC_RF_IN: D1.2 (A2), J1.1 (In), U2.AC20 (ANT_1)
MPPS_1V8: U2.AC8 (PPS); also elsewhere on the board
MRTS2: U2.G1 (COM2_RTS); also elsewhere on the board
MRX2: U2.F1 (COM2_RX); also elsewhere on the board
MTX2: U2.H1 (COM2_TX); also elsewhere on the board
unnamed: J6.2 (DAT3/CD), R27.1
unnamed: JP14.1 (A), R32.1
unnamed: JP14.3 (B), R31.1
unnamed: TP19.1, U2.N1 (COM3_CTS)
unnamed: TP18.1, U2.L1 (COM3_RTS)
unnamed: TP20.1, U2.AA4 (GPIO_1)
unnamed: TP21.1, U2.L3 (GPIO_2)
unnamed: R5.1, U2.AC3 (SYNC)
unnamed: C3.2, R11.1, U2.A11 (~RESET)
unnamed: U13.6 (CLK), U.1.1 (A)
REF_IN: U2.AC17 (REF_IN); also elsewhere on the board
SD_CLK: D7.3 (K2), J6.5 (CLK/SCK), U2.AA1 (SD_CLK)
SD_CMD: D7.1 (K1), J6.3 (CMD/SDI), R28.1, U2.AB1 (SD_CMD)
SD_DATA: D7.4 (K3), J6.7 (DAT0/SDO), R29.1, U2.Y1 (SD_DATA)
VANT: L1.2, U2.P23 (VANT), U2.R23 (VANT)
VUSB: U2.A8 (V_USB); also elsewhere on the board

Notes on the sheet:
Er: 4.6
Polygon Isolation: 6mil/0.1524mm
10MHz
Console access (via TCP)
SMA Connectors (via level-shifters)
10MHz Oscillator
Dielectric thickness (layer 1 to 2): 0.2mm
Board thickness: 1.6mm
Open jumper U to isolate 10MHz
mosaic Tri-band GNSS
Microstrip Calculation:
50Ohm
I/O Screw Terminals (via level-shifters)
https://chemandy.com/calculators/coplanar-waveguide-with-ground-calculator.htm
Copper Thickness (1oz): 1.4mil/0.035mm
I/O Screw Terminal (via level-shifter)
50MHz
GNSS Antenna
microSD
RF Trace Width: 13mil/0.33mm


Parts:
C6, C32, C36: 100uF; Panasonic_D; Voltage 25V; Tolerance 20%
C7, C20, C21, C22: 1.0uF; C_0603_1608Metric; Voltage 16V; Tolerance 10%
C33, C34, C37, C38: 10uF; C_0603_1608Metric; Voltage 10V; Tolerance 20%
C35: 47uF; Panasonic_D; Voltage 50V; Tolerance 20%
D4, D5, D9, D10: BAT60A; SOD-323
D8: SK34A; SMA
F1: 6V/2.0A/4.0A; 1210
JP2, JP3, JP4, JP5, JP6: Measure; Jumper_2_PTH_SMD_Combo-NC
JP7: Jumper_2_NC_Trace
L3, L4: 4.7uH; 1008_2520Metric
R36: 49.9; R_1206_3216Metric; Tolerance 1%
TP2, TP3, TP4, TP5, TP6, TP7, TP45: PTH; 1x01
U5, U11: AP7361C-3.3V; UDFN-8
U6: REC15E-2405SZ; REC15E; Input Voltage (VDC) 9-36; Output Voltage (VDC) 5
U7: Ag9905M; Ag9900M; Input Voltage (VDC) 36-57; Output Voltage (VDC) 5

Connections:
3.3V: C22.1, TP5.1, U11.1 (VOUT); also elsewhere on the board
3.3V_P: C21.1, TP7.1, U5.1 (VOUT); also elsewhere on the board
5V: C6.1, C7.1, C20.1, F1.1, TP4.1, U5.5 (EN), U5.8 (VIN), U11.5 (EN), U11.8 (VIN); also elsewhere on the board
DC_IN+: JP2.1 (A); also elsewhere on the board
DC_IN-: JP3.1 (A); also elsewhere on the board
GND: C6.2, C7.2, C20.2, C21.2, C22.2, C32.2, C33.2, C34.2, C36.2, C37.2, C38.2, R36.1, TP6.1, U5.4 (GND), U5.9 (EP), U6.4 (VOUT-), U7.3 (VOUT-), U11.4 (GND), U11.9 (EP); also elsewhere on the board
unnamed: D8.A, JP2.2 (B)
unnamed: C35.2, JP3.2 (B), U6.2 (VIN-)
unnamed: D4.C, D5.C, D9.C, D10.C, JP6.1 (A)
unnamed: F1.2, JP6.2 (B)
unnamed: JP7.1 (A), R36.2
unnamed: C36.1, C37.1, JP7.2 (B), L4.1, U7.1 (VOUT+), U7.2 (VOUT+)
unnamed: C35.1, D8.C, U6.1 (VIN+)
unnamed: C32.1, C33.1, L3.1, TP45.1, U6.6 (VOUT+)
POE+: JP4.1 (A); also elsewhere on the board
POE-: JP5.1 (A); also elsewhere on the board
VIN+: JP4.2 (B), U7.5 (VIN+), U7.6 (VIN+)
VIN-: JP5.2 (B), U7.7 (VIN-), U7.8 (VIN-)
VIN_DC: C34.1, D9.A, L3.2, TP2.1
VIN_POE: C38.1, D10.A, L4.2, TP3.1
VUSB: D4.A; also elsewhere on the board
VUSB2: D5.A; also elsewhere on the board

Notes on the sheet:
Power Over Ethernet
Provides 5V 2A for optional TCXO
DC Power In
Peripheral 3.3V
Power Mux
Main 3.3V


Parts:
C9: 1nF; C_1206_3216Metric; Voltage 2kV; Tolerance 10%
C10, C11, C12, C14, C23, C26: 0.1uF; C_0603_1608Metric; Voltage 25V; Tolerance 20%
C13: 2.2uF; C_0603_1608Metric; Voltage 10V; Tolerance 20%
C15: 100pF; C_0603_1608Metric; Voltage 50V; Tolerance 10%
C25, C27: 10uF; C_0603_1608Metric; Voltage 10V; Tolerance 20%
D6: DT1042-04SO; SOT23-6
J5: MagJack_PoE; MagJack_PoE_RJ45
JP12, JP13: Jumper_2_NC_Trace
L2: 470Ohm; C_0603_1608Metric
R17, R18: 1k; R_0603_1608Metric
R19, R20, R21, R22: 49.9; R_0603_1608Metric; Tolerance 1%
R23, R24: 10k; R_0603_1608Metric
R25, R26: 13k; R_0603_1608Metric
R33, R34, R35: 4.7k; R_0603_1608Metric
TP23: PTH; 1x01
U4: KSZ8041NL/I; QFN-32

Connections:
3.3V_P: C23.1, C25.1, J5.11 (YLW+), J5.13 (GRN+), L2.2, R23.2, R33.1, R34.1, R35.1, U4.17 (VDDIO_3.3); also elsewhere on the board
ETH_CLK: U4.9 (XI); also elsewhere on the board
ETH_MDC: U4.12 (MDC); also elsewhere on the board
ETH_MDIO: R33.2, U4.11 (MDIO); also elsewhere on the board
ETH_RXD0: U4.16 (RXD0/DUPLEX); also elsewhere on the board
ETH_RXD1: U4.15 (RXD1/PHYAD2); also elsewhere on the board
ETH_RXDV: U4.18 (RXDV/CONFIG2); also elsewhere on the board
ETH_RXER: U4.20 (RXER/ISO); also elsewhere on the board
ETH_TXD0: U4.24 (TXD0); also elsewhere on the board
ETH_TXD1: U4.25 (TXD1); also elsewhere on the board
ETH_TXEN: U4.23 (TX_EN); also elsewhere on the board
ETH_~RST: R24.1, U4.32 (~RST); also elsewhere on the board
GND: C9.2, C10.2, C11.1, C12.2, C13.2, C14.2, C15.2, C23.2, C25.2, C26.2, C27.2, D6.2 (GND), R24.2, R25.2, R26.2, U4.1 (GND), U4.EP (GND); also elsewhere on the board
GND-ISO: C9.1, J5.7 (GND), J5.S1 (SHLD), J5.S2 (SHLD)
LINK: R18.1, R34.2, U4.30 (LED0/NWAYEN)
unnamed: C11.2, R19.1, R20.1
unnamed: C12.1, R21.2, R22.2
unnamed: J5.14 (GRN-), JP13.1 (A)
unnamed: J5.12 (YLW-), JP12.1 (A)
unnamed: JP12.2 (B), R17.2
unnamed: JP13.2 (B), R18.2
unnamed: R23.1, U4.28 (COL/CONFIG0)
unnamed: C15.1, R25.1, R26.1, U4.10 (REXT)
unnamed: C13.1, C14.1, U4.2 (VDDP_1.8)
POE+: J5.9 (PW+); also elsewhere on the board
POE-: J5.10 (PW-); also elsewhere on the board
RD+: D6.1 (I/O1), J5.3 (RD+), R22.1, U4.5 (RX+)
RD-: D6.3 (I/O2), J5.6 (RD-), R21.1, U4.4 (RX-)
SPEED: R17.1, R35.2, U4.31 (LED1/SPEED)
TD+: D6.6 (I/O4), J5.1 (TD+), R19.2, U4.7 (TX+)
TD-: D6.4 (I/O3), J5.2 (TD-), R20.2, U4.6 (TX-)
VDDA: C10.1, C26.1, C27.1, D6.5 (VCC), J5.4 (TCT), J5.5 (RCT), L2.1, TP23.1, U4.3 (VDDA_3.3)

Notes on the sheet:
50MHz
Ethernet
Ethernet Track Impedance: Differential Pair https://saturnpcb.com/saturn-pcb-toolkit/ Prepreg thickness: 8.3 mil (JLC7628). Er = 4.6 9.0 mil track with 11.0 mil gap (20 mil center to center) = 100 Ohms Each pair should match in length to better than 0.5mm


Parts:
C39, C41, C43, C45, C56, C59, C61, C64, C65: 2.2uF; C_0603_1608Metric; Voltage 10V; Tolerance 20%
C40, C42, C44, C46, C57, C62, C63, C66, C67: 0.1uF; C_0603_1608Metric; Voltage 25V; Tolerance 20%
D13, D14: DF5A5.6LFU; SOT-353
D15: PESD0402; C_0402_1005Metric
E.1: Jumper_2_NC_Trace
F.1: Jumper_2_NC_Trace
G.1: Jumper_2_NO
H.1: Jumper_2_NO
J3, J12: SMA_Edge
J.1: Jumper_2_NC_Trace
JP22: Jumper_3_NC-2_Trace
K.1: Jumper_2_NO
L.1: Jumper_2_NO
M.1: Jumper_2_NC_Trace
N.1: Jumper_2_NO
P.1: Jumper_2_NO
R16, R41, R43, R44: 100k; R_0603_1608Metric
R45, R47, R48: 49.9; R_0603_1608Metric; Tolerance 1%
R53: 200k; R_0603_1608Metric
R54, R55: 2.2k; R_0603_1608Metric
SW4: DPDT_Slide_SMD_7.2x3.5mm; Slide_DPDT_SMD_7.2x3.5mm; Mfg Part# ABC
TP40, TP48: PTH; 1x01
U8, U9, U10, U12, U16: 74LVC2T45DC; VSSOP8_SOT765-1
U18: PCA9306; VSSOP8_SOT765-1
V.1: Jumper_2_NO

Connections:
1.8V: C43.1, C44.1, C59.1, C62.1, C64.1, C66.1, L.1.2 (B), P.1.2 (B), U10.1 (VCCA), U12.1 (VCCA), U16.1 (VCCA), U16.5 (DIR); also elsewhere on the board
2.8V: K.1.2 (B), N.1.2 (B); also elsewhere on the board
3.3V_P: C39.1, C40.1, C56.1, C57.1, SW4.1 (A), SW4.4 (A), U8.1 (VCCA), U8.5 (DIR), U9.1 (VCCA), U18.2 (VREF1); also elsewhere on the board
5V: SW4.3 (C), SW4.6 (C); also elsewhere on the board
ESP18/SDA2: U18.4 (SDA1); also elsewhere on the board
ESP19/SCL2: U18.3 (SCL1); also elsewhere on the board
GND: C39.2, C40.2, C41.2, C42.2, C43.2, C44.2, C45.2, C46.2, C56.2, C57.2, C59.2, C61.2, C62.2, C63.2, C64.2, C65.2, C66.2, C67.2, D13.2 (A), D14.2 (A), D15.1 (A1), J3.2 (Ext), J12.2 (Ext), R43.2, R44.2, R47.1, U8.4 (GND), U9.4 (GND), U9.5 (DIR), U10.4 (GND), U10.5 (DIR), U10.6 (2B), U12.4 (GND), U12.5 (DIR), U12.7 (1B), U16.4 (GND), U18.1 (GND); also elsewhere on the board
MCTS2: U9.3 (2A); also elsewhere on the board
MCTS2_I: D13.5 (K4), R16.2, U9.6 (2B); also elsewhere on the board
MEventA_1V8: U10.2 (1A); also elsewhere on the board
MEventB_1V8: U12.3 (2A); also elsewhere on the board
MEventB_I: D14.3 (K2), R44.1, U12.6 (2B); also elsewhere on the board
MPPS_1V8: U16.2 (1A), U16.3 (2A); also elsewhere on the board
MRTS2: U8.3 (2A); also elsewhere on the board
MRTS2_O: D13.1 (K1), U8.6 (2B); also elsewhere on the board
MRX2: U9.2 (1A); also elsewhere on the board
MRX2_I: D13.4 (K3), R41.2, U9.7 (1B); also elsewhere on the board
MTX2: U8.2 (1A); also elsewhere on the board
MTX2_O: D13.3 (K2), U8.7 (1B); also elsewhere on the board
unnamed: D15.2 (A2), J3.1 (In), R43.1, U10.7 (1B), V.1.2 (B)
unnamed: E.1.1 (A), R45.2, U16.7 (1B)
unnamed: E.1.2 (B), F.1.1 (A), R45.1
unnamed: F.1.2 (B), H.1.2 (B), J12.1 (In)
unnamed: G.1.1 (A), R48.2, U16.6 (2B)
unnamed: G.1.2 (B), H.1.1 (A), R48.1
unnamed: C61.1, C63.1, J.1.1 (A), K.1.1 (A), L.1.1 (A), U10.8 (VCCB)
unnamed: JP22.1 (A), R55.2
unnamed: JP22.3 (B), R54.2
unnamed: C65.1, C67.1, M.1.1 (A), N.1.1 (A), P.1.1 (A), U16.8 (VCCB)
unnamed: R53.1, U18.7 (VREF2), U18.8 (EN)
unnamed: R47.2, V.1.1 (A)
SCL2_IO: D14.1 (K1), R55.1, U18.6 (SCL2); also elsewhere on the board
SDA2_IO: D14.5 (K4), R54.1, U18.5 (SDA2); also elsewhere on the board
VCCIO: C41.1, C42.1, C45.1, C46.1, J.1.2 (B), JP22.2 (C), M.1.2 (B), R16.1, R41.1, R53.2, SW4.2 (B), SW4.5 (B), TP40.1, TP48.1, U8.8 (VCCB), U9.8 (VCCB), U12.8 (VCCB); also elsewhere on the board

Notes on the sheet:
SDA2 SCL2
I/O Screw Terminals
Provides VCCIO at TCXO breakouts
For 50 Ohm input: Close jumper V
mosaic COM2
I/O Screw Terminal
Level-Shifting
For 50 Ohm output: Open jumper E Close jumper H
For 2.8V input: Open jumper J Close jumper K For 1.8V input: Open jumper J Close jumper L
For 2.8V output: Open jumper M Close jumper N For 1.8V output: Open jumper M Close jumper P
EventB In
EventA In
PPS Out
VCCIO voltage selection

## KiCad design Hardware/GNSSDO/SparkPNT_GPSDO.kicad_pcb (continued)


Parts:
A.1: Jumper_2_NC_Trace
B.1: Jumper_2_NC_Trace
C24, C49, C52, C71, C72: 2.2uF; C_0603_1608Metric; Voltage 10V; Tolerance 20%
C50, C51, C68, C69, C70: 0.1uF; C_0603_1608Metric; Voltage 25V; Tolerance 20%
C55: 33pF; C_0603_1608Metric; Voltage 50V; Tolerance 5%
C75, C76: 1.0nF; C_0603_1608Metric; Voltage 50V; Tolerance 10%
C.1: Jumper_2_NO
D16, D18: BAS16J; SOD-323
D17: PESD0402; C_0402_1005Metric
D.1: Jumper_2_NO
J8: SMA_Edge
R30: 33; R_0603_1608Metric
R46, R49, R50: 49.9; R_0603_1608Metric; Tolerance 1%
R52: 100k; R_0603_1608Metric
R56, R57, R58, R59: 1k; R_0603_1608Metric
R.1: Jumper_2_NC_Trace
S.1: Jumper_2_NO
SW5: DPDT_Slide_SMD_7.2x3.5mm; Slide_DPDT_SMD_7.2x3.5mm; Mfg Part# ABC
T.1: Jumper_2_NO
TP42, TP44: PTH; 1x01
U14, U15: 74LVC2T45DC; VSSOP8_SOT765-1
U17: LMV7219M5; SOT23-5

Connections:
1.8V: C52.1, C68.1, C69.1, C72.1, R56.1, R57.1, T.1.2 (B), U14.8 (VCCB); also elsewhere on the board
2.8V: C70.1, C71.1, D16.C, S.1.2 (B), U17.5 (V+); also elsewhere on the board
3.3V_P: C24.1, C50.1, U14.1 (VCCA), U14.5 (DIR), U15.1 (VCCA), U15.5 (DIR); also elsewhere on the board
10MHz: U14.2 (1A), U15.2 (1A), U15.3 (2A); also elsewhere on the board
10MHz_1.8V: C55.1, R30.1, SW5.3 (C)
10MHz_IN: C75.1, SW5.4 (A), TP42.1
10MHz_IN_1.8V: R58.1, R59.2, SW5.1 (A)
10MHz_IN_OUT: D17.2 (A2), J8.1 (In), SW5.5 (B)
10MHz_OUT: B.1.2 (B), D.1.2 (B), SW5.6 (C)
GND: C24.2, C49.2, C50.2, C51.2, C52.2, C55.2, C68.2, C69.2, C70.2, C71.2, C72.2, D17.1 (A1), D18.A, J8.2 (Ext), R50.1, R59.1, TP44.1, U14.3 (2A), U14.4 (GND), U15.4 (GND), U17.2 (V-); also elsewhere on the board
unnamed: A.1.1 (A), R46.2, U15.7 (1B)
unnamed: A.1.2 (B), B.1.1 (A), R46.1
unnamed: C75.2, C76.1, R50.2
unnamed: C.1.1 (A), R49.2, U15.6 (2B)
unnamed: C.1.2 (B), D.1.1 (A), R49.1
unnamed: R52.1, R58.2, U17.1
unnamed: C49.1, C51.1, R.1.1 (A), S.1.1 (A), T.1.1 (A), U15.8 (VCCB)
unnamed: R30.2, U14.7 (1B)
unnamed: R52.2, R57.2, U17.3 (+)
unnamed: C76.2, D16.A, D18.C, R56.2, U17.4 (-)
REF_IN: SW5.2 (B); also elsewhere on the board
VCCIO: R.1.2 (B); also elsewhere on the board

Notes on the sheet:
10MHz from TCXO
10MHz from SMA
10MHz to mosaic-T
10MHz In Input impedance: 50Ω Detection level: -14dBm Max supported level: +12dBm
For 50 Ohm output: Open jumper A Close jumper D
10MHz In / Out
Remove harmonics close to source
For 2.8V output: Open jumper R Close jumper S For 1.8V output: Open jumper R Close jumper T
10MHz 1.8V for mosaic-T
Level-Shifting 10MHz
10MHz to SMA
10MHz In / Out
10MHz Out



Board: 4 copper layers, 151.9 x 101.6 mm, 435 parts (101 on the bottom side), 169 nets.

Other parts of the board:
Ref**: Val**; OSHW_Logo_5mm
kibuzzard-65A7F5A7: G***; kibuzzard-65A7F5A7
kibuzzard-65A7F5BC: G***; kibuzzard-65A7F5BC
kibuzzard-65A7F5CF: G***; kibuzzard-65A7F5CF
kibuzzard-65A7F5E3: G***; kibuzzard-65A7F5E3
kibuzzard-65A7F440, kibuzzard-65A7F440#2: G***; kibuzzard-65A7F440
kibuzzard-65A7F499: G***; kibuzzard-65A7F499
kibuzzard-65A7F511, kibuzzard-65A7F511#2: G***; kibuzzard-65A7F511
kibuzzard-65A7F548, kibuzzard-65A7F548#2: G***; kibuzzard-65A7F548
kibuzzard-65A7F771, kibuzzard-65A7F771#2: G***; kibuzzard-65A7F771
kibuzzard-65A7F891, kibuzzard-65A7F891#2: G***; kibuzzard-65A7F891
kibuzzard-66A11DB0: G***; kibuzzard-66A11DB0
kibuzzard-66A11DCF: G***; kibuzzard-66A11DCF
kibuzzard-66A11DE1: G***; kibuzzard-66A11DE1
kibuzzard-66A11DF6: G***; kibuzzard-66A11DF6
kibuzzard-66A11E3D: G***; kibuzzard-66A11E3D
kibuzzard-66A11E07: G***; kibuzzard-66A11E07
kibuzzard-66A11E7B: G***; kibuzzard-66A11E7B
kibuzzard-66A11E14: G***; kibuzzard-66A11E14
kibuzzard-66A11E22: G***; kibuzzard-66A11E22
kibuzzard-66A11E31: G***; kibuzzard-66A11E31
kibuzzard-66A11E48: G***; kibuzzard-66A11E48
kibuzzard-66A11E61: G***; kibuzzard-66A11E61
kibuzzard-66A11EB6, kibuzzard-66A11EB6#2: G***; kibuzzard-66A11EB6
kibuzzard-66A11ECA, kibuzzard-66A11ECA#2: G***; kibuzzard-66A11ECA
kibuzzard-66A11ED7, kibuzzard-66A11ED7#2, kibuzzard-66A11ED7#3: G***; kibuzzard-66A11ED7
kibuzzard-66A11EE6, kibuzzard-66A11EE6#2: G***; kibuzzard-66A11EE6
kibuzzard-66A11EF1, kibuzzard-66A11EF1#2: G***; kibuzzard-66A11EF1
kibuzzard-66A11F9C: G***; kibuzzard-66A11F9C
kibuzzard-66A11F21, kibuzzard-66A11F21#2: G***; kibuzzard-66A11F21
kibuzzard-66A11F39, kibuzzard-66A11F39#2: G***; kibuzzard-66A11F39
kibuzzard-66A11FB3: G***; kibuzzard-66A11FB3
kibuzzard-66A11FEE, kibuzzard-66A11FEE#2: G***; kibuzzard-66A11FEE
kibuzzard-66A36AE8, kibuzzard-66A36AE8#2: G***; kibuzzard-66A36AE8
kibuzzard-66A36B1F: G***; kibuzzard-66A36B1F
kibuzzard-66A36BEE: G***; kibuzzard-66A36BEE
kibuzzard-66A120AA: G***; kibuzzard-66A120AA
kibuzzard-66A120EB: G***; kibuzzard-66A120EB
kibuzzard-66A121BE, kibuzzard-66A121BE#2: G***; kibuzzard-66A121BE
kibuzzard-66A121D2, kibuzzard-66A121D2#2: G***; kibuzzard-66A121D2
kibuzzard-66A122A4, kibuzzard-66A122A4#2: G***; kibuzzard-66A122A4
kibuzzard-66A122D2, kibuzzard-66A122D2#2: G***; kibuzzard-66A122D2
kibuzzard-66A211A5: G***; kibuzzard-66A211A5
kibuzzard-66A212C6: G***; kibuzzard-66A212C6
kibuzzard-66A212DB: G***; kibuzzard-66A212DB
kibuzzard-66A212E8: G***; kibuzzard-66A212E8
kibuzzard-66A212F8: G***; kibuzzard-66A212F8
kibuzzard-66A1201E: G***; kibuzzard-66A1201E
kibuzzard-66A1223B, kibuzzard-66A1223B#2: G***; kibuzzard-66A1223B
kibuzzard-66A2129F: G***; kibuzzard-66A2129F
kibuzzard-66A12010: G***; kibuzzard-66A12010
kibuzzard-66A12027: G***; kibuzzard-66A12027
kibuzzard-66A12034: G***; kibuzzard-66A12034
kibuzzard-66A12099: G***; kibuzzard-66A12099
kibuzzard-66A12140: G***; kibuzzard-66A12140
kibuzzard-66A12152: G***; kibuzzard-66A12152
kibuzzard-66A12161: G***; kibuzzard-66A12161
kibuzzard-66A12184, kibuzzard-66A12184#2: G***; kibuzzard-66A12184
kibuzzard-66A12197, kibuzzard-66A12197#2: G***; kibuzzard-66A12197
kibuzzard-66A12248, kibuzzard-66A12248#2: G***; kibuzzard-66A12248
kibuzzard-66A12259, kibuzzard-66A12259#2: G***; kibuzzard-66A12259
kibuzzard-66A12273, kibuzzard-66A12273#2: G***; kibuzzard-66A12273
kibuzzard-66A12315, kibuzzard-66A12315#2: G***; kibuzzard-66A12315
kibuzzard-66A12334, kibuzzard-66A12334#2: G***; kibuzzard-66A12334
kibuzzard-66A12372, kibuzzard-66A12372#2: G***; kibuzzard-66A12372
kibuzzard-66A21191: G***; kibuzzard-66A21191
kibuzzard-66A21255: G***; kibuzzard-66A21255
kibuzzard-66A21310: G***; kibuzzard-66A21310
kibuzzard-66A21341: G***; kibuzzard-66A21341
kibuzzard-66A21351: G***; kibuzzard-66A21351
kibuzzard-672DF8D1, kibuzzard-672DF8D1#2: G***; kibuzzard-672DF8D1
kibuzzard-672DF8E6, kibuzzard-672DF8E6#2, kibuzzard-672DF8E6#3, kibuzzard-672DF8E6#4: G***; kibuzzard-672DF8E6
kibuzzard-672DF612, kibuzzard-672DF612#2: G***; kibuzzard-672DF612
kibuzzard-672DF903, kibuzzard-672DF903#2: G***; kibuzzard-672DF903
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

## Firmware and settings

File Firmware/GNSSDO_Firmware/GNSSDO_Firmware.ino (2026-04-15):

/*
  July 30th, 2024
  SparkFun Electronics
  Paul Clark

  This is the firmware for the SparkFun SparkPNT GNSSDO / GNSSDO+.
  It runs on an ESP32 and communicates with the mosaic-T and SiT5358 / STP3593LF.
  The SiTime SiT5811 is also supported.

  Compiled with arduino-cli with ESP32 core v3.0.7

  If you are compiling manually in the Arduino IDE: set the board to "ESP32 Wrover Module"

  Settings are stored in the ESP32's file system LittleFS.

  Version history:
  1.0: Initial release
  1.1: Add TCP support
       The console can be accessed via TCP (COM3 is daisy chained to IPS1)
       On the v1.0 PCB, link:
       mosaic COM3 TX (TX3) to ESP32 GPIO 34
       mosaic COM3 RX (RX3) to ESP32 GPIO 23
  1.2: Add support for SiT5811 and STP3593LF oscillators
  1.3: Enable Ethernet by default
  1.4: Include a soft reset to work around "Ready for SUF Download"
  1.5: Print an ERROR if the display is not initialized, but allow firmware to continue
       Print mosaic-T version, S/N, Ethernet MAC + IP in menuMain
       Store previousIP in NVM - updated once per hour
       Print oscillator type in menuMain
  2.0: Add support for the GNSSDO Plus (GNSSDO+)
       Add RX Clock Drift (RxClkDrift) reporting
       Allow extra time when copying the mosaic-T configuration
       Print an error if no TCXO / OCXO is detected, but allow firmware to continue
       Print an ERROR if the display is not detected on I2C, but allow firmware to continue
  2.1: Resolves #10:
         Corrects an error an menuOperation where option 11 (ppsTimescale) was not wrapping correctly
       Resolves #11:
         OLED "Sys" will show "Fugro (GPS)" when the non-composite GPS time system is preferred and in use
         OLED "Sys" will show "Fugro (Galileo)" when the non-composite Galileo time system is preferred and in use
       Resolves #12:
         PVT Mode defaults to Static (after a Factory Reset) for best performance
         The user can modify the Mode and save the configuration if needed
  2.2: Add support for the MS8607 PHT sensor on GNSSDO Plus (GNSSDO+) - v02 PCB
         The MS8607 pressure, temperature and humidity are included in the periodic reports
         The OLED will display the temperature: to the right of "Error", when space is available
  3.0: Improved TCXO / OCXO startup - with no PPS uncertainty from StartupSync
         The firmware no longer uses setClockSyncThreshold (scst) StartupSync. StartupSync is off
           This prevents a shift in PPS with respect to the clock
           But it does mean that the initial bias error can be up to 500us and it can take a long
           time (~30 minutes) to get the bias down to zero by ramping the frequency
         The firmware no longer performs a soft reset if the bias is excessive on startup
         In STATE_GNSS_CONFIGURED
           The firmware waits for the ReceiverTime FINETIME bit to be set, indicating
           the setClockSyncThreshold Threshold (usec500) has been achieved
         In STATE_TCXO_WARMUP (GNSSDO+ only)
           The firmware waits for tcxoMinWarmup_s and for the OCXO temperature to become stable
         In STATE_GNSS_FINETIME
           The firmware disciplines the TCXO / OCXO frequency in a simple frequency locked loop
           The firmware exits this state when the change in the tcxoClockBias_ms (RxClkBias)
           is better than the specified rxStabilityForFrequencyLock
           The PI loop uses PkSteer and IkSteer when frequency locking
         In STATE_GNSS_FREQUENCY_LOCK
           The TCXO / OCXO bias is driven towards zero
           The initial bias error can be up to 500us, so we need to ramp the TCXO frequency one way
           ('up') and then back again ('down')
           We slowly accelerate the change in frequency, maintain it at tcxoRampRateLimit_sps, then decelerate
           The acceleration is set by the tcxoRampStepSize_s: 0.5ns/s for the STP3593; the SiT5358 can accelerate faster
           The ramps help to avoid blowing up the integrator
           When the ramps are complete, the tcxoClockBias_ms (RxClkBias) is re-checked
           This state is repeated if the bias is still excessive (> rxPhaseErrorLimit_s)
           The PI loop uses PkRamp and IkRamp when following the ramps
         In STATE_GNSS_PHASE_LOCK
           The LOCK LED will be illuminated when the firmware is in STATE_GNSS_PHASE_LOCK
           PPS output will be started when entering STATE_GNSS_PHASE_LOCK for the first time
           This state uses a conventional PLL to drive the tcxoClockBias_ms (RxClkBias) to zero
           The P and I terms are Pk and Ik
           When entering STATE_GNSS_PHASE_LOCK from STATE_GNSS_FREQUENCY_LOCK, the P and I terms
           are ramped from PkRamp and IkRamp to Pk and Ik over phaseLockPIRampTime_s (120s)
           This helps to avoid shocking the PI loop and sending the bias off for a walk...
*/

// This is passed in from compiler extra flags
#ifndef FIRMWARE_VERSION_MAJOR
#define FIRMWARE_VERSION_MAJOR 9
#define FIRMWARE_VERSION_MINOR 9
#endif

// Define the RTK board identifier:
//  This is an int which is unique to this variant of the RTK Surveyor hardware which allows us
//  to make sure that the settings stored in flash (LittleFS) are correct for this version of the RTK
//  (sizeOfSettings is not necessarily unique and we want to avoid problems when swapping from one variant to another)
//  It is the sum of:
//    the major firmware version * 0x10
//    the minor firmware version
#define RTK_IDENTIFIER (FIRMWARE_VERSION_MAJOR * 0x10 + FIRMWARE_VERSION_MINOR)

#include <Arduino.h>
#include <Wire.h>
#include "settings.h"

#define MAX_CPU_CORES 2
#define IDLE_COUNT_PER_SECOND 515400 //Found by empirical sketch
#define IDLE_TIME_DISPLAY_SECONDS 5
#define MAX_IDLE_TIME_COUNT (IDLE_TIME_DISPLAY_SECONDS * IDLE_COUNT_PER_SECOND)
#define MILLISECONDS_IN_A_SECOND 1000
#define MILLISECONDS_IN_A_MINUTE (60 * MILLISECONDS_IN_A_SECOND)
#define MILLISECONDS_IN_AN_HOUR (60 * MILLISECONDS_IN_A_MINUTE)
#define MILLISECONDS_IN_A_DAY (24 * MILLISECONDS_IN_AN_HOUR)

#define SECONDS_IN_A_MINUTE     60
#define SECONDS_IN_AN_HOUR      (60 * SECONDS_IN_A_MINUTE)
#define SECONDS_IN_A_DAY        (24 * SECONDS_IN_AN_HOUR)

// Hardware connections
//=-=-=-=-=-=-=-=-=-=-=-=-=-=-=-=-=-=-=-=-=-=-=-=-=-=-=-=-=-=-=-=-=-=-=-=-=-=-=-=-=-=-=-=-=
// These pins are set in beginBoard()
int pin_errorLED = -1;
int pin_lockLED = -1;

const int pin_serial0TX = 1;
const int pin_serial0RX = 3;

int pin_serial0TX_Alt = -1;
int pin_serial0RX_Alt = -1;

int pin_serial1TX = -1;
int pin_serial1RX = -1;
int pin_serial1CTS = -1;
int pin_serial1RTS = -1;

int pin_serial2TX = -1;
int pin_serial2RX = -1;

int pin_SDA1 = -1;
int pin_SCL1 = -1;

int pin_SDA2 = -1;
int pin_SCL2 = -1;

int pin_setupButton = -1;

//=-=-=-=-=-=-=-=-=-=-=-=-=-=-=-=-=-=-=-=-=-=-=-=-=-=-=-=-=-=-=-=-=-=-=-=-=-=-=-=-=-=-=-=-=

// I2C for oscillator and OLED
//-=-=-=-=-=-=-=-=-=-=-=-=-=-=-=-=-=-=-=-=-=-=-=-=-=-=-=-=-=-=-=-=-
#include <Wire.h>
//-=-=-=-=-=-=-=-=-=-=-=-=-=-=-=-=-=-=-=-=-=-=-=-=-=-=-=-=-=-=-=-=-

// LittleFS for storing settings
//-=-=-=-=-=-=-=-=-=-=-=-=-=-=-=-=-=-=-=-=-=-=-=-=-=-=-=-=-=-=-=-=-
#include <LittleFS.h>

char settingsFileName[60];                 // Contains the %s_Settings_%d.txt with current profile number set

//-=-=-=-=-=-=-=-=-=-=-=-=-=-=-=-=-=-=-=-=-=-=-=-=-=-=-=-=-=-=-=-=-

// Handy library for setting ESP32 system time to GNSS time
//-=-=-=-=-=-=-=-=-=-=-=-=-=-=-=-=-=-=-=-=-=-=-=-=-=-=-=-=-=-=-=-=-
#include <ESP32Time.h> //http://librarymanager/All#ESP32Time by FBiego v2.0.0
ESP32Time rtc;
unsigned long syncRTCInterval = 1000; // To begin, sync RTC every second. Interval can be increased once sync'd.
//-=-=-=-=-=-=-=-=-=-=-=-=-=-=-=-=-=-=-=-=-=-=-=-=-=-=-=-=-=-=-=-=-

#define platformPrefix      platformPrefixTable[productVariant] // Sets the prefix for broadcast names
#define platformFilePrefix  platformFilePrefixTable[productVariant] // Sets the prefix for logs and settings files

//-=-=-=-=-=-=-=-=-=-=-=-=-=-=-=-=-=-=-=-=-=-=-=-=-=-=-=-=-=-=-=-=-

// These globals are updated regularly via the SBF parser

// ReceiverTime 5914
volatile unsigned long gnssTimeArrivalMillis = 0;
volatile bool gnssTimeUpdated[3] = { false, false, false }; // RTC, TCXO, printConditions
volatile uint32_t gnssTOW_ms = 0;
volatile uint8_t gnssDay = 0;
volatile uint8_t gnssMonth = 0;
volatile uint16_t gnssYear = 0;
volatile uint8_t gnssHour = 0;
volatile uint8_t gnssMinute = 0;
volatile uint8_t gnssSecond = 0;
volatile bool gnssWNSet = false;
volatile bool gnssToWSet = false;
volatile bool gnssFineTime = false;

// PVTGeodetic 4007
volatile unsigned long gnssPVTArrivalMillis = 0;
volatile bool gnssPVTUpdated = false;
volatile double gnssLatitude_d = 0.0;
volatile double gnssLongitude_d = 0.0;
volatile float gnssAltitude_m = 0.0;
volatile uint8_t gnssTimeSys = 255; // Unknown
volatile uint8_t gnssError = 255; // Unknown
volatile double gnssClockBias_ms = 0.0;
volatile float gnssClockDrift_ppm = 0.0;

// IPStatus 4058
volatile uint8_t ethernetMACAddress[6] = { 0,0,0,0,0,0 }; // Display this address in the system menu
IPAddress gnssIP = IPAddress((uint32_t)0);

// ReceiverSetup 5902
char RxSerialNumber[21] = {0};
char RxVersion[21] = {0};
char ProductName[41] = {0};

// FugroTimeOffset 4255
// fugroTimeSystem fugroTimeSystems[] is in settings.h

//=-=-=-=-=-=-=-=-=-=-=-=-=-=-=-=-=-=-=-=-=-=-=-=-=-=-=-=-=-=-=-=-=-=-=-=-=-=-=-=-=-=-=-=-=

// GPS parse table
//=-=-=-=-=-=-=-=-=-=-=-=-=-=-=-=-=-=-=-=-=-=-=-=-=-=-=-=-=-=-=-=-=-=-=-=-=-=-=-=-=-=-=-=-=
// Define the parsers that get included
#define PARSE_NMEA_MESSAGES
#define PARSE_RTCM_MESSAGES
#define PARSE_SBF_MESSAGES

// Build the GPS_PARSE_TABLE macro
#include "GpsMessageParser.h" // Include the parser

// Create the GPS message parse table instance
GPS_PARSE_TABLE;

//=-=-=-=-=-=-=-=-=-=-=-=-=-=-=-=-=-=-=-=-=-=-=-=-=-=-=-=-=-=-=-=-=-=-=-=-=-=-=-=-=-=-=-=-=

#include <driver/uart.h>      // Required for uart_set_rx_full_threshold() on cores <v2.0.5
HardwareSerial serialConsole(0); // Use UART0 for Console
HardwareSerial serialGNSS(1); // Use UART1 for GNSS
HardwareSerial serialGNSSConfig(2); // Use UART2 for GNSS configuration

#define SERIAL_SIZE_TX 512
uint8_t wBuffer[SERIAL_SIZE_TX]; // Buffer for writing from incoming SPP to F9P

// Array of start of sentence offsets into the ring buffer
#define AMOUNT_OF_RING_BUFFER_DATA_TO_DISCARD (settings.gnssHandlerBufferSize >> 2)
#define AVERAGE_SENTENCE_LENGTH_IN_BYTES    32
RING_BUFFER_OFFSET * rbOffsetArray;
uint16_t rbOffsetEntries;

uint8_t *ringBuffer; // Buffer for reading from F9P. At 230400bps, 23040 bytes/s. If SD blocks for 250ms, we need 23040
                     // * 0.25 = 5760 bytes worst case.
TaskHandle_t gnssReadTaskHandle =
    nullptr; // Store handles so that we can kill them if user goes into WiFi NTRIP Server mode
const int gnssReadTaskStackSize = 2500;

TaskHandle_t handleGnssDataTaskHandle = nullptr;
const int handleGnssDataTaskStackSize = 3000;

TaskHandle_t pinUART1TaskHandle = nullptr; // Dummy task to start hardware on an assigned core
volatile bool uart1pinned = false; // This variable is touched by core 0 but checked by core 1. Must be volatile.

TaskHandle_t pinI2C1TaskHandle = nullptr; // Dummy task to start hardware on an assigned core
volatile bool i2c1Pinned = false; // This variable is touched by core 0 but checked by core 1. Must be volatile.

TaskHandle_t pinI2C2TaskHandle = nullptr; // Dummy task to start hardware on an assigned core
volatile bool i2c2Pinned = false; // This variable is touched by core 0 but checked by core 1. Must be volatile.

//=-=-=-=-=-=-=-=-=-=-=-=-=-=-=-=-=-=-=-=-=-=-=-=-=-=-=-=-=-=-=-=-=-=-=-=-=-=-=-=-=-=-=-=-=

// External Display
//=-=-=-=-=-=-=-=-=-=-=-=-=-=-=-=-=-=-=-=-=-=-=-=-=-=-=-=-=-=-=-=-=-=-=-=-=-=-=-=-=-=-=-=-=
#include <SparkFun_Qwiic_OLED.h> //http://librarymanager/All#SparkFun_Qwiic_Graphic_OLED

DisplayType displayType = DISPLAY_MAX_NONE;

//=-=-=-=-=-=-=-=-=-=-=-=-=-=-=-=-=-=-=-=-=-=-=-=-=-=-=-=-=-=-=-=-=-=-=-=-=-=-=-=-=-=-=-=-=

// I2C Bus
//=-=-=-=-=-=-=-=-=-=-=-=-=-=-=-=-=-=-=-=-=-=-=-=-=-=-=-=-=-=-=-=-=-=-=-=-=-=-=-=-=-=-=-=-=
TwoWire *i2c_1 = nullptr; // OLED (400kHz)
TwoWire *i2c_2 = nullptr; // TCXO (100kHz)
TwoWire *i2cDisplay = nullptr;
TwoWire *i2cTCXO = nullptr;
TwoWire *i2cPHT = nullptr;

//=-=-=-=-=-=-=-=-=-=-=-=-=-=-=-=-=-=-=-=-=-=-=-=-=-=-=-=-=-=-=-=-=-=-=-=-=-=-=-=-=-=-=-=-=

// DCTCXO
//=-=-=-=-=-=-=-=-=-=-=-=-=-=-=-=-=-=-=-=-=-=-=-=-=-=-=-=-=-=-=-=-=-=-=-=-=-=-=-=-=-=-=-=-=
GNSSDO_TCXO *myTCXO;

char oscillatorType[20] = {0};

//=-=-=-=-=-=-=-=-=-=-=-=-=-=-=-=-=-=-=-=-=-=-=-=-=-=-=-=-=-=-=-=-=-=-=-=-=-=-=-=-=-=-=-=-=

// Low frequency tasks
//=-=-=-=-=-=-=-=-=-=-=-=-=-=-=-=-=-=-=-=-=-=-=-=-=-=-=-=-=-=-=-=-=-=-=-=-=-=-=-=-=-=-=-=-=
#include <Ticker.h>

//=-=-=-=-=-=-=-=-=-=-=-=-=-=-=-=-=-=-=-=-=-=-=-=-=-=-=-=-=-=-=-=-=-=-=-=-=-=-=-=-=-=-=-=-=

// Buttons - Interrupt driven and debounce
//-=-=-=-=-=-=-=-=-=-=-=-=-=-=-=-=-=-=-=-=-=-=-=-=-=-=-=-=-=-=-=-=-
#include <JC_Button.h>      //http://librarymanager/All#JC_Button v2.1.2
Button *setupBtn = nullptr; // We can't instantiate the buttons here because we don't yet know what pin numbers to use

TaskHandle_t ButtonCheckTaskHandle = nullptr;
const uint8_t ButtonCheckTaskPriority = 1; // 3 being the highest, and 0 being the lowest
const int buttonTaskStackSize = 2000;

//=-=-=-=-=-=-=-=-=-=-=-=-=-=-=-=-=-=-=-=-=-=-=-=-=-=-=-=-=-=-=-=-=-=-=-=-=-=-=-=-=-=-=-=-=

// MS8607 PHT sensor - on GNSSDO+
//-=-=-=-=-=-=-=-=-=-=-=-=-=-=-=-=-=-=-=-=-=-=-=-=-=-=-=-=-=-=-=-=-
#include <SparkFun_PHT_MS8607_Arduino_Library.h> // http://librarymanager/All#SparkFun_PHT_MS8607
MS8607 *phtSensor = nullptr;
float pressure;
float temperature;
float humidity;

//-=-=-=-=-=-=-=-=-=-=-=-=-=-=-=-=-=-=-=-=-=-=-=-=-=-=-=-=-=-=-=-=-

// Global variables
//-=-=-=-=-=-=-=-=-=-=-=-=-=-=-=-=-=-=-=-=-=-=-=-=-=-=-=-=-=-=-=-=-
uint8_t wifiMACAddress[6] = { 0,0,0,0,0,0 };     // Display this address in the system menu
char deviceName[70];
const uint16_t menuTimeout = 60 * 10; // Menus will exit/timeout after this number of seconds
int systemTime_minutes = 0;           // Used to test if logging is less than max minutes
bool inMainMenu = false;              // Set true when in the serial config menu system.

uint32_t lastDisplayUpdate = 0;
bool forceDisplayUpdate = false;
uint32_t lastSystemStateUpdate = 0;
bool forceSystemStateUpdate = false; // Set true to avoid update wait
uint32_t lastPrintConditions = 0;

long lastStackReport = 0;         // Controls the report rate of stack highwater mark within a task
uint32_t lastHeapReport = 0;      // Report heap every 1s if option enabled
uint32_t lastTaskHeapReport = 0;  // Report task heap every 1s if option enabled

uint32_t rtcmLastReceived = 0;

unsigned long splashStart = 0; // Controls how long the splash is displayed for. Currently min of 2s.

unsigned long startTime = 0;           // Used for checking longest running functions

TaskHandle_t idleTaskHandle[MAX_CPU_CORES];
uint32_t max_idle_count = MAX_IDLE_TIME_COUNT;

uint16_t failedParserMessages_RTCM = 0;
uint16_t failedParserMessages_NMEA = 0;
uint16_t failedParserMessages_SBF = 0;

bool rtcSyncd = false;      // Set to true when the RTC has been sync'd
bool ppsStarted = false;    // Set to true when PPS have started. Cleared by menu changes.

//-=-=-=-=-=-=-=-=-=-=-=-=-=-=-=-=-=-=-=-=-=-=-=-=-=-=-=-=-=-=-=-=-

#define DEAD_MAN_WALKING_ENABLED    0

#if DEAD_MAN_WALKING_ENABLED

// Developer subsitutions enabled by changing DEAD_MAN_WALKING_ENABLED
// from 0 to 1
volatile bool deadManWalking;
#define DMW_if                  if (deadManWalking)
#define DMW_c(string)           DMW_if systemPrintf("%s called\r\n", string);
#define DMW_ds(routine, dataStructure) DMW_if routine(dataStructure, dataStructure->state);
#define DMW_m(string)           DMW_if systemPrintln(string);
#define DMW_r(string)           DMW_if systemPrintf("%s returning\r\n",string);
#define DMW_rs(string, status)  DMW_if systemPrintf("%s returning %d\r\n",string, (int32_t)status);
#define DMW_st(routine, state)  DMW_if routine(state);

#define START_DEAD_MAN_WALKING                          \
{                                                       \
    deadManWalking = true;                              \
                                                        \
    /* Output as much as possible to identify the location of the failure */    \
    settings.printDebugMessages = true;                 \
    settings.enableI2Cdebug = true;                     \
    settings.enableHeapReport = true;                   \
    settings.enableTaskReports = true;                  \
    settings.enablePrintState = true;                   \
    settings.enablePrintConditions = 2;                 \
    settings.enablePrintIdleTime = true;                \
    settings.enablePrintBadMessages = true;             \
    settings.enablePrintRingBufferOffsets = true;       \
    settings.enablePrintStates = true;                  \
    settings.enablePrintDuplicateStates = true;         \
    settings.enablePrintRtcSync = true;                 \
    settings.enablePrintBufferOverrun = true;           \
}

#else   // 0

// Production substitutions
#define deadManWalking              0
#define DMW_if                      if (0)
#define DMW_c(string)
#define DMW_ds(routine, dataStructure)
#define DMW_m(string)
#define DMW_r(string)
#define DMW_rs(string, status)
#define DMW_st(routine, state)

#endif  // 0

//-=-=-=-=-=-=-=-=-=-=-=-=-=-=-=-=-=-=-=-=-=-=-=-=-=-=-=-=-=-=-=-=-
// Initialize any globals that can't easily be given default values

void initializeGlobals()
{
}

//-=-=-=-=-=-=-=-=-=-=-=-=-=-=-=-=-=-=-=-=-=-=-=-=-=-=-=-=-=-=-=-=-
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
void loop()
{
    DMW_c("updateSystemState");
    updateSystemState();

    DMW_c("updatePHT");
    updatePHT(); // Read the pressure, temperature and humidity

    DMW_c("updateTcxoTemperature");
    updateTcxoTemperature(); // Read the TCXO temperature sensor - if present

    DMW_c("updateDisplay");
    updateDisplay();

    DMW_c("updateRTC");
    updateRTC(); // Set system time to GNSS once we have fix

    DMW_c("reportHeap");
    reportHeap(); // If debug enabled, report free heap

    DMW_c("updateSerial");
    updateSerial(); // Menu system via ESP32 USB connection

    DMW_c("printConditions");
    printConditions(); // Periodically print GNSS coordinates etc. if enabled

    // A small delay prevents panic if no other I2C or functions are called
    delay(10);
}

// Perform any essential background tasks while waiting for input from the user
// This is just regular code, not a true task. If we ran it in a task, we'd need semaphores etc.
// to avoid COM port collisions...
void performBackgroundTasks()
{
    DMW_c("updateSystemState");
    updateSystemState(); // Keep updating the system state. This keeps the TCXO updated.

    delay(1); // Yield to processor
}

// Once we have a fix, sync system clock to GNSS
void updateRTC()
{
    static uint16_t syncAge = 0;

    static bool firstTime = true;
    if (firstTime)
    {
        gnssTimeUpdated[0] = false; // This ensures gnssTimeUpdated[0] isn't stale
        firstTime = false;
    }

    if (online.gnss == true) // Only do this if the GNSS is online
    {
        if (gnssTimeUpdated[0]) // Only do this if we have fresh time
        {
            gnssTimeUpdated[0] = false;

            syncAge++; // Update syncAge every second
            if (syncAge == 3600) // Wrap every hour
                syncAge = 0;

            if (gnssWNSet && gnssToWSet && gnssFineTime) // Only do this if FineTime is set
            {
                // Only do this if the rtc has not been sync'd previously
                // or if it is an hour since the last sync
                if ((online.rtc == false) || (syncAge == 0))
                {
                    // To perform the time zone adjustment correctly, it's easiest if we convert the GNSS time and date
                    // into Unix epoch first and then correct for the arrival time
                    uint32_t epochSecs;
                    uint32_t epochMillis;
                    convertGnssTimeToEpoch(&epochSecs, &epochMillis);
                    
                    epochMillis += millis() - gnssTimeArrivalMillis; // Remove the lag

                    // Set the internal system time
                    rtc.setTime(epochSecs, epochMillis * 1000);

                    online.rtc = true;

                    if (settings.enablePrintRtcSync)
                    {
                        systemPrint("System time set to: ");
                        systemPrintln(rtc.getDateTime(true));
                    }
                }
            }
        }
    }
}

void updatePHT()
{
    static unsigned long previousUpdate = 0;

    if (online.pht) // Only do this if the PHT is online
    {
        if ((millis() - previousUpdate) > 1000) // Update once per second
        {
            phtSensor->read_temperature_pressure_humidity(&temperature, &pressure, &humidity);
            previousUpdate = millis();
        }
    }
}

void updateTcxoTemperature()
{
    static unsigned long previousUpdate = 0;

    if (presentTcxoTemperature) // Only do this if the sensor is present
    {
        if ((millis() - previousUpdate) > 1000) // Update once per second
        {
            tcxoTemperature = (double)myTCXO->getTcxoTemperature();
            previousUpdate = millis();
        }
    }
}

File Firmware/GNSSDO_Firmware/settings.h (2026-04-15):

#ifndef __SETTINGS_H__
#define __SETTINGS_H__

#include "GNSSDO_TCXO.h"
#include "SiT5358_TCXO.h"
#include "SiT5811_OCXO.h"
#include "STP3593LF_OCXO.h"

// System can enter a variety of states
typedef enum
{
    STATE_GNSS_NOT_CONFIGURED = 0,
    STATE_GNSS_CONFIGURED, // GNSS has been configured: PVTGeodetic+ReceiverTime+IPStatus enabled on COM1
    STATE_GNSS_ERROR_BEFORE_FINETIME, // Error is non-zero before FineTime is true
    STATE_TCXO_WARMUP, // Wait for the TCXO temperature to become stable - if sensor is present
    STATE_GNSS_ERROR_DURING_WARMUP,
    STATE_GNSS_FINETIME, // GNSS FINETIME bit is set. Oscillator control can begin in frequency locked mode
    STATE_GNSS_ERROR_AFTER_FINETIME, // PVTGeodetic Error is non-zero. Oscillator updates are paused
    STATE_GNSS_FREQUENCY_LOCK, // GNSS is frequency locked. Minimise the bias without blowing up the integrator
    STATE_GNSS_ERROR_AFTER_FREQUENCY_LOCK,
    STATE_GNSS_PHASE_LOCK, // GNSS has achieved phase lock. Maintain the bias using the PLL
    STATE_GNSS_ERROR_AFTER_PHASE_LOCK,
    STATE_NOT_SET, // Must be last on list
} SystemState;
volatile SystemState systemState = STATE_NOT_SET;
SystemState lastSystemState = STATE_NOT_SET;
SystemState requestedSystemState = STATE_NOT_SET;
bool newSystemStateRequested = false;

typedef struct
{
    const SystemState systemState;
    const char *stateName;
} SystemStatesName;

const SystemStatesName SystemStatesNames[] = {
    { STATE_GNSS_NOT_CONFIGURED, "NOT_CONFIGURED" },
    { STATE_GNSS_CONFIGURED, "CONFIGURED" },
    { STATE_GNSS_ERROR_BEFORE_FINETIME, "ERROR_BEFORE_FINETIME" },
    { STATE_TCXO_WARMUP, "WARMUP" },
    { STATE_GNSS_ERROR_DURING_WARMUP, "ERROR_DURING_WARMUP" },
    { STATE_GNSS_FINETIME, "FINETIME" },
    { STATE_GNSS_ERROR_AFTER_FINETIME, "ERROR_AFTER_FINETIME" },
    { STATE_GNSS_FREQUENCY_LOCK, "FREQUENCY_LOCK" },
    { STATE_GNSS_ERROR_AFTER_FREQUENCY_LOCK, "ERROR_AFTER_FREQUENCY_LOCK" },
    { STATE_GNSS_PHASE_LOCK, "PHASE_LOCK" },
    { STATE_GNSS_ERROR_AFTER_PHASE_LOCK, "ERROR_AFTER_PHASE_LOCK" },
    { STATE_NOT_SET, "NOT_SET" },
};

const int numSystemStatesNames = sizeof(SystemStatesNames) / sizeof(SystemStatesNames[0]);

typedef enum
{
    GNSSDO = 0,
    GNSSDO_PLUS,
    // Add new values just above this line
    GNSSDO_UNKNOWN,
} ProductVariant;
ProductVariant productVariant = GNSSDO_UNKNOWN;

const char *const productDisplayNames[] = {
    "GNSSDO",
    "GNSSDO+",
    // Add new values just above this line
    "Unknown",
};
const int productDisplayNamesEntries = sizeof(productDisplayNames) / sizeof(productDisplayNames[0]);

const char *const platformFilePrefixTable[] = {
    "SFE_GNSSDO",
    "SFE_GNSSDO_PLUS",
    // Add new values just above this line
    "SFE_Unknown",
};
const int platformFilePrefixTableEntries = sizeof(platformFilePrefixTable) / sizeof(platformFilePrefixTable[0]);

const char *const platformPrefixTable[] = {
    "GNSSDO",
    "GNSSDO_PLUS",
    // Add new values just above this line
    "Unknown",
};
const int platformPrefixTableEntries = sizeof(platformPrefixTable) / sizeof(platformPrefixTable[0]);

typedef enum
{
    RTCM_TRANSPORT_STATE_WAIT_FOR_PREAMBLE_D3 = 0,
    RTCM_TRANSPORT_STATE_READ_LENGTH_1,
    RTCM_TRANSPORT_STATE_READ_LENGTH_2,
    RTCM_TRANSPORT_STATE_READ_MESSAGE_1,
    RTCM_TRANSPORT_STATE_READ_MESSAGE_2,
    RTCM_TRANSPORT_STATE_READ_DATA,
    RTCM_TRANSPORT_STATE_READ_CRC_1,
    RTCM_TRANSPORT_STATE_READ_CRC_2,
    RTCM_TRANSPORT_STATE_READ_CRC_3,
    RTCM_TRANSPORT_STATE_CHECK_CRC
} RtcmTransportState;

typedef enum
{
    MOSAIC_TIME_SYSTEM_GPS = 0,
    MOSAIC_TIME_SYSTEM_GALILEO = 1,
    MOSAIC_TIME_SYSTEM_GLONASS = 3,
    MOSAIC_TIME_SYSTEM_BEIDOU = 4,
    MOSAIC_TIME_SYSTEM_QZSS = 5,
    MOSAIC_TIME_SYSTEM_FUGRO = 100,
} mosaicTimeSystemIds;

// FugroTimeOffset 4255
typedef struct {
    const uint8_t TimeSystem;
    const uint8_t SysUsage;
    const char name[8];
    double RxClkBias_ms;
    float RxClkDrift_ppm;
    bool updated;
} fugroTimeSystem;

fugroTimeSystem fugroTimeSystems[] = {
    { MOSAIC_TIME_SYSTEM_GPS, 0x01, "GPS", 0.0, false },
    { MOSAIC_TIME_SYSTEM_GALILEO, 0x02, "Galileo", 0.0, false },
    { MOSAIC_TIME_SYSTEM_GLONASS, 0x04, "GLONASS", 0.0, false },
    { MOSAIC_TIME_SYSTEM_BEIDOU, 0x08, "BeiDou", 0.0, false },
    { MOSAIC_TIME_SYSTEM_QZSS, 0, "QZSS", 0.0, false },
    { MOSAIC_TIME_SYSTEM_FUGRO, 0, "Fugro", 0.0, false },
};

const int NUM_FUGRO_CLK_BIASES = sizeof(fugroTimeSystems) / sizeof(fugroTimeSystems[0]);

// Convert id (0,1,3,4,5,100) to index (0-5). Return NUM_FUGRO_CLK_BIASES (6) if id is invalid
uint8_t mosaicTimeSystemIndexFromId(uint8_t id) {
    int i = 0;
    for (; i < NUM_FUGRO_CLK_BIASES; i++) {
        if (fugroTimeSystems[i].TimeSystem == id)
            break;
    }
    return (uint8_t)i;
}
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

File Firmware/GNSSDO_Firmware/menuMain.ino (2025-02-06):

// Check to see if we've received serial over USB
void updateSerial()
{
    if (systemAvailable())
    {
        systemRead();

        menuMain(); // Present user menu
    }
}

// Display the options
// If user doesn't respond within a few seconds, return to main loop
void menuMain()
{
    inMainMenu = true;
    displaySerialConfig(); // Display 'Serial Config' while user is configuring

    while (1)
    {
        systemPrintln();
        char versionString[21];
        getFirmwareVersion(versionString, sizeof(versionString));
        systemPrintf("SparkPNT %s Firmware %s\r\n", platformPrefix, versionString);

        systemPrint("ESP32 WiFi MAC Address: ");
        systemPrintf("%02X:%02X:%02X:%02X:%02X:%02X\r\n", wifiMACAddress[0], wifiMACAddress[1], wifiMACAddress[2],
                     wifiMACAddress[3], wifiMACAddress[4], wifiMACAddress[5]);

        systemPrintf("Oscillator:             %s\r\n", oscillatorType);

        systemPrintf("GNSS:                   %s version %s S/N %s\r\n", ProductName, RxVersion, RxSerialNumber);

        systemPrint("Ethernet MAC Address:   ");
        systemPrintf("%02X:%02X:%02X:%02X:%02X:%02X\r\n", ethernetMACAddress[0], ethernetMACAddress[1], ethernetMACAddress[2],
                     ethernetMACAddress[3], ethernetMACAddress[4], ethernetMACAddress[5]);

        systemPrintf("Previous IP address:    %s\r\n", IPAddress(settings.previousIP).toString().c_str());

        systemPrintf("Current IP address:     %s\r\n", gnssIP.toString().c_str());

        if (settings.enableTCPServer)
            systemPrintf("TCP Server is enabled:  TCP Port %d\r\n", settings.tcpServerPort);

        // Display the uptime
        uint64_t uptimeMilliseconds = millis();
        uint32_t uptimeDays = 0;
        byte uptimeHours = 0;
        byte uptimeMinutes = 0;
        byte uptimeSeconds = 0;

        uptimeDays = uptimeMilliseconds / MILLISECONDS_IN_A_DAY;
        uptimeMilliseconds %= MILLISECONDS_IN_A_DAY;

        uptimeHours = uptimeMilliseconds / MILLISECONDS_IN_AN_HOUR;
        uptimeMilliseconds %= MILLISECONDS_IN_AN_HOUR;

        uptimeMinutes = uptimeMilliseconds / MILLISECONDS_IN_A_MINUTE;
        uptimeMilliseconds %= MILLISECONDS_IN_A_MINUTE;

        uptimeSeconds = uptimeMilliseconds / MILLISECONDS_IN_A_SECOND;
        uptimeMilliseconds %= MILLISECONDS_IN_A_SECOND;

        systemPrint("System Uptime:          ");
        systemPrintf("%d %02d:%02d:%02d.%03lld\r\n", uptimeDays, uptimeHours, uptimeMinutes, uptimeSeconds,
                     uptimeMilliseconds);

        systemPrintf("Rejected by parser:     %d NMEA / %d RTCM / %d SBF\r\n", failedParserMessages_NMEA,
                     failedParserMessages_RTCM, failedParserMessages_SBF);

        systemPrintln();
        systemPrintln("Menu: Main");

        systemPrintln("c) Configure operation");

        systemPrintln("d) Debug software");

        systemPrintln("r) Reset all settings to default");

        systemPrintln("x) Exit");

        byte incoming = getCharacterNumber();

        if (incoming == 'c')
            menuOperation();
        else if (incoming == 'd')
            menuDebugSoftware();
        else if (incoming == 'r')
        {
            systemPrintln("\r\nResetting to factory defaults. Press 'y' to confirm:");
            byte bContinue = getCharacterNumber();
            if (bContinue == 'y')
            {
                factoryReset(false);
            }
            else
                systemPrintln("Reset aborted");
        }

        else if (incoming == 'x')
            break;
        else if (incoming == INPUT_RESPONSE_GETCHARACTERNUMBER_EMPTY)
            break;
        else if (incoming == INPUT_RESPONSE_GETCHARACTERNUMBER_TIMEOUT)
            break;
        else
            printUnknown(incoming);
    }

    configureGNSSTCPServer(); // Configure TCP

    if (settings.enableTCPServer)
        systemPrintf("TCP Server is enabled. Please connect on %s:%d to view the console\r\n",
                    gnssIP.toString().c_str(), settings.tcpServerPort);
        
    beginConsole(115200, true); // Swap to Alt pins if TCP is enabled

    recordSystemSettings(); // Once all menus have exited, record the new settings to LittleFS and config file

    clearBuffer();           // Empty buffer of any newline chars
    inMainMenu = false;
}

// Erase all settings. Upon restart, unit will use defaults
void factoryReset(bool alreadyHasSemaphore)
{
    displaySytemReset(); // Display friendly message on OLED

    gnssHardReset(); // Probably redundant as initializeGNSS() will be called on restart

    tasksStopUART1();

    systemPrintln("Formatting internal file system...");
    LittleFS.format();

    systemPrintln("Settings erased successfully. Rebooting. Goodbye!");
    delay(2000);
    ESP.restart();
}

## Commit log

2024-07-21 More WIP
    [Ethernet.kicad_sch, Power.kicad_sch, SparkFun_RTK_mosaic-T.kicad_pcb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]
2024-07-23 Schematic complete
    [GNSS.kicad_sch, Level_Shifting.kicad_sch, Oscillator.kicad_sch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]
2024-07-23 PCB WIP
    [SparkFun_RTK_mosaic-T.kicad_pcb]
2024-07-23 Board edge components placed
    [SparkFun_RTK_mosaic-T.kicad_pcb]
2024-07-24 Ready for airwire review
    [GNSS.kicad_sch, Level_Shifting.kicad_sch, Power.kicad_sch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]
2024-07-24 Add more silk
    [SparkFun_RTK_mosaic-T.kicad_pcb]
2024-07-25 Ready for routing
    [SparkFun_RTK_mosaic-T.kicad_pcb]
2024-07-25 Routing WIP
    [Ethernet.kicad_sch, USB.kicad_sch]
2024-07-26 Add new PROD_IDs
    [GNSS.kicad_sch, Level_Shifting.kicad_sch, SparkFun_RTK_mosaic-T.kicad_sch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]
2024-07-27 Updates to match latest KiCad library
    [Ethernet.kicad_sch, Level_Shifting.kicad_sch, Power.kicad_sch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]
2024-07-30 Docs updates
    [RTK_mosaic-X5-Panel.GBL, RTK_mosaic-X5-Panel.GBO, RTK_mosaic-X5-Panel.GBP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]
2024-07-30 Firmware very WIP
    [partitions.csv]
2024-08-12 Add build workflows
    [app3M_fat9M_16MB.csv]
2024-08-14 Update 3D models on board
    Still missing the RP-SMA but otherwise good to go.
2024-08-15 Update the 3D models.
    [Ethernet.kicad_sch, GNSS.kicad_sch, Level_Shifting.kicad_sch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]
2024-08-29 Fix SiT5358 symbol background
    [GNSS.kicad_sch]
2024-09-19 Add CSV printConditions
2024-09-19 Correct NVM long settings
    [NVM.ino]
2024-09-19 Default to 1s periodic print
2024-09-24 Add soft and hard reset
    [Display.ino, GNSS.ino, States.ino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]
2024-09-24 Better RTC sync and printConditions
2024-10-01 PCB symbol updates
    [Ethernet.kicad_sch, GNSS.kicad_sch, Level_Shifting.kicad_sch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]
2024-10-18 Updates for v1.0 PCB
    [Ethernet.kicad_sch, GNSS.kicad_sch, Level_Shifting.kicad_sch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]
2024-10-19 Update logo symbol and footprint
    [SparkFun_RTK_mosaic-T.kicad_sch]
2024-10-21 Add jumpers for 2.8V and 1.8V In / Out
    [Level_Shifting.kicad_sch, Level_Shifting_10MHz.kicad_sch, SparkFun_RTK_mosaic-T.kicad_sch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]
2024-10-23 Add mounting holes for SiT5811 / Rakon oscillator
    [GNSS.kicad_sch, Level_Shifting.kicad_sch, Level_Shifting_10MHz.kicad_sch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]
2024-10-24 Final changes before name change
    [GNSS.kicad_sch, Level_Shifting.kicad_sch, Level_Shifting_10MHz.kicad_sch]
2024-10-24 Change KiCad file name to SparkPNT_GPSDO
    [Power.kicad_sch, SparkFun_RTK_mosaic-T.kicad_sch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]
2024-11-08 Final tweaks
    [Level_Shifting.kicad_sch, Power.kicad_sch, SparkPNT_GPSDO.kicad_sch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]
2024-11-11 Update docs PCB images
2024-11-20 Rename to GNSSDO
    [Level_Shifting.kicad_sch, SparkPNT_GPSDO.kicad_sch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]
2024-12-31 Correct links. Remove references to "RTK"
    [Begin.ino, Display.ino, GNSSDO_Firmware.ino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]
2025-01-06 Add GNSSDO Plus hardware
    [Ethernet.kicad_sch, GNSS.kicad_sch, Level_Shifting.kicad_sch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]
2025-01-09 GNSSDO Plus: add 3-way splitter
    [GNSS.kicad_sch, Level_Shifting.kicad_sch, Level_Shifting_10MHz.kicad_sch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]
2025-01-09 Firmware v1.4 - add soft reset to clear "Ready for SUF Download"
    [GNSS.ino]
2025-01-09 GNSSDO+ WIP
    [Level_Shifting.kicad_sch, Level_Shifting_10MHz.kicad_sch, Power.kicad_sch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]
2025-01-13 GNSSDO+ routed
    [Level_Shifting.kicad_sch, Level_Shifting_10MHz.kicad_sch, Oscillator.kicad_sch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]
2025-01-13 GNSSDO+ : update symbols and footprints
    [Ethernet.kicad_sch, GNSS.kicad_sch, Level_Shifting.kicad_sch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]
2025-01-14 GNSSDO Plus - ready for review
    [Ethernet.kicad_sch, GNSS.kicad_sch, Level_Shifting.kicad_sch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]
2025-01-20 GNSSDO+ PCB ready for protos
    [Level_Shifting.kicad_sch, Level_Shifting_10MHz.kicad_sch, SparkPNT_GNSSDO_Plus.kicad_sch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]
2025-02-06 Add ERROR print if no display is detected
    [Display.ino]
2025-02-06 Store previousIP. Print previous and current IP in menuMain
    Print RX name, version and S/N in menuMain
    Print oscillatorType in menuMain
    [Begin.ino, GNSS.ino, GNSSDO_Firmware.ino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]
2025-02-25 Switch bullet point style
    Switch from `*` to `-` in markdown
2025-02-25 Remove ASCII space
    Icon spacing in header fixed in mkdocs-material theme
2025-02-26 Fix QR Codes
    Update stylesheet
    - Removed `iframe` element, to hide containers for videos when printing
    - Adjusted use classification for images in table
    - Fixes comparison table functionality
    - Removed misspelled file
    Update `troubleshooting_tips.md`
    - Added QR code for hookup guide
    Update `introduction.md`
    - Adjusted QR code for purchase button
    - Added QR code for product video
    - Removed width styling for images in table
    - Defined in stylesheet
2025-02-27 Update header and links
    Clarify headers to USB drivers
2025-02-27 Update troubleshooting_tips.md
    Remove vehicle power info
2025-02-27 Update products
    Update product links
    Add more cables
    Add SMA adapters
2025-02-27 Update assembly images
2025-02-28 Update RTK LED
2025-02-28 Add datasheets
    Add datasheets for ESP32 and CH340
2025-03-07 Add RX Clock Drift reporting
    [Begin.ino, GNSSDO_Firmware.ino, Tasks.ino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]
2025-04-15 Update 10MHz Reference
    Updated information and instructions for the 10MHz clock frequency reference switch
2025-06-06 GNSSDO+ v02 PCB - with DP5305 PoE module, PowerPath Controllers and MS8607 PHT sensor
    [Ethernet.kicad_sch, GNSS.kicad_sch, Level_Shifting.kicad_sch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]
2025-06-09 GNSSDO+ v02 PCB - panelized
    [SparkPNT_GNSSDO_Plus.kicad_pcb, SparkPNT_GNSSDO_Plus.kicad_sch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]
2025-09-12 Update footprints
    Fixes file path and position for the 3D models
    [SparkPNT_GNSSDO_Plus.kicad_pcb, SparkPNT_GPSDO.kicad_pcb]
2026-04-11 Update Dockerfile: require "SparkFun STP3593LF OCXO Arduino Library"@1.0.2
2026-04-13 Wrap the PID Derivative code in an ifdef
2026-04-13 Fix comment typo - add missing D
    [STP3593LF_OCXO.ino]
2026-04-14 Update GNSSDO KiCad files to match latest SparkFun library
    [Ethernet.kicad_sch, GNSS.kicad_sch, Level_Shifting.kicad_sch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]
2026-04-17 Reduce PCB width by 1.5mm. Bump to v10
    [SparkPNT_GNSSDO_Plus.kicad_pcb, SparkPNT_GNSSDO_Plus.kicad_sch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]
2026-06-24 Update button

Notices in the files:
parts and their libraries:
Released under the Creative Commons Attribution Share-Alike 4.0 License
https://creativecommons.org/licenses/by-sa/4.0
